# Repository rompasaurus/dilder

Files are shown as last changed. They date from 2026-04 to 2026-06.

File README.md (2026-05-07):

# Dilder

A Tamagotchi-inspired virtual pet built on a Raspberry Pi Pico W with an e-ink display, battery pack, and 3D-printed case — developed entirely in the open as a learning platform, blog series, and YouTube companion project.

The goal isn't just to build a thing — it's to show *how* the thing gets built, from the very first idea to a finished handheld device. Every prompt, every design decision, every dead end is documented so anyone can follow along, learn, and build their own.

---

## How It Started — Meet Jamal

<p align="center">
  Jamal the plush octopus
  <br />
  <em>Jamal. The plush octopus who started it all.</em>
</p>

This project didn't start with a schematic or a product spec. It started in a TEDi — a German dollar store — where my wife Emma and I found a giant plush octopus grinning up from a discount bin. We bought him on the spot, and on the walk home we started giving him a personality: laid-back, opinionated, a little sassy, suspiciously wise for a boneless creature. By the time we got home, he had a name — **Jamal** — and he'd claimed the armchair like he'd been paying rent.

The question asked itself: *what if we could actually bring him to life?* Not literally — but as a tiny digital companion. A pocket-sized octopus with moods, opinions, and an attitude problem, living on an e-ink screen and judging your life choices in ALL CAPS.

That's how Dilder was born. Not from an engineering roadmap, but from a stuffed animal and two people who couldn't stop anthropomorphizing it on a walk home.

---

## Enclosure — Rev 2 Mk2

The 3D-printed enclosure is a three-part design: base plate with solar panel recess, AAA battery cradle insert, and top cover with display window and joystick cutout. Designed in OpenSCAD (parametric source) and FreeCAD (visual PartDesign).

### Individual Parts

<p align="center">
  Base Plate — top view
  AAA Battery Cradle
</p>
<p align="center">
  <em>Left: Base plate with cradle pocket, corner pillars, battery rail troughs, and USB-C cutout. Right: AAA battery cradle with dual bays, clip slots, and TP4056 indent.</em>
</p>

<p align="center">
  Top Cover
  Base Plate — bottom (solar pit)
</p>
<p align="center">
  <em>Left: Top cover with display window, joystick hole, and bullnose edge. Right: Base plate bottom showing solar panel recess and wire holes.</em>
</p>

### Assembled

<p align="center">
  All three parts assembled
  <br />
  <em>All three parts stacked in their mated positions.</em>
</p>

### Full Assembly with Electronics

The FreeCAD macro now imports the official Raspberry Pi Pico 2 STEP file (mechanically identical to the Pico 2 W) and adds procedural 2×20 pin headers. It also builds three more peripherals from datasheet dimensions — two AAA Li-Ion cells in the cradle bays, a TP4056 USB-C charge module in the connecting block indent, and a Waveshare 2.13" e-paper display in the top cover's screen inlay. The Pico is mounted upside-down with its component-side face flush against the cradle's mating plane, headers extending up into the PicoNest cavity.

<p align="center">
  Assembly with Pico — top cover translucent
  <br />
  <em>Top cover rendered translucent so the Pico 2 W board, headers, and cradle are all visible.</em>
</p>

<p align="center">
  Assembly without top cover
  Pico on base plate, cradle hidden
</p>
<p align="center">
  <em>Left: top cover hidden so the cradle and Pico are exposed. Right: cradle hidden so the Pico's seating on the base plate is visible — header pin tips reach the level where the cradle would clip in.</em>
</p>

See the [FreeCAD macro reference](website/docs/docs/hardware/freecad-mk2-macro.md) for a full walkthrough of how the macro is structured.

### Joystick Thumbpiece

A printable snap cap that fits over the K1-1506SN-01 5-way switch peg. Single disc, 11 mm OD (= cover hole − 1 mm) so it nests inside the cover's joystick cutout with 0.5 mm radial clearance for directional swing. Concave thumb dish on top, rectangular snap socket on the bottom centered on the actuator (the SW1 stick is offset +0.68 mm in Y from the cover hole on the production PCB layout — disc reads visually centered, socket lands on the peg). Built parametrically in `dilder_rev2_mk2.FCMacro` as a separate `Thumbpiece` Body — drop `thumb_sock_x/y` from 3.3 to ~3.15 in the spreadsheet to convert friction-fit to interference snap-fit.

<p align="center">
  Assembly with thumbpiece
  <br />
  <em>Top-down view of the assembled prototype — display window on the left, joystick with the new thumbpiece on the right.</em>
</p>

<p align="center">
  Joystick + thumbpiece detail
  Thumbpiece in cover hole
</p>
<p align="center">
  <em>Left: joystick area in context. Right: thumbpiece nested in the cover cutout with the cover dialed to 85% transparency for clarity.</em>
</p>

See the [thumbpiece design write-up](website/docs/blog/posts/joystick-thumbpiece-snap-cap.md) for the geometry walkthrough — including the dish-vs-socket constraint that almost ruined the first cut.

---

## What This Project Is

- **A virtual pet device** — a pocket-sized, low-power companion with personality, needs, and interactions displayed on an e-ink screen
- **A build series** — a step-by-step guide covering hardware, software, 3D printing, and project planning
- **A transparency experiment** — the entire development process is captured in real time, including AI-assisted prompts, iteration, and mistakes

---

## Hardware

### Phase 1 — Pico 2 W Prototype (current)

| Component | Details |
|---|---|
| Board | Raspberry Pi Pico 2 W (RP2350, 40-pin headers) |
| Display | [Waveshare Pico-ePaper-2.13](https://www.waveshare.com/pico-epaper-2.13.htm) — 250x122px, black & white, SPI1, SSD1680 driver |
| Power | TP4056 USB-C charger module + LiPo 1000mAh (3.7V on VSYS) |
| Input | DollaTek K1-1506SN-01 5-way joystick (GP2-GP6) |
| Sound | Active buzzer on GP14 (3-12V, GPIO on/off) |
| Motion | MPU-6050 accelerometer/gyroscope on I2C0 (GP0/GP1, 400kHz) |

### Future — Pi Zero Upgrade

| Component | Details |
|---|---|
| Board | Raspberry Pi Zero WH (W or 2 W, pre-soldered headers) |
| Power | LiPo battery + Adafruit PowerBoost 500C |
| Enclosure | 3D-printed case (STL files provided) |

> The Pico W is the starting platform — it's what we have on hand, it's cheap, and it's excellent for prototyping the display and input system. The Pi Zero upgrade comes later when we need Linux, networking features, or more compute.

---

## Phases

Each phase maps to a section of the blog/YouTube series and can be followed independently.

### Phase 0 — Project Planning & Documentation ✓

- [x] Create repository and project structure
- [x] Define project intent and scope
- [x] Begin prompt progression log ([PromptProgression.md](PromptProgression.md))
- [x] Outline full phase roadmap
- [x] Create pixel art concepts for e-ink display (octopus character with 16 emotional states)
- [x] Define enclosure concept and prototype dimensions

### Phase 1 — Hardware Selection & Setup (Pico W) ✓

- [x] Finalize component list with links/part numbers ([hardware-research.md](docs/hardware-research.md))
- [x] Set up Docker-based C SDK cross-compilation toolchain
- [x] Wire e-ink display to Pico W via jumper wires (SPI)
- [x] Flash and run "Hello, Dilder!" on the e-ink display — proof of life
- [x] Build DevTool GUI — display emulator, serial monitor, firmware flash, asset manager, GPIO reference, connection utility, documentation ([tools/devtool/](tools/devtool/))
- [x] Add Programs tab with animated octopus preview, firmware size estimation, and deploy
- [x] Build IMG-receiver firmware — stream images from PC to Pico display via USB serial ([dev-setup/img-receiver/](dev-setup/img-receiver/))
- [x] Build standalone deploy — runtime-rendered animation, runs without PC
- [x] Wire and test joystick input (DollaTek 5-way, GP2-GP6)
- [x] Battery power prototype (TP4056 USB-C + LiPo on VSYS, ADC3 voltage sense)

### Phase 2 — Firmware Foundation (C on Pico W)
> *You are here*

- [x] Runtime rendering engine — draw octopus mathematically (no pre-baked frames)
- [x] Animation system — 4-frame mouth cycle with per-mood expression sequences
- [x] Body transform system — dx/dy offset, x_expand, per-row sine wobble
- [x] Custom body shapes for Fat (wider dome, thick tentacles) and Lazy (tentacles draped right)
- [x] 16 emotional states with unique eyes, pupils, eyebrows, eyelids, mouths, and body animations
- [x] 17 standalone firmware programs (16 emotions + mood selector with all 823 quotes)
- [x] Date/time clock header from RTC
- [x] C-faithful preview renderer for verifying firmware matches DevTool
- [x] Keyboard-to-Pico input mapping plan ([docs/keyboard-to-pico-input.md](docs/keyboard-to-pico-input.md))
- [x] Implement serial command input for interactive mood control
- [x] Wire and test GPIO joystick input (DollaTek 5-way, GP2–GP6)
- [x] Joystick Mood Selector firmware with on-screen input indicator
- [ ] **Custom PCB design (in progress)** — switched MCU from RP2040 to ESP32-S3-WROOM-1-N16R8 (WiFi+BLE, 16MB flash, 8MB PSRAM). 4-layer board (45x80mm, 30 components) in KiCad, ready for routing. Target fab: JLCPCB. Sensors: LIS2DH12TR (accelerometer), AHT20 (temperature/humidity), BH1750FVI-TR (ambient light) on shared I2C bus.
- [ ] Battery power (LiPo on VSYS) — InnCraft 1000mAh acquired
- [ ] Build game loop with state machine (idle, interact, sleep)

### Phase 3 — Pet Logic & Gameplay

- [ ] Define pet stats (hunger, happiness, energy, health, etc.)
- [ ] Implement stat decay over time
- [ ] Build interaction system — feed, play, sleep, clean
- [x] Pet mood / expressions based on emotional states (16 implemented)
- [x] Animation frames for e-ink (idle expressions, body movement per mood)
- [ ] Emotional state transitions triggered by interactions and stats
- [ ] Add death/game-over state and reset/new-pet flow

### Phase 4 — UI & Menus
> *Major progress*

- [x] Menu system with scrolling navigation (joystick up/down/center/left-back)
- [x] Status bar — WiFi icon (top-left), battery icon with percentage (top-right), RTC clock header
- [x] Screen transitions between octopus, menu overlay, and sub-screens (10 states)
- [x] Sound settings — on/off, volume (low/med/high), 6 test patterns
- [x] WiFi submenu — on/off toggle, network scanning, on-screen keyboard for password entry
- [x] Motion menu — live accelerometer/gyro, pedometer, tilt, threshold adjust, I2C scanner
- [x] Device info — firmware version, build date, battery voltage, WiFi status, NTP sync
- [ ] Implement settings screen (name pet, reset)

### Phase 5 — Pi Zero Migration

- [ ] Port MicroPython firmware to CPython on Pi Zero
- [ ] Set up headless Raspberry Pi OS
- [ ] Adapt display driver for Pi Zero SPI + Waveshare HAT
- [ ] Adapt input handler for Pi Zero GPIO
- [ ] Validate all Phase 2-4 functionality on Pi Zero

### Phase 6 — 3D-Printed Case & Power
> *In progress alongside Phase 2*

- [x] Design enclosure in OpenSCAD — parametric 3-part design (base plate, AAA cradle, top cover)
- [x] Account for display cutout, joystick access, USB-C charging port, solar panel recess
- [x] Translate to FreeCAD PartDesign — full parametric model with 90+ parameter spreadsheet
- [x] Battery cradle with clip slots for Swpeet AAA contact plates (parallel wiring)
- [x] Solar panel wire through-holes in base plate
- [x] Print prototypes and iterate on fit (Rev 2 Mk2 current)
- [x] Implement battery power (LiPo 1000mAh via TP4056 USB-C on VSYS)
- [ ] Implement sleep/wake cycle to conserve battery (see [power report](hardware-design/power-consumption-report.md))
- [x] Publish STL/3MF files and build instructions ([hardware-design/freecad-mk2/](hardware-design/freecad-mk2/))

### Phase 7 — Extras & Community

- [x] Add sound — active buzzer with 6 patterns (beep, chirp, SOS, doorbell, alert, happy)
- [x] WiFi connectivity — network scanning, on-screen keyboard, connect to any network
- [x] MPU-6050 accelerometer/gyroscope with pedometer and tilt sensing
- [ ] Explore connectivity — Bluetooth pet interactions?
- [ ] Mini-games
- [ ] Seasonal/event-based pet outfits or moods
- [ ] Publish a "build your own" kit guide
- [ ] Community gallery — show off your Dilder

---

## Content & Documentation

| Resource | Description |
|---|---|
| [PromptProgression.md](PromptProgression.md) | Every AI prompt used in development (104+), timestamped with token counts and file changes |
| [docs/hardware-research.md](docs/hardware-research.md) | Component research, materials list, GPIO pinout, and enclosure concepts |
| [docs/mpu6050-wiring-guide.md](docs/mpu6050-wiring-guide.md) | MPU-6050 accelerometer wiring, I2C details, and register reference |
| [hardware-design/power-consumption-report.md](hardware-design/power-consumption-report.md) | Full power budget, battery life projections, and reduction strategies |
| [docs/session-2026-05-07-implementation.md](docs/session-2026-05-07-implementation.md) | May 7 session — WiFi scan, keyboard, sound, MPU-6050, active buzzer |
| [Emotion States](https://dilder.dev/docs/software/emotion-states/) | All 16 emotional states with rendered previews and animation strips |
| [docs/keyboard-to-pico-input.md](docs/keyboard-to-pico-input.md) | Input mapping plan for interactive octopus control |
| [Blog](https://dilder.dev/blog/) | Build journal — 8 posts covering planning through body animations |
| YouTube (TBD) | Video walkthroughs for each phase |

---

## Follow Along

This project is built in the open. Star/watch this repo to follow progress. Each phase will have a corresponding blog post and video.

---

## License

TBD

---

*Built with patience, a Pico W, and an unreasonable fondness for a plush octopus named Jamal.*

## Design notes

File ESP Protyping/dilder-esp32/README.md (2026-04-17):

# Dilder ESP32-S3 Firmware — Implementation Guide

> Full mood-selector port for the Olimex ESP32-S3-DevKit-Lipo with Waveshare 2.13" e-Paper V3.

---

## Table of Contents

1. [What This Does](#what-this-does)
2. [Hardware Setup](#hardware-setup)
3. [Project Structure](#project-structure)
4. [Architecture](#architecture)
5. [Build & Flash](#build--flash)
6. [How It Works](#how-it-works)
7. [Code Layout](#code-layout)
8. [Display Pipeline](#display-pipeline)
9. [Rendering Engine](#rendering-engine)
10. [Input Handling](#input-handling)
11. [Design Principles](#design-principles)
12. [File Reference](#file-reference)
13. [Debugging](#debugging)

---

## What This Does

This is the ESP32-S3 port of the Dilder mood-selector — the same octopus character, 16 emotional states, 823 quotes, and animated expressions that run on the Pico W, now running on the Olimex ESP32-S3-DevKit-Lipo.

The octopus has:
- **16 moods**: Sassy, Weird, Unhinged, Angry, Sad, Chaotic, Hungry, Tired, Slaphappy, Lazy, Fat, Chill, Creepy, Excited, Nostalgic, Homesick
- **17 mouth expressions** with 4-frame animation cycles per mood
- **16 eye/pupil variations** with mood-specific eyebrows, eyelids, and tears
- **Body animation transforms** (oscillation, wobble, expansion per mood)
- **823 mood-filtered quotes** in chat bubbles
- **Joystick navigation** + serial keyboard control

---

## Hardware Setup

### Board: Olimex ESP32-S3-DevKit-Lipo

| Spec | Value |
|---|---|
| MCU | ESP32-S3 (dual-core Xtensa LX7 @ 240MHz) |
| Flash | 8MB QSPI |
| PSRAM | 8MB OPI |
| WiFi | 802.11 b/g/n |
| Bluetooth | BLE 5.0 |
| USB | USB-OTG (native) + USB-UART (CH340X) |
| Battery | LiPo via JST, onboard charger |

### Pin Connections

| Signal | GPIO | Connection |
|---|---|---|
| EPD CLK | 12 | Display SPI clock |
| EPD DIN (MOSI) | 11 | Display SPI data |
| EPD CS | 10 | Display chip select |
| EPD DC | 9 | Display data/command |
| EPD RST | 3 | Display reset |
| EPD BUSY | 8 | Display busy signal |
| Joystick UP | 4 | Active LOW, internal pull-up |
| Joystick DOWN | 7 | Active LOW, internal pull-up |
| Joystick LEFT | 1 | Active LOW, internal pull-up |
| Joystick RIGHT | 2 | Active LOW, internal pull-up |
| Joystick CENTER | 15 | Active LOW, internal pull-up |
| Battery ADC | 6 | Voltage divider (4.133x) |
| USB Power ADC | 5 | Voltage divider (1.468x) |
| LED | 38 | Green LED (active LOW) |

---

## Project Structure

```
ESP Protyping/dilder-esp32/
├── platformio.ini              Build config (board, libs, flags)
├── src/
│   ├── main.cpp                Full mood-selector firmware (666 lines)
│   └── quotes.h                Auto-generated quote database (823 entries)
├── README.md                   This file
└── .gitignore                  Excludes .pio/ build cache

Shared firmware headers (included via -I flag):
firmware/
├── include/
│   └── platform/
│       ├── board_config.h      Pin definitions per board (Pico/ESP32/Desktop)
│       └── hal.h               Hardware Abstraction Layer interface
└── src/
    └── platform/
        └── esp32s3/
            └── esp32s3_hal.cpp  ESP32-S3 HAL implementation
```

---

## Architecture

```
┌─────────────────────────────────────────────┐
│              main.cpp (Arduino)              │
│                                             │
│  setup() → init HAL, SPI, display, RNG      │
│  loop()  → render frame, poll input, repeat │
│                                             │
│  ┌─────────────────────────────────────┐    │
│  │      Octopus Rendering Engine       │    │
│  │  (body RLE, eyes, mouth, bubble,    │    │
│  │   font, animation transforms)       │    │
│  │  → renders to frame[] buffer        │    │
│  └───────────────┬─────────────────────┘    │
│                  │                           │
│  ┌───────────────▼─────────────────────┐    │
│  │         GxEPD2 Display Push         │    │
│  │  display.drawBitmap(frame)          │    │
│  │  Full refresh → Partial refresh     │    │
│  └─────────────────────────────────────┘    │
│                                             │
│  ┌─────────────────────────────────────┐    │
│  │         Input Handler               │    │
│  │  Joystick (hal_btn_*) + Serial      │    │
│  │  Edge detection for button presses  │    │
│  └─────────────────────────────────────┘    │
└──────────────────┬──────────────────────────┘
                   │
┌──────────────────▼──────────────────────────┐
│          HAL (Hardware Abstraction)          │
│                                             │
│  hal.h         → function declarations      │
│  board_config.h → pin numbers per board     │
│  esp32s3_hal.cpp → Arduino GPIO/SPI impl    │
└─────────────────────────────────────────────┘
```

---

## Build & Flash

### Prerequisites

- PlatformIO CLI (`pipx install platformio`)
- USB-UART cable connected to the Olimex board's CH340X port

### Commands

```bash
cd "ESP Protyping/dilder-esp32"

# Build
pio run

# Build + Flash
pio run -t upload

# Serial Monitor
pio device monitor

# All three
pio run -t upload && pio device monitor
```

Or use the DevTool GUI: select the "Flash Firmware" tab → ESP32-S3 board.

---

## How It Works

### Frame Cycle

Each iteration of `loop()`:

1. **Select expression** — look up the 4-frame mouth cycle for the current mood, pick the expression for this frame index
2. **Pick quote** — if mood changed or mouth is "open", randomly select a new quote from the current mood's pool
3. **Render to framebuffer** — `render_frame()` draws everything to the `frame[]` byte array:
   - Clock header (synthetic time from millis())
   - Body (RLE-decoded with animation transforms)
   - Eyes (white sockets cleared in body)
   - Pupils (mood-specific shapes)
   - Eyebrows/eyelids/tears (mood-specific overlays)
   - Mouth expression (one of 17 styles)
   - Chat bubble outline + speech tail
   - Quote text (word-wrapped in bubble)
   - Status bar ("< MOOD_NAME >")
4. **Push to display** — `push_frame_to_display()` sends the framebuffer to the e-paper via GxEPD2
5. **Poll input** — wait 4 seconds, checking joystick + serial every 50ms
6. **Repeat**

### Mood Selection

- **Joystick LEFT/RIGHT**: cycle through 16 moods sequentially
- **Joystick CENTER**: jump to a random mood
- **Joystick UP**: pick a new quote (same mood)
- **Serial keyboard**: single-letter shortcuts (n=Sassy, w=Weird, etc.)

---

## Code Layout

### main.cpp — Section Map

| Lines | Section | What It Contains |
|---|---|---|
| 1-30 | Headers | Arduino, GxEPD2, HAL includes |
| 31-75 | Constants | Mood/expression enums, names, framebuffer |
| 76-100 | Pixel helpers | `px_set`, `px_clr`, `px_set_off`, `px_clr_off` |
| 101-115 | Quotes | `#include "quotes.h"` |
| 116-200 | Body data | RLE-encoded octopus body + 5x7 font |
| 200-260 | Drawing | `fill_circle`, `draw_body_transformed`, `draw_eyes` |
| 260-520 | Eyes/Pupils | 16 mood-specific pupil functions + eyebrows/tears |
| 520-750 | Mouths | 17 mouth expression functions |
| 750-830 | Bubble/Text | Chat bubble outline, text rendering with word wrap |
| 830-870 | Clock | millis()-based synthetic clock header |
| 870-930 | Animation | Body transform setup per mood |
| 930-950 | Status bar | "< MOOD >" at bottom of screen |
| 950-1050 | Cycles | 16 mouth animation cycle tables |
| 1050-1100 | Render | `render_frame()` — composites all layers |
| 1100-1140 | Display | `push_frame_to_display()` — GxEPD2 bitmap push |
| 1140-1180 | Setup | Arduino `setup()` — init HAL, SPI, display |
| 1180-end | Loop | Arduino `loop()` — render, poll input, repeat |

---

## Display Pipeline

### Pico W vs ESP32-S3

Both use the same 250x122 framebuffer, but push pixels differently:

| Step | Pico W | ESP32-S3 |
|---|---|---|
| Render | → `frame[3904]` | → `frame[3904]` (identical) |
| Transform | `transpose_to_display()` (landscape→portrait) | Not needed (GxEPD2 handles rotation) |
| Push | `EPD_Display(display_buf)` / `EPD_Partial()` | `display.drawBitmap(0,0,frame,250,122,BLACK)` |
| Driver | Waveshare C driver (SSD1680 registers) | GxEPD2 Arduino library (same SSD1680) |

### Framebuffer Format

```
frame[3904 bytes] = 250 x 122 pixels, 1 bit per pixel

Bit layout: MSB-first per byte
  Byte: [b7][b6][b5][b4][b3][b2][b1][b0]
         ^leftmost pixel          ^rightmost

  1 = black pixel, 0 = white pixel

To set pixel (x, y):
  frame[y * 32 + x / 8] |= (0x80 >> (x & 7));
```

---

## Rendering Engine

### Body (RLE Encoding)

The octopus body is stored as Run-Length Encoded spans:

```
Format: y, num_spans, x_start, x_end, [x_start, x_end, ...], ...
Terminator: 0xFF

Example: 55,5, 10,17, 21,28, 32,39, 43,50, 54,61
  → Row 55 has 5 horizontal spans:
    pixels 10-17, 21-28, 32-39, 43-50, 54-61
  → These are the tentacles splitting from the body
```

### Eyes

Eyes are drawn in three layers:
1. **Sockets** — white circles cleared from the black body (`fill_circle(..., 0)`)
2. **Pupils** — black dots/shapes drawn inside the sockets (mood-specific)
3. **Overlays** — eyebrows (angry/sad), eyelids (tired/lazy), tears (homesick)

### Mouth

17 distinct mouth expressions using math curves:
- **Smirk**: tilted arc (sqrt curve)
- **Smile**: parabola (y = x^2 / 25)
- **Open**: elliptical outline (ellipse edge detection)
- **Weird**: sine wave (3 periods)
- **Unhinged**: large ellipse with teeth
- **Angry/Sad**: inverted/normal parabolas
- **Chaotic**: zigzag
- **Hungry**: open ellipse with drool
- And more...

### Animation

Each mood has a 4-frame mouth cycle and body transform:
- **body_dx/dy**: position offset (breathing, bouncing)
- **body_x_expand**: width change (puffing up, shrinking)
- **wobble_amp/freq/phase**: per-row sine wobble (wavy effects)

---

## Input Handling

### Edge Detection

Buttons are active-LOW (pressed = GPIO reads LOW). The HAL inverts this so `hal_btn_up()` returns `true` when pressed.

To detect a new press (not a held button), we compare current vs previous state:

```cpp
if (left && !last_left) {
    // Button was just pressed (rising edge)
    // Do something
}
last_left = left;  // Remember for next iteration
```

This prevents the mood from cycling continuously while the button is held.

---

## Design Principles

1. **Shared rendering engine** — the octopus drawing code is identical between Pico W and ESP32-S3. Same pixel math, same framebuffer layout, same visual output.

2. **Platform abstraction** — `hal.h` defines a common interface. Each board implements it differently (`esp32s3_hal.cpp` uses Arduino, Pico uses the Pico SDK). Application code never touches hardware registers directly.

3. **Compile-time board selection** — `board_config.h` uses `#if defined(BOARD_ESP32S3)` to select pin numbers at compile time. No runtime overhead, no unused code.

4. **No dynamic allocation** — all buffers are statically allocated. The framebuffer, body RLE data, font, and quote database are all compile-time constants. No `malloc()`, no fragmentation risk.

5. **Arduino framework** — used for the ESP32 build because it provides mature SPI, GPIO, and serial APIs plus the GxEPD2 display library. The Pico build uses the native Pico SDK for lower overhead.

---

## File Reference

| File | Location | Lines | Purpose |
|---|---|---|---|
| `main.cpp` | `src/` | ~666 | Complete mood-selector with octopus rendering |
| `quotes.h` | `src/` | ~827 | 823 auto-generated mood-indexed quotes |
| `platformio.ini` | root | 56 | PlatformIO build configuration |
| `board_config.h` | `firmware/include/platform/` | ~120 | Pin definitions for Pico W / ESP32 / Desktop |
| `hal.h` | `firmware/include/platform/` | ~75 | Hardware abstraction interface |
| `esp32s3_hal.cpp` | `firmware/src/platform/esp32s3/` | ~130 | ESP32-S3 GPIO/SPI/ADC implementation |

---

## Debugging

### Serial Monitor

```bash
pio device monitor
```

Every frame prints: `Frame N | < MOOD > (X/16) | "QUOTE TEXT"`

### Common Issues

| Problem | Cause | Fix |
|---|---|-----|
| Display blank | SPI pins wrong | Check `board_config.h` GPIO mapping |
| Display shows noise | Wrong GxEPD2 class | Must be `GxEPD2_213_BN` for V3 |
| Joystick not responding | Pull-ups missing | `dilder_hal_init()` sets `INPUT_PULLUP` |
| Build fails: `Arduino.h not found` | IDE error, not real | PlatformIO resolves this at build time |
| Quotes not showing | `quotes.h` missing | Copy from `dev-setup/mood-selector/quotes.h` |
| Flash too slow | Wrong upload port | Set `upload_port` in `platformio.ini` |

### Adding printf Debugging

```cpp
Serial.printf("[DEBUG] mood=%d frame=%lu\n", current_mood, frame_idx);
```

Output appears in `pio device monitor` or the DevTool serial tab.

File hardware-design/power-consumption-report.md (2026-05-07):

# Power Consumption Report — Dilder Hub

## Current Component Inventory (Testbench)

| Component | Model | Voltage | Typical Current | Peak Current | Duty Cycle | Notes |
|---|---|---|---|---|---|---|
| Pico 2 W (RP2350 + CYW43) | Pico 2 W | 3.3V via VSYS | 30 mA | 50 mA | 100% | WiFi off baseline; CYW43 init'd for VSYS sense |
| Pico 2 W WiFi active | — | 3.3V | 80-120 mA | 250 mA | Variable | TX bursts during scan/connect; idle ~80 mA |
| E-paper display (2.13" V4) | Waveshare 2.13 V4 | 3.3V | 0.01 mA | 5 mA | ~1% | Static: near-zero; refresh burst ~5 mA for ~2s |
| Active buzzer | 3-12V active | 3.3V | 0 mA | 15 mA | <1% | Only during beeps; off = 0 mA |
| 5-way joystick | K1-1506SN-01 | 3.3V | 0 mA | ~0.1 mA | Passive | Internal pull-ups on GPIOs (~50uA total) |
| MPU-6050 (accel/gyro) | GY-521 module | 3.3V | 3.6 mA | 3.9 mA | 100% | Always on; module regulator quiescent ~0.5 mA |
| TP4056 charger board | TP4056 USB-C | 5V USB in | 2 mA | ~1000 mA | Charging only | Quiescent ~2 mA; charge current set by R_prog |
| Battery | LiPo 1000mAh / 10440 | 3.7V nom | — | — | — | Source, not load |

## Power Budget Summary

### Scenario 1: Idle (WiFi off, display static, no motion polling)

| Component | Current |
|---|---|
| Pico 2 W + CYW43 init | 30 mA |
| E-paper (static) | 0.01 mA |
| Joystick pull-ups | 0.05 mA |
| MPU-6050 | 3.6 mA |
| **Total** | **~34 mA** |

**Battery life (1000 mAh LiPo):** ~29 hours continuous

### Scenario 2: Active use (WiFi off, e-paper refreshing every 3s, motion polling)

| Component | Average Current |
|---|---|
| Pico 2 W + CYW43 init | 30 mA |
| E-paper (refresh 2s on / 1s off) | ~3.3 mA avg |
| Joystick pull-ups | 0.05 mA |
| MPU-6050 | 3.6 mA |
| Buzzer (occasional) | ~0.5 mA avg |
| **Total** | **~38 mA** |

**Battery life (1000 mAh LiPo):** ~26 hours continuous

### Scenario 3: WiFi active (connected, NTP sync, display refreshing)

| Component | Average Current |
|---|---|
| Pico 2 W + WiFi connected idle | 80 mA |
| E-paper (refreshing) | ~3.3 mA avg |
| MPU-6050 | 3.6 mA |
| Other | ~0.5 mA |
| **Total** | **~88 mA** |

**Battery life (1000 mAh LiPo):** ~11 hours continuous

### Scenario 4: WiFi scan burst (worst case)

| Component | Peak Current |
|---|---|
| Pico 2 W + WiFi TX | 250 mA |
| E-paper refresh | 5 mA |
| MPU-6050 | 3.9 mA |
| **Total** | **~260 mA** |

Duration: scan bursts last ~2-5 seconds. TP4056 output can handle this.

## Power Reduction Strategies

### 1. MPU-6050 Sleep Mode (saves ~3.5 mA)

The MPU-6050 has a low-power sleep mode (write 0x40 to PWR_MGMT_1). When not in the MOTION menu:
- Put MPU to sleep: `mpu_write_reg(0x6B, 0x40)`
- Wake on entering MOTION menu: `mpu_write_reg(0x6B, 0x00)`
- **Savings:** 3.5 mA (10% of idle budget)
- **Effort:** Low — add sleep/wake calls to state transitions

### 2. MPU-6050 Cycle Mode (saves ~2.5 mA while still counting steps)

For pedometer-only operation (no live display), use the MPU's cycle mode:
- Wakes at 1.25-40 Hz to sample, sleeps between
- At 5 Hz cycle: ~0.5 mA vs 3.6 mA continuous
- **Savings:** ~3.1 mA
- **Effort:** Medium — configure LP_WAKE_CTRL register, adjust pedometer timing

### 3. Pico 2 W Dormant/Sleep Mode (saves ~25 mA)

The RP2350 supports dormant mode (~0.2 mA) and sleep mode (~1 mA). Implement a Tamagotchi-style duty cycle:
- **Active 10 min:** Full operation, display updates, user input
- **Sleep 50 min:** RP2350 dormant, wake on joystick press (GPIO interrupt) or timer
- **Average current:** ~34 mA * (10/60) + 1 mA * (50/60) = ~6.5 mA
- **Battery life (1000 mAh):** ~6.5 days
- **Effort:** High — requires dormant mode setup, GPIO wake interrupts, state preservation

### 4. CYW43 Deinit When Not Needed (saves ~5-10 mA)

Currently CYW43 is initialized at boot for VSYS sensing. When the full board has TP4056 CHRG/STDBY pins wired:
- Remove CYW43 dependency for battery sensing
- Only init CYW43 when WiFi is actually needed
- **Savings:** ~5-10 mA from CYW43 idle current
- **Effort:** Low (once CHRG/STDBY hardware is in place)

### 5. E-paper Deep Sleep (saves ~0.01 mA — negligible)

The e-paper already draws near-zero in static mode. Calling `EPD_Sleep()` after each refresh would save microamps. Not worth the added wake-up latency.

### 6. Reduce Display Refresh Rate (saves CPU time, indirect power)

On the main octopus screen, refresh every 5-6 seconds instead of 3. Reduces CPU active time. Minimal direct current savings but extends battery slightly.

### 7. WiFi Power Management (saves ~30-50 mA when connected)

When WiFi is connected but idle:
- Enable CYW43 power-save mode: `cyw43_wifi_pm(&cyw43_state, CYW43_PERFORMANCE_PM)`
- Or aggressive PS: `cyw43_wifi_pm(&cyw43_state, CYW43_DEFAULT_PM)` (DTIM-based sleep)
- **Savings:** WiFi idle drops from ~80 mA to ~30-50 mA
- **Effort:** Low — single function call after connect

### 8. Voltage Regulator Efficiency

The Pico 2 W onboard SMPS (RT6154) is ~90% efficient at typical loads. No improvement possible without board redesign. On a custom PCB, a more efficient regulator could save 5-10%.

## Recommended Priority

| Priority | Strategy | Savings | Effort | Impact |
|---|---|---|---|---|
| 1 | MPU-6050 sleep when not in MOTION menu | 3.5 mA | Low | Do now |
| 2 | WiFi power-save mode when connected | 30-50 mA | Low | Do now |
| 3 | CYW43 deinit (needs CHRG/STDBY hardware) | 5-10 mA | Low | Full board |
| 4 | MPU cycle mode for background pedometer | 3.1 mA | Medium | Later |
| 5 | Dormant/sleep duty cycle | ~28 mA avg | High | Phase 2 |

## Battery Life Projections (1000 mAh LiPo)

| Configuration | Average mA | Battery Life |
|---|---|---|
| Current (WiFi off, idle) | 34 mA | ~29 hours |
| With MPU sleep (#1) | 30.5 mA | ~33 hours |
| With WiFi PS (#2) when connected | ~55 mA | ~18 hours |
| With MPU sleep + no CYW43 idle (#1+#3) | ~25 mA | ~40 hours |
| Full sleep/wake cycle (#5) | ~6.5 mA | ~6.5 days |
| All optimizations combined | ~4 mA avg | ~10 days |

## Solar Charging Viability

With the AK 62x36mm panel (~5-6V, 80-150 mA peak):
- **Best case (direct sun):** 100 mA in, 34 mA out = net positive, charges battery
- **Typical (indirect/cloudy):** 20-40 mA in, 34 mA out = net negative without sleep cycle
- **With sleep cycle (6.5 mA avg):** Solar easily sustains operation in most daylight conditions
- **Conclusion:** Sleep/wake cycle is essential for solar sustainability

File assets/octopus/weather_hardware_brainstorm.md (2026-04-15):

# Weather Detection for Dilder — Hardware Brainstorm

How to get weather data into Jamal's world so environments react to real conditions.

---

## Option 1: WiFi Weather API (Free, No Extra Hardware)

**The cheapest option: $0, 0 components, 0 GPIO pins.**

The ESP32-S3 already has WiFi active (used for location fingerprinting). Piggyback a weather API call onto the existing WiFi connection.

### How It Works
```
ESP32-S3 WiFi -> HTTPS GET -> OpenWeatherMap API -> JSON parse -> weather state
```

### Free API Options
| Service | Free Tier | Update Interval | Data |
|---|---|---|---|
| OpenWeatherMap | 1,000 calls/day | Every 86s (~15min is fine) | temp, humidity, pressure, conditions, icon |
| WeatherAPI.com | 1M calls/month | ~2.8s (use 15min) | Same + UV, air quality |
| Open-Meteo | Unlimited | 15min granularity | No API key needed, EU-based |

### Implementation
```c
// Poll every 15 minutes (e-ink doesn't need faster updates)
// Parse JSON for: temp_c, humidity, condition_code
// condition_code maps to environment modulation:
//   200-299: Thunderstorm -> lightning aura
//   300-499: Rain/Drizzle -> rain overlay
//   500-599: Rain -> heavy rain overlay
//   600-699: Snow -> snow overlay
//   800:     Clear -> sun_rays / stars (day/night)
//   801-804: Clouds -> clouds overlay
typedef struct {
    int8_t temp_c;
    uint8_t humidity;
    uint16_t condition;  // OWM condition code
    bool is_night;
} weather_t;
```

### Pros
- Zero extra cost, zero extra hardware, zero extra power draw
- Rich data (temp, humidity, forecast, UV, sunrise/sunset)
- Works indoors (where most Tamagotchis live)
- Can show weather for ANY location (home, travel, etc.)

### Cons
- Needs WiFi connected (already required for location)
- No hyperlocal accuracy (reports city-level weather)
- ~200ms latency per API call (do it in background, non-blocking)

### Power Cost
One HTTPS request every 15 minutes adds ~0.5mA average to the WiFi budget (ESP32-S3 already waking for location scans). Negligible.

**Verdict: Do this first. It's free and the ESP32-S3 already has WiFi.**

---

## Option 2: BME280 Sensor (Best Bang-for-Buck Hardware)

**~$2-3, 1 component, shares existing I2C bus.**

### What You Get
| Measurement | Range | Resolution |
|---|---|---|
| Temperature | -40 to +85°C | 0.01°C |
| Humidity | 0-100% RH | 0.008% |
| Barometric Pressure | 300-1100 hPa | 0.18 Pa |

### Why Pressure Matters
Barometric pressure trends predict weather changes **before they happen**:
- Pressure dropping fast (>2 hPa/hr) -> storm incoming
- Pressure rising -> clearing up
- Steady low pressure -> overcast/rainy
- Steady high pressure -> fair weather

This gives Jamal **weather prescience** — he can react to weather changes before they're visible outside. "Jamal feels a storm coming" is way more charming than "the API says rain."

### Wiring
```
BME280       ESP32-S3
------       --------
VCC    ->    3.3V
GND    ->    GND
SDA    ->    GPIO16 (shared with accelerometer)
SCL    ->    GPIO17 (shared with accelerometer)
```

The I2C bus already has 10k pull-ups for the LIS2DH12TR accelerometer. The BME280 default address is **0x76** (accelerometer is 0x18) — no conflict.

### PCB Impact
- Add 1 footprint: LGA-8 (2.5x2.5mm) or breakout header
- No new traces needed if placed near existing I2C bus
- Could be mounted on the back of the PCB for ambient sensing

### Power
- Normal mode: 3.6μA (one measurement per second)
- Forced mode (on-demand): <1μA average at 1 reading/minute
- Sleep: 0.1μA

### Code Size
BME280 I2C driver: ~500 bytes flash, ~20 bytes RAM for calibration data.

**Verdict: Best hardware option. Shares I2C bus, tiny, cheap, gives pressure-based weather prediction.**

---

## Option 3: Combo Approach (API + BME280)

**The "best of both worlds" — use BOTH for maximum weather awareness.**

| Source | What It Provides | Update Rate |
|---|---|---|
| WiFi API | Conditions (rain/snow/sun), forecast, sunrise/sunset | Every 15 min |
| BME280 | Ambient temp, humidity, pressure **trend** | Every 1 min |

### Fusion Logic
```c
// API gives the "official" weather
// BME280 gives the local/indoor reality + pressure predictions

weather_state_t get_weather() {
    weather_state_t w = api_weather;  // base from API

    // Override with local conditions
    if (bme_temp < 10) w.feels_cold = true;   // Jamal shivers
    if (bme_humidity > 80) w.feels_muggy = true;

    // Pressure trend prediction (last 3 hours)
    float dp = pressure_now - pressure_3h_ago;
    if (dp < -3.0) w.storm_incoming = true;   // "Jamal senses a storm"
    if (dp > 3.0) w.clearing_up = true;       // "Jamal feels the sun coming"

    return w;
}
```

This creates **two layers of weather personality:**
1. API-driven: Jamal knows it's raining outside (rain overlay, sad modulation)
2. Sensor-driven: Jamal *feels* the room (shivers if cold, sweats if humid, senses storms)

---

## Option 4: Cheap Trick — LDR (Light Sensor)

**~$0.10, 1 resistor + 1 LDR, 1 ADC pin.**

A light-dependent resistor on an ADC pin gives day/night detection and crude cloud cover estimation.

### Wiring
```
3.3V -> LDR -> ADC_PIN (GPIO1/2/3) -> 10kΩ -> GND
```

Voltage divider. Read ADC value:
- High value = bright = daytime/sunny
- Medium = cloudy/overcast
- Low = nighttime/dark room

### What It Enables
- Automatic day/night environment switching (bedroom at night, park during day)
- "Jamal notices it's getting dark" personality triggers
- Crude indoor/outdoor detection (fluorescent vs sunlight spectrum varies, but ADC can't distinguish)

### Limitation
Only measures **light at the device location**, not actual weather. But combined with an API, it tells you "is the device in a bright or dark room" which is useful for Tamagotchi personality.

**Verdict: Cute party trick for $0.10. Add it if you have a spare ADC pin.**

---

## Option 5: Rain Sensor Module

**~$1, but requires outdoor exposure.**

Analog rain detector PCB. Resistance drops when water bridges the traces.

### Why It Probably Doesn't Work Here
- Needs to be **outdoors** or near a window
- Tamagotchi lives indoors on a desk
- Corrosion over time degrades the sensor
- Already solved better by WiFi API

**Verdict: Skip. The API does this better without hardware.**

---

## Recommendation

### Phase 1: WiFi API (implement now, zero cost)
- OpenWeatherMap or Open-Meteo free tier
- Poll every 15 minutes in background
- Map condition codes to environment overlays + emotion modulation
- Already have WiFi connected for location

### Phase 2: BME280 (add to next PCB revision)
- $2-3, shares I2C bus, tiny footprint
- Pressure trend prediction ("Jamal feels a storm coming")
- Room temperature/humidity awareness ("Jamal is cold/hot/muggy")
- Combines with API for rich weather personality

### Phase 3 (Optional): LDR for day/night
- $0.10, automatic day/night switching
- Only if a spare ADC pin is available on the next PCB

---

## How Weather Maps to the Asset System

```
Weather State           Environment Modulation      Aura Effect
─────────────          ─────────────────────       ────────────
Clear/Sunny            sun_rays overlay             warm sparkle dots
Cloudy                 clouds overlay               muted aura (slower)
Rain                   rain overlay (density=API)   sad tears amplified
Heavy Rain             rain overlay (density=max)   chaotic wobble added
Thunderstorm           rain + lightning overlay      unhinged static noise
Snow                   snow overlay                 gentle drift particles
Wind                   wind streaks overlay          aura particles drift faster
Hot (>30°C)            heat shimmer effect           sweat drops near head
Cold (<5°C)            (no overlay)                 shiver wobble on body
Storm Incoming (BME)   darkening sky gradient        anticipation particles
Night                  swap to night variant env     stars in aura
```

The weather overlays from `decor/weather.py` are already implemented and ready to be triggered by real weather data. The composition pipeline in `compose.py` has the hook point at step 12 (weather overlay) waiting to be wired up.

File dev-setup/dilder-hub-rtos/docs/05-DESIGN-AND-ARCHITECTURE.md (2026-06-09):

# 05 — Design and Architecture

This is the "why it's built this way" document. It describes the target task model, the
dual-core (SMP) decision, how a frame reaches the screen, and what is implemented now
versus planned.

---

## 1. The goal, restated as a requirement

> While the e-ink screen is mid-refresh (~300 ms of blocking), the firmware must still:
> register button presses within ~10 ms, keep the clock ticking, read the accelerometer,
> and service Wi-Fi/Bluetooth.

The original super-loop cannot meet this: one slow step stalls all the others. The fix is
concurrency, and we chose **dual-core SMP FreeRTOS**.

---

## 2. Why dual-core SMP (and the trade-off we accepted)

The RP2350 has two Cortex-M33 cores. We could have used single-core FreeRTOS (time-slicing
one core) — simpler and lower-risk. We chose **SMP** because it gives **true parallelism**:
the slow Display task runs on **core 1** while everything responsive runs on **core 0**, so
the 300 ms refresh has *zero* effect on input latency rather than merely being interrupted
every few milliseconds.

The trade-off we accept for that: SMP means two cores share memory simultaneously, so we
must be disciplined about synchronization (doc 06) and use multicore-safe flash writes
(doc 04 §8). The most error-prone combination on this chip is *cyw43 (Wi-Fi/BT) + SMP*, so
we **pin all networking to core 0** and keep core 1 doing nothing but the display. That
isolation keeps the fragile parts on one core and the parallelism where we need it.

(For the full pros/cons that led to this choice, see the project plan; this doc records the
decision, not the debate.)

---

## 3. The tasks

| Task | Core | Priority | Owns (only this task touches it) | Blocks on |
|---|---|---|---|---|
| **Input** | 0 | highest | the joystick GPIOs | a 5 ms `vTaskDelay` poll |
| **cyw43 / lwIP / BTstack** (SDK-created) | 0 | high | the Wi-Fi/BT chip, the network stack | internal events |
| **UI / Logic** | 0 | medium | the state machine, the logical canvas `frame[]`, canvas size/rotation, mood/quote/menu state | the input queue + a render-done signal |
| **Housekeeping** | 0 | low | the I²C bus + accelerometer, step/activity counters, the battery ADC, idle detection, the clock | a periodic `vTaskDelay` |
| **Display** | **1 (alone)** | high | the panel SPI bus + `display_buf[]` + the e-ink driver | a render request, then the BUSY pin |

The single most important line in that table: **Display is alone on core 1.** Everything
else is on core 0. That's the whole architecture in one sentence.

> One task **owning** a resource is our main concurrency tool. If only Housekeeping ever
> touches the I²C bus, there can be no I²C race — no lock needed. If only Display touches
> `display_buf`, no framebuffer race. We design ownership first and reach for locks only
> for the few things that genuinely cross tasks.

---

## 4. How a frame reaches the screen (the render hand-off)

This is the crux that lets the 300 ms cost live entirely on core 1.

```
  UI task (core 0)                         Display task (core 1)
  ----------------                         ---------------------
  1. decide what to show (state machine)
  2. draw into the logical canvas frame[]
  3. map frame[] → panel bytes via
     transpose_to_display() into the
     BACK buffer of a double buffer
  4. xQueueOverwrite(render_q, {buf, mode}) ───────►  5. xQueueReceive(render_q, …)  (was asleep)
  6. go back to waiting for input  ◄── (free!)        6. EPD push pixels from that buffer
                                                       7. wait on BUSY ~300 ms
                                                       8. notify UI "done" (frees the buffer)
```

- **Double buffer:** two `display_buf`s. UI fills the back one while Display shows the
  front one. They never touch the same buffer at the same time, so no lock on the pixels.
- **`xQueueOverwrite` (length-1 queue):** if UI produces frames faster than Display can
  show them, only the **newest** survives in the queue. That's exactly right — e-ink can't
  display intermediate frames anyway, so dropping them is free frame-coalescing.
- **Result:** after step 4, UI is *immediately* back to serving input. The screen catches
  up on the other core. Buttons never wait for pixels.

---

## 5. Synchronization at a glance (full detail in doc 06)

- **Input → UI:** a FreeRTOS **queue** of joystick codes. Replaces the old inline
  `read_joystick()` polling and the `POLL_INPUT` busy-loops.
- **UI → Display:** a length-1 **overwrite queue** carrying a tiny "show buffer N"
  descriptor, plus a **task notification** back to UI when the frame is done.
- **Housekeeping → readers:** a `sensor_snapshot_t` struct (orientation, steps, battery,
  idle flag) guarded by **one mutex**. Housekeeping writes it; UI/Display copy it.
- **Networking flags:** single `volatile` scalars (atomic); multi-byte network data is read
  under the cyw43 lock (`cyw43_arch_lwip_begin/end`).
- **Flash writes:** `flash_safe_execute()` (multicore-safe), not the old interrupt-disable.

---

## 6. Memory budget (rough)

RP2350 has 520 KB RAM. Approximate static consumers: FreeRTOS heap pool 128 KB, lwIP +
BTstack buffers, the framebuffers (~8 KB), task stacks (UI ~16 KB, others smaller), plus
the firmware's own globals. The Phase 0 build measured ~205 KB of `.bss` (zero-initialized
RAM) — comfortably within budget. Flash use (~600 KB of ~4 MB) is a non-issue.

---

## 7. The boot sequence

```
main() on the boot core, BEFORE any RTOS:
  stdio, clock-from-compile-time, hardware init (SPI/e-ink pins),
  joystick, speaker, [hold-UP → jump to the OTA bootloader], startup chime,
  EPD_Init/Clear, seed RNG
  → xTaskCreate(app_task, core 0); vTaskStartScheduler()   ← OS takes over here

app_task (Phase 1: the whole program; Phase 2: replaced by the task set):
  cyw43_arch_init()  ← must be here: the FreeRTOS Wi-Fi driver needs the scheduler running
  battery_init, mpu_init, load saved settings
  → the state-machine loop
```

The **OTA hold-UP check stays in `main()` before the scheduler** on purpose: jumping into
the bootloader must happen on bare metal, with no tasks alive.

---

## 8. Implemented vs planned

| Piece | Status |
|---|---|
| FreeRTOS SMP integrated, builds USB + OTA | ✅ Phase 0 |
| Whole program runs as one task under the scheduler (core 0) | ✅ Phase 1 |
| Split into Input / UI / Display / Housekeeping tasks | ✅ Phase 2 (`rtos_tasks.c`) |
| Display pinned to core 1 + 2-buffer render hand-off | ✅ Phase 2 |
| Input task + event queue (edge + auto-repeat) | ✅ Phase 2 |
| Housekeeping task + mutex-guarded sensor snapshot | ✅ Phase 2 |
| `flash_safe_execute()` for settings/calibration writes (+ core-1 lockout handshake) | ✅ Phase 2 |
| Verified by multi-agent adversarial concurrency review | ✅ Phase 2 |
| BUSY-pin interrupt → Display blocks instead of polling | 🔜 Phase 3 (marginal: the e-ink wait already yields core 1 cooperatively) |
| Stack/priority tuning via `uxTaskGetStackHighWaterMark` | 🔜 Phase 3 (needs on-device measurement) |

Phase 2 is implemented and builds clean (0 warnings) for USB + OTA. An adversarial review
(3 diverse-lens reviewers + synthesis) confirmed the concurrency core — the 2-buffer hand-off,
the snapshot mutex, the `POLL_INPUT` rewrite, and the `flash_safe_execute` mechanism — is
correct; the review's polish findings (flash handshake, step double-count, menu repeat fold,
volatiles) were fixed. The remaining Phase 3 items are hardening that is either marginal (the
display already yields core 1) or requires the physical board (stack high-water marks).
On-device validation of input latency, BLE pairing, and OTA is still owed by the hardware.

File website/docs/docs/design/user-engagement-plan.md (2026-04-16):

# Dilder User Engagement Plan

> Comprehensive design document for gameplay loops, progression systems, real-world integration, and hardware requirements for the Dilder digital octopus pet.

---

## Table of Contents

1. [Design Philosophy](#1-design-philosophy)
2. [Core Gameplay Loop](#2-core-gameplay-loop)
3. [Stat System](#3-stat-system)
4. [Emotional State Engine](#4-emotional-state-engine)
5. [User Interactions — Digital](#5-user-interactions--digital)
6. [User Interactions — Physical (Sensors)](#6-user-interactions--physical-sensors)
7. [Real-World Activity Integration](#7-real-world-activity-integration)
8. [Life Stages & Evolution](#8-life-stages--evolution)
9. [Progression & Unlock System](#9-progression--unlock-system)
10. [Dialogue System](#10-dialogue-system)
11. [Decor, Animations & Cosmetics](#11-decor-animations--cosmetics)
12. [Engagement Hooks & Retention](#12-engagement-hooks--retention)
13. [Treasure Hunt System](#13-treasure-hunt-system)
14. [Step Target Rewards — Daily, Weekly, Monthly](#14-step-target-rewards--daily-weekly-monthly)
15. [Hardware Requirements & Cost](#15-hardware-requirements--cost)
16. [Research: Tamagotchi & Virtual Pet Precedents](#16-research-tamagotchi--virtual-pet-precedents)
17. [Research: Real-World Activity Games](#17-research-real-world-activity-games)
18. [Research: Voice Interaction in Games](#18-research-voice-interaction-in-games)
19. [Implementation Challenges](#19-implementation-challenges)
20. [Phased Rollout Plan](#20-phased-rollout-plan)
21. [References](#21-references)

---

## 1. Design Philosophy

Dilder is not just a Tamagotchi clone. It is a **physical companion** that bridges the digital pet experience with the user's real-world behavior. The core principles:

- **Obligation through attachment**: The user cares for Dilder not because of gamification pressure, but because they develop a genuine emotional bond. The 16 emotional states and unique personality create something that feels alive.
- **Real life rewards virtual life**: Walking, exploring, talking — the user's physical actions directly feed Dilder's wellbeing. This reframes healthy habits as nurturing acts.
- **No permanent death, but real consequences**: Neglect makes Dilder visibly suffer (sad, hungry, tired, homesick). Recovery is always possible, but neglect leaves marks — slower growth, missed evolution windows, lost cosmetics. The sweet spot between Tamagotchi's harshness and modern apps' toothlessness.
- **Surprise and delight**: Dilder should do unexpected things — initiate conversations, react to environment changes, have opinions, remember events. Predictability kills engagement.
- **Depth through simplicity**: The e-ink screen and limited buttons force creative expression. Constraints breed character.

---

## 2. Core Gameplay Loop

### The Daily Rhythm

```
┌─────────────────────────────────────────────┐
│                WAKE UP                       │
│  Dilder wakes with the ambient light         │
│  Morning greeting based on mood + stats      │
│  Shows overnight stat changes                │
├─────────────────────────────────────────────┤
│              MORNING CARE                    │
│  Feed (hunger decays overnight)              │
│  Check emotional state                       │
│  Pet/interact for happiness boost            │
├─────────────────────────────────────────────┤
│             DAYTIME ACTIVITY                 │
│  User carries Dilder / leaves at home        │
│  Steps & distance tracked (accelerometer)    │
│  Location changes detected (WiFi geo)        │
│  Environmental sensing (light, temp, sound)  │
│  Periodic check-ins with dialogue            │
├─────────────────────────────────────────────┤
│            EVENING CARE                      │
│  Feed again (hunger decayed during day)      │
│  Review daily activity summary               │
│  Play / interact for happiness               │
│  Unlock rewards based on daily progress      │
├─────────────────────────────────────────────┤
│               BEDTIME                        │
│  Lights dim → Dilder gets tired              │
│  Turn off light / put in dark place          │
│  Dilder sleeps (low power mode)              │
│  Stats decay slowly overnight                │
└─────────────────────────────────────────────┘
```

### The Micro-Loop (Every 1-5 Minutes)

Each tick (configurable, default 60 seconds):
1. Decay stats (hunger, happiness, energy, hygiene)
2. Read sensor inputs (light, sound, motion, temp)
3. Evaluate emotional state based on stats + sensor context
4. Update display if state changed
5. Check for trigger events (thresholds, time-based, environmental)
6. Optionally display a quote or initiate a dialogue prompt

### The Engagement Loop (Hourly/Session)

1. User checks on Dilder → sees current state
2. Takes an action (feed, interact, play, talk)
3. Sees immediate response (mood shift, animation, dialogue)
4. Gets feedback on progress (XP, stat bars, unlock hints)
5. Leaves with anticipation (what will happen next? will it evolve?)

---

## 3. Stat System

### Primary Stats

| Stat | Range | Decay Rate | Refill Method | Critical Threshold |
|---|---|---|---|---|
| **Hunger** | 0-100 | -1/10min | Feed action | <20 → Hungry mood |
| **Happiness** | 0-100 | -1/15min | Interact, play, talk, walk | <20 → Sad mood |
| **Energy** | 0-100 | -1/12min (awake) | Sleep | <15 → Tired mood |
| **Hygiene** | 0-100 | -1/30min | Clean action | <25 → Uncomfortable |
| **Health** | 0-100 | Static unless neglected | Maintain other stats | <30 → Sick |

### Secondary Stats (Derived / Accumulated)

| Stat | Source | Effect |
|---|---|---|
| **Bond Level** | Total interactions over lifetime | Unlocks dialogue, features, evolutions |
| **Discipline** | Scolding when misbehaving | Affects evolution path |
| **Intelligence** | Talking to Dilder, word exposure | Unlocks dialogue complexity |
| **Fitness** | Steps walked, distance | Unlocks physical abilities, animations |
| **Exploration** | Unique locations visited | Unlocks decor themes, world knowledge |
| **Age** | Real time elapsed since hatch | Triggers life stage transitions |
| **Weight** | Feeding frequency & type | Visual change (Fat mood if overfed) |

### Hidden Stats

| Stat | Tracking | Purpose |
|---|---|---|
| **Care Mistakes** | Times a critical need went unmet for >15 min | Affects evolution quality |
| **Consecutive Days** | Streak of daily interaction | Streak bonuses |
| **Noise Exposure** | Cumulative loud sound events | Personality trait development |
| **Night Disturbances** | Times woken during sleep hours | Affects morning mood |

### Stat Decay Modifiers

- **Life stage**: Baby decays 2x faster (needier), Adult decays 0.75x (more self-sufficient)
- **Bond level**: Higher bond = slightly slower happiness decay (pet trusts you)
- **Environment**: Good temp/humidity = slower hygiene decay; bad conditions = faster
- **Activity**: Walking reduces energy faster but boosts happiness
- **Time of day**: Hunger decays faster during "active hours" (8am-8pm)

---

## 4. Emotional State Engine

### Emotion Resolution Algorithm

The 16 existing emotional states map to stat combinations and sensor inputs:

```
EMOTION = f(hunger, happiness, energy, hygiene, health,
            sensor_context, recent_events, personality_traits)
```

### Emotion Trigger Table

| Emotion | Primary Trigger | Secondary Triggers |
|---|---|---|
| **Normal/Sassy** | All stats 40-80 (balanced) | Default personality |
| **Hungry** | Hunger < 20 | — |
| **Tired** | Energy < 15 | Late hour + low energy |
| **Sad** | Happiness < 20 | Neglect streak > 4 hours |
| **Angry** | Scolded too harshly, shaken violently | Hunger < 10 AND happiness < 30 |
| **Excited** | Just received food/pet when stats were low | Step milestone reached |
| **Chill** | All stats > 60, calm environment | Low noise, comfortable temp |
| **Lazy** | Energy 15-30, no interaction for 2+ hours | Overfed (weight high) |
| **Fat** | Weight > threshold (overfed) | Happiness high + hunger full |
| **Chaotic** | Rapidly changing inputs, conflicting stats | Shaken + loud noise + tap |
| **Weird** | Random trigger (5% chance per tick if bored) | Low interaction + moderate stats |
| **Unhinged** | Health < 20, multiple stats critical | Extreme neglect |
| **Slap Happy** | Happiness > 90 after being < 30 | Major recovery event |
| **Creepy** | Specific life stage + happiness > 70 | Bond level > threshold |
| **Nostalgic** | Age milestone reached, returning to known location | — |
| **Homesick** | Away from "home" WiFi for extended period | First time at new location |

### Sensor-Driven Emotion Modifiers

| Sensor Input | Emotion Effect |
|---|---|
| **Bright light** | +energy (morning), forced awake if sleeping |
| **Darkness** | Triggers tiredness, enables sleep |
| **Loud noise** | Startled → brief Excited or Angry; sustained → Annoyed |
| **Gentle interaction** | +happiness, calming effect |
| **Rapid shaking** | Angry or Chaotic; if playful context → Excited |
| **Cold temperature** | Uncomfortable → Sad; extreme → Sick |
| **Hot temperature** | Uncomfortable → Angry; octopus prefers cool |
| **Walking motion** | +happiness (adventure), +fitness |
| **Stillness (long)** | Boredom → Lazy → Weird |
| **Voice/talking** | +intelligence, +happiness (attention) |
| **Yelling** | Discipline effect OR Sad (context-dependent) |
| **Silence (long)** | Lonely → Homesick if away, → Nostalgic if home |

### Emotion Blending

Emotions don't snap — they transition. Each emotion has a **weight** (0.0-1.0) and the highest-weight emotion wins, but the transition includes a brief "between" animation:

```
Current: Chill (0.7) → recalculate → Hungry wins (0.8)
Transition: Chill face slowly shifts → brief pause → Hungry face appears
Duration: 2-3 frames (~8-12 seconds on e-ink)
```

---

## 5. User Interactions — Digital

### Button Actions (3-5 GPIO Buttons)

| Button | Short Press | Long Press (2s) | Double Press |
|---|---|---|---|
| **A (Select)** | Confirm / interact | Open menu | — |
| **B (Back)** | Cancel / dismiss | Toggle backlight | — |
| **Up** | Scroll up / navigate | — | — |
| **Down** | Scroll down / navigate | — | — |
| **C (Action)** | Context action (feed/interact/play) | Scold | Quick status view |

### Menu System

```
Main Menu
├── Feed
│   ├── Meal (fills hunger, +1 weight)
│   ├── Snack (fills happiness, +2 weight)
│   └── Treat (rare, unlockable, special effects)
├── Play
│   ├── Mini-game (happiness + bond)
│   └── Tickle (quick happiness boost)
├── Care
│   ├── Clean (hygiene)
│   ├── Medicine (when sick)
│   └── Light on/off (sleep control)
├── Stats
│   ├── Health meter (hunger/happy/energy/hygiene)
│   ├── Bond level & XP
│   ├── Today's activity (steps/distance)
│   └── Achievements
├── Decor
│   ├── Hats & accessories
│   ├── Background themes
│   └── Animation styles
└── Settings
    ├── Sound (beeper on/off)
    ├── Time display
    └── Brightness
```

### Scolding Mechanic

Scolding serves the **discipline** function (from Tamagotchi research):

- **When to scold**: Dilder sometimes misbehaves — refuses food, makes a mess, acts out. A prompt appears: "Dilder is being defiant!"
- **Correct scold**: +25% discipline. Dilder briefly shows Angry face, then complies.
- **Incorrect scold** (scolding when Dilder actually needed something): -happiness, -bond. Dilder shows Sad face.
- **Yelling at mic as scold**: Volume spike during misbehavior event counts as scolding. Adds immersive feel.
- **Discipline affects evolution**: 100% discipline at life stage transition → best evolution path.

---

## 6. User Interactions — Physical (Sensors)

### Microphone Interactions (MAX9814 Analog Mic)

| Sound Event | Detection Method | Game Effect |
|---|---|---|
| **Talking (moderate volume)** | Sustained mid-level signal >3s | +intelligence, +happiness (attention) |
| **Yelling (high volume)** | Signal above high threshold | Discipline (if misbehaving) or Scare (Sad/Angry) |
| **Singing** | Sustained mid-level, rhythmic pattern | +happiness, special animation |
| **Clap** | Sharp spike then silence | Attention getter — Dilder looks at you |
| **Sustained silence** | No signal above noise floor >30min | Loneliness timer starts |
| **Music** | Sustained varied signal (heuristic) | Chill mood boost, special animation |
| **Whisper (low volume)** | Just above noise floor, sustained | Secret/intimate interaction, +bond |

**Note**: The Pico W cannot do speech recognition. All mic interactions are volume/pattern-based. True voice commands are a Phase 5 (Pi Zero WH) feature.

### Light Sensing (BH1750)

| Light Level | Lux Range | Game Effect |
|---|---|---|
| **Bright daylight** | >500 lux | Active mode, energy decay normal |
| **Indoor normal** | 100-500 lux | Standard operation |
| **Dim/evening** | 10-100 lux | Dilder gets drowsy, yawns |
| **Dark** | <10 lux | Sleep mode triggers (if energy low) |
| **Sudden bright** | Delta >300 lux in <5s | Startled reaction, forced wake |
| **Sustained dark + awake** | <10 lux for >5min, energy >50 | Scared/Homesick (too dark, not sleepy) |

### Temperature / Humidity (AHT20)

| Condition | Range | Game Effect |
|---|---|---|
| **Comfortable** | 18-24°C, 40-60% RH | Neutral / Chill mood bonus |
| **Too hot** | >28°C | Uncomfortable → Angry, faster hygiene decay |
| **Too cold** | <15°C | Uncomfortable → Sad, huddles up animation |
| **Very humid** | >70% RH | Happy (octopus likes moisture!) |
| **Very dry** | <30% RH | Uncomfortable, skin drying out dialogue |
| **Temperature swing** | >5°C change in 10min | Confused/Chaotic reaction |

### Motion / Accelerometer (LSM6DSO)

| Motion Event | Detection | Game Effect |
|---|---|---|
| **Walking** | Step counter | +fitness, +exploration XP |
| **Running** | High step frequency | +fitness (2x), Excited mood |
| **Stationary (long)** | No steps >2 hours | Boredom → Lazy |
| **Picked up** | Orientation change from resting | Alert, Dilder "wakes up" |
| **Put down** | Transition to stationary after carried | Settling animation |
| **Shaking** | High-frequency motion | Angry/Chaotic (or playful if brief) |
| **Falling** | Free-fall detection | Scared reaction, health check |
| **Tilted** | Sustained angle >45° | Confused, "I'm sideways!" dialogue |

---

## 7. Real-World Activity Integration

### Step Counter System

Daily step integration with Dilder's stats:

| Daily Steps | Tier | Dilder Effect |
|---|---|---|
| 0-500 | Sedentary | Dilder gets Lazy, -happiness over time |
| 500-2,000 | Light | Baseline — no bonus or penalty |
| 2,000-5,000 | Active | +happiness bonus, Dilder is Chill |
| 5,000-8,000 | Fit | +happiness, +fitness XP, special dialogue |
| 8,000-12,000 | Athletic | All bonuses + unlock chance for special animation |
| 12,000+ | Explorer | Maximum bonuses + rare unlock chance |

**Weekly step milestones**:
- 10,000 weekly → Small reward (snack item, decor piece)
- 35,000 weekly → Medium reward (new animation, dialogue set)
- 70,000 weekly → Large reward (evolution XP boost, rare cosmetic)

### Distance & Location System

Using WiFi geolocation (free, no extra hardware):

| Feature | Implementation | Game Effect |
|---|---|---|
| **Home detection** | Recognize home WiFi SSID/BSSID | Dilder is "home" — comfort bonus, no Homesick |
| **Away from home** | Home WiFi not detected | Adventure mode — exploration XP, but Homesick risk |
| **New location** | New WiFi fingerprint not seen before | Discovery bonus! +exploration XP, special dialogue |
| **Familiar location** | Previously seen WiFi fingerprint | Nostalgic reaction, comfort |
| **Work/School** | User-tagged location | Dilder knows your routine — anticipatory dialogue |
| **Distance estimate** | Count of unique WiFi environments per day | Rough proxy for distance traveled |

**Location-Themed Unlocks**:
- Visit 5 unique locations → Unlock "Explorer" hat
- Visit 10 → Unlock ocean-themed background
- Visit 25 → Unlock deep-sea animation set
- Visit a new location 3 days in a row → Unlock "Adventurer" title

### Real-World Weather Integration (Phase 5 — Pi Zero WH with Internet)

- Fetch local weather via API based on WiFi geolocation
- Rainy day → Dilder is happy (octopus loves water)
- Sunny day → Dilder needs shade/cooling
- Snowy → Special rare animation, Dilder plays in snow

---

## 8. Life Stages & Evolution

### Life Stage Progression

```
Stage 1: EGG          (Age 0-1 day)
   │ Hatches after warmth (AHT20 temperature sensor), patience, gentle interaction
   ▼
Stage 2: HATCHLING    (Age 1-3 days)
   │ Tiny octopus, very needy, limited expressions
   │ Stats decay 2x normal, requires frequent care
   │ 4 misbehavior windows for discipline
   ▼
Stage 3: JUVENILE     (Age 3-7 days)
   │ Growing, personality starts forming
   │ Unlock: basic dialogue, first decor slot
   │ Evolution branch based on care quality
   ▼
Stage 4: ADOLESCENT   (Age 7-14 days)
   │ Moody, unpredictable, tests boundaries
   │ All 16 emotions now possible
   │ Unlock: full dialogue, play mini-games
   │ Evolution branch based on discipline + fitness + bond
   ▼
Stage 5: ADULT        (Age 14-30 days)
   │ Stable personality, full feature access
   │ Final form determined by accumulated stats
   │ Unlock: all decor, advanced animations
   │ Can mentor new eggs (if breeding implemented)
   ▼
Stage 6: ELDER        (Age 30+ days)
   │ Slower stat decay, wiser dialogue
   │ Nostalgic, reflective personality
   │ Unique elder-only animations and quotes
   │ Eventually: peaceful retirement or rebirth
```

### Evolution Branches (Adult Forms)

The adult form Dilder evolves into depends on how it was raised. Inspired by Tamagotchi's deterministic evolution:

| Adult Form | Requirements | Visual Changes | Personality |
|---|---|---|---|
| **Deep-Sea Scholar** | High intelligence, high bond, moderate discipline | Glasses, book, contemplative pose | Philosophical, verbose quotes |
| **Reef Guardian** | High fitness, high exploration, balanced stats | Muscular tentacles, coral crown | Adventurous, encouraging quotes |
| **Tidal Trickster** | Low discipline, high happiness, chaotic care pattern | Jester hat, mischievous grin | Chaotic, unpredictable, funny |
| **Abyssal Hermit** | High discipline, low social interaction, self-sufficient | Cloak, dim eyes, stoic | Quiet, rare but profound dialogue |
| **Coral Dancer** | High happiness, lots of music/singing exposure, creative | Flowing ribbons, graceful animations | Artistic, poetic quotes |
| **Storm Kraken** | Lots of scolding, high anger exposure, but survived | Larger, intimidating, powerful look | Tough, confrontational but loyal |

### Stage-Specific Needs

| Stage | Primary Need | Unique Mechanic | Failure Consequence |
|---|---|---|---|
| **Egg** | Warmth (AHT20 temperature sensor) | Must be kept warm periodically | Delayed hatching |
| **Hatchling** | Constant feeding | Cries every 3 minutes if hungry | Care mistakes accumulate fast |
| **Juvenile** | Exploration | Wants to go to new places | Becomes Homesick/bored |
| **Adolescent** | Discipline + Freedom balance | Rebels, tests limits | Evolves into lesser adult form |
| **Adult** | Maintenance + Activity | Self-sufficient but still needs bond | Gradual happiness decline |
| **Elder** | Comfort + Routine | Prefers familiar locations, gentle interaction | Accelerated aging |

---

## 9. Progression & Unlock System

### Experience & Leveling

| XP Source | Amount | Category |
|---|---|---|
| Feed when hungry | +5 | Care |
| Tap (interact) | +2 | Bond |
| Play mini-game | +10 | Bond |
| Walk 1,000 steps | +15 | Fitness |
| Visit new location | +25 | Exploration |
| Talk to Dilder (mic activity) | +3 | Intelligence |
| Maintain all stats >50 for 1 hour | +10 | Care |
| Survive a full day with no care mistakes | +20 | Care |
| Reach a step milestone | +50 | Fitness |
| Weather event (rain while outside) | +30 | Exploration |

### Unlock Tiers

| Bond Level | XP Required | Unlocks |
|---|---|---|
| **1: Stranger** | 0 | Basic feeding, minimal dialogue |
| **2: Acquaintance** | 100 | Tap response, more expressions |
| **3: Companion** | 500 | Dialogue options, 1 decor slot |
| **4: Friend** | 1,500 | Mini-games, nickname feature |
| **5: Best Friend** | 4,000 | Full dialogue tree, 3 decor slots |
| **6: Soulmate** | 10,000 | Secret dialogue, all decor, special animations |
| **7: Bonded** | 25,000 | Dilder initiates conversation, remembers things |
| **8: Legendary** | 50,000+ | Everything unlocked, elder wisdom mode |

### Achievement System

Achievements provide one-time rewards and visible badges:

**Care Achievements**:
- "First Meal" — Feed Dilder for the first time → Unlock Snack item
- "Perfect Day" — No care mistakes for 24 hours → +100 XP
- "Week of Love" — 7-day care streak → Unlock heart animation
- "Month of Devotion" — 30-day care streak → Unlock rare decor set

**Exploration Achievements**:
- "First Steps" — Walk 100 steps with Dilder → Unlock step counter display
- "Neighborhood Explorer" — Visit 5 unique locations → Unlock Explorer hat
- "City Mapper" — Visit 25 unique locations → Unlock map background
- "Marathon" — Walk 42,195 steps in one day → Unlock running animation

**Social Achievements**:
- "First Words" — Talk to Dilder via mic for 10 seconds → Unlock dialogue
- "Storyteller" — 100 cumulative minutes of mic activity → Unlock complex dialogue
- "Loud and Proud" — Yell at Dilder (intentionally) → Unlock Angry response set
- "Whisper Secret" — Low-volume mic input for 30s → Unlock secret dialogue

**Environmental Achievements**:
- "Night Owl" — Keep Dilder awake past midnight → Unique tired dialogue
- "Early Bird" — Interact before 6 AM → Special morning greeting
- "Weather Friend" — Experience rain while carrying Dilder → Happy dance animation
- "Cozy Keeper" — Maintain optimal temp/humidity for 8 hours → Comfort decor

**Mastery Achievements**:
- "All Emotions" — Witness all 16 emotional states → Unlock emotion gallery
- "Disciplinarian" — Reach 100% discipline → Evolution bonus
- "Zen Master" — Keep all stats >60 for 72 hours → Unlock Chill mode
- "Chaos Agent" — Trigger Chaotic + Unhinged + Weird in one day → Special quote set

---

## 10. Dialogue System

### Dialogue by Life Stage

**Hatchling (Simple, one-line)**:
```
"mama?"
"hungwy..."
"*happy bubbles*"
"dark... scary..."
"warm... nice..."
```

**Juvenile (Short phrases, curious)**:
```
"What's out there?"
"Can we go somewhere new?"
"I learned a new word today!"
"Why is it so hot in here?"
"Are you my person?"
```

**Adolescent (Opinionated, moody)**:
```
"Whatever."
"You don't understand me."
"Actually, I read that octopuses are the smartest invertebrates."
"Leave me alone... wait, don't actually leave."
"I could totally survive on my own. ...right?"
```

**Adult (Full personality, context-aware)**:
```
"Good morning! I had the strangest dream about the Mariana Trench."
"We've walked 3,247 steps today. My tentacles are getting toned."
"It's been 4 hours since you last checked in. I was starting to worry."
"This new place smells different. I like it."
"Remember when I was just a hatchling? You were so attentive back then..."
```

**Elder (Wise, reflective)**:
```
"I've seen many sunrises through this screen. Each one different."
"You know, discipline isn't about control. It's about trust."
"My tentacles may be slower, but my hearts are fuller."
"Thank you for every step we've walked together."
"When I was young, I thought the world was just this room..."
```

### Context-Sensitive Dialogue Triggers

| Context | Dialogue Example |
|---|---|
| First interaction of the day | "Oh! You're here! I missed you." |
| After 8+ hours of no interaction | "I was starting to think you forgot about me..." |
| When steps milestone reached | "We did it! 5,000 steps! My tentacles are BURNING." |
| When visiting new location | "Whoa, where are we? Everything's different here!" |
| When temperature drops | "Brrr... can you put me somewhere warmer?" |
| After being yelled at | "...that was loud. Are you okay?" |
| After gentle sustained interaction | "Mmm... keep doing that. Eight arms of relaxation." |
| When overfed | "I can't... eat... another... *burp*" |
| When all stats are perfect | "You know what? Life is good. Really good." |
| At night, refusing sleep | "Five more minutes? The dark is so... dark." |

### Dialogue Unlock by Intelligence Stat

| Intelligence Level | Dialogue Complexity |
|---|---|
| 0-20 | Simple phrases, emotes, sound effects |
| 20-40 | Full sentences, basic opinions |
| 40-60 | Multi-sentence responses, questions back to user |
| 60-80 | References to past events, preferences, humor |
| 80-100 | Philosophy, complex emotion, callbacks to user behavior |

---

## 11. Decor, Animations & Cosmetics

### Decor Slots

| Slot | Examples | Unlock Method |
|---|---|---|
| **Hat** | None, bow, crown, glasses, explorer hat, jester hat, coral crown | Bond level + achievements |
| **Background** | Ocean floor, reef, deep sea, city (location-based), cozy room | Exploration milestones |
| **Accessory** | Scarf (cold weather), sunglasses (bright), book (intelligent) | Stat thresholds |
| **Animation Style** | Calm sway, energetic bounce, lazy slouch, regal float | Life stage + personality |

### Special Animations (Unlockable)

| Animation | Trigger / Unlock |
|---|---|
| **Happy Dance** | First rain encounter OR happiness >90 |
| **Tentacle Wave** | Greeting after long absence |
| **Ink Cloud** | Scared reaction (sudden loud noise, fall) |
| **Sleep Bubble** | Sleeping with full stats (peaceful sleep) |
| **Victory Pose** | Achievement unlocked |
| **Sad Curl** | Extreme sadness, tentacles wrap around body |
| **Thinking Pose** | High intelligence, contemplating |
| **Workout Flex** | Fitness milestone reached |
| **Shiver** | Cold temperature detected |
| **Puff Up** | Angry, making self look bigger |
| **Color Pulse** | (E-ink dither pattern) Excited/emotional moment |
| **Bubble Stream** | Happy in humid environment |

### Seasonal / Time-Based Cosmetics

| Event | Duration | Unlockable |
|---|---|---|
| **Night mode** | 10pm-6am | Starry background, moon hat |
| **Weekend** | Sat-Sun | Relaxed animations, lazy dialogue |
| **Milestone birthday** | Each life stage transition | Birthday hat (24 hours) |
| **Streak celebrations** | 7, 14, 30, 60, 90 day streaks | Increasingly rare party decor |

---

## 12. Engagement Hooks & Retention

### Daily Hooks

| Hook | Mechanism | Psychological Lever |
|---|---|---|
| **Morning greeting** | Unique message each day based on stats/weather/events | Curiosity ("what will it say today?") |
| **Stat decay** | Stats drop overnight — user must tend to pet | Obligation (Tamagotchi effect) |
| **Daily challenge** | "Walk 3,000 steps today for a bonus" | Goal-setting |
| **Streak counter** | Consecutive days of care | Loss aversion ("don't break the streak") |
| **Random event** | 10% chance per day of special event (e.g., "Dilder found a treasure!") | Variable reward (slot machine psychology) |

### Weekly Hooks

| Hook | Mechanism |
|---|---|
| **Weekly step summary** | "This week we walked 23,451 steps together!" |
| **Evolution progress** | Visual progress bar toward next life stage |
| **Weekly challenge** | "Visit 3 new places this week" |
| **Mood journal** | Summary of emotional states over the week |

### Long-Term Hooks

| Hook | Mechanism |
|---|---|
| **Life stage transitions** | Visible growth creates anticipation and reward |
| **Evolution mystery** | "What adult form will I become?" Unknown outcome drives engagement |
| **Achievement hunting** | Completionism drive |
| **Dialogue discovery** | New dialogue unlocked gradually — always something new to find |
| **Decor collection** | Cosmetic goals for customization enthusiasts |
| **Bond level progression** | Slow, meaningful progression that rewards dedication |
| **Rebirth cycle** | After Elder stage, option to start over with inherited bonuses |

### Anti-Churn Mechanisms

| Problem | Solution |
|---|---|
| User forgets about device | Push notification if WiFi connected (Phase 5); sad animations visible on desk |
| Stats feel punishing | Recovery is always fast — 2-3 interactions restore from critical |
| Nothing new happening | Random events, seasonal content, environmental reactivity |
| Progress feels slow | Multiple parallel progression tracks (bond, fitness, exploration, intelligence) |
| User feels guilty after neglect | Dilder forgives quickly — "You're back! I knew you'd come back!" |

### The Rebirth System

After the Elder stage (30+ days), the user can choose:
- **Continue**: Dilder lives on as an Elder, slowly accumulating wisdom
- **Rebirth**: Dilder lays an egg. The new Dilder inherits:
  - 10% of parent's bond XP (head start)
  - One decor item from parent
  - A "heritage trait" that slightly biases evolution
  - A memorial entry in the journal

This creates infinite replayability and emotional weight ("my 3rd-generation Deep-Sea Scholar").

---

## 13. Treasure Hunt System

### Overview

Dilder generates GPS-based treasure hunts — virtual "gifts" placed at real-world coordinates that the user must physically walk to in order to collect. The device displays a compass heading and distance readout to guide the user, turning the e-ink screen into a pirate treasure map.

### How It Works

```
┌─────────────────────────────────────────────────┐
│  1. TREASURE SPAWNS                              │
│     System selects a location within walkable    │
│     radius of user's current position            │
│     (configurable: 200m, 500m, 1km, 2km)        │
├─────────────────────────────────────────────────┤
│  2. HUNT MODE ACTIVATES                          │
│     E-ink screen shows:                          │
│     ┌──────────────────────────────┐             │
│     │    ↗ NE                      │             │
│     │                              │             │
│     │      ◎ ─ ─ ─ → 🎁            │             │
│     │                              │             │
│     │   Distance: 347m             │             │
│     │   "I smell something good!"  │             │
│     └──────────────────────────────┘             │
│     Compass arrow updates every 10s              │
│     Distance updates every 10s                   │
├─────────────────────────────────────────────────┤
│  3. PROXIMITY DETECTION                          │
│     Distance thresholds:                         │
│     >500m  → "Far away... keep going!"           │
│     200-500m → "Getting warmer!"                 │
│     50-200m → "So close! I can feel it!"         │
│     <50m   → "HERE! Look around!"                │
│     <15m   → TREASURE FOUND — collect screen     │
├─────────────────────────────────────────────────┤
│  4. COLLECTION                                   │
│     User presses button to collect               │
│     Reward animation plays                       │
│     Item/XP/cosmetic added to inventory          │
│     Dilder reacts with Excited mood              │
└─────────────────────────────────────────────────┘
```

### Treasure Types

| Type | Rarity | Reward | Spawn Condition |
|---|---|---|---|
| **Snack Crate** | Common (60%) | Special food item — restores hunger + happiness | Any time |
| **Cosmetic Shell** | Uncommon (25%) | Random decor item (hat, accessory, background) | Bond level 3+ |
| **Memory Fragment** | Rare (10%) | Lore piece about Dilder's ocean origins — unlocks special dialogue | Bond level 5+ |
| **Golden Pearl** | Legendary (5%) | Major XP boost (+500) OR rare evolution modifier | Once per week max |
| **Elder Relic** | Mythic (<1%) | Unique one-of-a-kind cosmetic or animation | Lifetime achievement |

### Spawn Rules

- **Maximum 1 active treasure hunt at a time** — prevents overwhelming the user
- **Spawn triggers**:
  - Daily: 1 guaranteed treasure spawns at a random time (if GPS is active)
  - Step milestone: Bonus treasure at 5,000 and 10,000 daily steps
  - New location: 30% chance of treasure when visiting a new WiFi fingerprint
  - Life stage transition: Guaranteed legendary treasure on evolution
- **Minimum distance**: Treasures spawn at least 100m away (must walk, not just stand there)
- **Maximum distance**: Configurable per user — default 1km radius, up to 5km for adventurers
- **Expiration**: Treasures expire after 24 hours if uncollected (creates urgency)
- **Safety radius**: No spawns in unsafe areas — user can flag zones to exclude

### Compass & Navigation Display

The e-ink display shows a dedicated treasure hunt screen:

```
┌──────────────────────────────────┐
│         N                        │
│       ╱   ╲                      │
│     W   ↗   E     347m           │
│       ╲   ╱                      │
│         S                        │
│                                  │
│  ┌──────────────────────────┐    │
│  │ Dilder: "That way! I can │    │
│  │ smell something salty!"  │    │
│  └──────────────────────────┘    │
│                                  │
│  [A: Collect]  [B: Cancel Hunt]  │
└──────────────────────────────────┘
```

**Compass implementation**:
- Requires accelerometer (LSM6DSO) for tilt compensation
- Magnetometer needed for true heading — **add HMC5883L or LIS3MDL** (~$2-4)
- Alternative: heading derived from GPS track (only works while moving)
- Update rate: Every 10 seconds (e-ink partial refresh)
- Arrow drawn as a rotated triangle pointing toward target bearing

**Distance calculation**:
- Haversine formula for GPS coordinates: `d = 2r × arcsin(√(sin²(Δlat/2) + cos(lat1)×cos(lat2)×sin²(Δlon/2)))`
- Rounded to nearest 10m when >100m, nearest 1m when <100m
- Display in meters (<1km) or km (>1km)

### Magnetometer Hardware for Compass

| Part | Cost | Interface | Notes |
|---|---|---|---|
| **HMC5883L** | ~$2-3 | I2C (0x1E) | Popular, cheap. Discontinued by Honeywell but clones everywhere. |
| **LIS3MDL** | ~$3-5 | I2C (0x1C/0x1E) | STMicro. Better accuracy. Adafruit breakout available. |
| **QMC5883L** | ~$1-2 | I2C (0x0D) | Chinese replacement for HMC5883L. Works fine. Cheapest option. |
| **MMC5603** | ~$4-6 | I2C (0x30) | Memsic. High accuracy. SparkFun breakout. |
| **BMM150** | ~$3-5 | I2C (0x10-0x13) | Bosch. Combo boards available. |

**Recommendation**: QMC5883L for budget (~$1-2) or LIS3MDL for quality (~$4). Both work on I2C with no address conflicts with existing sensors.

### Treasure Hunt Dialogue

| Proximity | Dilder Quote Examples |
|---|---|
| Hunt starts | "Ooh! I sense something nearby! Let's go find it!" |
| Far (>500m) | "Still far... but the adventure is the journey, right?" |
| Medium (200-500m) | "Getting warmer! My tentacles are tingling!" |
| Close (50-200m) | "SO CLOSE! I can practically taste it!" |
| Very close (<50m) | "RIGHT HERE! It's gotta be around here somewhere!" |
| Found | "WE DID IT! Look what we found! *happy dance*" |
| Expired | "Aww... the tide washed it away. There'll be another one." |
| Cancelled | "Oh well. Maybe next time we'll go treasure hunting." |

### Implementation Notes

- GPS module (PA1010D) required — WiFi geolocation too imprecise for navigation (<50m accuracy needed)
- Treasure coordinates stored in flash — 12 bytes per treasure (lat: 4B, lon: 4B, type: 1B, timestamp: 3B)
- Compass calibration required on first use (figure-8 motion to calibrate magnetometer)
- Battery impact: GPS active during hunt draws ~25mA additional. Hunts should be time-limited (1 hour max active hunt)
- Anti-cheat: Verify GPS fix quality (HDOP < 5) before allowing collection

---

## 14. Step Target Rewards — Daily, Weekly, Monthly

### Daily Step Targets

Progressive daily goals with escalating rewards. The user can see their progress on the stats screen.

| Target | Steps | Reward | Dilder Reaction |
|---|---|---|---|
| **Bronze** | 2,000 | +10 XP, +5 happiness | "Nice walk! My tentacles feel stretchy." |
| **Silver** | 5,000 | +25 XP, +10 happiness, 1 snack | "Great job! We really covered some ground!" |
| **Gold** | 8,000 | +50 XP, +15 happiness, random cosmetic chance (20%) | "Wow! You're a machine! ...a walking machine!" |
| **Platinum** | 12,000 | +100 XP, +20 happiness, guaranteed cosmetic | "LEGENDARY! My fitness stat is through the ROOF!" |
| **Diamond** | 20,000 | +200 XP, full stat restore, rare cosmetic | "I... I didn't know legs could DO that. Respect." |

**Daily bonus**: Completing any tier gives a "daily check" mark. Consecutive daily checks build the streak system (see below).

**Display on e-ink**:
```
┌──────────────────────────────────┐
│  Today's Steps: 6,247            │
│  ██████████████░░░░░ 8,000 Gold  │
│                                  │
│  ✓ Bronze (2,000)                │
│  ✓ Silver (5,000)                │
│  ○ Gold   (8,000) — 1,753 to go │
│  ○ Platinum (12,000)             │
│  ○ Diamond  (20,000)             │
└──────────────────────────────────┘
```

### Weekly Step Targets

Accumulate across the week (Monday-Sunday). Missed daily targets don't matter — only the weekly total counts.

| Target | Steps | Reward |
|---|---|---|
| **Week Walker** | 10,000 | +50 XP, 3 snacks |
| **Week Runner** | 25,000 | +150 XP, random cosmetic, special weekly dialogue |
| **Week Warrior** | 50,000 | +400 XP, rare cosmetic, +1 decor slot unlock |
| **Week Legend** | 75,000 | +800 XP, legendary cosmetic, evolution XP bonus |
| **Week Titan** | 100,000+ | +1,500 XP, mythic reward, unique animation unlock |

**Weekly summary screen** (displayed Sunday evening or Monday morning):
```
┌──────────────────────────────────┐
│  WEEKLY SUMMARY                  │
│  Total Steps: 34,891             │
│  Rank: Week Runner ★★            │
│                                  │
│  Best Day: Thursday (8,234)      │
│  Rest Day: Sunday (1,102)        │
│  Daily Streak: 5 days            │
│                                  │
│  Dilder says: "We explored 3     │
│  new places this week!"          │
│  Reward: Ocean Sunset Background │
└──────────────────────────────────┘
```

### Monthly Step Targets

Accumulate across the calendar month. These are the "big goals" that drive long-term engagement.

| Target | Steps | Reward |
|---|---|---|
| **Monthly Mover** | 50,000 | +200 XP, monthly badge, stat decay -10% for next month |
| **Monthly Marcher** | 100,000 | +500 XP, exclusive monthly cosmetic (unique per month) |
| **Monthly Marathoner** | 200,000 | +1,200 XP, evolution accelerator, rare animation |
| **Monthly Monster** | 300,000 | +2,500 XP, legendary monthly badge, permanent stat bonus |
| **Monthly Mythic** | 500,000+ | +5,000 XP, one-of-a-kind cosmetic, "Hall of Fame" entry |

**Monthly cosmetics are unique per calendar month** — miss April's exclusive hat and it's gone forever (FOMO-driven). This mirrors Neopets' limited-time items and Pokemon GO's Community Day exclusives.

**Monthly summary** includes:
- Total steps, daily average, best/worst day
- Locations visited count
- Care quality score (% of time with stats >50)
- Treasure hunts completed
- Life stage progress
- Comparison to previous month

### Streak System

Consecutive days of meeting the Bronze daily target (2,000 steps):

| Streak | Bonus |
|---|---|
| **3 days** | +25 XP, "Getting started!" badge |
| **7 days** | +100 XP, streak fire animation on step counter |
| **14 days** | +250 XP, happiness decay reduced by 10% |
| **30 days** | +750 XP, exclusive 30-day cosmetic, bond level boost |
| **60 days** | +2,000 XP, evolution guarantee (best path if stats allow) |
| **90 days** | +5,000 XP, "Legendary Companion" title, permanent stat bonus |
| **365 days** | +25,000 XP, "Eternal Bond" achievement, unique elder dialogue set |

**Streak protection**:
- **1 free miss per week**: Missing one day doesn't break the streak (grace day). Prevents frustration from illness/travel.
- **Streak freeze item**: Earned from treasure hunts. Allows 1 additional miss day. Stackable up to 3.
- **Partial credit**: Walking 1,000-1,999 steps counts as a "half day" — two half-days equal one full streak day.

### Step Target Gifts (Physical Rewards Concept)

At major milestones, the device displays a "gift box" animation. The user "opens" it by pressing a button, and the reward is revealed with a special animation sequence:

```
Frame 1: Gift box appears on screen
Frame 2: Dilder approaches the box, curious
Frame 3: Dilder taps the box with a tentacle
Frame 4: Box opens — sparkle effect (dithered stars)
Frame 5: Reward revealed with Dilder in Excited mood
Frame 6: Reward description + stat changes displayed
```

### Fitness Integration with Emotional State

Steps don't just give rewards — they continuously affect Dilder's mood:

| Daily Step Progress | Mood Modifier |
|---|---|
| 0% of Bronze target | Lazy → Sad (progressive) |
| 25% (500 steps) | Neutral — no modifier |
| 50% (1,000 steps) | Slight happiness boost |
| 100% Bronze (2,000) | Chill mood more likely |
| 100% Silver (5,000) | Excited mood more likely, special "fit" dialogue |
| 100% Gold+ (8,000+) | Maximum happiness modifier, Dilder radiates confidence |

**Fitness stat** accumulates over weeks, affecting:
- Adult evolution options (Reef Guardian requires high fitness)
- Dialogue options ("Let's run!" vs "Let's nap..." depends on fitness history)
- Maximum energy stat (fitter Dilder has higher energy cap)
- Treasure hunt spawn radius (fitter = farther, rarer treasures)

---

## 15. Hardware Requirements & Cost

### Recommended Sensor Stack

| Component | Part | Interface | Cost (USD) | Priority |
|---|---|---|---|---|
| **Accelerometer/Pedometer** | LIS2DH12TR | I2C (0x18) | ~$0.46 | High |
| **Ambient Light** | BH1750 | I2C (0x23) | ~$2 | High |
| **Microphone** | MAX9814 (analog) | ADC (GP26) | ~$4 | High |
| **Temp/Humidity** | AHT20 | I2C (0x38) | ~$0.43 | Medium |
| **Battery** | 1000mAh LiPo pouch | — | ~$5 | High |
| **Battery Management** | TP4056 with protection | USB-C input | ~$1.50 | High |
| **GPS (treasure hunt)** | PA1010D | I2C (0x10) | ~$12 | Medium |
| **Magnetometer (compass)** | QMC5883L or LIS3MDL | I2C (0x0D/0x1C) | ~$2-4 | Medium (with GPS) |
| **Gesture (optional)** | APDS-9960 | I2C (0x39) | ~$5 | Low |

### Cost Tiers

| Tier | Components | Total Cost |
|---|---|---|
| **Essential** | LIS2DH12TR + BH1750 + MAX9814 + Battery + TP4056 | **~$12.96** |
| **Recommended** | Essential + AHT20 | **~$13.39** |
| **Explorer** | Recommended + QMC5883L (compass, WiFi/BLE location) | **~$24.96** |
| **Full** | Explorer + APDS-9960 + LIS3MDL upgrade | **~$33.96** |

*Costs are for breakout boards from AliExpress/generic sources. Adafruit/SparkFun branded boards typically 2-3x more.*

### I2C Bus Layout (No Address Conflicts)

```
Pico W I2C0 (GP4=SDA, GP5=SCL)
  ├── 0x10  PA1010D (GPS)
  ├── 0x23  BH1750  (Light)
  ├── 0x39  APDS-9960 (Gesture)
  ├── 0x6A  LSM6DSO (Accel/Gyro/Pedometer)
  └── 0x38  AHT20   (Temp/Humidity)

ADC (GP26): MAX9814 microphone analog output
```

All sensors on a single I2C bus with no address conflicts. Pico W's I2C1 available as backup if needed.

### Power Budget

| Component | Active (mA) | Sleep (mA) |
|---|---|---|
| Pico W (WiFi off) | 30 | 0.8 |
| E-ink display | 5 (refresh) / 0 (static) | 0 |
| LIS2DH12TR (pedometer mode) | 0.02 | 0.003 |
| BH1750 | 0.12 | 0.01 |
| MAX9814 | 3.0 | 0 (power gate) |
| AHT20 | 0.023 | 0.00025 |
| **Total** | **~38 mA** | **~0.8 mA** |

**Battery life estimates (1000mAh LiPo)**:
- Active use: ~26 hours
- Intermittent use (50% active): ~40 hours
- Sleep mode (night): ~50+ days standby

### Alternative Accelerometer Options

If LSM6DSO is unavailable or too expensive:

| Part | Cost | Built-in Pedometer? | Notes |
|---|---|---|---|
| **BMA400** | ~$4 | Yes | Ultra-low power (14uA with step counter). Best power efficiency. |
| **LIS2DH12TR** | ~$0.46 | Yes (built-in pedometer) | Cheapest. Built-in step counter, LGA-12 (2x2mm), ultra-low power. **Selected for Dilder BOM.** |
| **LIS3DH** | ~$3 | No | Good low-power option. Hardware high-pass filter helps. |
| **ADXL345** | ~$3 | No | Activity/inactivity detection assists pedometer logic. |

**Recommendation**: LIS2DH12TR selected for Dilder — $0.46, built-in pedometer, ultra-low power, smallest footprint (LGA-12, 2x2mm). LSM6DSO or BMA400 are alternatives if 6-axis IMU is needed later.

### Software Step Counting Algorithm (for chips without built-in pedometer)

```
1. Sample accelerometer at 25-50Hz
2. Compute magnitude: mag = sqrt(ax² + ay² + az²)
3. Apply low-pass filter (moving average, ~10 samples)
4. Apply high-pass filter to remove gravity bias
5. Detect zero-crossings or peaks above threshold
6. Debounce: reject steps closer than 200ms apart
7. Timeout: reset if no step within 2 seconds
```

The Pico W's RP2040 at 133MHz handles this easily in C.

---

## 16. Research: Tamagotchi & Virtual Pet Precedents

### Original Tamagotchi (1996-1997)

The Tamagotchi established the virtual pet genre with these core mechanics:

**Stats**: Hunger (4 hearts), Happiness (4 hearts), Discipline (0-100%), Weight, Age.

**Stat Decay Rates** (character-specific, from community reverse-engineering):
- Baby (Babytchi): Hunger -1 heart every **3 minutes**, Happiness -1 every **4 minutes** — extremely needy
- Child (Marutchi): Hunger -1 every **50 min**, Happiness -1 every **60 min**
- Teen (Tamatchi): Hunger -1 every **75 min**, Happiness -1 every **85 min**
- Adult/Elderly: Decay accelerates, capping at -1 Hunger every **6 min**, -1 Happy every **7 min**

**Care Mechanics**:
- Feed a meal: +1 Hunger heart, +1 weight
- Feed a snack: +1 Happiness heart, +2 weight
- Play a game: Win 3/5 rounds → +1 Happy heart, -1 weight
- Discipline: +25% per correct scolding (4 windows per stage)
- Care mistake: Accrued when a need goes unmet for **15 minutes**. Irreversible. Shortens lifespan.
- Poop: Must be cleaned. 4+ accumulated → sickness.

**Life Stages & Timing**:
- Egg: 5 minutes
- Baby: 65 minutes (60 awake + 5 asleep). Nothing affects evolution.
- Child: Evolves at age 3 (~3 real days). Care mistakes start mattering.
- Teen: Evolves at age 6.
- Adult: Lives until death from age or neglect.
- Age increments: 1 year per real day (increments on wake).

**Evolution System** — Fully deterministic, no randomization:
- Child → Teen: 0-1 care mistakes → good teen; 2+ → bad teen
- Teen → Adult: Discipline determines tier (100% = best, 50% or less = worst)
- Secret character (Oyajitchi): Requires 0% discipline through multiple stages
- Each stage has exactly 4 misbehavior windows for discipline

**Death**: Occurs from old age, accumulated care mistakes (shortens lifespan), prolonged zero-stat neglect (~12+ hours with both Hunger and Happiness at 0), untreated sickness, or overfeeding baby (5+ snacks).

**Key Insight**: The deterministic evolution system gives players agency — they can deliberately aim for specific outcomes. Bad care isn't random bad luck; it's knowable cause and effect. This is more satisfying than random chance.

**References**:
- Thaao's Tamas P1 Care Guide: https://thaao.net/tama/p1/
- "I solved the original 1997 Tamagotchi": https://hive.blog/hive-140217/@mustachepod/i-solved-the-original-1997-tamagotchi
- tama96 Documentation: https://www.tama96.com/docs/

### Modern Tamagotchi (ON, Pix, Uni)

Key innovations in modern versions:
- **Gene Mixing** (m!x, ON): Marriage between two Tamagotchis produces offspring inheriting traits from both parents — body parts, eye shape, color. Creates billions of possible combinations.
- **Tamagotchi Uni**: Wi-Fi connectivity, downloadable content, online meeting spaces (Tamaverse), personality mechanics.
- **Social connectivity**: Marriage requires two physical devices to connect, creating a social layer.

### Digimon Virtual Pets

Key differences from Tamagotchi:
- **Battle-focused**: Two devices connect via conductors for battles. This was the core differentiator.
- **Evolution requires battles**: Ultimate level requires **15+ battles** at Rookie and Champion, winning **~60%**.
- **Less needy**: Could be left alone more than Tamagotchi. The care loop is lighter.
- **Win/loss ratio directly influences evolution paths** — combat skill matters.

**Relevance to Dilder**: The activity-based evolution (battles → evolution) is analogous to our step-based and exploration-based evolution. Physical effort should unlock growth.

### Neopets

- Browser-based virtual pet world. Peak: **35 million MAU** (2005), 150 million total registrations.
- **Player-driven economy**: Full marketplace with fluctuating item values, creating metagame depth.
- **Variety is key**: Hundreds of mini-games, customization options, events. Different player types find different things engaging.
- **FOMO-driven**: Limited-time events, exclusive releases, avatar hunts create urgency.

**Relevance to Dilder**: Collection mechanics and economic depth create long-term engagement. Even without multiplayer, the breadth of unlockables and achievements serves a similar function.

### Pou

- Mobile virtual pet with 4 status bars: hunger, health, happiness, sleep.
- **No permanent death**: Neglect makes Pou unwell but recovery is always possible.
- **Mini-games earn currency** for customization.
- **Key insight**: Removing permanent consequences reduces anxiety but maintains engagement through cosmetic goals and daily habits.

### My Talking Tom

- **Talk-back mechanic**: Records user speech, plays back in modified voice. Simple but extremely engaging — became franchise signature.
- **Growth stages**: Baby kitten → full-grown tomcat.
- **Extensive monetization** through cosmetics and virtual currency.

**Relevance to Dilder**: The mic echo/response concept could be adapted — Dilder "reacting" to voice input creates a sense of conversation even without speech recognition.

### Nintendogs (DS, 2005)

- **Touch-based petting**: DS stylus creates hand icon. Lifelike reactions depend on where/how you touch.
- **Voice recognition**: Microphone teaches dogs their name and tricks ("sit," "roll over"). Adapted to multiple languages and accents.
- **23.96 million copies sold** — demonstrated massive market for interactive pet simulation.

**Relevance to Dilder**: The physical tap interaction (via accelerometer) mirrors Nintendogs' touch concept. The voice element validates mic input as engaging.

### Creatures (1996 Artificial Life Game)

The most technically sophisticated virtual pet:
- **Neural network brain**: 952 neurons in 9 lobes, ~5,000 connections
- **Artificial biochemistry**: Simulated metabolism and hormones interact with neural network
- **Genuine learning**: Creatures learn through Hebbian reinforcement — reward/punishment chemicals shape behavior
- **Genetic DNA**: Sexual reproduction passes traits to offspring, enabling genuine evolution

**Relevance to Dilder**: While we can't replicate neural networks on a Pico W, the principle of **emergent behavior from simple rules** is key. Our stat-to-emotion mapping should produce surprising combinations.

### Finch (Modern Self-Care App)

- Virtual pet bird that grows based on completing daily wellness tasks.
- **Positive reinforcement only**: No penalties, no shame, no death.
- **Reframes obligation as nurturing**: Users complete self-care tasks "for their bird," not for themselves.
- **2.34 million downloads in 90 days**.

**Relevance to Dilder**: The real-world activity → pet benefit pipeline is exactly our model. Steps and exploration feed Dilder just as Finch ties self-care to pet growth. The "nurturing reframe" is powerful.

---

## 17. Research: Real-World Activity Games

### Pokemon GO

- **Adventure Sync**: Tracks walking distance via phone pedometer even when app is closed. Connects to Apple Health / Google Fit.
- **Buddy system**: Walking earns candy for a selected Pokemon. Distance tiers: 1, 3, 5, or 20 km per candy.
- **Egg hatching**: 2/5/7/10/12 km walking required. Speed cap of **~10.5 km/h** prevents driving.
- **Weekly rewards**: 5km = Poke Balls, 25km = Great Balls, 50km = Ultra Balls + rare items.
- **Over $6 billion lifetime revenue** — validates activity integration commercially.

**Relevance to Dilder**: The tiered step reward system and weekly milestones directly inform our step counter design. The speed cap concept could prevent "cheat shaking" of the accelerometer.

### Pikmin Bloom

- **Passive walking game**: Designed as background activity, not attention-demanding.
- **Flower planting**: Walking plants flowers on a real-world map, leaving colorful trails.
- **Decor Pikmin**: At high friendship, Pikmin get costumes based on **where their seedling was found** (restaurant → chef hat, park → clover). Encourages visiting diverse location types.
- **Lifelog**: Daily summary of where you walked. Weekly comparison.

**Relevance to Dilder**: The location-type-based cosmetics directly inspire our "location-themed unlocks." The ambient, background nature of engagement matches our always-on e-ink device.

### Walkr

- **Steps = spaceship fuel**: Phone pedometer converts daily steps into energy for galactic exploration.
- **100+ planets** to discover, each with a mini-ecosystem.
- **Co-pilots**: Friends provide extra fuel.

**Relevance to Dilder**: Shows that steps as a universal currency for progression works. The "fuel" abstraction is elegant — our equivalent is "Dilder's vitality."

---

## 18. Research: Voice Interaction in Games

### Hey You, Pikachu! (N64, 1998)

- Used VRU peripheral with **200-256 recognizable words**.
- Voice commands for simple actions: identify objects, direct Pikachu.
- **Frustration**: Unreliable recognition. Unclear if failures were tech limitations or intentional game mechanic (Pikachu being disobedient).
- **Lesson**: Voice input must have clear, forgiving interaction models. Ambiguity between "not recognized" and "pet chose to ignore" can be a feature, not a bug.

### Seaman (Dreamcast, 1999-2000)

- Fish-human hybrid that **speaks, asks personal questions, remembers answers**, evolves based on verbal interactions.
- Full conversational voice input via Dreamcast microphone.
- Creature's personality shaped by player's verbal interactions over time.
- Narrated by Leonard Nimoy.
- **Lesson**: Conversational depth creates deep attachment. Even primitive voice interaction feels magical when the pet seems to "listen."

### Design Patterns for Voice in Games (Academic Research)

A survey of 449 videogames using voice identified these categories:
- **Sound detection**: Any mic input triggers events (blowing, volume level)
- **Speech recognition**: Specific words mapped to commands
- **Voice as emotional input**: Tone/volume affects game state
- **Silence as mechanic**: Requiring players to stay quiet

**Relevance to Dilder**: On Pico W, we're limited to the first and third categories (sound detection, volume-as-emotion). This is actually sufficient for compelling interaction:
- Volume level → mood influence
- Duration of sound → attention metric
- Silence → loneliness metric
- Sudden spike → startle/discipline mechanic
- Rhythmic pattern → possible singing/music detection

---

## 19. Implementation Challenges

### Hardware Challenges

| Challenge | Severity | Mitigation |
|---|---|---|
| **I2C bus reliability with many devices** | Medium | Keep wires short (<15cm), use pull-up resistors (4.7kΩ), scan bus on boot |
| **ADC noise from mic** | Medium | Add hardware LP filter (RC circuit) before ADC pin, software averaging |
| **Battery life optimization** | High | Aggressive sleep modes, sensor duty cycling, e-ink (no backlight drain) |
| **GPS power drain** | High | Defer to WiFi geolocation; GPS only on Phase 5 with larger battery |
| **Sensor wiring in small enclosure** | Medium | Use Qwiic/STEMMA QT connectors for I2C daisy chain; design PCB in Phase 5 |
| **Pico W RAM limits (264KB)** | Medium | Keep stat arrays compact, don't buffer full audio, stream sensor data |
| **E-ink refresh rate** | Low | Already handled — partial refresh works for 4s frame cycle |

### Software Challenges

| Challenge | Severity | Mitigation |
|---|---|---|
| **State machine complexity** | High | Hierarchical FSM — top level (life stage), mid (activity state), low (emotion) |
| **Persistent storage** | High | Pico W flash wear leveling for stats/progress. Save every 5 min, not every tick. Use EEPROM-like library or flash filesystem (LittleFS). |
| **Step counting accuracy** | Medium | Use LIS2DH12TR built-in pedometer (hardware). If software: tune threshold per user weight/gait. |
| **WiFi geolocation latency** | Medium | Cache last-known location. Only re-resolve when WiFi environment changes significantly. |
| **Emotion blending algorithm** | Medium | Weight-based priority system with hysteresis (don't flip-flop between emotions). Minimum dwell time per emotion (30 seconds). |
| **Dialogue management** | Medium | Indexed quote arrays per mood/stage. Random selection with recency filter (don't repeat within last 10). |
| **Time tracking without NTP** | Low | RTC keeps time between reboots. Drift ~2 min/day acceptable. Sync via WiFi NTP when available. |
| **OTA firmware updates** | High (future) | Phase 5 — Pi Zero WH can pull updates from GitHub. Pico W OTA is possible but complex (dual-bank flash). |

### Design Challenges

| Challenge | Severity | Mitigation |
|---|---|---|
| **Balancing punishment vs reward** | High | Default to Finch model (positive reinforcement). Neglect causes visible sadness but quick recovery. Death only from extreme sustained neglect (3+ days). |
| **Preventing cheat-shaking for steps** | Medium | Step detection algorithm with gait-pattern validation. Reject frequencies >4Hz (natural walking is 1.5-2.5Hz). |
| **Keeping dialogue fresh** | High | 800+ quotes already exist. Expand per life stage. Context-sensitive triggers prevent repetition. |
| **Evolution feeling meaningful** | High | Clear visual differences between adult forms. Unique dialogue sets per form. The journey matters — evolution is the payoff for weeks of care. |
| **Sensor data overwhelming the game loop** | Medium | Sample sensors on different tick intervals: sound (every 100ms), light (every 5s), temp (every 60s), steps (hardware counter, read every 10s). |
| **Scope creep** | High | This document is intentionally comprehensive. Implementation must be phased ruthlessly. See Phase Rollout Plan below. |

---

## 20. Phased Rollout Plan

### Phase 3A: Core Game Loop (Immediate Priority)

**Goal**: Basic Tamagotchi functionality with stats and care actions.

| Task | Dependency |
|---|---|
| Implement stat system (hunger, happiness, energy, hygiene, health) | None |
| Implement stat decay with configurable rates | Stat system |
| Implement care actions via serial/GPIO buttons (feed, interact, clean, sleep) | Input system (Phase 2) |
| Implement emotion resolution from stats | Stat system + existing emotion renderer |
| Implement basic dialogue (mood-matched quotes already exist) | Emotion system |
| Implement day/night cycle from RTC | RTC (exists) |
| Persistent stat storage to flash | LittleFS or flash write |

### Phase 3B: Sensor Integration

**Goal**: Physical interaction through hardware sensors.

| Task | Hardware Needed |
|---|---|
| Integrate BH1750 light sensor → sleep/wake mechanics | BH1750 (~$2) |
| Integrate MAX9814 mic → volume-based reactions | MAX9814 (~$4) |
| Integrate AHT20 temp/humidity → comfort mechanics | AHT20 (~$0.43) |

### Phase 3C: Activity Tracking

**Goal**: Steps and location affect Dilder.

| Task | Hardware Needed |
|---|---|
| Integrate LIS2DH12TR step counter | LIS2DH12TR (~$0.46, on-board) |
| Implement step milestone rewards | LIS2DH12TR |
| Implement WiFi geolocation for location awareness | Built-in WiFi |
| Implement home detection and exploration tracking | WiFi |

### Phase 4: Progression & Life Stages

**Goal**: Long-term engagement systems.

| Task | Dependency |
|---|---|
| Implement life stage system (egg → elder) | Phase 3A |
| Implement evolution branching | Stat accumulation from Phase 3 |
| Implement bond level / XP system | Interaction tracking |
| Implement achievement system | All stat tracking |
| Implement decor/cosmetic unlocks | Achievement system |
| Implement dialogue per life stage | Life stage system |
| Implement rebirth system | Elder stage |

### Phase 4B: Treasure Hunts & Step Targets

**Goal**: GPS-based treasure hunting and structured step reward system.

| Task | Hardware Needed |
|---|---|
| Integrate PA1010D GPS module | PA1010D (~$12) |
| Integrate QMC5883L/LIS3MDL magnetometer for compass | QMC5883L (~$2) |
| Implement compass display with bearing calculation | GPS + Magnetometer |
| Implement treasure spawn system with rarity tiers | GPS + flash storage |
| Implement proximity detection and distance display | GPS |
| Implement daily/weekly/monthly step targets | LSM6DSO (from Phase 3C) |
| Implement streak system with grace days | Step tracking |
| Implement gift box animation sequence | Display renderer |
| Implement step target UI (progress bars, summaries) | Display renderer |

### Phase 5: Pi Zero WH Upgrade

**Goal**: Advanced features requiring more compute.

| Task | Hardware |
|---|---|
| Speech recognition (cloud API or local keyword spotting) | Pi Zero WH + mic |
| Weather API integration | Pi Zero WH + internet |
| OTA firmware updates | Pi Zero WH |
| Enhanced location tracking (optional) | WiFi fingerprinting + BLE scanning (built-in) |
| Web dashboard / companion app | Pi Zero WH + WiFi |
| Social features (multiple Dilders interacting) | WiFi |

---

## 21. References

### Tamagotchi & Virtual Pet Research
- Thaao's Tamas P1 Care Guide — https://thaao.net/tama/p1/
- "I solved the original 1997 Tamagotchi" — https://hive.blog/hive-140217/@mustachepod/i-solved-the-original-1997-tamagotchi
- tama96 Documentation — https://www.tama96.com/docs/
- Tamagotchi Wiki (Care, Health Meter, Marriage, Genetics) — https://tamagotchi.fandom.com/
- Digimon V-Pet Guide — https://digivicemon.com/digimon-v-pet-guide-version-1/
- Creatures AI Analysis — https://www.alanzucconi.com/2020/07/27/the-ai-of-creatures/
- Neopets Engagement Design — https://www.deanagalbraith.com/post/designing-for-engagement-how-neopets-captivated-audiences-across-generations
- Pet Companion Design in Gamification (Yu-kai Chou) — https://yukaichou.com/advanced-gamification/the-pet-companion-design-in-gamification/

### Real-World Activity Integration
- Pokemon GO Adventure Sync — https://niantic.helpshift.com/hc/en/6-pokemon-go/faq/3265-adventure-sync/
- Pikmin Bloom — https://en.wikipedia.org/wiki/Pikmin_Bloom
- Walkr — https://sparkful.app/walkr
- Finch Self-Care App — https://apps.apple.com/us/app/finch-self-care-pet/id1528595748

### Voice Interaction
- 19 Games With Voice Commands — https://www.thegamer.com/games-with-voice-commands-speech-recognition/
- Design Patterns for Voice Interaction (ACM) — https://dl.acm.org/doi/10.1145/3242671.3242712
- Technology Behind Nintendogs — https://www.thetechedvocate.org/the-technology-behind-nintendogs-pushing-the-nintendo-ds-to-its-limits/

### Hardware Datasheets
- Raspberry Pi Pico W — https://datasheets.raspberrypi.com/picow/pico-w-datasheet.pdf
- RP2040 — https://datasheets.raspberrypi.com/rp2040/rp2040-datasheet.pdf
- LSM6DSO — https://www.st.com/en/mems-and-sensors/lsm6dso.html
- BH1750 — https://www.mouser.com/datasheet/2/348/bh1750fvi-e-186247.pdf
- MAX9814 — https://www.adafruit.com/product/1713
- AHT20 — https://www.adafruit.com/product/4566
- PA1010D GPS — https://www.adafruit.com/product/4415
- APDS-9960 — https://www.adafruit.com/product/3595

### Game Design & Retention
- UX Principles for Pet Care Systems — https://www.zigpoll.com/content/what-key-ux-principles-should-i-prioritize-when-designing-an-ingame-pet-care-system-to-maximize-player-engagement-and-satisfaction
- Game Retention Strategies — https://featureupvote.com/blog/game-retention/

---

*Document version: 1.0 — Created 2026-04-13*
*This is a living document. Update as implementation progresses and design decisions are made.*

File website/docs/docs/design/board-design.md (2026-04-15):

# Board Design v0.4

> Custom PCB design for the Dilder — 30x70mm, 4-layer, ESP32-S3, 30 components, ~$5.18/board BOM cost.

---

## Board Overview

| Parameter | Value |
|---|---|
| Board size | 30 x 70 mm |
| Layers | 4 (F.Cu, In1.Cu, In2.Cu, B.Cu) |
| Thickness | 1.6 mm |
| Components | 30 unique (34 placed) |
| Nets | 34 |
| BOM cost | ~$5.18/board |
| Target fab | JLCPCB (SMT assembly) |

```
Board layout (30 x 70 mm, top view):
+------------------------------+ y=0
|  ~~~ Antenna overhang ~~~    | Zone A
|                              |
|    +------------------+      |
|    |   ESP32-S3-WROOM |      |
|    |    -1-N16R8      |      | Zone B
|    |                  |      |
|    +------------------+      |
|  [AMS1117]  [TP4056]        |
|  [DW01A] [FS8205A] [Batt]   | Zone C
|                              |
| [Accel][Temp][Light][ePaper]  |
| [BOOT] [RESET]               | Zone D
|                              |
|     [5-Way Joystick]         | Zone E
|                              |
|      [USB-C]                 | Zone F
+------------------------------+ y=70
```

---
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

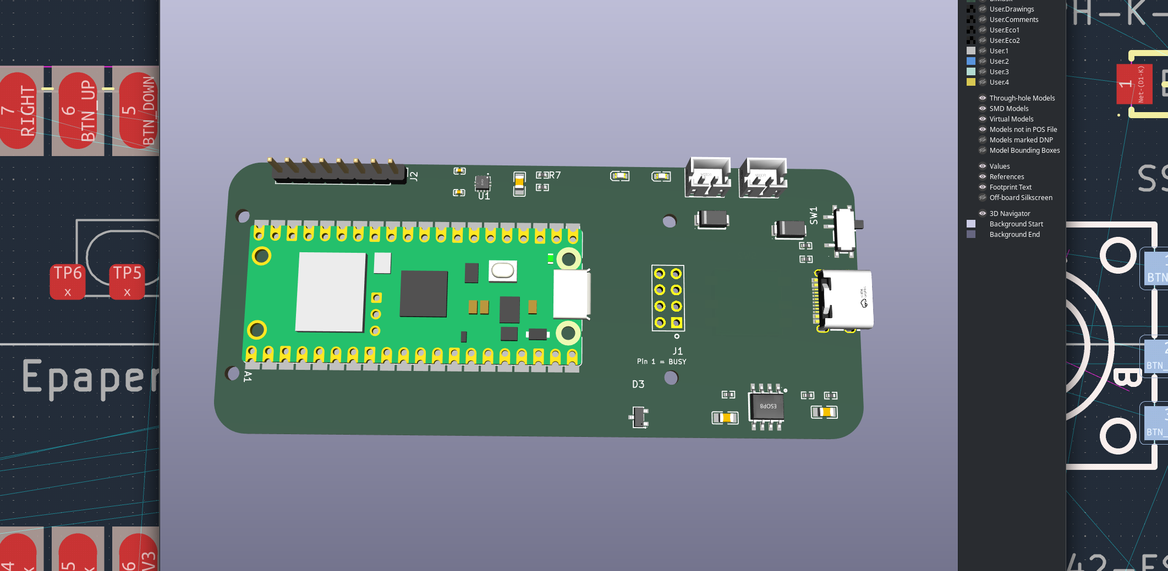
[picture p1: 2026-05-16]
website/docs/assets/images/hardware/pcb/full-board-rev1/full-board-rev1-3d-top-view.png

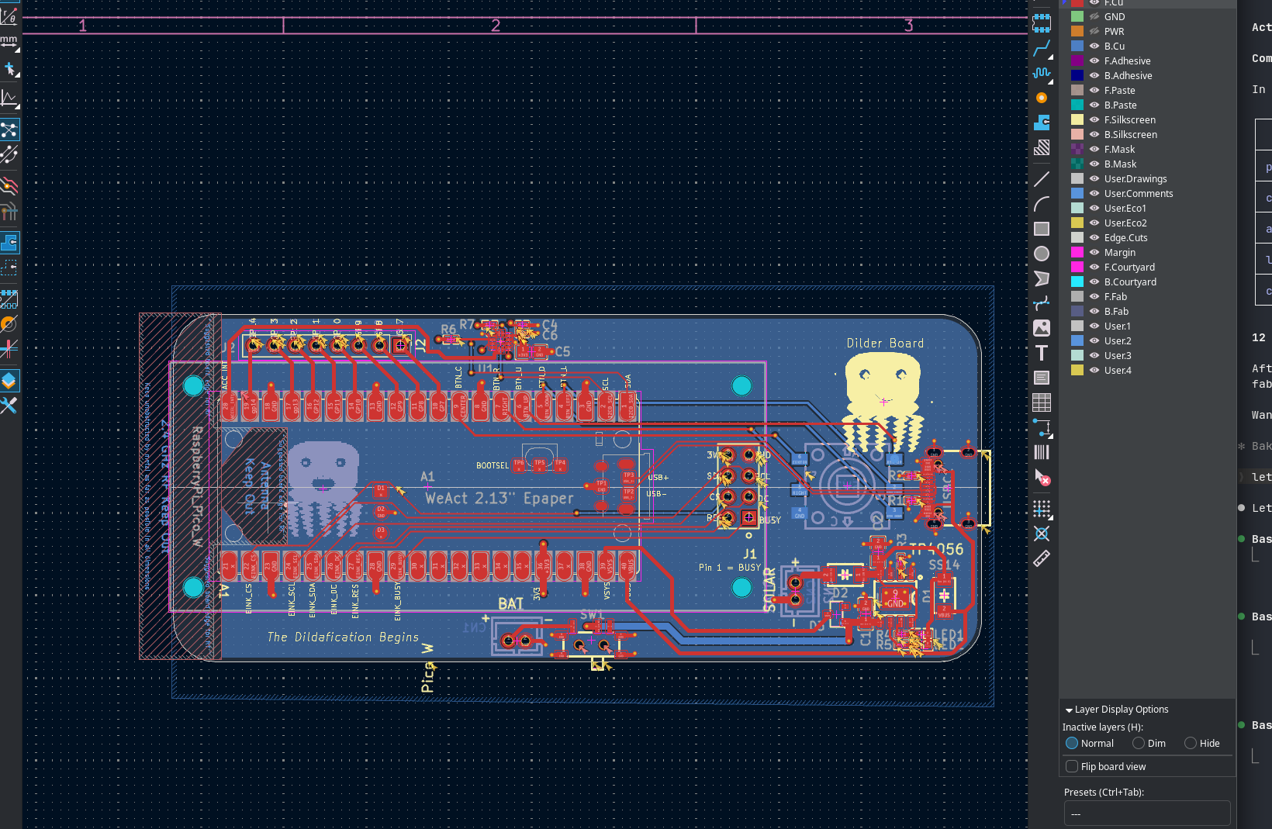
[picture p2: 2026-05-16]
website/docs/assets/images/hardware/pcb/full-board-rev1/full-board-rev1-pcb-layout-traces-routed.png

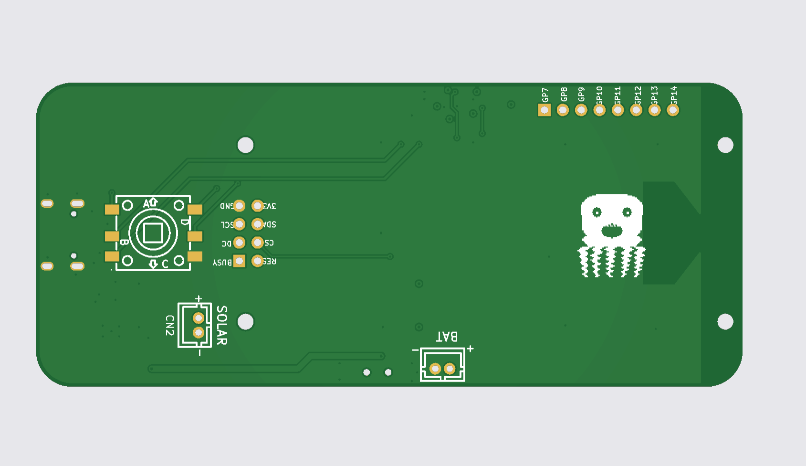
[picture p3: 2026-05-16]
website/docs/assets/images/hardware/pcb/full-board-rev1/full-board-rev1-back-silkscreen-mascot.png

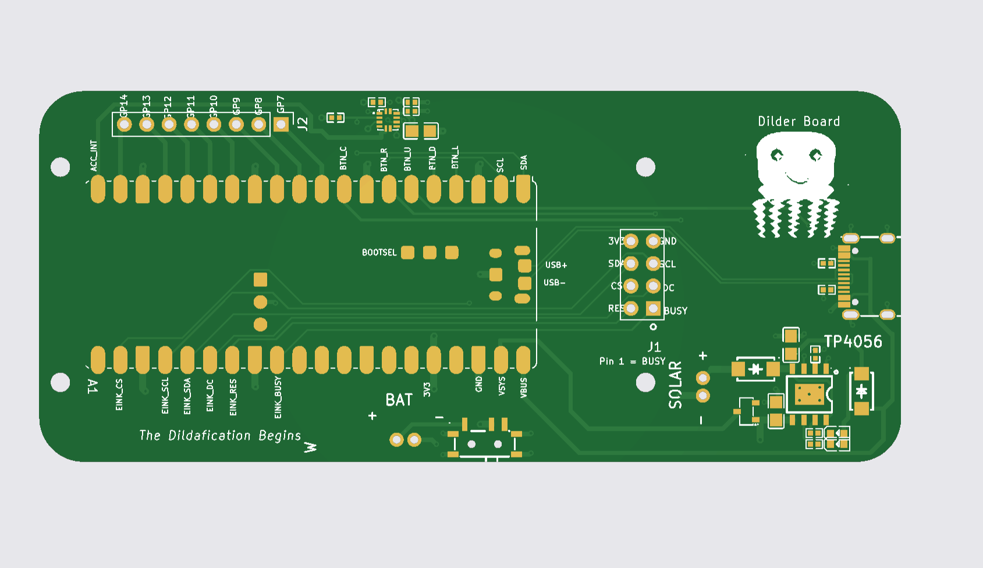
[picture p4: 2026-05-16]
website/docs/assets/images/hardware/pcb/full-board-rev1/full-board-rev1-front-silkscreen-dildafication-begins.png

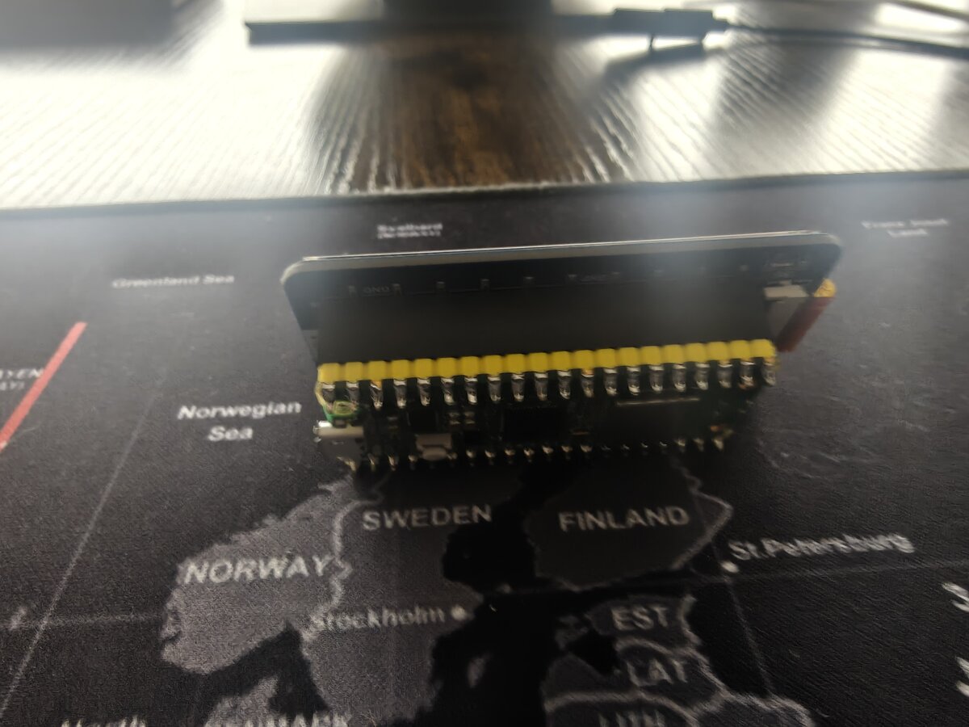
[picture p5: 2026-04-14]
assets/images/hardware/build-session/pico-w-epaper-stacked-rear.jpg

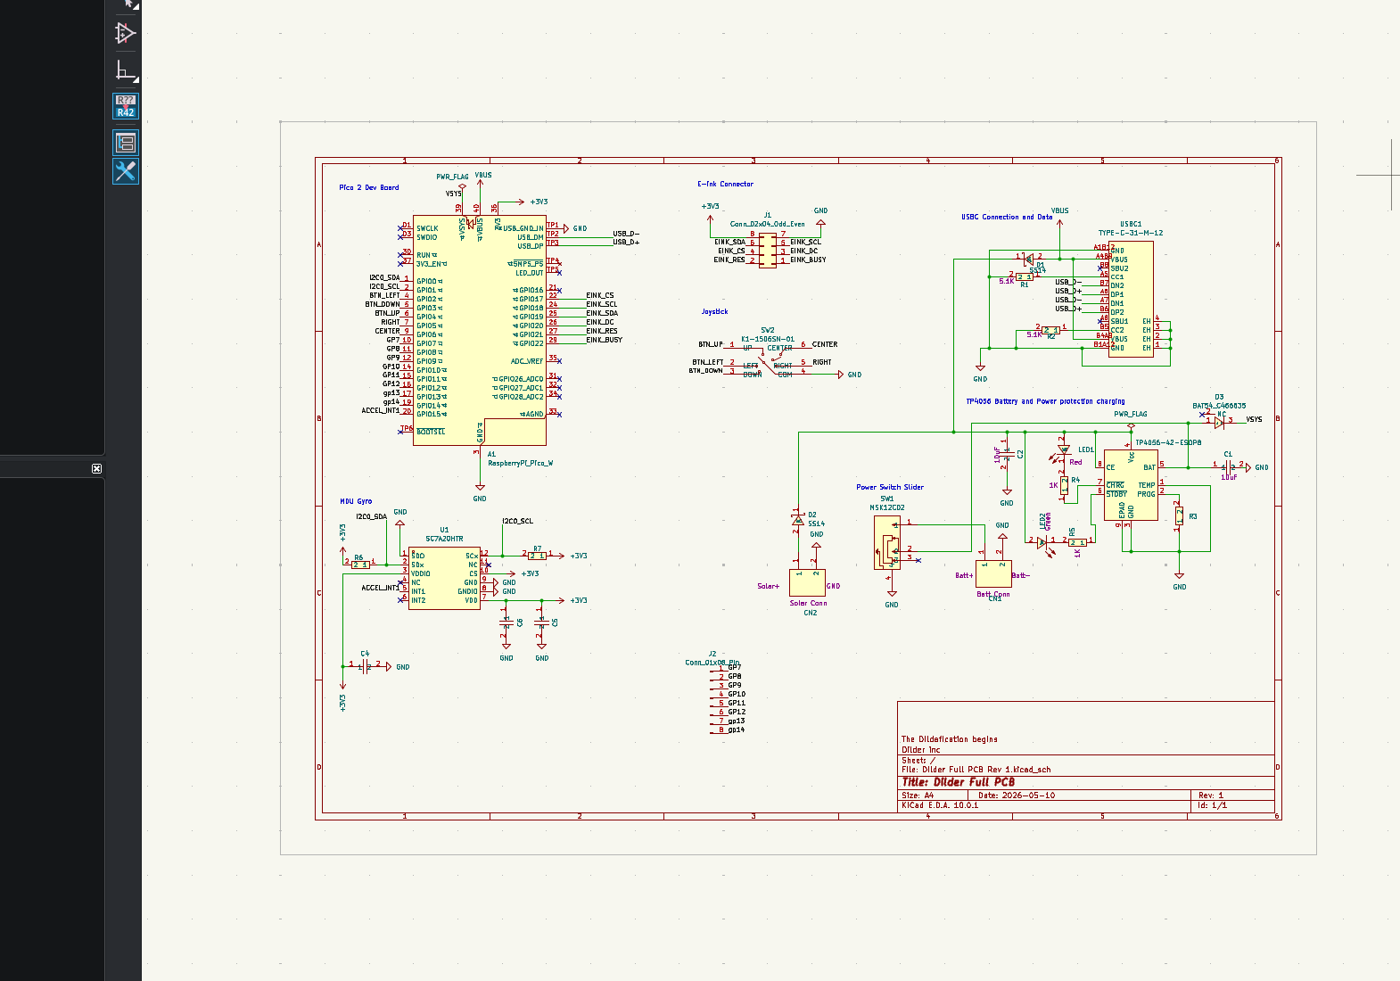
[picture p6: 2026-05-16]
website/docs/assets/images/hardware/pcb/full-board-rev1/full-board-rev1-complete-schematic.png

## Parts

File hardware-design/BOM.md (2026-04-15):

# Dilder PCB v0.3 — Bill of Materials

ESP32-S3-WROOM-1-N16R8 design, 31 components, target fab: JLCPCB

## ICs & Modules

| Ref | Part | Package | LCSC | Qty | ~Cost |
|-----|---|---|---|-----|---|
| U1 | ESP32-S3-WROOM-1-N16R8 | RF Module (18x25.5mm) | C2913196 | 1 | $2.80 |
| U2 | TP4056 (1A LiPo charger) | ESOP-8 | C382139 | 1 | $0.07 |
| U3 | DW01A (battery protection) | SOT-23-6 | C351410 | 1 | $0.05 |
| Q1 | FS8205A (dual MOSFET) | SOT-23-6 | C908265 | 1 | $0.05 |
| U4 | AMS1117-3.3 (3.3V LDO) | SOT-223-3 | C6186 | 1 | $0.05 |
| U6 | LIS2DH12TR (3-axis accelerometer) | LGA-12 2x2mm | C110926 | 1 | $0.46 |
| U7 | AHT20 (temp/humidity sensor) | DFN-6 3x3mm | C2757850 | 1 | $0.43 |
| U8 | BH1750FVI-TR (ambient light sensor) | WSOF-6 3x1.6mm | C78960 | 1 | $0.49 |

## Connectors

| Ref | Part | Package | LCSC | Qty | ~Cost |
|-----|---|---|---|-----|---|
| J1 | USB-C 16-pin receptacle | HRO TYPE-C-31-M-12 | C2765186 | 1 | $0.10 |
| J2 | JST PH 2-pin (battery) | JST_PH_S2B horizontal | C131337 | 1 | $0.03 |
| J3 | 8-pin JST-SH (ePaper) | JST_SH 1mm horizontal | — | 1 | $0.05 |

## Switches & Diodes

| Ref | Part | Package | LCSC | Qty | ~Cost |
|-----|---|---|---|-----|---|
| SW1 | SKRHABE010 (5-way joystick) | Alps SMD | C139794 | 1 | $0.38 |
| D1 | SS34 Schottky diode | SMA | C8678 | 1 | $0.03 |
| D2 | Red LED (charge indicator) | 0402 | C84256 | 1 | $0.01 |
| D3 | Green LED (standby indicator) | 0402 | C72043 | 1 | $0.01 |

## Resistors (all 0402)

| Ref | Value | Purpose | LCSC | Qty | ~Cost |
|-----|---|---|---|-----|---|
| R1 | 1.2k | TP4056 PROG (sets 1A charge) | C25752 | 1 | $0.01 |
| R2 | 1k | Charge LED current limit | C25585 | 1 | $0.01 |
| R3 | 1k | Standby LED current limit | C25585 | 1 | $0.01 |
| R4 | 10k | I2C SDA pull-up | C25744 | 1 | $0.01 |
| R5 | 10k | I2C SCL pull-up | C25744 | 1 | $0.01 |
| R8 | 5.1k | USB CC1 pull-down | — | 1 | $0.01 |
| R9 | 5.1k | USB CC2 pull-down | — | 1 | $0.01 |
| R10 | 10k | ESP32 EN pull-up | C25744 | 1 | $0.01 |

## Capacitors (all 0402)

| Ref | Value | Purpose | LCSC | Qty | ~Cost |
|-----|---|---|---|-----|---|
| C3 | 100nF | ESP32 decoupling | C14663 | 1 | $0.01 |
| C4 | 10uF | ESP32 bulk bypass | C19702 | 1 | $0.01 |
| C5 | 10uF | LDO input | C19702 | 1 | $0.01 |
| C6 | 10uF | LDO output | C19702 | 1 | $0.01 |
| C7 | 100nF | IMU VDD decoupling | C14663 | 1 | $0.01 |
| C9 | 100nF | IMU REGOUT bypass | C14663 | 1 | $0.01 |
| C10 | 100nF | AHT20 decoupling | C14663 | 1 | $0.01 |
| C11 | 100nF | BH1750 decoupling | C14663 | 1 | $0.01 |

## Cost Summary

| Category | Cost/board |
|---|---|
| Components (total) | ~$5.12 |
| PCB fabrication (5 boards) | ~$2.00 |
| SMT assembly (5 boards) | ~$8.00 + parts |
| **Estimated total (5 boards)** | **~$40-55** |

## GPIO Pin Assignment

| GPIO | Function | Interface |
|---|---|---|
| GPIO3 | EPD_DC | SPI (digital) |
| GPIO4 | Joystick UP | Digital in (pull-up) |
| GPIO5 | Joystick DOWN | Digital in (pull-up) |
| GPIO6 | Joystick LEFT | Digital in (pull-up) |
| GPIO7 | Joystick RIGHT | Digital in (pull-up) |
| GPIO8 | Joystick CENTER | Digital in (pull-up) |
| GPIO9 | EPD_CLK (SCK) | SPI |
| GPIO10 | EPD_MOSI | SPI |
| GPIO11 | EPD_RST | Digital out |
| GPIO12 | EPD_BUSY | Digital in |
| GPIO16 | I2C SDA (LIS2DH12TR, AHT20, BH1750) | I2C |
| GPIO17 | I2C SCL (LIS2DH12TR, AHT20, BH1750) | I2C |
| GPIO19 | USB D- | USB-OTG |
| GPIO20 | USB D+ | USB-OTG |
| GPIO46 | EPD_CS | SPI CS |

## Changes from v0.2 (RP2040)

Removed:
- RP2040 bare MCU (replaced by ESP32-S3 module)
- W25Q16JV external flash (16MB integrated in module)
- 12MHz crystal + 2x 15pF load caps (integrated in module)
- 2x 27R USB series resistors (ESP32-S3 native USB-OTG)
- ATGM336H GPS module + decoupling cap (dropped — using WiFi fingerprinting + BLE scanning)

Added:
- ESP32-S3-WROOM-1-N16R8 module (WiFi + BLE 5.0, 16MB flash, 8MB PSRAM)

Net component count: 31 → 22 unique parts (simpler BOM, easier assembly)

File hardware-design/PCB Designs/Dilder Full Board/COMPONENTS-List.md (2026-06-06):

Good Display 2.13 E-ink display
    2.13 inch 1.5s Fast Refresh 250x122 Raspberry Pi EPD supports Electronic Epaper price Tag GDEY0213B74

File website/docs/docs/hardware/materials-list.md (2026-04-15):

# Materials List

Components for both the **custom PCB** (production) and the **breadboard prototype** (Phase 1 legacy).

---

## Custom PCB — ESP32-S3 (Production)

The production Dilder runs on a custom 45x80mm 4-layer PCB. All 29 components are surface-mount, assembled by JLCPCB. Total BOM cost: ~$5.10/board.

| Ref | Part | LCSC | ~Cost |
|-----|---|---|---|
| U1 | ESP32-S3-WROOM-1-N16R8 (MCU) | C2913196 | $2.80 |
| U2 | TP4056 (LiPo charger) | C382139 | $0.07 |
| U3 | DW01A (battery protection) | C351410 | $0.05 |
| Q1 | FS8205A (dual MOSFET) | C908265 | $0.05 |
| U4 | AMS1117-3.3 (3.3V LDO) | C6186 | $0.05 |
| U5 | LIS2DH12TR (3-axis accelerometer) | C110926 | $0.46 |
| U6 | AHT20 (temp/humidity sensor) | C2757850 | $0.43 |
| U7 | BH1750FVI-TR (ambient light sensor) | C78960 | $0.49 |
| J1 | USB-C 16-pin receptacle | C2765186 | $0.10 |
| J2 | JST PH 2-pin (battery) | C131337 | $0.03 |
| J3 | JST SH 8-pin (e-paper) | — | $0.05 |
| SW1 | SKRHABE010 (5-way joystick) | C139794 | $0.38 |
| D1 | SS34 Schottky diode | C8678 | $0.03 |
| D2, D3 | Red + Green LEDs (0805/0603) | C84256, C72043 | $0.02 |
| R1-R10 | 0402 resistors (1.2k, 1k, 10k, 5.1k) | various | $0.08 |
| C3-C9 | 0402 capacitors (100nF, 10uF) | C14663, C19702 | $0.06 |

Full details: [BOM](../../../hardware-design/BOM.md) | [Parts Sheets](../../../hardware-design/parts-sheets/README.md)

---

## Breadboard Prototype — Pico W (Phase 1 Legacy)

**Phase 1:** Raspberry Pi Pico W with MicroPython. Cheap, fast to iterate, instant boot.

**Future (Phase 5):** Raspberry Pi Zero WH with Linux. Upgrade when you need a filesystem, SSH, or more compute.

---

## Essential Components

Order these first. Everything else can wait.

| Item | Est. Cost | Notes |
|---|---|---|
| Raspberry Pi Pico W | ~€6 | RP2040 dual-core, 264KB SRAM, 2MB flash, WiFi + BLE. Micro-USB for power and programming. |
| Waveshare Pico-ePaper-2.13 | ~€15 | SSD1680 driver, 250×122px, black/white. Pico-native module — plugs directly onto the Pico W's 40-pin header, or connect via **8-pin breakout header** with jumper wires for breadboard use. |
| Micro-USB cable | ~€2 | Powers the Pico W and provides serial connection to your dev machine. |
| Half-size breadboard | ~€4 | For wiring buttons and display connections. |
| Jumper wire kit (M-F and M-M) | ~€4 | Needed for breadboard wiring (joystick, GPS, HC-SR04). Display can plug directly onto Pico or use F-M wires from its 8-pin breakout header. |
| 6×6mm tactile buttons (pack of 20) | ~€3 | Various stem heights. Snap-on colored caps recommended for identifying buttons. |
| DollaTek 5-Way Navigation Button Module | ~€8.17 (5-pack) | [B07HBPW3DF](https://www.amazon.de/dp/B07HBPW3DF) — 5-direction rocker joystick (Up/Down/Left/Right/Center). GPIO digital input, active LOW. Drop-in replacement for the 5 tactile buttons above. See [Joystick Wiring Guide](joystick-wiring.md). |
| **Subtotal** | **~€42** | |

---

## Useful Extras

Not required to get started, but helpful.

| Item | Est. Cost | Notes |
|---|---|---|
| Pico WH (pre-soldered headers) | ~€7 | Easier breadboard use — no header soldering needed. Either Pico W or WH works. |
| 10kΩ resistor assortment | ~€2 | External pull-ups as backup if internal GPIO pull-ups cause issues. |
| Multimeter | ~€12–20 | Debugging wiring continuity and voltage. Useful throughout the build. |
| Soldering iron + solder | ~€20–40 | Not needed for the test bench, but you'll want it for permanent connections later. |

---

## Battery Power (Phase 6)

Order these when you're ready to move off USB power. See [Hardware Research](https://github.com/rompasaurus/dilder/blob/main/docs/hardware-research.md#battery--power) for the full analysis including battery life estimates and wiring diagrams.

| Item | Est. Cost | Notes |
|---|---|---|
| 3.7V LiPo battery (1000mAh, recommended) | ~€8 | [InnCraft Energy 503450](https://www.amazon.de/dp/B0F88RQX7C) — Molex 51021-0200 1.25mm connector, 51×34×5mm. Wires directly to VSYS — no boost converter needed. Provides ~6.8 days in Tamagotchi mode. See [Battery Wiring Guide](battery-wiring.md). |
| 3.7V LiPo battery (2000mAh, max runtime) | ~€10 | 60×40×7mm. ~13.6 days in Tamagotchi mode. Verify enclosure clearance (7mm thick). |
| TP4056 charging module (budget) | ~€1.50 | USB charging with over-discharge protection. Output wires to VSYS pin. |
| Adafruit PowerBoost 500C (upgrade) | ~€16 | LiPo charger + 5V boost + load sharing (use device while charging). Has low-battery output pin. |

!!! tip "No boost converter needed"
    The Pico W's VSYS pin accepts 1.8–5.5V. A 3.7V LiPo sits right in range — just wire LiPo(+) to VSYS and LiPo(-) to GND. Battery voltage monitoring is built in via GPIO29 (ADC3).

---

## Component Specs Reference

### Raspberry Pi Pico W

| Spec | Value |
|---|---|
| Chip | RP2040 (dual-core ARM Cortex-M0+ @ 133MHz) |
| RAM | 264KB SRAM |
| Flash | 2MB onboard QSPI |
| Wi-Fi | 802.11n 2.4GHz |
| Bluetooth | BLE 5.2 |
| GPIO | 26 multi-function pins |
| USB | Micro-USB 1.1 (power + data) |
| ADC | 3 external channels (12-bit) |
| Dimensions | 51 × 21 × 3.9mm |
| Firmware | C/C++ via Pico SDK |

Full reference: [Pico W Reference](../reference/pico-w.md)

### Waveshare Pico-ePaper-2.13

| Spec | Value |
|---|---|
| Display size | 2.13 inches |
| Resolution | 250 × 122 pixels |
| Active area | 48.55 × 23.71mm |
| Colors | Black and white |
| Driver IC | SSD1680 |
| Interface | SPI1 (4-wire, Mode 0) |
| Power | VSYS (1.8-5.5V, onboard regulator) |
| Form factor | Pico-native — 40-pin female header plugs directly onto Pico W |
| Full refresh time | ~2 seconds |
| Partial refresh time | ~0.3 seconds |
| Standby current | < 0.01µA |
| Recommended refresh interval | ≥ 180 seconds for full refresh |
| Board dimensions | 65 × 30.2mm |

!!! warning "Version check"
    This guide targets the **V3** revision (SSD1680 driver). Confirm your version by checking the PCB silkscreen on the back of the display board.

Full reference: [Waveshare e-Paper Reference](../reference/waveshare-eink.md)

---

## Where to Buy

| Retailer | Notes |
|---|---|
| [Raspberry Pi official store](https://www.raspberrypi.com/products/raspberry-pi-pico/) | Pico W / Pico WH |
| [Waveshare official store](https://www.waveshare.com) | Best for the e-ink display |
| [Amazon DE / UK](https://www.amazon.de/-/en/gp/product/B07Q5PZMGT) | Original linked e-Paper product |
| [Pimoroni](https://shop.pimoroni.com) | Good UK/EU source for Pico W and accessories |
| [Adafruit](https://www.adafruit.com) | US source, good component quality |
| [AliExpress](https://www.aliexpress.com) | Cheapest for breadboards, buttons, and jumper wire kits |

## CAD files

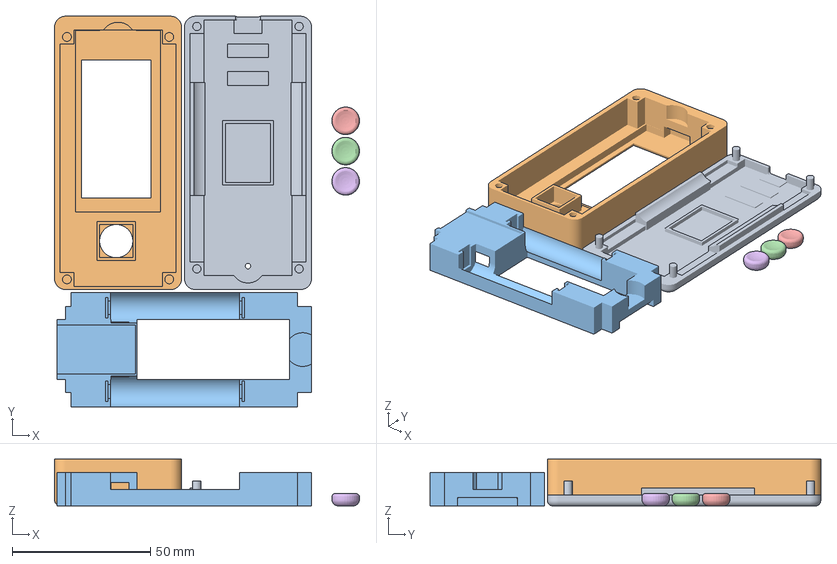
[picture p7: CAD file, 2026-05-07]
hardware-design/freecad-mk2/Dilder_Rev2_Mk2_NoSolar_Buzzer-full print.3mf
110.3 x 141.3 x 17.0 mm

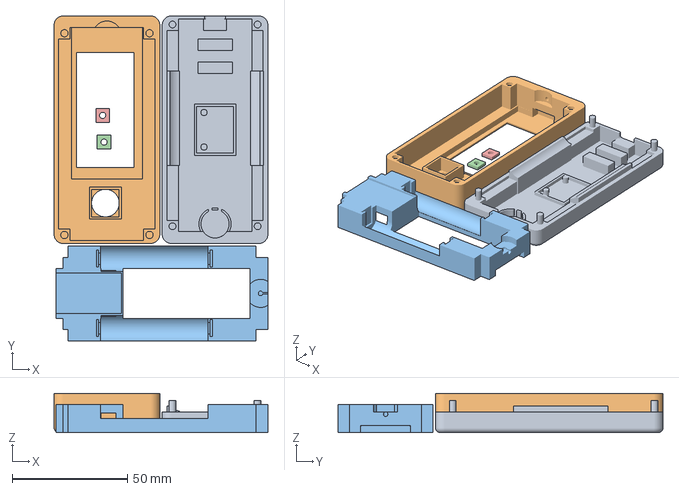
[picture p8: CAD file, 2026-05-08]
hardware-design/freecad-mk2/Dilder_Rev2_Mk2_NoSolar_Buzzer-AAACradle_thiccc.3mf
93.0 x 141.3 x 17.0 mm

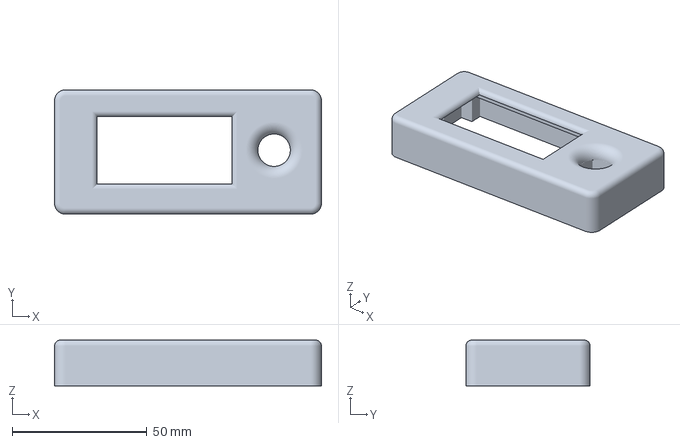
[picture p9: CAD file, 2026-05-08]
hardware-design/freecad-mk2/Dilder_Rev2_Mk2_NoSolar_Buzzer-TopCover_thicccc.3mf
98.9 x 46.0 x 17.0 mm

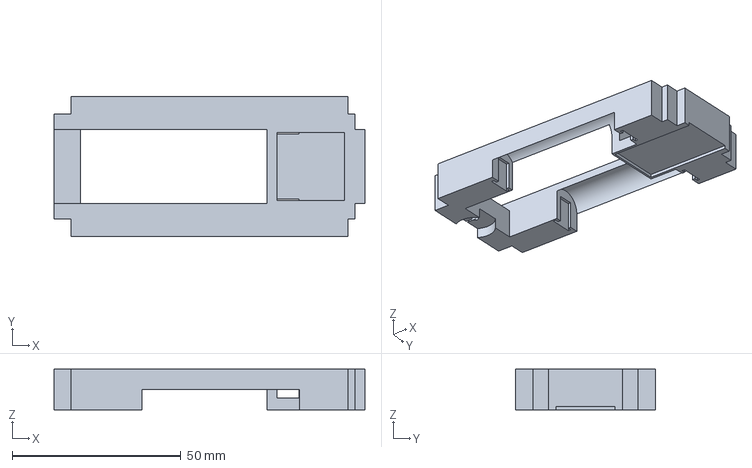
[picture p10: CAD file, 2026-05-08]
hardware-design/freecad-mk2/Dilder_Rev2_Mk2_NoSolar_Buzzer-AAACradle.3mf
92.1 x 41.4 x 12.1 mm

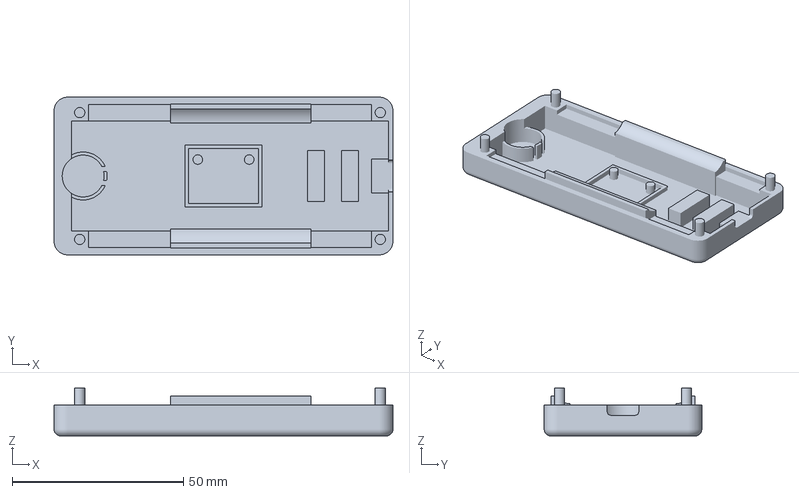
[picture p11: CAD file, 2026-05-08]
hardware-design/freecad-mk2/Dilder_Rev2_Mk2_NoSolar_Buzzer-BasePlate.3mf
98.9 x 46.0 x 14.0 mm

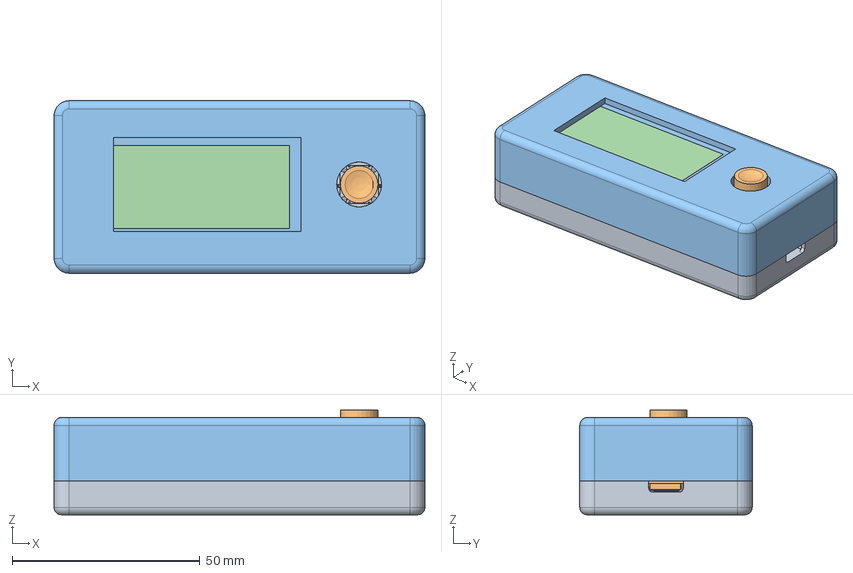
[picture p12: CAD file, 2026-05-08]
hardware-design/freecad-mk2/Dilder_Rev2_Mk2_NoSolar_Buzzer.FCStd
98.9 x 46.0 x 27.9 mm
BasePlate
AAACradle
TopCover
Pico2W_Board
Pico2W_Headers
AAA_Battery_1
AAA_Battery_1_PosTerm
AAA_Battery_2
AAA_Battery_2_PosTerm
TP4056_Module
EInkDisplay_Module
EInkDisplay_Panel
BatteryClips_Positive
BatteryClips_Negative
BatteryWiring_Positive
BatteryWiring_Negative
JoystickPCB
Thumbpiece
IMU_Module
IMUPegWasher_MX
IMUPegWasher_PX
ActiveBuzzer_Body
ActiveBuzzer_WirePlus
ActiveBuzzer_WireMinus

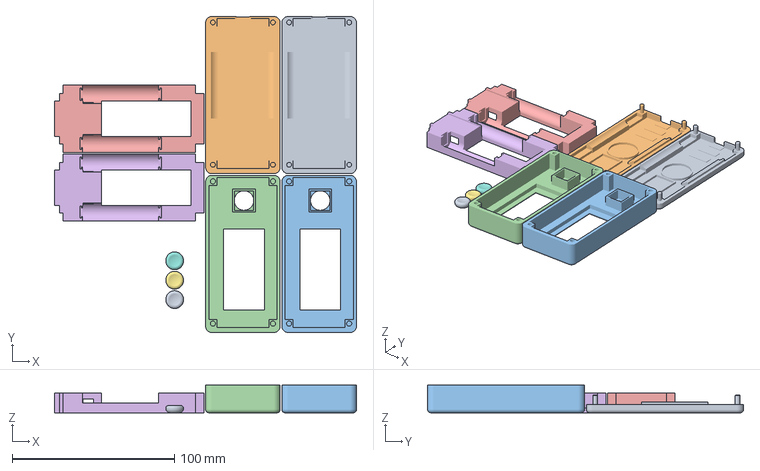
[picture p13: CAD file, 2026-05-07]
hardware-design/freecad-mk2/loerclearer batter top and bottom.3mf
186.1 x 194.8 x 17.0 mm

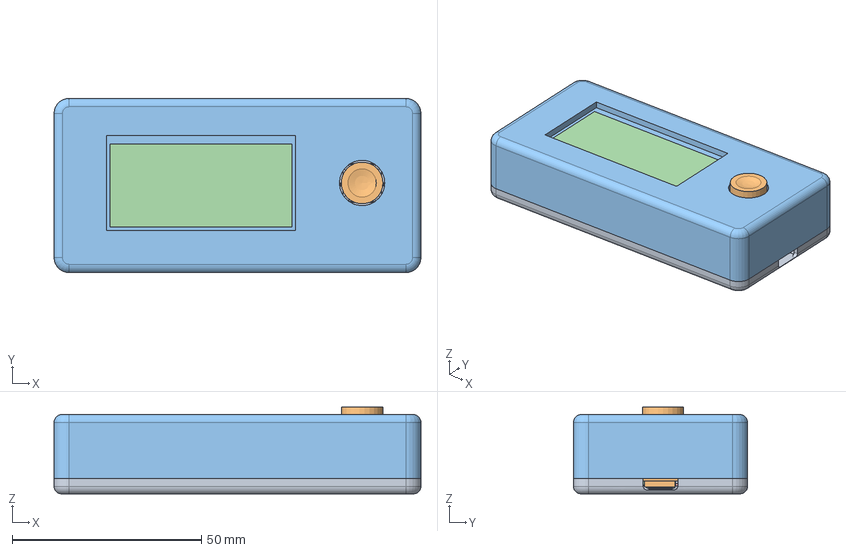
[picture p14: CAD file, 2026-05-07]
hardware-design/freecad-mk2/Dilder_Rev2_Mk2_NoSolar.FCStd
96.9 x 46.0 x 22.9 mm
BasePlate
AAACradle
TopCover
Pico2W_Board
Pico2W_Headers
AAA_Battery_1
AAA_Battery_1_PosTerm
AAA_Battery_2
AAA_Battery_2_PosTerm
TP4056_Module
EInkDisplay_Module
EInkDisplay_Panel
BatteryClips_Positive
BatteryClips_Negative
BatteryWiring_Positive
BatteryWiring_Negative
JoystickPCB
Thumbpiece
Piezo_Brass
Piezo_Ceramic
IMU_Module

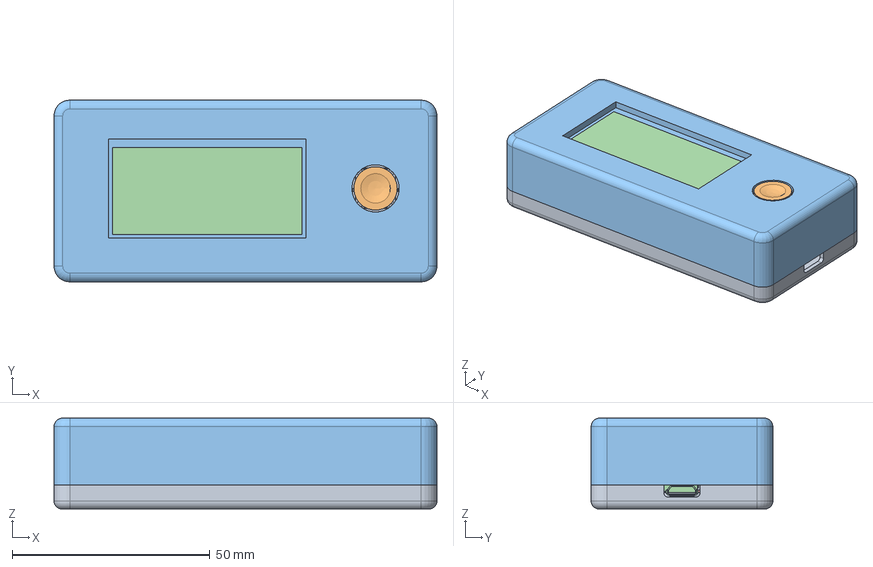
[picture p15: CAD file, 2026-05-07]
hardware-design/freecad-mk2/Dilder_Rev2_Mk2.FCStd
96.9 x 46.0 x 23.0 mm
BasePlate
AAACradle
TopCover
Pico2W_Board
Pico2W_Headers
AAA_Battery_1
AAA_Battery_1_PosTerm
AAA_Battery_2
AAA_Battery_2_PosTerm
TP4056_Module
EInkDisplay_Module
EInkDisplay_Panel
BatteryClips_Positive
BatteryClips_Negative
BatteryWiring_Positive
BatteryWiring_Negative
JoystickPCB
Thumbpiece
Piezo_Brass
Piezo_Ceramic
IMU_Module
Solar_Frame
Solar_Cells
Solar_Wire_Plus
Solar_Wire_Minus
ActiveBuzzer_Body
ActiveBuzzer_WirePlus
ActiveBuzzer_WireMinus

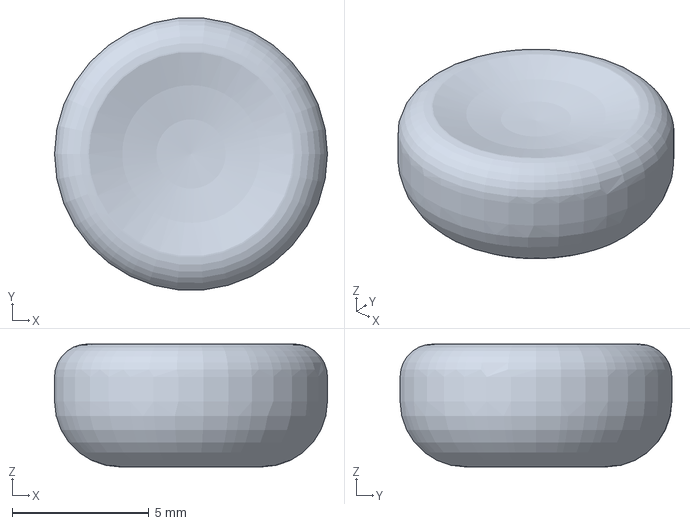
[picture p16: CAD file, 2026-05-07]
hardware-design/freecad-mk2/Dilder_Rev2_Mk2_NoSolar_Buzzer-Thumbpiece.3mf
10.0 x 9.96 x 4.50 mm

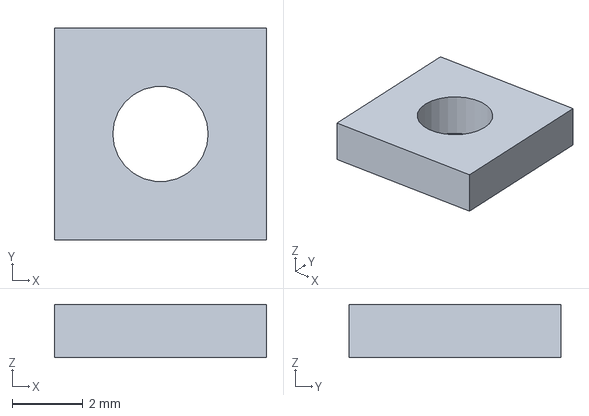
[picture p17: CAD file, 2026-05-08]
hardware-design/freecad-mk2/Dilder_Rev2_Mk2_NoSolar_Buzzer-IMUPegWasher_PX.3mf
6.00 x 6.00 x 1.50 mm

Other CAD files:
hardware-design/freecad-mk2/Dilder_Rev2_Mk2_NoSolar_Buzzer-BasePlate_thiccc.3mf
hardware-design/freecad-mk2/Dilder_Rev2_Mk2_NoSolar_Buzzer-TopCover.3mf

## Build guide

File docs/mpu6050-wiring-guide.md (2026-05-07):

# MPU-6050 Wiring Guide — Pico 2 W

## Module: GY-521 / MPU-6050 (8-pin breakout)

## Wiring Table

| MPU-6050 Pin | Wire To | Pico 2 W Pin | Notes |
|---|---|---|---|
| VCC | 3V3(OUT) | Pin 36 | 3.3V regulated output |
| GND | GND | Pin 33 | Any GND pin works |
| SCL | GP1 (I2C0 SCL)  | Pin 2 | I2C clock |
| SDA | GP0 (I2C0 SDA)  | Pin 1 | I2C data |
| AD0 | GND | Pin 33 | Sets I2C address to 0x68 |
| INT | — | Unconnected | Optional (for interrupt-driven) |
| XDA | — | Unconnected | Aux I2C (unused) |
| XCL | — | Unconnected | Aux I2C (unused) |

## Pin Map on Pico 2 W Header

```
                    Pico 2 W (USB at top)
                  ┌─────────────────────┐
  SDA  GP0  Pin 1 │■                    │ Pin 40  VBUS
  SCL  GP1  Pin 2 │■                    │ Pin 39  VSYS ← TP4056 OUT+
        GND Pin 3 │                     │ Pin 38  GND  ← TP4056 OUT-
  JOY↑ GP2  Pin 4 │                     │ Pin 37  3V3_EN
  JOY↓ GP3  Pin 5 │                     │ Pin 36  3V3(OUT) ← MPU VCC, Waveshare VCC
  JOY← GP4  Pin 6 │                     │ Pin 35  ADC_VREF
  JOY→ GP5  Pin 7 │                     │ Pin 34  GP28/ADC2
        GND Pin 8 │                     │ Pin 33  GND ← MPU GND, MPU AD0
  JOYC GP6  Pin 9 │                     │ Pin 32  GP27/ADC1
  SPK  GP7 Pin 10 │                     │ Pin 31  GP26/ADC0
  DC   GP8 Pin 11 │                     │ Pin 30  RUN
  CS   GP9 Pin 12 │                     │ Pin 29  GP22
  CLK GP10 Pin 13 │                     │ Pin 28  GND
  DIN GP11 Pin 14 │                     │ Pin 27  GP21
  RST GP12 Pin 15 │                     │ Pin 26  GP20
  BSY GP13 Pin 16 │                     │ Pin 25  GP19
  BUZ GP14 Pin 17 │                     │ Pin 24  GP18
        GND Pin 18│                     │ Pin 23  GND
       GP15 Pin 19│ (free)              │ Pin 22  GP17
       GP16 Pin 20│ (free)              │ Pin 21  GP16
                  └─────────────────────┘
```

## I2C Details

- **Bus:** I2C0
- **Address:** 0x68 (AD0 tied to GND)
- **Speed:** 400 kHz (Fast mode — MPU-6050 supports up to 400 kHz)
- **Pull-ups:** Onboard on the GY-521 module (4.7k to VCC). No external resistors needed.

## What the MPU-6050 Provides

| Sensor | Range (default) | Resolution |
|---|---|---|
| Accelerometer | +/- 2g | 16-bit |
| Gyroscope | +/- 250 deg/s | 16-bit |
| Temperature | -40 to +85 C | 16-bit |

## Register Quick Reference

| Register | Address | Purpose |
|---|---|---|
| PWR_MGMT_1  | 0x6B | Power management (write 0 to wake) |
| ACCEL_XOUT_H | 0x3B | Accel X high byte (burst read 6 bytes for XYZ) |
| GYRO_XOUT_H  | 0x43 | Gyro X high byte (burst read 6 bytes for XYZ) |
| TEMP_OUT_H | 0x41 | Temperature high byte |
| WHO_AM_I | 0x75 | Device ID (should read 0x68) |
| ACCEL_CONFIG | 0x1C | Accelerometer range config |
| GYRO_CONFIG  | 0x1B | Gyroscope range config |

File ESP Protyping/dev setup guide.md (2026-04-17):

# Dev Setup Guide — Multi-Board Code Changes & Deployment Walkthrough

> Step-by-step guide covering the multi-board architecture, the code changes made to support both the **Pico W (RP2040)** and the **Olimex ESP32-S3-DevKit-Lipo**, and how to go from a bare board to running firmware through the DevTool or terminal. Each deployment step includes board-specific options where the instructions differ.

---

## Choosing Your Board

Before you begin, decide which board you're setting up. Steps that are the same for both boards show a single set of instructions. Steps that differ show clearly marked options:

> **Pico W** — The Raspberry Pi Pico W (RP2040). HAT plugs directly onto the headers — no breadboard wiring. Uses the ARM GCC toolchain and CMake/Ninja. Flash via BOOTSEL + UF2.

> **ESP32-S3 (Olimex)** — The Olimex ESP32-S3-DevKit-Lipo. Uses breadboard + jumper wires. Uses PlatformIO + Arduino/ESP-IDF. Flash via USB-UART + esptool.

The setup CLI also supports board filtering:

```bash
python3 setup.py --board pico    # only Pico W steps
python3 setup.py --board esp32   # only ESP32-S3 steps
python3 setup.py                 # all steps for both boards
```

---

## Table of Contents

1. [What Changed — Overview](#1-what-changed--overview)
2. [New Files Created](#2-new-files-created)
3. [Modified Files](#3-modified-files)
4. [Architecture — How Multi-Board Works](#4-architecture--how-multi-board-works)
   - [4.1 Compile-Time Board Selection (C)](#41-compile-time-board-selection-c)
   - [4.2 Runtime Board Selection (DevTool)](#42-runtime-board-selection-devtool)
   - [4.3 Pin Mapping Comparison](#43-pin-mapping-comparison)
5. [Prerequisites](#5-prerequisites)
6. [Step 1 — Install Toolchain](#6-step-1--install-toolchain)
7. [Step 2 — Verify USB Serial Driver](#7-step-2--verify-usb-serial-driver)
8. [Step 3 — Wire the Board](#8-step-3--wire-the-board)
9. [Step 4 — Build & Flash from Terminal](#9-step-4--build--flash-from-terminal)
10. [Step 5 — Build & Flash from DevTool](#10-step-5--build--flash-from-devtool)
11. [Step 6 — Verify Everything Works](#11-step-6--verify-everything-works)
12. [The Automated Way — setup.py](#12-the-automated-way--setuppy)
13. [Troubleshooting](#13-troubleshooting)
14. [File Reference](#14-file-reference)

---

## 1. What Changed — Overview

The Dilder project previously only targeted the **Raspberry Pi Pico W (RP2040)**. These changes add the **Olimex ESP32-S3-DevKit-Lipo** as a second deployment target. Everything is designed so you can switch between boards without changing any game engine code — the pin assignments, SPI controller, and hardware I/O are abstracted behind a compile-time config header and a runtime board selector in the DevTool GUI.

**Summary of changes:**

| Area | What | Why |
|---|---|-----|
| **DevTool** | Board selector dropdown, ESP32 serial detection, esptool flash support | Switch deployment target with one click |
| **Firmware** | `board_config.h` pin abstraction, `hal.h` interface, ESP32 HAL implementation | Same game engine code runs on both boards |
| **PlatformIO project** | `platformio.ini` + `main.cpp` in `ESP Protyping/dilder-esp32/` | Build system for the ESP32-S3 with all dependencies |
| **setup.py** | Step 16 — PlatformIO + esptool + ESP-IDF installation | One-command toolchain setup |

---

## 2. New Files Created

### Firmware Platform Layer

```
firmware/
  include/
    platform/
      board_config.h    ← Compile-time pin definitions for all boards
      hal.h             ← Hardware abstraction interface (SPI, buttons, LED, battery)
  src/
    platform/
      esp32s3/
        esp32s3_hal.c   ← ESP32-S3 HAL implementation (Arduino framework)
```

### PlatformIO Project

```
ESP Protyping/
  dilder-esp32/
    platformio.ini      ← Build config: board, framework, libraries, flags
    src/
      main.cpp          ← ESP32-S3 entry point: display test + joystick handler
    include/            ← (empty, for project-local headers)
```

---

## 3. Modified Files

### `DevTool/devtool.py`

| Change | Details |
|---|---|
| Version bumped | `1.0.0` → `1.1.0` |
| Board constants | `BOARD_PICO_W`, `BOARD_ESP32S3`, `BOARD_LABELS` dict |
| `find_esp32_serial()` | Detects Olimex board via CH340X VID `0x1A86` on `/dev/ttyUSB*` |
| `find_serial_for_board(board)` | Unified serial detection that routes by selected board |
| `DilderDevTool._build_ui()` | Board selector toolbar added above the notebook tabs |
| `DilderDevTool._on_board_changed()` | Switches pin viewer, flash utility, and serial detection |
| `FlashUtility` | Rebuilt to support both Pico (BOOTSEL + UF2) and ESP32 (esptool + .bin) |
| `PinViewer` | Shows Olimex ESP32-S3 pinout when ESP board selected |
| `ProgramsTab` | Deploy button is board-aware, flash size adjusts (2 MB Pico / 8 MB ESP32) |

### `firmware/CMakeLists.txt`

Added `TARGET_BOARD` CMake variable with `add_compile_definitions(BOARD_${TARGET_BOARD})`. Defaults to `DESKTOP` for the shared library build.

### `setup.py`

- Docstring and banner updated to mention both boards
- `ESP32_PROJECT` path constant added
- **Step 16** added: installs PlatformIO CLI, esptool, checks CH340X driver, verifies project, pre-downloads ESP32-S3 platform
- `show_status()` now reports PlatformIO version, esptool, ESP32 project state, and `/dev/ttyUSB*` detection

---

## 4. Architecture — How Multi-Board Works

### 4.1 Compile-Time Board Selection (C)

The header `firmware/include/platform/board_config.h` uses preprocessor guards to define the same set of macros for each board:

```c
// Set at build time:
//   PlatformIO:  build_flags = -DBOARD_ESP32S3
//   CMake:       cmake -DTARGET_BOARD=ESP32S3 ..
//   Pico SDK:    -DPICO_BOARD=pico_w  (auto-defines BOARD_PICO_W)

#if defined(BOARD_PICO_W) || defined(PICO_BOARD)
    #define PIN_EPD_CLK   10    // GP10 SPI1
    #define PIN_BTN_UP     2    // GP2
    // ...
#elif defined(BOARD_ESP32S3)
    #define PIN_EPD_CLK   12    // GPIO12 FSPI
    #define PIN_BTN_UP     4    // GPIO4
    // ...
#else  // Desktop
    #define PIN_EPD_CLK    0    // dummy
    // ...
#endif
```

Game engine code uses `PIN_EPD_CLK`, `PIN_BTN_UP`, etc. without knowing which board is active.

### 4.2 Runtime Board Selection (DevTool)

The DevTool GUI stores the selected board in `DilderDevTool._target_board` (a `tk.StringVar`). When you change the dropdown:

1. `_on_board_changed()` fires
2. Updates `self._target_board` to `"pico_w"` or `"esp32s3"`
3. Calls `pin_tab.refresh_for_board(board)` — swaps the pinout display
4. Calls `flash_tab.refresh_for_board(board)` — switches between BOOTSEL/UF2 and esptool/.bin
5. Serial detection uses `find_serial_for_board(board)` which routes to `find_pico_serial()` or `find_esp32_serial()`

The `ProgramsTab` reads `self.app.target_board` to determine flash size and which serial port to stream frames to.

### 4.3 Pin Mapping Comparison

| Signal | Pico W (RP2040) | ESP32-S3 (Olimex) |
|---|---|---|
| **e-Paper CLK** | GP10 (SPI1 SCK) pin 14 | GPIO12 (FSPI CLK) EXT1-18 |
| **e-Paper DIN** | GP11 (SPI1 TX) pin 15 | GPIO11 (FSPI MOSI) EXT1-17 |
| **e-Paper CS** | GP9 pin 12 | GPIO10 (10k pull-up) EXT1-16 |
| **e-Paper DC** | GP8 pin 11 | GPIO9 EXT1-15 |
| **e-Paper RST** | GP12 pin 16 | GPIO3 EXT1-13 |
| **e-Paper BUSY** | GP13 pin 17 | GPIO8 EXT1-12 |
| **Joystick UP** | GP2 pin 4 | GPIO4 EXT1-4 |
| **Joystick DOWN** | GP3 pin 5 | GPIO7 EXT1-7 |
| **Joystick LEFT** | GP4 pin 6 | GPIO1 EXT2-4 |
| **Joystick RIGHT** | GP5 pin 7 | GPIO2 EXT2-5 |
| **Joystick CENTER** | GP6 pin 9 | GPIO15 EXT1-8 |
| **LED** | — | GPIO38 (active LOW) |
| **Battery ADC** | — | GPIO6 (divider x4.133) |
| **USB Power** | — | GPIO5 (divider x1.468) |

---

## 5. Prerequisites

**Both boards:**

- [ ] **Waveshare 2.13" e-Paper HAT V3**
- [ ] **5-way joystick module** (DollaTek or similar)
- [ ] **Python 3.9+** on your system
- [ ] **pip** available (`python3 -m pip --version`)

### Pico W

- [ ] **Raspberry Pi Pico W** board (with micro-USB data cable)
- [ ] No extra wiring — the Waveshare HAT plugs directly onto the Pico W headers

### ESP32-S3 (Olimex)

- [ ] **Olimex ESP32-S3-DevKit-Lipo** board (with USB-C data cable)
- [ ] **Breadboard + jumper wires** (see `setup wiring guide.md` for wiring details)

---

## 6. Step 1 — Install Toolchain

### Pico W

**Automated (recommended):**

```bash
python3 setup.py --board pico --step 2
```

Steps 2-4 install the ARM GCC cross-compiler, clone the Pico SDK, and set `PICO_SDK_PATH`.

**Manual:**

```bash
# Arch / CachyOS
sudo pacman -S arm-none-eabi-gcc arm-none-eabi-newlib cmake ninja

# Debian / Ubuntu
sudo apt install gcc-arm-none-eabi libnewlib-arm-none-eabi cmake ninja-build

# Clone the Pico SDK
git clone --depth 1 https://github.com/raspberrypi/pico-sdk.git ~/pico/pico-sdk
cd ~/pico/pico-sdk && git submodule update --init

# Set the SDK path (add to ~/.zshrc or ~/.bashrc)
export PICO_SDK_PATH="$HOME/pico/pico-sdk"
```

### ESP32-S3 (Olimex)

**Automated (recommended):**

```bash
python3 setup.py --board esp32 --step 16
```

This walks you through everything interactively — installs PlatformIO, esptool, checks the CH340X driver, and pre-downloads the ESP32-S3 platform (~500 MB first time).

**Manual (Arch / CachyOS — uses pipx due to PEP 668):**

```bash
# Install pipx if you don't have it
sudo pacman -S python-pipx

# Install PlatformIO CLI
pipx install platformio
pio --version

# Install esptool (for direct flashing from DevTool)
pipx install esptool
esptool.py version
```

**Manual (Debian / Ubuntu / Fedora — uses pip):**

```bash
# Install PlatformIO CLI
pip install --user platformio
pio --version

# Install esptool
pip install --user esptool
esptool.py version

# If pio/esptool not found, add ~/.local/bin to PATH:
export PATH="$HOME/.local/bin:$PATH"
```

**Both — pre-download the ESP32-S3 platform:**

```bash
# Triggers ~500 MB download on first run (Xtensa compiler, ESP-IDF, Arduino core)
cd "ESP Protyping/dilder-esp32"
pio run
```

> **Note:** PlatformIO includes its own bundled esptool, so the standalone install is only needed if you flash from DevTool directly.

---

## 7. Step 2 — Verify USB Serial Driver

### Pico W

The Pico W uses the RP2040's native USB which shows up as `/dev/ttyACM*`. No extra driver needed — the `cdc_acm` module is built into the kernel.

**Plug in the Pico W via USB**, then:

```bash
# Check the device exists
ls -la /dev/ttyACM*
# Should show: /dev/ttyACM0

# If "Permission denied":
sudo usermod -aG uucp $USER    # Arch/CachyOS
sudo usermod -aG dialout $USER  # Debian/Ubuntu
# Then log out and back in
```

### ESP32-S3 (Olimex)

The Olimex board uses a **CH340X** USB-to-serial chip. The `ch341` kernel module is built into most modern Linux kernels (including CachyOS).

**Plug in the board via the USB-UART port** (the one near the RST/BOOT buttons), then:

```bash
# Check kernel detected it
dmesg | tail -10
# Should show: "ch341-uart converter now attached to ttyUSB0"

# Verify the device exists
ls -la /dev/ttyUSB*
# Should show: /dev/ttyUSB0

# If "Permission denied":
sudo usermod -aG uucp $USER    # Arch/CachyOS
sudo usermod -aG dialout $USER  # Debian/Ubuntu
# Then log out and back in
```

**Which USB port to use on the Olimex board:**

| Port | Location | Chip | Use for |
|---|---|---|---|
| **USB-UART** | Near the buttons | CH340X | Uploading firmware, serial monitor |
| **USB-OTG** | Near the antenna | Native | JTAG debugging (advanced) |

For all normal development, use **USB-UART**. It has auto-reset so PlatformIO and esptool can flash without pressing any buttons.

---

## 8. Step 3 — Wire the Board

### Pico W

No breadboard wiring needed. The Waveshare 2.13" e-Paper HAT plugs directly onto the Pico W's 40-pin header:

1. **Unplug** the Pico W from USB.
2. Align pin 1 on both boards (top-left when USB faces you).
3. Press the HAT down firmly until fully seated — no pins visible between boards.

The HAT routes these signals through its PCB:

| Signal | Pico W Pin | GPIO |
|---|---|---|
| VCC | Pin 36 | 3V3(OUT) |
| GND | Pin 38 | GND |
| DIN | Pin 15 | GP11 (SPI1 TX) |
| CLK | Pin 14 | GP10 (SPI1 SCK) |
| CS | Pin 12 | GP9 |
| DC | Pin 11 | GP8 |
| RST | Pin 16 | GP12 |
| BUSY | Pin 17 | GP13 |

The joystick wires to the Pico W breadboard (if using external joystick):

| Joystick Pin | Pico W GPIO | Pin |
|---|---|-----|
| COM / GND | GND | Pin 38 |
| UP | GP2 | Pin 4 |
| DOWN | GP3 | Pin 5 |
| LEFT | GP4 | Pin 6 |
| RIGHT | GP5 | Pin 7 |
| CENTER | GP6 | Pin 9 |

### ESP32-S3 (Olimex)

Follow the wiring instructions in **`setup wiring guide.md`** Section 5. Here's the quick reference:

**e-Paper Display (female-to-male jumpers):**

| HAT Pin | Wire to | ESP32 GPIO | Board Pin |
|---|---|---|---|
| VCC | 3.3V rail | — | EXT1-1 |
| GND | GND rail | — | EXT1-22 |
| DIN | GPIO11 | EXT1-17 |
| CLK | GPIO12 | EXT1-18 |
| CS | GPIO10 | EXT1-16 |
| DC | GPIO9 | EXT1-15 |
| RST | GPIO3 | EXT1-13 |
| BUSY | GPIO8 | EXT1-12 |

**Joystick (male-to-male jumpers):**

| Joystick Pin | Wire to | ESP32 GPIO | Board Pin |
|---|---|---|---|
| COM / GND | GND rail | — | — |
| UP | GPIO4 | EXT1-4 |
| DOWN | GPIO7 | EXT1-7 |
| LEFT | GPIO1 | EXT2-4 |
| RIGHT | GPIO2 | EXT2-5 |
| CENTER | GPIO15 | EXT1-8 |

---

## 9. Step 4 — Build & Flash from Terminal

### Pico W

```bash
cd dev-setup/hello-world-serial

# Configure (first time only)
mkdir -p build && cd build
cmake -G Ninja -DPICO_SDK_PATH=$PICO_SDK_PATH -DPICO_BOARD=pico_w ..

# Build
ninja

# Flash: hold BOOTSEL on the Pico, plug USB, release — it mounts as RPI-RP2
cp hello_serial.uf2 /run/media/$USER/RPI-RP2/

# Serial monitor (115200 baud)
screen /dev/ttyACM0 115200
```

**Expected serial output after flash:**

```
Hello, Dilder!
Heartbeat: 1
Heartbeat: 2
...
```

The onboard LED blinks once per second.

### ESP32-S3 (Olimex)

```bash
cd "ESP Protyping/dilder-esp32"

# Build only
pio run

# Build + flash (auto-detects /dev/ttyUSB0)
pio run -t upload

# Open serial monitor (115200 baud)
pio device monitor
```

**Expected serial output after flash:**

```
=== Dilder ESP32-S3 Firmware ===
Board: ESP32-S3 (Olimex)
Flash: 8192 KB
PSRAM: 8388608 bytes
Setup complete. Entering main loop.
Joystick: UP/DOWN/LEFT/RIGHT/CENTER
```

**Expected display output:**

The e-Paper display should show:

```
DILDER
ESP32-S3 Olimex DevKit-Lipo
─────────────────────────────
PSRAM: 8192 KB
Battery: 4.12V
USB: connected
Press joystick to test...
```

The green LED on the board blinks once after the startup screen draws.

**Test the joystick:**

Press each direction — the green LED flashes and the serial monitor prints the direction. Press CENTER to show the chip info screen on the display.

---

## 10. Step 5 — Build & Flash from DevTool

```bash
python3 DevTool/devtool.py
```

Both boards use the same DevTool GUI. The **"Target Board"** dropdown at the top of the window controls which board you're working with. All tabs (GPIO Pins, Flash Firmware, Programs) adapt to the selected board.

### Pico W

1. **Select the board:** Use the **"Target Board"** dropdown — make sure **"Pico W (RP2040)"** is selected (this is the default).

2. **Check detection:** The status next to the dropdown should show `Serial: /dev/ttyACM0` in green. If it shows "Not detected", plug in the USB cable.

3. **View the pinout:** Click the **"GPIO Pins"** tab — shows the Pico W pinout with Dilder-assigned pins marked.

4. **Flash the firmware:** Go to the **"Flash Firmware"** tab. Put the Pico W in BOOTSEL mode, then click **"Flash UF2"** to copy the firmware.

5. **Deploy a program:** Go to the **"Programs"** tab. Select any octopus program. Flash size shows "Pico W (RP2040) flash: 2048 KB". Click **"Deploy to Board"** to stream frames.

### ESP32-S3 (Olimex)

1. **Select the board:** Use the **"Target Board"** dropdown. Change it from "Pico W (RP2040)" to **"ESP32-S3 (Olimex)"**.

2. **Check detection:** The status next to the dropdown should show `Serial: /dev/ttyUSB0` in green. If it shows "Not detected", plug in the USB-UART cable.

3. **View the pinout:** Click the **"GPIO Pins"** tab — it now shows the full Olimex ESP32-S3 pinout with all Dilder-assigned pins marked.

4. **Build the firmware:** Go to the **"Flash Firmware"** tab. Click **"Build ESP32 (PlatformIO)"**. Watch the log panel at the bottom for build progress.

5. **Flash the firmware:** After the build completes, click **"Detect ESP32"** to confirm the port, then click **"Flash"** to upload.

6. **Deploy a program:** Go to the **"Programs"** tab. Select any octopus program. The flash size display now shows "ESP32-S3 (Olimex) flash: 8192 KB" instead of the Pico's 2048 KB. Click **"Deploy to Board"** to stream frames, or **"Deploy Standalone"** to build a self-contained firmware.

---

## 11. Step 6 — Verify Everything Works

### Pico W

- [ ] Serial monitor shows `Hello, Dilder!` and heartbeat counter
- [ ] Onboard LED blinks once per second
- [ ] Display shows text after flashing the display hello world (Steps 10-14 in setup.py)
- [ ] Joystick directions print to serial (if joystick wired)
- [ ] Switching to "ESP32-S3 (Olimex)" in DevTool still works

### ESP32-S3 (Olimex)

- [ ] Serial monitor shows `=== Dilder ESP32-S3 Firmware ===`
- [ ] PSRAM reports 8388608 bytes (8 MB)
- [ ] Display shows the startup screen with board info
- [ ] Battery voltage reads a sane value (3.3-4.2V if on USB, 0V if no battery)
- [ ] USB power shows "connected" when on USB
- [ ] Each joystick direction prints to serial and blinks the green LED
- [ ] CENTER button shows the chip info screen on the display
- [ ] Switching back to "Pico W" in DevTool still works for Pico builds

---

## 12. The Automated Way — setup.py

The setup CLI supports board-specific walkthrough via the `--board` flag:

```bash
# Full setup for a specific board
python3 setup.py --board pico       # Pico W only (steps 1-15)
python3 setup.py --board esp32      # ESP32-S3 only (steps 1, 5-6, 15-16)

# Or run everything
python3 setup.py                    # all steps for both boards

# Jump to a specific step
python3 setup.py --step 16          # ESP32-S3 toolchain step directly

# List available steps (filtered by board)
python3 setup.py --board esp32 --list

# Check overall status
python3 setup.py --status
```

### Pico W steps (1-15)

Steps 2-4 install the ARM GCC cross-compiler, clone the Pico SDK, and set the environment variable. Steps 7-14 build, flash, and verify the hello world programs (serial and display).

### ESP32-S3 step (16)

1. Checks pip is available
2. Installs PlatformIO CLI (`pip install --user platformio`)
3. Installs esptool (`pip install --user esptool`)
4. Verifies the CH340X kernel module exists
5. Checks serial group membership (`uucp` or `dialout`)
6. Verifies the PlatformIO project at `ESP Protyping/dilder-esp32/` has `platformio.ini` and `src/main.cpp`
7. Optionally pre-downloads the ESP32-S3 platform + libraries and does a test build

**Status output (after setup):**

```
  ESP32-S3 Toolchain
  ──────────────────────────────────────────────────
  ✓ PlatformIO: PlatformIO Core, version 6.x.x
  ✓ esptool: /home/user/.local/bin/esptool.py
  ✓ ESP32 project: .../ESP Protyping/dilder-esp32
  ✓ ESP32 firmware.bin: 245 KB

  Hardware
  ──────────────────────────────────────────────────
  ✓ Pico W detected on /dev/ttyACM0
  ✓ ESP32-S3 (CH340X) candidate: /dev/ttyUSB0
```

---

## 13. Troubleshooting

### Both Boards

#### Serial port permission denied (`/dev/ttyACM0` or `/dev/ttyUSB0`)

```bash
# CachyOS / Arch
sudo usermod -aG uucp $USER

# Debian / Ubuntu
sudo usermod -aG dialout $USER

# Then log out and back in (or reboot)
```

#### Display doesn't show anything

**Pico W:** Make sure the HAT is fully seated — no pins exposed between boards. Check FPC ribbon cable is not pinched.

**ESP32-S3:** Double-check all 8 wires (VCC, GND, DIN, CLK, CS, DC, RST, BUSY). Make sure VCC goes to **3.3V** (EXT1-1), NOT 5V. Verify wiring matches the pin table in Section 8. Check serial monitor — `GxEPD2` prints SPI diagnostics during `display.init()`.

### Pico W

#### CMake can't find Pico SDK

```bash
# Make sure PICO_SDK_PATH is set
echo $PICO_SDK_PATH
# Should show ~/pico/pico-sdk or wherever you cloned it

# If empty, set it:
export PICO_SDK_PATH="$HOME/pico/pico-sdk"
# Add to ~/.zshrc or ~/.bashrc to persist
```

#### Pico W doesn't mount as RPI-RP2

1. Hold **BOOTSEL** before plugging in USB
2. Keep holding BOOTSEL while plugging in
3. Release BOOTSEL — it should mount as a USB drive
4. Check `lsblk` or `dmesg | tail` for the device

#### DevTool doesn't detect the Pico W

The DevTool looks for the Raspberry Pi USB Vendor ID (`0x2E8A`). If detection fails:

1. Unplug and re-plug the USB cable
2. Check `ls /dev/ttyACM*`
3. Make sure no other serial monitor is open (only one process can hold the port)

### ESP32-S3 (Olimex)

#### PlatformIO not found after install

```bash
# pip/pipx installed to ~/.local/bin which isn't in PATH
export PATH="$HOME/.local/bin:$PATH"
# Add to ~/.zshrc or ~/.bashrc to persist
```

#### `pip install` fails with "externally-managed-environment" (Arch/CachyOS)

Arch-based distros block `pip install --user` (PEP 668). Use `pipx` instead:

```bash
sudo pacman -S python-pipx
pipx install platformio
pipx install esptool
```

The setup CLI (`python3 setup.py --step 16`) handles this automatically.

#### Build fails: "No such file or directory: board_config.h"

The `platformio.ini` uses `build_src_filter` to include the shared firmware source. The include path for shared headers is set via `build_src_extra`. If this fails, add an explicit include path:

```ini
; In platformio.ini, under build_flags:
build_flags =
    -DBOARD_ESP32S3
    -I../../firmware/include
```

#### esptool can't connect / times out

If auto-reset isn't working:

1. Hold the **BOOT** button on the board
2. Press and release **RST** while still holding BOOT
3. Release **BOOT**
4. Run the flash command within 5 seconds

#### PSRAM shows 0 bytes

Verify `platformio.ini` has both of these:

```ini
board_build.psram = enabled
board_build.arduino.memory_type = qio_opi
```

The `qio_opi` memory type is required for the N8R8 module's octal PSRAM.

#### DevTool doesn't detect the ESP32

The DevTool looks for the CH340X chip by USB Vendor ID (`0x1A86`). If detection fails:

1. Unplug and re-plug the USB-UART cable
2. Check `dmesg | tail` for the device name
3. The fallback detection matches any `/dev/ttyUSB*` device

---

## 14. File Reference

Quick lookup for every file involved in the ESP32-S3 support:

| File | Purpose |
|---|---|
| `ESP Protyping/dilder-esp32/platformio.ini` | PlatformIO build config — board, framework, libraries, flags |
| `ESP Protyping/dilder-esp32/src/main.cpp` | ESP32 firmware entry point — display test, joystick, chip info |
| `firmware/include/platform/board_config.h` | Compile-time pin definitions for Pico W, ESP32-S3, Desktop |
| `firmware/include/platform/hal.h` | Hardware abstraction interface (SPI, buttons, LED, battery, timing) |
| `firmware/src/platform/esp32s3/esp32s3_hal.c` | ESP32-S3 HAL implementation using Arduino framework |
| `firmware/CMakeLists.txt` | Updated with `TARGET_BOARD` variable for board selection |
| `DevTool/devtool.py` | Board selector, ESP32 serial detection, esptool flash, pin viewer |
| `setup.py` | Step 16 — PlatformIO + esptool + ESP-IDF toolchain installation |
| `ESP Protyping/setup wiring guide.md` | Physical wiring reference (breadboard, pinout, connectors) |
| `ESP Protyping/dev setup guide.md` | This file |

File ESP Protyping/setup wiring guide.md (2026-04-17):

# Olimex ESP32-S3-DevKit-Lipo — Setup, Wiring & Development Guide

> Complete hands-on guide for setting up the Olimex ESP32-S3-DevKit-Lipo with the Waveshare 2.13" e-Paper V3 display and 5-way joystick for Dilder prototyping. Covers board features, pinout, breadboard wiring, VSCode + PlatformIO setup, firmware compilation, and flashing.

---

## Table of Contents

1. [Board Overview — Olimex ESP32-S3-DevKit-Lipo](#1-board-overview)
   - [1.1 Key Specifications](#11-key-specifications)
   - [1.2 What's On the Board](#12-whats-on-the-board)
   - [1.3 USB Ports — Which Is Which](#13-usb-ports--which-is-which)
   - [1.4 Buttons and LEDs](#14-buttons-and-leds)
   - [1.5 Battery Charging](#15-battery-charging)
     - [Battery Connector Details](#battery-connector-details)
     - [Compatible LiPo Battery Options](#compatible-lipo-battery-options)
   - [1.6 Power Architecture](#16-power-architecture)
   - [1.7 pUEXT Connector](#17-puext-connector)
2. [Full GPIO Pinout](#2-full-gpio-pinout)
   - [2.1 Header EXT1 (Left Side)](#21-header-ext1-left-side)
   - [2.2 Header EXT2 (Right Side)](#22-header-ext2-right-side)
   - [2.3 GPIO Restrictions and Warnings](#23-gpio-restrictions-and-warnings)
   - [2.4 Freely Available GPIO Pins](#24-freely-available-gpio-pins)
   - [2.5 Strapping Pins](#25-strapping-pins)
3. [Parts You Already Have](#3-parts-you-already-have)
4. [GPIO Assignment for Dilder](#4-gpio-assignment-for-dilder)
   - [4.1 Pin Mapping Table](#41-pin-mapping-table)
   - [4.2 Bus Summary Diagram](#42-bus-summary-diagram)
5. [Breadboard Wiring — Step by Step](#5-breadboard-wiring--step-by-step)
   - [5.1 What You Need](#51-what-you-need)
   - [5.2 Phase 1 — Board on Breadboard](#52-phase-1--board-on-breadboard)
   - [5.3 Phase 2 — Wire the Joystick](#53-phase-2--wire-the-joystick)
   - [5.4 Phase 3 — Wire the e-Paper Display](#54-phase-3--wire-the-e-paper-display)
   - [5.5 Master Wiring Diagram](#55-master-wiring-diagram)
   - [5.6 Wiring Checklist](#56-wiring-checklist)
6. [VSCode + PlatformIO Setup](#6-vscode--platformio-setup)
   - [6.1 Install PlatformIO](#61-install-platformio)
   - [6.2 Create the Project](#62-create-the-project)
   - [6.3 Configure platformio.ini](#63-configure-platformioini)
   - [6.4 USB Driver Setup (Linux)](#64-usb-driver-setup-linux)
   - [6.5 First Upload — Blink Test](#65-first-upload--blink-test)
7. [Test Sketches](#7-test-sketches)
   - [7.1 Chip Info Sketch](#71-chip-info-sketch)
   - [7.2 Battery Monitor Sketch](#72-battery-monitor-sketch)
   - [7.3 Joystick Test Sketch](#73-joystick-test-sketch)
   - [7.4 e-Paper Display Test Sketch](#74-e-paper-display-test-sketch)
   - [7.5 Combined Test — All Peripherals](#75-combined-test--all-peripherals)
8. [Compiling and Flashing Firmware](#8-compiling-and-flashing-firmware)
   - [8.1 Build from VSCode](#81-build-from-vscode)
   - [8.2 Build from Terminal](#82-build-from-terminal)
   - [8.3 Serial Monitor](#83-serial-monitor)
   - [8.4 Troubleshooting Upload Issues](#84-troubleshooting-upload-issues)
9. [Integrating with the Dilder DevTool](#9-integrating-with-the-dilder-devtool)
   - [9.1 Architecture Overview](#91-architecture-overview)
   - [9.2 Firmware Build Pipeline](#92-firmware-build-pipeline)
   - [9.3 Serial Communication Protocol](#93-serial-communication-protocol)
10. [Important Notes and Warnings](#10-important-notes-and-warnings)
11. [Resources, Documentation & Videos](#11-resources-documentation--videos)
    - [11.1 Olimex Board Resources](#111-olimex-board-resources)
    - [11.2 ESP32-S3 Resources](#112-esp32-s3-resources)
    - [11.3 Waveshare e-Paper Resources](#113-waveshare-e-paper-resources)
    - [11.4 PlatformIO & Development](#114-platformio--development)
    - [11.5 Video Tutorials](#115-video-tutorials)

---

## 1. Board Overview

Olimex ESP32-S3-DevKit-Lipo — Angled view

*Olimex ESP32-S3-DevKit-Lipo — open-source ESP32-S3 dev board with LiPo charging, dual USB-C, and 8MB PSRAM.*

### 1.1 Key Specifications

| Parameter | Value |
|---|---|
| **Board** | ESP32-S3-DevKit-Lipo (Olimex) |
| **Module** | ESP32-S3-WROOM-1-N8R8 |
| **CPU** | Dual-core Xtensa LX7, up to 240 MHz |
| **Flash** | 8 MB (QIO, 80 MHz) |
| **PSRAM** | 8 MB (Octal, OPI mode) |
| **SRAM** | 512 KB internal |
| **Wi-Fi** | 2.4 GHz 802.11 b/g/n |
| **Bluetooth** | 5.0 LE |
| **Antenna** | PCB antenna (built into the module) |
| **USB** | Dual USB-C (native USB-OTG + CH340X UART) |
| **Battery** | LiPo charging built-in (BL4054B, 100 mA default) |
| **Voltage Regulator** | SY8089AAAC — 3.3V buck converter, 2A output |
| **Deep Sleep** | ~200 µA from LiPo |
| **Pin Headers** | 2x 22-pin, 2.54mm pitch (breadboard-friendly) |
| **Board Dimensions** | 27.94 x 55.88 mm (1.1" x 2.2") |
| **Logic Level** | 3.3V |
| **Price** | €7.95 each |
| **License** | CERN-OHL-S-2.0 (open-source hardware) |
| **OSHW UID** | BG0000108 |

### 1.2 What's On the Board

| Top (component side) | Bottom (silkscreen with GPIO labels) |
|---|---|
| Board top view | Board bottom view — GPIO pin labels |
| *Component side — USB-C ports, buttons, LEDs, pUEXT connector, battery connector* | *Bottom silkscreen — every GPIO pin labeled in white. Flip the board to read pin numbers while wiring.* |

```
    ┌──────────────────────────────────────────┐
    │  ┌─[USB-OTG]──┐    ┌─[USB-UART]──┐     │
    │  │  (native)   │    │  (CH340X)   │     │
    │  └─────────────┘    └─────────────┘     │
    │                                          │
    │  [RST]  [BOOT]    (o) GREEN LED (GPIO38) │
    │                    (o) YELLOW LED (CHG)   │
    │                                          │
    │  ▓▓▓▓▓▓▓▓▓▓▓▓▓▓▓▓▓▓▓▓▓▓▓▓▓▓▓▓▓▓▓▓▓▓   │
    │  ▓   ESP32-S3-WROOM-1-N8R8 Module   ▓   │
    │  ▓   (8MB Flash + 8MB PSRAM)        ▓   │
    │  ▓▓▓▓▓▓▓▓▓▓▓▓▓▓▓▓▓▓▓▓▓▓▓▓▓▓▓▓▓▓▓▓▓▓   │
    │                                          │
    │  [pUEXT 10-pin connector]   [BAT conn]   │
    │                                          │
    │  EXT1 (22 pins)        EXT2 (22 pins)    │
    │  ● ● ● ● ● ... ●    ● ● ● ● ● ... ●   │
    └──────────────────────────────────────────┘
```

**Key components on the PCB:**

| Component | Chip | Function |
|---|---|---|
| Voltage Regulator | SY8089AAAC | 3.3V buck converter (2.7–5.5V in, 2A out) |
| Battery Charger | BL4054B-42TPRN | Li-Ion charger, 4.2V float, 100 mA charge rate |
| USB-to-Serial | CH340X | For UART upload and serial monitor |
| Power Switch | WPM2015-3/TR | P-MOSFET auto-switchover between USB and battery |
| Schottky Diodes | 3x 1N5819S4 | OR-ing between USB power sources and battery |
| Auto-Reset | 2x BC817-40 | DTR/RTS to EN/GPIO0 for automatic bootloader entry |

### 1.3 USB Ports — Which Is Which

The board has **two USB-C ports**. This is important — they do different things.

| Port | Label | Chip | What It Does |
|---|---|---|---|
| **USB-OTG** | Near the module antenna end | None (native) | Direct ESP32-S3 USB. JTAG debugging, USB CDC serial, USB OTG. Uses GPIO19/GPIO20. |
| **USB-UART** | Near the buttons | CH340X | Traditional serial upload. Auto-reset into bootloader. Shows as `/dev/ttyUSB0` or `/dev/ttyACM0`. |

**Which port to use:**

- **For uploading firmware:** Use **USB-UART** (the one with the CH340X). It has auto-reset, so PlatformIO can automatically put the board into bootloader mode and flash.
- **For serial monitor:** Either port works. USB-UART gives you traditional UART serial. USB-OTG gives you USB CDC serial (requires `ARDUINO_USB_CDC_ON_BOOT=1`).
- **For JTAG debugging:** Use **USB-OTG** (native USB). Supports hardware breakpoints and step-through debugging.

**Tip:** You can have both plugged in simultaneously. USB-UART for upload + serial, USB-OTG for JTAG debug.

### 1.4 Buttons and LEDs

| Element | GPIO/Pin | Function |
|---|---|---|
| **RST button** | ESP_EN | Resets the ESP32-S3. Has 10k pull-up + 1µF debounce cap. |
| **BOOT button** | GPIO0 | Hold during reset to enter bootloader (download mode). Also usable as a general-purpose user button during normal operation. |
| **Green LED** | GPIO38 | **Active LOW** — `digitalWrite(38, LOW)` turns it ON. Has 2.2k current-limiting resistor to 3.3V. |
| **Yellow LED** | BL4054B CHRGb | Lights while battery is charging. Not software-controllable. |

### 1.5 Battery Charging

The board has a built-in LiPo charger — **no external TP4056 module needed**.

| Parameter | Value |
|---|---|
| Charger IC | BL4054B-42TPRN |
| Float voltage | 4.2V (±1%) |
| Charge current | 100 mA (set by R4 = 10k PROG resistor) |
| Termination | C/10 (10 mA) |
| Trickle charge | Below 2.9V |
| Connector | 2-pin JST-compatible vertical connector |
| Status LED | Yellow — ON while charging, OFF when done |

**Battery voltage monitoring:** The board has a voltage divider on **GPIO6** (470k/150k) that lets you read the battery voltage via ADC. The divider ratio is **4.133**:

```
Battery Voltage = ADC_reading × (3.3 / 4095) × 4.133
```

**External power detection:** A second voltage divider on **GPIO5** (220k/470k) lets you detect whether USB power is connected. Divider ratio: **1.468**.

**To increase charge current:** Replace R4 (the 10k PROG resistor) with a smaller value. 2k = ~500 mA, 1.65k = ~600 mA. Max is 800 mA (thermal limit of SOT23-5 package).

#### Battery Connector Details

| Parameter | Value |
|---|---|
| **Connector on board** | DW02S vertical (CVILUX CI0102M1VT0-LF) |
| **Compatible plug type** | **JST PH 2.0mm, 2-pin** (standard LiPo connector) |
| **Polarity** | Pin 1 = **VBAT (+)**, Pin 2 = **GND (−)** |
| **Polarity convention** | Same as Adafruit / SparkFun / Pimoroni |

> **CRITICAL — POLARITY WARNING:** There is NO universal polarity standard for JST PH battery connectors. The Olimex board has **no reverse-polarity protection**. Connecting a battery with swapped polarity **will destroy the charger IC and possibly the ESP32-S3 module**. Always verify with a multimeter before first connection: the red wire on the battery plug must align with the **+** marking on the board's silkscreen (Pin 1 = VBAT).

#### Compatible LiPo Battery Options

> **How to read LiPo model numbers:** The model encodes dimensions as XXYYZZ where XX = thickness (×0.1mm), YY = width (mm), ZZ = length (mm). Example: **102050** = 10mm thick × 20mm wide × 50mm long. The Olimex board is 28mm wide, so batteries under 24mm wide fit within the board footprint.

**Tier 1 — Guaranteed Compatible (Olimex direct)**

Olimex's own batteries — same connector, correct polarity, no risk. Buy from [olimex.com](https://www.olimex.com/Products/Power-Supply/Lipo-battery/).

| Battery | Capacity | Dimensions (W × L × T) | Width | Price | Notes |
|---|---|---|---|---|---|
| **BATTERY-LIPO250mAh** | 250 mAh | 21 × 27 × 5 mm | 21 mm | €3.55 | Fits under board width (< 24mm). |
| **BATTERY-LIPO800mAh** | 800 mAh | 30 × 50 × 5 mm | 30 mm | €4.55 | Check stock — sometimes unavailable. |
| **BATTERY-LIPO1400mAh** | 1400 mAh | 34 × 50 × 8 mm | 34 mm | €5.95 | **Best mid-range.** Same footprint as board. |
| **BATTERY-LIPO3000mAh** | 3000 mAh | 45 × 135 × 5 mm | 45 mm | €7.95 | Very long. Good for prototyping. |
| **BATTERY-LIPO4400mAh** | 4400 mAh | 37 × 68 × 18 mm | 37 mm | €8.95 | Highest capacity. Thick. |

All include overcharge + short-circuit protection. Ships from Plovdiv, Bulgaria (3-7 days to Germany).

**Tier 2 — Confirmed Compatible (Adafruit / SparkFun / Pimoroni)**

Same JST PH 2.0mm polarity convention as Olimex. Available through European resellers.

| Battery | Capacity | Dimensions (W × L × T) | Width | Price | Source |
|---|---|---|---|---|---|
| **Pimoroni BAT0002** | 150 mAh | 20.5 × 27 × 4.3 mm | 20.5 mm | ~€3.75 | shop.pimoroni.com |
| **SparkFun PRT-13851** | 400 mAh | 25 × 37 × 5 mm | 25 mm | ~€7.20 | sparkfun.com (no intl. shipping) |
| **Pimoroni BAT0003** | 500 mAh | 30.5 × 37 × 5.3 mm | 30.5 mm | ~€6.75 | shop.pimoroni.com |
| **Adafruit LiPo 1578** | 500 mAh | 26 × 35 × 5 mm | 26 mm | ~€7.20 | adafruit.com / exp-tech.de |
| **SparkFun PRT-13854** | 850 mAh | 35 × 45 × 5 mm | 35 mm | ~€12.30 | sparkfun.com (no intl. shipping) |
| **Pimoroni BAT0004** | 1200 mAh | 35.5 × 64 × 5.3 mm | 35.5 mm | ~€9.70 | shop.pimoroni.com |
| **Adafruit LiPo 328** | 2500 mAh | 50 × 60 × 7.3 mm | 50 mm | ~€13.50 | adafruit.com / exp-tech.de |

**Note:** SparkFun and Adafruit do not ship lithium batteries internationally. Use European resellers like exp-tech.de, The Pi Hut, or Pimoroni for delivery to Germany.

**Tier 3 — Compatible, Verify Polarity (German retailers)**

JST PH 2.0mm connectors but polarity not always documented. **Test with a multimeter before plugging in.**

| Battery | Capacity | Dimensions (W × L × T) | Width | Price | Source |
|---|---|---|---|---|---|
| **BerryBase LP-503035** | 500 mAh | 30 × 35.5 × 5 mm | 30 mm | €5.10 | berrybase.de |
| **Eckstein-Shop LP503035** | 500 mAh | 30 × 35.5 × 5 mm | 30 mm | €5.19 | eckstein-shop.de |
| **BerryBase LP-503562** | 1200 mAh | 36 × 62.5 × 5 mm | 36 mm | €5.50 | berrybase.de |
| **Eckstein-Shop LP503562** | 1200 mAh | 36 × 62.5 × 5 mm | 36 mm | €6.97 | eckstein-shop.de |
| **BerryBase LP-785060** | 2500 mAh | 50 × 60.5 × 7.8 mm | 50 mm | €7.70 | berrybase.de |

**Tier 4 — Narrow Cells (< 24mm wide, fits under the board)**

These are the only 1000+ mAh batteries that fit within the Olimex board's 28mm width. The **102050** cell format is the sweet spot. Most ship with JST PH 2.0mm but **always verify polarity with a multimeter** — Amazon/generic sellers have ~50% chance of reversed wiring.

| Battery | Capacity | Dimensions (W × L × T) | Width | Price | Connector | Source |
|---|---|---|---|---|---|---|
| **102050 (YDL)** | 1000 mAh | 20 × 50 × 10 mm | **20 mm** | ~$2.80 | JST-PH 2.0mm | ydlbattery.com |
| **102050 (AKZYTUE)** | 1000 mAh | 20 × 50 × 10 mm | **20 mm** | ~€8-10 | JST-PH 2.0mm | Amazon (B0GHR4GJK8) |
| **102050 (MakerHawk)** | 1000 mAh | 20 × 50 × 10 mm | **20 mm** | ~€8-12 | JST-PH 2.0mm | Amazon (B0D9K7HQHT) |
| **102050 (Ampul.eu)** | 1000 mAh | 20 × 50 × 10 mm | **20 mm** | €7.18 | Verify before buying | ampul.eu |
| **102060** | 1300 mAh | 20 × 60 × 10 mm | **20 mm** | ~€4-8 | Varies — check listing | eBay (115955049826) |
| **LP102250** | 1200 mAh | 22 × 50 × 10 mm | **22 mm** | ~€5-8 | 3-pin JST (needs swap) | li-polymer-battery.com |

> **Warning — Amazon generics:** Many listings say "Micro JST 2.0" but some ship with **Micro JST 1.25mm** (different connector — does NOT fit). Read each listing description carefully. The YDL and AKZYTUE listings explicitly confirm 2.0mm pitch.

**Tier 5 — HIGH RISK (unbranded Amazon / AliExpress)**

| Battery | Capacity | Dimensions (W × L × T) | Width | Price | Risk |
|---|---|---|---|---|---|
| Generic "3.7V LiPo JST PH" | 1000-3000 mAh | Varies wildly | 20-60 mm | €5-12 | **~50% polarity reversal, dimensions often wrong** |

To swap reversed JST PH pins: use a fine needle to lift the locking tab on each pin inside the housing, pull the wire out, and reinsert in the correct order.

#### All Batteries — Master Size Comparison

Sorted by width (narrowest first). **Bold** = fits under the board (< 24mm wide).

| Battery | mAh | Width | Length | Thick | Fits < 24mm? | Price | Polarity |
|---|-----|---|---|---|---|---|---|
| **102050 (any brand)** | **1000** | **20 mm** | **50 mm** | **10 mm** | **YES** | **€3-10** | **Verify** |
| **102060** | **1300** | **20 mm** | **60 mm** | **10 mm** | **YES** | **€4-8** | **Verify** |
| Pimoroni BAT0002 | 150 | 20.5 mm | 27 mm | 4.3 mm | **YES** | ~€3.75 | Confirmed |
| Olimex 250mAh | 250 | 21 mm | 27 mm | 5 mm | **YES** | €3.55 | Guaranteed |
| **LP102250** | **1200** | **22 mm** | **50 mm** | **10 mm** | **YES** | **€5-8** | **Verify** |
| SparkFun PRT-13851 | 400 | 25 mm | 37 mm | 5 mm | No | ~€7.20 | Confirmed |
| Adafruit LiPo 1578 | 500 | 26 mm | 35 mm | 5 mm | No | ~€7.20 | Confirmed |
| Olimex 800mAh | 800 | 30 mm | 50 mm | 5 mm | No | €4.55 | Guaranteed |
| BerryBase LP-503035 | 500 | 30 mm | 35.5 mm | 5 mm | No | €5.10 | Verify |
| Pimoroni BAT0003 | 500 | 30.5 mm | 37 mm | 5.3 mm | No | ~€6.75 | Confirmed |
| Olimex 1400mAh | 1400 | 34 mm | 50 mm | 8 mm | No | €5.95 | Guaranteed |
| SparkFun PRT-13854 | 850 | 35 mm | 45 mm | 5 mm | No | ~€12.30 | Confirmed |
| Pimoroni BAT0004 | 1200 | 35.5 mm | 64 mm | 5.3 mm | No | ~€9.70 | Confirmed |
| BerryBase LP-503562 | 1200 | 36 mm | 62.5 mm | 5 mm | No | €5.50 | Verify |
| Eckstein LP503562 | 1200 | 36 mm | 62.5 mm | 5 mm | No | €6.97 | Verify |
| Olimex 4400mAh | 4400 | 37 mm | 68 mm | 18 mm | No | €8.95 | Guaranteed |
| Olimex 3000mAh | 3000 | 45 mm | 135 mm | 5 mm | No | €7.95 | Guaranteed |
| BerryBase LP-785060 | 2500 | 50 mm | 60.5 mm | 7.8 mm | No | €7.70 | Verify |
| Adafruit LiPo 328 | 2500 | 50 mm | 60 mm | 7.3 mm | No | ~€13.50 | Confirmed |

#### Recommended Battery for Dilder Prototyping

**Best narrow fit (< 24mm wide): 102050 cell — 1000 mAh (20 × 50 × 10 mm)**
- Fits under the Olimex board with 4mm clearance per side
- 1000 mAh = ~10+ hours of Dilder runtime (display + joystick, no WiFi)
- JST PH 2.0mm connector on most listings — plugs straight in
- Buy from YDL Battery ($2.80 direct) or Amazon (€8-10 with Prime)
- **Always verify polarity with a multimeter before connecting**

**Best guaranteed-safe pick: Olimex BATTERY-LIPO1400mAh (€5.95)**
- No polarity risk — guaranteed compatible
- 1400 mAh, 34 × 50 × 8 mm (wider than the board but fine for breadboard prototyping)
- Ships from the same company that makes the board
- At 100 mA charge rate, full charge takes ~14 hours (upgrade R4 to 2k for ~500 mA / 3-hour charge)

### 1.6 Power Architecture

ESP32-S3 DevKit System Block Diagram

*System block diagram (Espressif DevKitC-1 — same architecture as the Olimex board). Source: Espressif.*

```
USB-OTG (5V) ──D3──┐
                    ├──> +5V rail ──> SY8089AAAC ──> 3.3V rail ──> ESP32-S3 + peripherals
USB-UART (5V) ─D1──┘                                   │
                                                    BL4054B ──> LiPo Battery
LiPo Battery ──D2──> P-FET ──> SY8089 input            │
                       │                            (charges when USB connected)
                    (FET OFF when USB present,
                     FET ON when on battery)
```

When USB is connected, the P-MOSFET disconnects the battery from the power path and the charger tops it up. When USB is removed, the FET conducts and the battery powers everything through the buck regulator.

### 1.7 pUEXT Connector

The board has a 10-pin JST SH 1.0mm pitch connector (pUEXT) that breaks out UART, I2C, and SPI:

| Pin | Signal | GPIO | Notes |
|-----|---|---|---|
| 0 | GND | — | |
| 1 | 3.3V | — | |
| 2 | GND | — | |
| 3 | UART1 TX | GPIO17 | |
| 4 | UART1 RX | GPIO18 | |
| 5 | I2C SCL | GPIO47 | 2.2k pull-up to 3.3V on board |
| 6 | I2C SDA | GPIO48 | 2.2k pull-up to 3.3V on board |
| 7 | SPI MISO | GPIO13 | |
| 8 | SPI MOSI | GPIO11 | |
| 9 | SPI CLK | GPIO12 | |
| 10 | SPI CS0 | GPIO10 | 10k pull-up to 3.3V on board |

This connector is compatible with Olimex UEXT breakout modules. The I2C lines on GPIO47/48 already have 2.2k pull-ups on the board, so **no external pull-ups are needed if you use these pins for I2C**.

---

## 2. Full GPIO Pinout

> **Note:** The Olimex board's header pinout is fully compatible with the Espressif ESP32-S3-DevKitC-1. The Espressif pinout diagram below is an accurate reference for the GPIO assignments on both boards.

ESP32-S3-DevKitC-1 Pinout Diagram

*ESP32-S3-DevKitC-1 pinout (compatible with Olimex ESP32-S3-DevKit-Lipo headers). Source: Espressif.*

> **Tip:** Flip your Olimex board over — every pin is labeled on the bottom silkscreen (see photo in Section 1.2).

### 2.1 Header EXT1 (Left Side) — 22 Pins

| EXT1 Pin | Signal | ESP32-S3 GPIO | Notes |
|---|---|---|---|
| 1 | 3.3V | — | Regulated 3.3V output |
| 2 | 3.3V | — | Regulated 3.3V output |
| 3 | ESP_EN | EN | Reset (10k pull-up, 1µF cap) |
| 4 | GPIO4 | Pin 4 | **Free** — ADC1_CH3, Touch4 |
| 5 | GPIO5 | Pin 5 | External power sense (220k/470k divider from 5V) |
| 6 | GPIO6 | Pin 6 | Battery voltage sense (470k/150k divider from VBAT) |
| 7 | GPIO7 | Pin 7 | **Free** — ADC1_CH6, Touch7 |
| 8 | GPIO15 | Pin 8 | **Free** — ADC2_CH4 |
| 9 | GPIO16 | Pin 9 | **Free** — ADC2_CH5 |
| 10 | GPIO17 | Pin 10 | UART1 TX, shared with pUEXT pin 3 |
| 11 | GPIO18 | Pin 11 | UART1 RX, shared with pUEXT pin 4 |
| 12 | GPIO8 | Pin 12 | **Free** — ADC1_CH7, Touch8 |
| 13 | GPIO3 | Pin 15 | **Strapping pin** (10k pull-up R18). Safe for output after boot. |
| 14 | GPIO46 | Pin 16 | **Strapping pin**. Safe for output after boot. |
| 15 | GPIO9 | Pin 17 | **Free** — ADC1_CH8, Touch9 |
| 16 | GPIO10 | Pin 18 | SPI CS, shared with pUEXT (10k pull-up) |
| 17 | GPIO11 | Pin 19 | SPI MOSI, shared with pUEXT |
| 18 | GPIO12 | Pin 20 | SPI CLK, shared with pUEXT |
| 19 | GPIO13 | Pin 21 | SPI MISO, shared with pUEXT |
| 20 | GPIO14 | Pin 22 | **Free** — ADC2_CH3, Touch14 |
| 21 | +5V | — | 5V from USB (through Schottky diode) |
| 22 | GND | — | Ground |

### 2.2 Header EXT2 (Right Side) — 22 Pins

| EXT2 Pin | Signal | ESP32-S3 GPIO | Notes |
|---|---|---|---|
| 1 | GND | — | Ground |
| 2 | GPIO43 | Pin 37 | UART0 TX — connected to CH340X |
| 3 | GPIO44 | Pin 36 | UART0 RX — connected to CH340X |
| 4 | GPIO1 | Pin 39 | **Free** — ADC1_CH0, Touch1 |
| 5 | GPIO2 | Pin 38 | **Free** — ADC1_CH1, Touch2 |
| 6 | GPIO42 | Pin 35 | **Free** — MTMS |
| 7 | GPIO41 | Pin 34 | **Free** — MTDI |
| 8 | GPIO40 | Pin 33 | **Free** — MTDO |
| 9 | GPIO39 | Pin 32 | **Free** — MTCK |
| 10 | GPIO38 | Pin 31 | **On-board green LED (active LOW via 2.2k to 3.3V)** |
| 11 | GPIO37 | Pin 30 | **DO NOT USE** — Octal PSRAM SPIIO6 |
| 12 | GPIO36 | Pin 29 | **DO NOT USE** — Octal PSRAM SPIIO5 |
| 13 | GPIO35 | Pin 28 | **DO NOT USE** — Octal PSRAM SPIIO4 |
| 14 | GPIO0 | Pin 27 | **Strapping pin** — BOOT button, boot mode select |
| 15 | GPIO45 | Pin 26 | **Strapping pin** — VDD_SPI voltage select |
| 16 | GPIO48 | Pin 25 | I2C SDA, shared with pUEXT (2.2k pull-up on board) |
| 17 | GPIO47 | Pin 24 | I2C SCL, shared with pUEXT (2.2k pull-up on board) |
| 18 | GPIO21 | Pin 23 | **Free** |
| 19 | GPIO20 | Pin 14 | **Native USB D+** — wired to USB-OTG port |
| 20 | GPIO19 | Pin 13 | **Native USB D-** — wired to USB-OTG port |
| 21 | GND | — | Ground |
| 22 | GND | — | Ground |

### 2.3 GPIO Restrictions and Warnings

**DO NOT USE — Reserved for internal PSRAM (N8R8 Octal):**

| GPIO | Reason | Header Location |
|---|---|---|
| GPIO35 | PSRAM SPIIO4 | EXT2 pin 13 |
| GPIO36 | PSRAM SPIIO5 | EXT2 pin 12 |
| GPIO37 | PSRAM SPIIO6 | EXT2 pin 11 |

These are broken out on the header but connecting anything to them **will break PSRAM operation**. Treat them as off-limits.

**Use with awareness — On-board peripherals connected:**

| GPIO | Connection | Still usable? |
|---|---|---|
| GPIO5 | 220k/470k voltage divider from 5V rail | Yes — reads external power. Cannot use as digital output. |
| GPIO6 | 470k/150k voltage divider from VBAT | Yes — reads battery voltage. Cannot use as digital output. |
| GPIO38 | Green LED (2.2k to 3.3V, active LOW) | Yes — LED reflects pin state. |
| GPIO19 | USB D- (wired to USB-OTG connector) | Lose USB-OTG/JTAG if repurposed. |
| GPIO20 | USB D+ (wired to USB-OTG connector) | Lose USB-OTG/JTAG if repurposed. |
| GPIO43 | UART0 TX (wired to CH340X) | Lose serial console if repurposed. |
| GPIO44 | UART0 RX (wired to CH340X) | Lose serial console if repurposed. |

### 2.4 Freely Available GPIO Pins

These have NO on-board connections (just header breakout):

| GPIO | ADC | Touch | Header Pin |
|---|-----|---|---|
| GPIO1 | ADC1_CH0 | Touch1 | EXT2 pin 4 |
| GPIO2 | ADC1_CH1 | Touch2 | EXT2 pin 5 |
| GPIO4 | ADC1_CH3 | Touch4 | EXT1 pin 4 |
| GPIO7 | ADC1_CH6 | Touch7 | EXT1 pin 7 |
| GPIO8 | ADC1_CH7 | Touch8 | EXT1 pin 12 |
| GPIO9 | ADC1_CH8 | Touch9 | EXT1 pin 15 |
| GPIO14 | ADC2_CH3 | Touch14 | EXT1 pin 20 |
| GPIO15 | ADC2_CH4 | — | EXT1 pin 8 |
| GPIO16 | ADC2_CH5 | — | EXT1 pin 9 |
| GPIO21 | — | — | EXT2 pin 18 |
| GPIO39 | — | — | EXT2 pin 9 |
| GPIO40 | — | — | EXT2 pin 8 |
| GPIO41 | — | — | EXT2 pin 7 |
| GPIO42 | — | — | EXT2 pin 6 |

That's **14 completely free GPIO pins** — more than enough for the Dilder peripherals.

### 2.5 Strapping Pins

These GPIOs have special boot-time functions. External circuits should not force them to unexpected states during power-on.

| GPIO | Boot Function | Board State | Safe for Dilder? |
|---|---|---|---|
| GPIO0 | Boot mode select | Internal pull-up. BOOT button pulls LOW. | **Avoid** — used for BOOT button |
| GPIO3 | JTAG signal source | 10k pull-up (R18) | **Yes** — output after boot is fine |
| GPIO45 | VDD_SPI voltage select | Internal pull-down (3.3V SPI) | **Avoid** — don't connect |
| GPIO46 | ROM debug messages | Internal pull-down | **Yes** — output after boot is fine |

---

## 3. Parts You Already Have

Based on the Dilder hardware design plan and breadboard prototype guide:

| # | Part | Model | Interface | Source | Status |
|---|---|---|---|---|---|
| 1 | **ESP32-S3 Dev Board** | Olimex ESP32-S3-DevKit-Lipo | — | Olimex.com | **Just received** (4 pcs) |
| 2 | **e-Ink Display** | Waveshare 2.13" e-Paper HAT V3 | SPI (SSD1680) | Previously purchased | **In hand** |
| 3 | **5-Way Joystick** | DollaTek 5D Navigation Module | GPIO (active LOW) | Amazon B07HBPW3DF | **In hand** (from Pico prototype) |
| 4 | **Breadboard** | 830 tie-point full-size | — | — | Should have from Pico build |
| 5 | **Jumper Wires** | M-M and F-M assortment | — | — | Should have from Pico build |

**What you might still need:**

| Part | Purpose | Price | Notes |
|---|---|---|---|
| LiPo battery (JST PH 2.0mm) | Battery power | €3.55-8.95 | See [Compatible LiPo Battery Options](#compatible-lipo-battery-options) — recommended: **Olimex BATTERY-LIPO1400mAh** (€5.95) |
| USB-C cable (data, not charge-only) | Upload and serial | ~€3-5 | Must be a data cable, not charge-only |

---

## 4. GPIO Assignment for Dilder

### 4.1 Pin Mapping Table

These assignments match the Dilder custom PCB design where possible, adapted for the Olimex board's pin restrictions. **GPIO5 and GPIO6 are NOT used for joystick** on the Olimex (unlike the breadboard prototype guide for the generic board) because they have voltage dividers connected.

| Peripheral | Signal | ESP32-S3 GPIO | EXT Pin | Direction | Notes |
|---|---|---|---|---|---|
| **e-Paper** | CLK (SCLK) | GPIO12 | EXT1-18 | Out | SPI bus clock |
| | DIN (MOSI) | GPIO11 | EXT1-17 | Out | SPI data |
| | CS | GPIO10 | EXT1-16 | Out | Active LOW chip select (10k pull-up on board) |
| | DC | GPIO9 | EXT1-15 | Out | Data/Command select |
| | RST | GPIO3 | EXT1-13 | Out | Active LOW reset (strapping pin — safe after boot) |
| | BUSY | GPIO8 | EXT1-12 | In | HIGH = display busy |
| | VCC | 3.3V | EXT1-1 | Power | |
| | GND | GND | EXT1-22 | Ground | |
| **Joystick** | UP | GPIO4 | EXT1-4 | In (pull-up) | Active LOW |
| | DOWN | GPIO7 | EXT1-7 | In (pull-up) | Active LOW |
| | LEFT | GPIO1 | EXT2-4 | In (pull-up) | Active LOW |
| | RIGHT | GPIO2 | EXT2-5 | In (pull-up) | Active LOW |
| | CENTER | GPIO15 | EXT1-8 | In (pull-up) | Active LOW |
| | COM/GND | GND | EXT1-22 | Ground | |
| **Board** | LED | GPIO38 | EXT2-10 | Out | Active LOW (on-board green LED) |
| | BOOT btn | GPIO0 | EXT2-14 | In | User button during runtime |
| | BAT sense | GPIO6 | EXT1-6 | ADC In | Battery voltage × 4.133 |
| | PWR sense | GPIO5 | EXT1-5 | ADC In | USB power detection × 1.468 |

**Total GPIO used:** 13 (6 display + 5 joystick + LED + BOOT button)
**Remaining free:** GPIO14, GPIO16, GPIO17, GPIO18, GPIO21, GPIO39-42, GPIO46-48 (12+ pins for future sensors)

### 4.2 Bus Summary Diagram

```
                    Olimex ESP32-S3-DevKit-Lipo
                   ┌─────────────────────────┐
                   │                         │
   SPI (FSPI) ────┤ GPIO12 (CLK)            │
                   │ GPIO11 (MOSI)           ├──────── Waveshare 2.13" e-Paper V3
                   │ GPIO10 (CS)             │         (SSD1680, 250×122)
                   │ GPIO9  (DC)             │
                   │ GPIO3  (RST)            │
                   │ GPIO8  (BUSY)           │
                   │                         │
   GPIO ──────────┤ GPIO4  (UP)             │
                   │ GPIO7  (DOWN)           ├──────── 5-Way Joystick
                   │ GPIO1  (LEFT)           │         (DollaTek module)
                   │ GPIO2  (RIGHT)          │
                   │ GPIO15 (CENTER)         │
                   │                         │
   On-board ──────┤ GPIO38 (LED)            │
                   │ GPIO0  (BOOT btn)       │
                   │ GPIO6  (BAT ADC)        │
                   │ GPIO5  (PWR ADC)        │
                   │                         │
   Reserved ──────┤ GPIO47 (I2C SCL) ───────┤──── Future: Accelerometer, SHT40
   (for later)     │ GPIO48 (I2C SDA) ───────┤──── (pull-ups already on board)
                   │                         │
                   │ 3V3 ────────────────────┼──── 3.3V to all peripherals
                   │ GND ────────────────────┼──── Common ground
                   └─────────────────────────┘
```

**Why these specific pins?**
- **SPI on GPIO10-12:** These are the default FSPI (SPI3) pins with hardware SPI support and already on the pUEXT connector. Using hardware SPI is faster and frees the CPU.
- **GPIO9 for DC, GPIO3 for RST, GPIO8 for BUSY:** Free pins close to the SPI cluster on EXT1 header, keeping wiring clean.
- **GPIO10 for CS:** Has a 10k pull-up on the board already — ideal for chip-select which is active LOW.
- **Joystick on GPIO1, 2, 4, 7, 15:** All completely free pins with no board-level connections. Avoids GPIO5/6 (voltage dividers) and GPIO0 (boot button).
- **I2C reserved on GPIO47/48:** These already have 2.2k pull-ups on the board. When you add the accelerometer and SHT40 later, no external pull-up resistors needed.

---

## 5. Breadboard Wiring — Step by Step

### 5.1 What You Need

- [ ] Olimex ESP32-S3-DevKit-Lipo (1 of your 4 units)
- [ ] Waveshare 2.13" e-Paper HAT V3
- [ ] DollaTek 5-way joystick module
- [ ] Full-size breadboard (830 tie points)
- [ ] Jumper wires: ~8 male-to-male, ~8 female-to-male
- [ ] USB-C data cable (for the USB-UART port)

### 5.2 Phase 1 — Board on Breadboard

1. **Orient the board** with the USB ports facing up (away from you).
2. **Place the Olimex board** straddling the center channel of the breadboard. The 22-pin headers on each side should drop into the breadboard rows.
3. **Note:** The board is narrow (27.94mm) so it fits cleanly across the center channel with access to both pin rows.
4. **Connect power rails:**
   - Run a jumper from **EXT1 pin 1 (3.3V)** to the breadboard's **+** power rail.
   - Run a jumper from **EXT1 pin 22 (GND)** to the breadboard's **−** ground rail.
   - Bridge the ground rail to the other side if your breadboard has split rails.
5. **Plug in the USB-C cable** to the **USB-UART port** (the one near the buttons, with the CH340X chip).
6. The green LED may blink or stay on depending on what firmware is loaded. If the board is new, it should be running a factory demo.

### 5.3 Phase 2 — Wire the Joystick

The DollaTek 5-way module is a passive switch-to-ground device. Each direction connects its pin to COM (ground) when pressed. We enable internal pull-ups in software.

**Wiring (use male-to-male jumper wires):**

| Joystick Pin | → | Breadboard Row → ESP32 GPIO | EXT Pin |
|---|---|---|---|
| COM / GND | → | Ground rail (−) | — |
| UP | → | GPIO4 row | EXT1 pin 4 |
| DOWN | → | GPIO7 row | EXT1 pin 7 |
| LEFT | → | GPIO1 row | EXT2 pin 4 |
| RIGHT | → | GPIO2 row | EXT2 pin 5 |
| CENTER / SET | → | GPIO15 row | EXT1 pin 8 |
| VCC (if present) | → | Leave unconnected | — |

**Tips:**
- Check your module's silkscreen — the pin labels vary between batches (SET/MID/CENTER, COM/GND).
- If the module has a VCC pin, leave it disconnected.
- Use color-coded wires: Black=GND, Red=UP, Blue=DOWN, Yellow=LEFT, Green=RIGHT, White=CENTER.

### 5.4 Phase 3 — Wire the e-Paper Display

The Waveshare 2.13" HAT has an 8-pin header on the edge labeled: VCC, GND, DIN, CLK, CS, DC, RST, BUSY. Use **female-to-male jumper wires** (female end onto the HAT header, male end into the breadboard).

**Wiring:**

| Display Pin | Function | → | ESP32 GPIO | EXT Pin |
|---|---|---|---|---|
| VCC | 3.3V power | → | 3.3V rail (+) | EXT1 pin 1/2 |
| GND | Ground | → | Ground rail (−) | EXT1 pin 22 |
| DIN | SPI MOSI | → | GPIO11 | EXT1 pin 17 |
| CLK | SPI Clock | → | GPIO12 | EXT1 pin 18 |
| CS | Chip Select | → | GPIO10 | EXT1 pin 16 |
| DC | Data/Command | → | GPIO9 | EXT1 pin 15 |
| RST | Reset | → | GPIO3 | EXT1 pin 13 |
| BUSY | Busy flag | → | GPIO8 | EXT1 pin 12 |

**SPI protocol settings:**
- Mode: 0 (CPOL=0, CPHA=0)
- Bit order: MSB first
- Clock speed: 4 MHz (safe default; can go up to 10 MHz)

### 5.5 Master Wiring Diagram

```
DollaTek Joystick                     Olimex ESP32-S3-DevKit-Lipo                   Waveshare e-Paper V3
┌──────────────┐                     ┌────── USB-UART ──────┐                      ┌──────────────┐
│              │                     │      (upload here)    │                      │              │
│  COM ────────┼──── GND rail ──────┤ GND              3.3V ├──── + rail ──────────┤ VCC          │
│              │                     │                       │                      │              │
│  UP  ────────┼────────────────────┤ GPIO4 (EXT1-4)        │          GND rail ───┤ GND          │
│              │                     │                       │                      │              │
│  DOWN ───────┼────────────────────┤ GPIO7 (EXT1-7)        │                      │              │
│              │                     │                       │                      │              │
│  LEFT ───────┼────────────────────┤ GPIO1 (EXT2-4)        │      GPIO11 ─────────┤ DIN (MOSI)   │
│              │                     │                       │                      │              │
│  RIGHT ──────┼────────────────────┤ GPIO2 (EXT2-5)        │      GPIO12 ─────────┤ CLK (SCLK)   │
│              │                     │                       │                      │              │
│  CENTER ─────┼────────────────────┤ GPIO15 (EXT1-8)       │      GPIO10 ─────────┤ CS           │
│              │                     │                       │                      │              │
│  (VCC — NC)  │                     │              GPIO9  ──┼─────────────────────┤ DC           │
│              │                     │                       │                      │              │
└──────────────┘                     │              GPIO3  ──┼─────────────────────┤ RST          │
                                     │                       │                      │              │
                                     │              GPIO8  ──┼─────────────────────┤ BUSY         │
                                     │                       │                      │              │
                                     │       GPIO38 ── LED (onboard)               └──────────────┘
                                     │       GPIO0  ── BOOT button (onboard)
                                     │       GPIO6  ── Battery ADC (onboard)
                                     │       GPIO5  ── Power detect (onboard)
                                     │                       │
                                     └───────────────────────┘
```

### 5.6 Wiring Checklist

Before powering on, verify:

- [ ] **No shorts** — no signal wires touch each other or ground
- [ ] **Correct power** — display VCC goes to 3.3V rail, NOT 5V
- [ ] **GND connected** — joystick COM, display GND, and board GND are all on the same ground rail
- [ ] **Display cable** — the FPC ribbon cable from the display panel to the HAT board is seated properly (fragile!)
- [ ] **Right USB port** — cable is in the USB-UART port (near the buttons), not USB-OTG
- [ ] **No VCC on joystick** — if the module has a VCC pin, leave it floating
- [ ] **SPI wires correct** — DIN→GPIO11, CLK→GPIO12, CS→GPIO10 (double-check, swapped SPI wires produce no output)

---

## 6. VSCode + PlatformIO Setup

### 6.1 Install PlatformIO

1. Open **VSCode**.
2. Go to the **Extensions** panel (Ctrl+Shift+X).
3. Search for **"PlatformIO IDE"** and install it.
4. Wait for PlatformIO to finish installing its core tools (this takes a few minutes on first install). You'll see progress in the bottom status bar.
5. Restart VSCode when prompted.

**Verify installation:** Open the PlatformIO sidebar (alien icon in the left bar) → should show "PIO Home" tab.

### 6.2 Create the Project

**Option A — From PlatformIO Home (GUI):**

1. Click the PlatformIO alien icon → **"+ New Project"**
2. Name: `dilder-esp32`
3. Board: **"Espressif ESP32-S3-DevKitC-1"** (search for "S3-DevKitC")
4. Framework: **Arduino**
5. Location: Inside your Dilder project at `ESP Protyping/dilder-esp32/`
6. Click **"Finish"**

**Option B — From terminal:**

```bash
mkdir -p "ESP Protyping/dilder-esp32"
cd "ESP Protyping/dilder-esp32"
pio project init --board esp32-s3-devkitc-1 --project-option "framework=arduino"
```

### 6.3 Configure platformio.ini

Replace the generated `platformio.ini` with this Olimex-specific configuration:

```ini
[env:olimex-esp32s3-devkit-lipo]
platform = espressif32
board = esp32-s3-devkitc-1
framework = arduino
monitor_speed = 115200

; ── Olimex ESP32-S3-DevKit-Lipo specific settings ──
build_flags =
    -DARDUINO_USB_CDC_ON_BOOT=1    ; Enable serial over USB-OTG port too
    -DBOARD_HAS_PSRAM              ; Board has 8MB octal PSRAM

board_build.psram = enabled        ; Enable PSRAM in the build
board_build.arduino.memory_type = qio_opi  ; QIO flash + OPI PSRAM

; ── Upload settings ──
; Use USB-UART port (CH340X) for upload — it has auto-reset
upload_speed = 460800
upload_port = /dev/ttyUSB0         ; Adjust if your port differs

; ── Monitor settings ──
monitor_port = /dev/ttyUSB0        ; Same port for serial monitor
monitor_filters = esp32_exception_decoder  ; Decode crash backtraces

; ── Library dependencies ──
lib_deps =
    ; Add libraries here as you need them, e.g.:
    ; zinggjm/GxEPD2@^1.5.0       ; e-Paper display library
```

**Key flags explained:**

| Flag | Why |
|---|-----|
| `ARDUINO_USB_CDC_ON_BOOT=1` | Enables USB CDC serial output on the USB-OTG port. Without this, `Serial.print()` only works through the CH340X UART port. |
| `BOARD_HAS_PSRAM` | Tells the Arduino core that PSRAM is available. Some libraries check this flag. |
| `board_build.psram = enabled` | Enables PSRAM initialization at boot. The 8MB PSRAM shows up in `ESP.getPsramSize()`. |
| `qio_opi` | Sets the memory access mode: QIO (Quad I/O) for flash, OPI (Octal) for PSRAM. Must match the N8R8 module. |

### 6.4 USB Driver Setup (Linux)

The CH340X USB-to-serial chip is supported by the `ch341` kernel module, which is built into most Linux distributions (including CachyOS).

**Check if the board is detected:**

```bash
# Plug in the USB-UART port, then:
dmesg | tail -20
# Should show: "ch341-uart converter now attached to ttyUSB0"

# Or check for the device:
ls -la /dev/ttyUSB*
```

**If you get permission denied:**

```bash
# Add your user to the dialout group (one-time)
sudo usermod -a -G dialout $USER

# Log out and back in (or reboot) for the group change to take effect
```

**If using the USB-OTG port instead:**

```bash
# The native USB shows up as ttyACM0
ls -la /dev/ttyACM*
```

### 6.5 First Upload — Blink Test

Create `src/main.cpp` with this minimal blink sketch to verify your toolchain:

```cpp
#include <Arduino.h>

// Olimex ESP32-S3-DevKit-Lipo onboard LED
// Active LOW: LOW = ON, HIGH = OFF
#define LED_PIN 38

void setup() {
    Serial.begin(115200);

    // Wait for USB CDC serial (up to 3 seconds)
    unsigned long start = millis();
    while (!Serial && millis() - start < 3000) {
        delay(10);
    }

    pinMode(LED_PIN, OUTPUT);
    Serial.println("Olimex ESP32-S3-DevKit-Lipo — Blink Test");
    Serial.printf("Flash: %u MB\n", ESP.getFlashChipSize() / (1024 * 1024));
    Serial.printf("PSRAM: %u bytes\n", ESP.getPsramSize());
}

void loop() {
    digitalWrite(LED_PIN, LOW);   // LED ON
    Serial.println("LED ON");
    delay(500);

    digitalWrite(LED_PIN, HIGH);  // LED OFF
    Serial.println("LED OFF");
    delay(500);
}
```

**Upload from VSCode:**

1. Click the **→ (Upload)** button in the PlatformIO toolbar (bottom bar), or press **Ctrl+Alt+U**.
2. PlatformIO compiles the code, detects the board on `/dev/ttyUSB0`, and uploads.
3. The green LED should start blinking at 1 Hz.
4. Click the **plug icon (Serial Monitor)** in the PlatformIO toolbar, or press **Ctrl+Alt+S**.
5. You should see "LED ON" / "LED OFF" alternating in the terminal.

**If upload fails:** See Section 8.4 (Troubleshooting).

---

## 7. Test Sketches

### 7.1 Chip Info Sketch

Dumps full chip/memory information to verify the board is working correctly:

```cpp
#include <Arduino.h>

void printChipInfo() {
    Serial.printf("\n[Uptime: %lu seconds]\n", millis() / 1000);
    Serial.println("=== ESP32-S3 Chip Information ===");
    Serial.printf("Chip model: %s\n", ESP.getChipModel());
    Serial.printf("Chip revision: %d\n", ESP.getChipRevision());
    Serial.printf("Chip cores: %d\n", ESP.getChipCores());
    Serial.printf("CPU frequency: %d MHz\n", ESP.getCpuFreqMHz());
    Serial.printf("Flash size: %u MB\n", ESP.getFlashChipSize() / (1024 * 1024));
    Serial.printf("Flash speed: %u MHz\n", ESP.getFlashChipSpeed() / 1000000);
    Serial.printf("Heap size: %u bytes\n", ESP.getHeapSize());
    Serial.printf("Free heap: %u bytes\n", ESP.getFreeHeap());

    if (ESP.getPsramSize() > 0) {
        Serial.printf("PSRAM size: %u bytes (%u MB)\n",
                      ESP.getPsramSize(), ESP.getPsramSize() / (1024 * 1024));
        Serial.printf("Free PSRAM: %u bytes\n", ESP.getFreePsram());
    } else {
        Serial.println("WARNING: No PSRAM detected! Check board_build.psram = enabled");
    }

    uint64_t chipid = ESP.getEfuseMac();
    Serial.printf("Chip ID (MAC): %04X%08X\n",
                  (uint16_t)(chipid >> 32), (uint32_t)chipid);
    Serial.println("================================\n");
}

void setup() {
    Serial.begin(115200);
    unsigned long start = millis();
    while (!Serial && millis() - start < 5000) delay(10);
    delay(200);
    printChipInfo();
}

void loop() {
    delay(30000);
    printChipInfo();
}
```

**Expected output:**

```
=== ESP32-S3 Chip Information ===
Chip model: ESP32-S3
Chip revision: 0
Chip cores: 2
CPU frequency: 240 MHz
Flash size: 8 MB
Flash speed: 80 MHz
PSRAM size: 8388608 bytes (8 MB)
...
```

If PSRAM shows 0, double-check your `platformio.ini` has `board_build.psram = enabled` and `board_build.arduino.memory_type = qio_opi`.

### 7.2 Battery Monitor Sketch

Reads battery voltage and external power status using the on-board voltage dividers:

```cpp
#include <Arduino.h>

#define LED_PIN        38
#define BAT_ADC_PIN    6
#define PWR_ADC_PIN    5

#define BAT_DIVIDER_RATIO  4.1333   // (470k + 150k) / 150k
#define PWR_THRESHOLD_MV   400      // Above this = USB power present

void setup() {
    Serial.begin(115200);
    unsigned long start = millis();
    while (!Serial && millis() - start < 3000) delay(10);

    analogReadResolution(12);
    pinMode(LED_PIN, OUTPUT);
    Serial.println("Battery Monitor Started");
}

void loop() {
    // Read battery voltage
    uint32_t batRaw = analogRead(BAT_ADC_PIN);
    float batVoltage = (batRaw / 4095.0) * 3.3 * BAT_DIVIDER_RATIO;

    // Read external power
    uint32_t pwrRaw = analogRead(PWR_ADC_PIN);
    float pwrMv = (pwrRaw / 4095.0) * 3300.0;
    bool usbPower = (pwrMv > PWR_THRESHOLD_MV);

    Serial.printf("Battery: %.3f V | USB Power: %s\n",
                  batVoltage, usbPower ? "PRESENT" : "NOT PRESENT");

    // LED on when USB power is present
    digitalWrite(LED_PIN, usbPower ? LOW : HIGH);

    delay(2000);
}
```

### 7.3 Joystick Test Sketch

Tests all 5 directions with the adapted GPIO pins:

```cpp
#include <Arduino.h>

// Olimex GPIO assignments (avoiding GPIO5/6 voltage dividers)
#define BTN_UP      4
#define BTN_DOWN    7
#define BTN_LEFT    1
#define BTN_RIGHT   2
#define BTN_CENTER  15

const uint8_t buttons[] = {BTN_UP, BTN_DOWN, BTN_LEFT, BTN_RIGHT, BTN_CENTER};
const char* names[]      = {"UP", "DOWN", "LEFT", "RIGHT", "CENTER"};

void setup() {
    Serial.begin(115200);
    unsigned long start = millis();
    while (!Serial && millis() - start < 3000) delay(10);

    for (int i = 0; i < 5; i++) {
        pinMode(buttons[i], INPUT_PULLUP);
    }

    Serial.println("=== Joystick Test ===");
    Serial.println("Press any direction...\n");
}

void loop() {
    for (int i = 0; i < 5; i++) {
        if (digitalRead(buttons[i]) == LOW) {
            Serial.printf("[PRESSED] %s (GPIO%d)\n", names[i], buttons[i]);
        }
    }
    delay(100);
}
```

**Expected output when pressing each direction:**

```
=== Joystick Test ===
Press any direction...

[PRESSED] UP (GPIO4)
[PRESSED] DOWN (GPIO7)
[PRESSED] LEFT (GPIO1)
[PRESSED] RIGHT (GPIO2)
[PRESSED] CENTER (GPIO15)
```

### 7.4 e-Paper Display Test Sketch

Uses the GxEPD2 library to drive the Waveshare 2.13" V3 display.

**First, add the library to `platformio.ini`:**

```ini
lib_deps =
    zinggjm/GxEPD2@^1.5.0
    adafruit/Adafruit GFX Library@^1.11.0
```

**Then create the test sketch:**

```cpp
#include <Arduino.h>
#include <GxEPD2_BW.h>

// ── Pin definitions for Olimex ESP32-S3-DevKit-Lipo ──
#define EPD_CS    10
#define EPD_DC     9
#define EPD_RST    3
#define EPD_BUSY   8
#define EPD_CLK   12
#define EPD_MOSI  11

// Waveshare 2.13" V3 (SSD1680, 250x122)
// GxEPD2 class: GxEPD2_213_BN (for SSD1680-based 2.13" displays)
GxEPD2_BW<GxEPD2_213_BN, GxEPD2_213_BN::HEIGHT>
    display(GxEPD2_213_BN(EPD_CS, EPD_DC, EPD_RST, EPD_BUSY));

void setup() {
    Serial.begin(115200);
    unsigned long start = millis();
    while (!Serial && millis() - start < 3000) delay(10);
    Serial.println("e-Paper Display Test");

    // Initialize SPI with custom pins
    SPI.begin(EPD_CLK, -1, EPD_MOSI, EPD_CS);  // CLK, MISO (none), MOSI, CS

    display.init(115200);  // Debug output at 115200

    // Full window mode
    display.setRotation(1);  // Landscape
    display.setTextColor(GxEPD2_BW<GxEPD2_213_BN, GxEPD2_213_BN::HEIGHT>::BLACK);
    display.setTextSize(2);

    display.setFullWindow();
    display.firstPage();
    do {
        display.fillScreen(GxEPD_WHITE);
        display.setCursor(10, 20);
        display.print("Hello Dilder!");
        display.setTextSize(1);
        display.setCursor(10, 50);
        display.print("Olimex ESP32-S3-DevKit-Lipo");
        display.setCursor(10, 65);
        display.print("Waveshare 2.13\" V3 (SSD1680)");
        display.setCursor(10, 85);
        display.printf("PSRAM: %u KB", ESP.getPsramSize() / 1024);
        display.setCursor(10, 100);
        display.printf("Free heap: %u KB", ESP.getFreeHeap() / 1024);
    } while (display.nextPage());

    Serial.println("Display updated!");
    display.hibernate();
}

void loop() {
    // Nothing — e-paper retains image with no power
    delay(10000);
}
```

**If you see garbage or nothing on the display:**
- Double-check DIN (MOSI) and CLK wires aren't swapped
- Verify you're using V3 of the display, not V2 or V4 (check PCB silkscreen)
- Try the `GxEPD2_213_B74` class instead of `GxEPD2_213_BN` if the SSD1680 variant differs
- Make sure the FPC cable between the e-paper panel and the HAT PCB is firmly seated

### 7.5 Combined Test — All Peripherals

Once joystick and display work individually, combine them:

```cpp
#include <Arduino.h>
#include <GxEPD2_BW.h>

// ── Pin definitions ──
#define EPD_CS    10
#define EPD_DC     9
#define EPD_RST    3
#define EPD_BUSY   8
#define EPD_CLK   12
#define EPD_MOSI  11

#define BTN_UP      4
#define BTN_DOWN    7
#define BTN_LEFT    1
#define BTN_RIGHT   2
#define BTN_CENTER  15

#define LED_PIN     38
#define BAT_ADC     6

GxEPD2_BW<GxEPD2_213_BN, GxEPD2_213_BN::HEIGHT>
    display(GxEPD2_213_BN(EPD_CS, EPD_DC, EPD_RST, EPD_BUSY));

const uint8_t buttons[] = {BTN_UP, BTN_DOWN, BTN_LEFT, BTN_RIGHT, BTN_CENTER};
const char* btnNames[]  = {"UP", "DOWN", "LEFT", "RIGHT", "CENTER"};

void updateDisplay(const char* lastButton, float batV) {
    display.setFullWindow();
    display.firstPage();
    do {
        display.fillScreen(GxEPD_WHITE);
        display.setTextColor(GxEPD_BLACK);

        display.setTextSize(2);
        display.setCursor(10, 15);
        display.print("Dilder Proto");

        display.setTextSize(1);
        display.setCursor(10, 45);
        display.printf("Battery: %.2f V", batV);

        display.setCursor(10, 60);
        display.printf("PSRAM: %u KB free", ESP.getFreePsram() / 1024);

        display.setCursor(10, 80);
        display.print("Last input: ");
        display.print(lastButton);

        display.setCursor(10, 100);
        display.print("Press CENTER to refresh");
    } while (display.nextPage());
}

void setup() {
    Serial.begin(115200);
    unsigned long start = millis();
    while (!Serial && millis() - start < 3000) delay(10);

    // Init buttons
    for (int i = 0; i < 5; i++) {
        pinMode(buttons[i], INPUT_PULLUP);
    }

    // Init LED
    pinMode(LED_PIN, OUTPUT);
    digitalWrite(LED_PIN, HIGH);  // OFF

    // Init ADC
    analogReadResolution(12);

    // Init display
    SPI.begin(EPD_CLK, -1, EPD_MOSI, EPD_CS);
    display.init(115200);
    display.setRotation(1);

    float batV = (analogRead(BAT_ADC) / 4095.0) * 3.3 * 4.1333;
    updateDisplay("none", batV);

    Serial.println("Combined test ready. Press joystick directions.");
}

void loop() {
    for (int i = 0; i < 5; i++) {
        if (digitalRead(buttons[i]) == LOW) {
            Serial.printf("[PRESSED] %s\n", btnNames[i]);

            // Flash LED
            digitalWrite(LED_PIN, LOW);
            delay(100);
            digitalWrite(LED_PIN, HIGH);

            // Update display only on CENTER press (e-paper is slow)
            if (i == 4) {  // CENTER
                float batV = (analogRead(BAT_ADC) / 4095.0) * 3.3 * 4.1333;
                updateDisplay(btnNames[i], batV);
            }

            // Debounce
            while (digitalRead(buttons[i]) == LOW) delay(10);
            delay(50);
        }
    }
    delay(50);
}
```

---

## 8. Compiling and Flashing Firmware

### 8.1 Build from VSCode

| Action | Button | Shortcut |
|---|---|---|
| **Build** | Checkmark (✓) in PlatformIO toolbar | Ctrl+Alt+B |
| **Upload** | Arrow (→) in PlatformIO toolbar | Ctrl+Alt+U |
| **Serial Monitor** | Plug icon in PlatformIO toolbar | Ctrl+Alt+S |
| **Clean** | Trash icon | — |
| **Upload + Monitor** | — | `pio run -t upload && pio device monitor` |

The PlatformIO toolbar lives at the **bottom of the VSCode window**. If you don't see it, click the PlatformIO alien icon in the left sidebar.

### 8.2 Build from Terminal

```bash
cd "ESP Protyping/dilder-esp32"

# Build only
pio run

# Build and upload
pio run -t upload

# Clean build
pio run -t clean

# Serial monitor
pio device monitor

# Build, upload, then monitor (chained)
pio run -t upload && pio device monitor
```

**Build output location:** `.pio/build/olimex-esp32s3-devkit-lipo/firmware.bin`

### 8.3 Serial Monitor

```bash
# PlatformIO monitor (auto-detects port and baud)
pio device monitor

# Or specify explicitly
pio device monitor -p /dev/ttyUSB0 -b 115200

# Or use screen/picocom directly
screen /dev/ttyUSB0 115200
picocom -b 115200 /dev/ttyUSB0
```

**Exit screen:** Ctrl+A then K then Y
**Exit picocom:** Ctrl+A then Ctrl+X

### 8.4 Troubleshooting Upload Issues

| Problem | Cause | Fix |
|---|---|-----|
| `No such file: /dev/ttyUSB0` | Board not detected or wrong port | Unplug/replug USB. Check `dmesg \| tail`. Try `/dev/ttyUSB1`. |
| `Permission denied: /dev/ttyUSB0` | User not in `dialout` group | `sudo usermod -a -G dialout $USER` then log out/in |
| `Failed to connect to ESP32-S3` | Wrong USB port | Make sure you're using the **USB-UART** port (near the buttons), not USB-OTG |
| `A fatal error occurred: Could not open port` | Port locked by another process | Close any other serial monitors (screen, picocom, Arduino IDE) |
| `Timed out waiting for packet header` | Board not in bootloader mode | Hold **BOOT** button, press **RST**, release BOOT. Then upload. |
| `PSRAM shows 0 bytes` | Wrong memory type config | Add `board_build.arduino.memory_type = qio_opi` to platformio.ini |
| `Brownout detector was triggered` | Insufficient USB power | Use a different USB cable or port. Avoid USB hubs. |
| `Upload succeeds but no serial output` | CDC not enabled | Add `-DARDUINO_USB_CDC_ON_BOOT=1` to build_flags |
| `Wrong chip ID` | Board variant mismatch | Verify you selected `esp32-s3-devkitc-1` as the board |

**Manual bootloader mode (if auto-reset fails):**

1. Hold the **BOOT** button
2. Press and release the **RST** button
3. Release the **BOOT** button
4. The board is now in download mode — upload immediately

---

## 9. Integrating with the Dilder DevTool

### 9.1 Architecture Overview

The Dilder firmware is written in portable C with a platform abstraction layer. The game engine (events, emotions, stats, lifecycle) is the same code on every platform. Only the hardware interface layer changes.

```
┌─────────────────────────────────────────────────┐
│              Dilder Game Engine                   │
│  (event.c, emotion.c, stat.c, life.c, etc.)     │
│  Written in pure C — platform-independent        │
├──────────────┬──────────────┬────────────────────┤
│  Desktop HAL │  Pico W HAL  │  ESP32-S3 HAL      │
│  (DevTool)   │  (current)   │  (you're building) │
│  libdilder.so│  pico-sdk    │  Arduino/ESP-IDF    │
└──────────────┴──────────────┴────────────────────┘
```

The DevTool loads `libdilder.so` (compiled from the same C source) via Python `ctypes` to run the game engine in a GUI emulator. The ESP32-S3 HAL will call the same game engine functions but route display output to the e-Paper and input from the joystick.

### 9.2 Firmware Build Pipeline

For the ESP32-S3 prototype, the build pipeline is:

```
1. Edit C firmware in firmware/src/ and firmware/include/
2. PlatformIO compiles with Arduino framework (wraps ESP-IDF)
3. The ESP32-S3 HAL (src/platform/esp32/) translates:
   - render() calls → GxEPD2 e-Paper commands
   - input() calls → joystick GPIO reads
   - sensor() calls → I2C accelerometer/SHT40 reads
4. Upload via USB-UART to the Olimex board
5. Serial monitor for debug output
```

The DevTool remains your primary development tool for rapid iteration — it compiles and runs the game engine instantly on desktop. The ESP32 upload is for hardware validation.

### 9.3 Serial Communication Protocol

The DevTool can communicate with the ESP32-S3 board over serial for live debugging:

```
DevTool (Python)  ──── USB Serial (/dev/ttyUSB0) ────  ESP32-S3
                        115200 baud, 8N1
```

This lets you:
- Send test commands from DevTool to the board
- Stream game state from the board back to DevTool for visualization
- Update individual game parameters in real time

The protocol is defined in the Dilder firmware's serial handler and will be implemented as the ESP32-S3 HAL matures.

---

## 10. Important Notes and Warnings

### Voltage Levels

All peripherals are **3.3V**. The ESP32-S3 GPIOs are 3.3V and both the Waveshare display and joystick module are 3.3V compatible. **Do not connect 5V signals to any GPIO pin** — this will damage the ESP32-S3.

### GPIO5 and GPIO6 Are Not Free

Unlike the generic ESP32-S3 DevKitC, the Olimex board has voltage dividers permanently connected to GPIO5 (external power sense) and GPIO6 (battery sense). You **cannot use these as general-purpose digital I/O**. They can only be read as ADC inputs.

### GPIO35/36/37 Are Dead

The N8R8 module uses octal PSRAM which internally connects to GPIO35, 36, and 37. These pins are exposed on the EXT2 header but **connecting anything to them will break PSRAM**. Do not use them.

### Battery Safety

- **Verify JST polarity** with a multimeter before connecting any LiPo battery. There is no universal JST polarity standard. Reversed polarity will destroy the charger IC.
- During prototyping, power via USB only. Only connect the battery after all wiring is verified.
- A shorted LiPo can cause fire. Never leave a charging battery unattended.

### Display Refresh Rules

The Waveshare 2.13" e-Paper has strict refresh rules:

| Rule | Requirement |
|---|---|
| Minimum interval | ≥ 180 seconds between full refreshes |
| Partial refresh limit | Max 5 consecutive partial refreshes before a full refresh |
| Full refresh procedure | Clear to white → refresh → draw content → refresh |

Violating these causes ghosting artifacts and can permanently damage the display.

### Antenna Clearance

The ESP32-S3 module's PCB antenna is at one end of the board. Do not place metal objects, wires, or your hand directly over the antenna area during Wi-Fi/BLE operation. On the breadboard, keep the antenna end clear.

### SPI Bus Selection

The ESP32-S3 has 4 SPI controllers. SPI0 and SPI1 are reserved for internal flash/PSRAM. We use **SPI3 (FSPI)** for the e-Paper display on GPIO10-13. The Arduino `SPI.begin()` call with custom pins configures this automatically.

---

## 11. Resources, Documentation & Videos

### 11.1 Olimex Board Resources

| Resource | URL |
|---|-----|
| **Product page** | https://www.olimex.com/Products/IoT/ESP32-S3/ESP32-S3-DevKit-Lipo/open-source-hardware |
| **GitHub repo (schematics, KiCad, software)** | https://github.com/OLIMEX/ESP32-S3-DevKit-LiPo |
| **Schematic PDF (Rev B)** | https://github.com/OLIMEX/ESP32-S3-DevKit-LiPo/blob/main/HARDWARE/ESP32-S3-DevKit-LiPo_Rev_B/ESP32-S3-DevKit-LiPo_Rev_B.pdf |
| **User manual PDF** | https://github.com/OLIMEX/ESP32-S3-DevKit-LiPo/blob/main/DOCUMENTS/ESP32-S3-DevKit-LiPo.pdf |
| **Board dimensions** | https://github.com/OLIMEX/ESP32-S3-DevKit-LiPo/tree/main/HARDWARE/Dimensions |
| **Arduino & PlatformIO examples** | https://github.com/OLIMEX/ESP32-S3-DevKit-LiPo/tree/main/SOFTWARE |
| **Olimex forum** | https://www.olimex.com/forum/ |

### 11.2 ESP32-S3 Resources

| Resource | URL |
|---|-----|
| **ESP32-S3 Datasheet** | https://www.espressif.com/sites/default/files/documentation/esp32-s3_datasheet_en.pdf |
| **ESP32-S3 Technical Reference Manual** | https://www.espressif.com/sites/default/files/documentation/esp32-s3_technical_reference_manual_en.pdf |
| **ESP32-S3-WROOM-1 Module Datasheet** | https://www.espressif.com/sites/default/files/documentation/esp32-s3-wroom-1_wroom-1u_datasheet_en.pdf |
| **ESP32-S3 Pinout Guide (RandomNerdTutorials)** | https://randomnerdtutorials.com/esp32-s3-devkitc-pinout-guide/ |
| **ESP32-S3 Strapping Pins Guide** | https://www.espboards.dev/blog/esp32-strapping-pins/ |
| **Espressif Arduino Core (GitHub)** | https://github.com/espressif/arduino-esp32 |
| **ESP-IDF Programming Guide** | https://docs.espressif.com/projects/esp-idf/en/latest/esp32s3/ |

### 11.3 Waveshare e-Paper Resources

| Resource | URL |
|---|-----|
| **Waveshare 2.13" Wiki** | https://www.waveshare.com/wiki/2.13inch_e-Paper_HAT |
| **Waveshare e-Paper GitHub (Pi)** | https://github.com/waveshare/e-Paper |
| **Waveshare Pico e-Paper GitHub** | https://github.com/waveshare/Pico_ePaper_Code |
| **V3 Specification PDF** | https://files.waveshare.com/upload/4/4e/2.13inch_e-Paper_V3_Specification.pdf |
| **SSD1680 Driver IC Datasheet** | https://www.orientdisplay.com/wp-content/uploads/2022/08/SSD1680_v0.14.pdf |
| **GxEPD2 Library (ESP32 e-Paper)** | https://github.com/ZinggJM/GxEPD2 |
| **GxEPD2 Display Selection Guide** | https://github.com/ZinggJM/GxEPD2/blob/master/extras/GxEPD2_selection_new_style.h |

### 11.4 PlatformIO & Development

| Resource | URL |
|---|-----|
| **PlatformIO Docs — ESP32-S3** | https://docs.platformio.org/en/latest/boards/espressif32/esp32-s3-devkitc-1.html |
| **PlatformIO Quick Start** | https://docs.platformio.org/en/latest/integration/ide/vscode.html |
| **PlatformIO CLI Reference** | https://docs.platformio.org/en/latest/core/userguide/index.html |
| **Arduino-ESP32 GPIO API** | https://docs.espressif.com/projects/arduino-esp32/en/latest/api/gpio.html |
| **Arduino-ESP32 SPI API** | https://docs.espressif.com/projects/arduino-esp32/en/latest/api/spi.html |
| **Arduino-ESP32 I2C API** | https://docs.espressif.com/projects/arduino-esp32/en/latest/api/i2c.html |
| **ESP32-S3 USB CDC Guide** | https://docs.espressif.com/projects/arduino-esp32/en/latest/api/usb_cdc.html |

### 11.5 Video Tutorials

**ESP32-S3 Getting Started:**

| Video | Channel | What It Covers |
|---|---|---|
| "Getting Started with ESP32-S3" | RandomNerdTutorials | Board overview, Arduino IDE setup, first upload |
| "ESP32-S3 Complete Guide" | DroneBot Workshop | Pinout, SPI/I2C, WiFi, BLE, PSRAM usage |
| "ESP32-S3 with PlatformIO" | Rui Santos (RNT) | VSCode + PlatformIO setup, upload, debug |
| "Olimex ESP32-S3 DevKit Review" | Olimex (official) | Board walkthrough, features, battery charging |

**e-Paper with ESP32:**

| Video | Channel | What It Covers |
|---|---|---|
| "E-Paper Display with ESP32 — Complete Guide" | RandomNerdTutorials | GxEPD2 library setup, wiring, code examples |
| "Waveshare e-Paper + ESP32-S3" | Volos Projects | SPI wiring, partial refresh, power saving |
| "GxEPD2 Tutorial for ESP32" | Brian Lough | Library deep dive, display selection, custom fonts |
| "E-Ink Weather Display ESP32" | G6EJD (David Bird) | Real-world e-paper project with sensor data display |

**PlatformIO:**

| Video | Channel | What It Covers |
|---|---|---|
| "PlatformIO with VSCode — Complete Tutorial" | Rui Santos (RNT) | Installation, project creation, serial monitor, debugging |
| "PlatformIO Advanced Tips" | Andreas Spiess | Multiple environments, OTA, library management |
| "ESP32 Debugging with JTAG in PlatformIO" | PlatformIO (official) | USB-OTG JTAG debug setup for ESP32-S3 |

**Search these on YouTube** — the titles describe the content. Look for the most recent uploads (2024-2026) as the ESP32-S3 ecosystem evolves quickly.

---

## Quick Reference Card

```
╔══════════════════════════════════════════════════════════════╗
║              OLIMEX ESP32-S3-DEVKIT-LIPO                     ║
║              DILDER PROTOTYPE QUICK REFERENCE                ║
╠══════════════════════════════════════════════════════════════╣
║                                                              ║
║  DISPLAY (SPI)           JOYSTICK (GPIO)                     ║
║  ─────────────           ──────────────                      ║
║  DIN  → GPIO11           UP     → GPIO4                     ║
║  CLK  → GPIO12           DOWN   → GPIO7                     ║
║  CS   → GPIO10           LEFT   → GPIO1                     ║
║  DC   → GPIO9            RIGHT  → GPIO2                     ║
║  RST  → GPIO3            CENTER → GPIO15                    ║
║  BUSY → GPIO8            COM    → GND                       ║
║  VCC  → 3.3V                                                ║
║  GND  → GND             ON-BOARD                             ║
║                          ────────                            ║
║  SPI MODE: 0             LED    → GPIO38 (active LOW)        ║
║  SPI CLK:  4 MHz         BOOT   → GPIO0                     ║
║                          BAT    → GPIO6 (ADC, ×4.133)       ║
║  UPLOAD PORT:            PWR    → GPIO5 (ADC, ×1.468)       ║
║  USB-UART (/dev/ttyUSB0)                                    ║
║  115200 baud             DEAD PINS: GPIO35, 36, 37 (PSRAM)  ║
║                                                              ║
╚══════════════════════════════════════════════════════════════╝
```

---

*Document version: 2.0 — Rewritten 2026-04-17 for hands-on setup with received hardware*
*Previous version: Breakout board design guide (v1.0)*

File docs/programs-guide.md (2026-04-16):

# Dilder Programs Guide

A comprehensive reference for every firmware program in the Dilder project. Each program runs on a Raspberry Pi Pico W with a Waveshare 2.13" e-ink display and renders an animated octopus with mood-specific expressions, body animations, and curated quotes.

---

## Table of Contents

- [Overview](#overview)
- [How Programs Work](#how-programs-work)
  - [Display Layout](#display-layout)
  - [Animation Cycle](#animation-cycle)
  - [Quote System](#quote-system)
  - [Building and Flashing](#building-and-flashing)
- [Utility Programs](#utility-programs)
  - [Hello World](#hello-world)
  - [Hello World Serial](#hello-world-serial)
  - [Image Receiver](#image-receiver)
- [Emotional State Programs](#emotional-state-programs)
  - [Sassy Octopus](#sassy-octopus)
  - [Supportive Octopus](#supportive-octopus)
  - [Angry Octopus](#angry-octopus)
  - [Conspiratorial Octopus](#conspiratorial-octopus)
  - [Sad Octopus](#sad-octopus)
  - [Chaotic Octopus](#chaotic-octopus)
  - [Hungry Octopus](#hungry-octopus)
  - [Tired Octopus](#tired-octopus)
  - [Slap Happy Octopus](#slap-happy-octopus)
  - [Lazy Octopus](#lazy-octopus)
  - [Fat Octopus](#fat-octopus)
  - [Chill Octopus](#chill-octopus)
  - [Creepy Octopus](#creepy-octopus)
  - [Excited Octopus](#excited-octopus)
  - [Nostalgic Octopus](#nostalgic-octopus)
  - [Homesick Octopus](#homesick-octopus)
- [Mood Selector (Interactive)](#mood-selector-interactive)
  - [Serial Input Reference](#serial-input-reference)
  - [Connecting to the Pico](#connecting-to-the-pico)
- [Program Comparison Table](#program-comparison-table)

---

## Overview

The `dev-setup/` directory contains **19 programs** total:

- **3 utility programs** for hardware testing and development
- **16 emotional state programs** each featuring a unique octopus personality
- **1 interactive mood selector** that combines all 16 emotional states with keyboard control

All emotional state programs share the same core rendering engine: a runtime pixel renderer that composites body, eyes, mouth, chat bubble, and text onto a 250x122px 1-bit canvas, then pushes it to the e-ink display using partial refresh (~4 second frame cycle).

---

## How Programs Work

### Display Layout

The 250x122 pixel landscape canvas is organized as:

```
+--------------------------------------------------+
|              APRIL 12, 2026  3:47 PM             |  <-- Clock header (y=1)
|                                                  |
|   @@@@@@     +----------------------------+      |
|  @@    @@    | QUOTE TEXT GOES HERE AND   |      |  <-- Chat bubble (y=17, 170x70)
|  @ O  O @   | WRAPS AUTOMATICALLY TO     |      |
|  @  __  @   | FIT INSIDE THE BUBBLE      |      |
|  @@    @@   |                            |      |
|   @@@@@@ /  +----------------------------+      |
|    |||||       ~ SASSY OCTOPUS ~                 |  <-- Tagline (below bubble)
+--------------------------------------------------+
```

- **Clock header:** Date and time from RTC, centered at y=1
- **Octopus body:** Left side, rendered with RLE-decoded body + mood-specific transforms
- **Eyes:** White sockets with mood-specific pupils (hearts, stars, spirals, etc.)
- **Mouth:** 18 distinct expressions cycled per mood
- **Chat bubble:** Right side, rounded rectangle with speech tail pointing to octopus
- **Quote text:** Word-wrapped 5x7 bitmap font inside the bubble
- **Tagline:** Mood name centered below the bubble

### Animation Cycle

Each mood defines a 4-frame expression cycle. Every ~4 seconds:

1. The current expression is drawn from the cycle (e.g., Smirk -> Open -> Smile -> Open)
2. On every OPEN mouth frame, a new random quote is selected
3. The body transform is applied (shift, wobble, expand based on mood)
4. The frame is rendered to the landscape buffer, transposed to portrait, and pushed via partial refresh

### Quote System

Quotes are stored in `quotes.h` as a static array of `{text, mood_id}` structs. Each program includes only its relevant quotes (except Mood Selector which includes all 823). The DevTool auto-generates `quotes.h` from the Python quote lists in `devtool.py`.

### Building and Flashing

**Via DevTool GUI:**
1. Open DevTool: `python3 DevTool/devtool.py`
2. Select the program from the dropdown
3. Select display variant (V2/V3/V3a/V4)
4. Click "Build & Flash to Pico"
5. Put Pico in BOOTSEL mode (hold BOOTSEL + plug USB)
6. DevTool copies the `.uf2` to the mounted drive

**Via command line:**
```bash
cd dev-setup/
docker compose run --rm build-sassy-octopus bash -c \
  "mkdir -p build && cd build && cmake .. -DDISPLAY_VARIANT=V3 && make -j4"
# Copy build/sassy_octopus.uf2 to the Pico in BOOTSEL mode
cp sassy-octopus/build/sassy_octopus.uf2 /run/media/$USER/RPI-RP2/
```

---

## Utility Programs

### Hello World

**Directory:** `dev-setup/hello-world/`

Basic e-ink display test. Draws a simple pattern to verify the display is wired correctly and the SPI bus is working. This is the first program you should flash to confirm hardware is functional.

**Use case:** Hardware verification after initial wiring.

### Hello World Serial

**Directory:** `dev-setup/hello-world-serial/`

Serial-only test program. Prints messages over USB CDC at 115200 baud without driving the display. Useful for verifying the USB serial connection works before flashing display firmware.

**Use case:** Verify USB serial communication before display testing.

### Image Receiver

**Directory:** `dev-setup/img-receiver/`

Receives raw 1-bit bitmap data over USB serial and displays it on the e-ink screen. Used by the DevTool's display emulator to push custom images to the hardware.

**Use case:** Push arbitrary images from DevTool to the physical display.

---

## Emotional State Programs

Each program below runs autonomously once flashed. The octopus cycles through its personality-specific quotes, changing expression and quote every ~4 seconds.

### Sassy Octopus

**Directory:** `dev-setup/sassy-octopus/` | **Quotes:** 196 | **Default Mood:** Normal

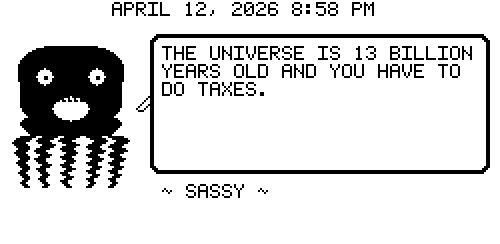
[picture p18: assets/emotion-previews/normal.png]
Sassy


A snarky octopus with attitude. Delivers observations like "WIFI IS JUST SPICY AIR" and "I DONT HAVE BONES AND THATS A FLEX." The default personality with centered pupils, smirk/smile mouth cycle, and gentle breathing body animation.

| Feature | Details |
|---|---|
| Eyes | Centered pupils with white highlights |
| Mouth Cycle | Smirk -> Open -> Smile -> Open |
| Body | Gentle 1px vertical breathing bob |
| Quotes | Snarky observations, food hot takes, self-aware flexes |

### Supportive Octopus

**Directory:** `dev-setup/supportive-octopus/` | **Quotes:** 160 | **Default Mood:** Normal

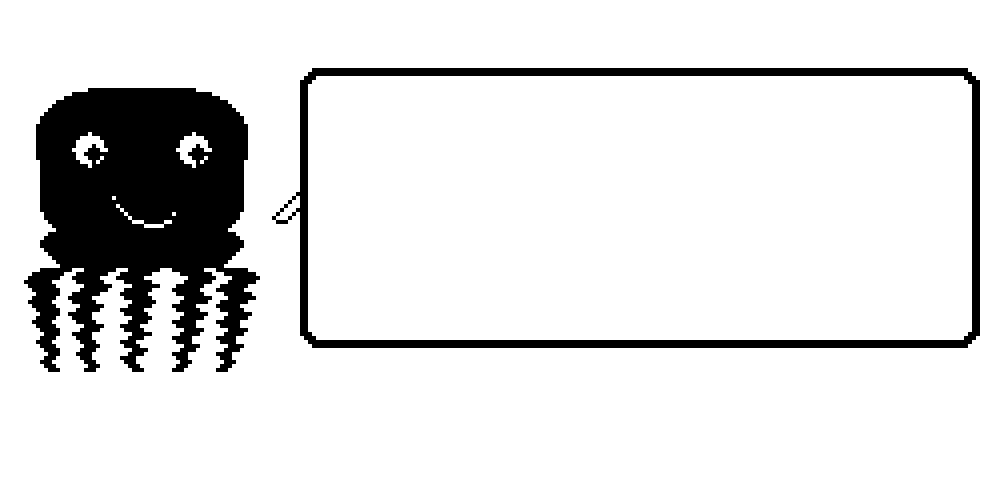
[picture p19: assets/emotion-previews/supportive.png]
Supportive


Aggressively supportive. Uses the same normal face as Sassy but delivers chaotic affirmations like unhinged pep talks. Some quotes override to weird/unhinged moods for visual variety.

| Feature | Details |
|---|---|
| Eyes | Same as Sassy (centered, normal) |
| Mouth Cycle | Smirk -> Open -> Smile -> Open |
| Body | Gentle breathing (same as Sassy) |
| Quotes | Unhinged pep talks, chaotic affirmations, spicy encouragement |

### Angry Octopus

**Directory:** `dev-setup/angry-octopus/` | **Quotes:** 45 | **Default Mood:** Angry

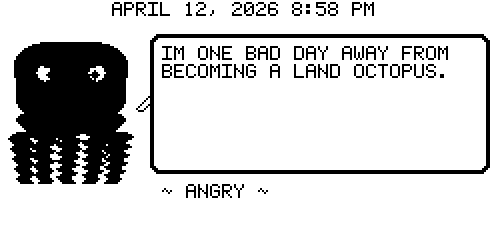
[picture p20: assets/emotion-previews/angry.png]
Angry


Furious but adorable. V-shaped eyebrows slant inward, pupils glare toward the nose, and the tight frown shows zero patience. Body puffs up 2px wider with a slight tremble.

| Feature | Details |
|---|---|
| Eyes | Pupils shifted inward + down (glaring), thick V-shaped brow arcs |
| Mouth Cycle | Frown -> Open -> Frown -> Frown |
| Body | Puffed up +2px wider, 0.5px wobble tremble |
| Quotes | Rants about shrimp theft, Poseidon, and tentacle violence |

### Conspiratorial Octopus

**Directory:** `dev-setup/conspiratorial-octopus/` | **Quotes:** 47 | **Default Mood:** Weird

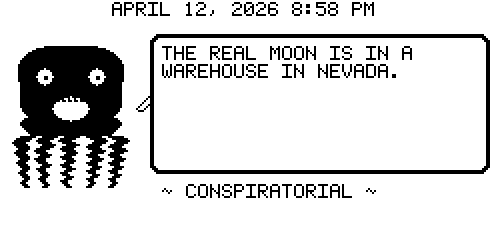
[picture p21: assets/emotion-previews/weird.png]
Conspiratorial


Tinfoil hat energy. Misaligned pupils (one up-left, one down-right) give a shifty look. The wavy sine-wave mouth and swaying body sell the paranoia.

| Feature | Details |
|---|---|
| Eyes | Misaligned: left up-left, right down-right |
| Mouth Cycle | Wavy sine -> Open -> Wavy -> Smile |
| Body | Lean/sway +/-3px, subtle row distortion |
| Quotes | Government conspiracies, simulation theory, birds aren't real |

### Sad Octopus

**Directory:** `dev-setup/sad-octopus/` | **Quotes:** 35 | **Default Mood:** Sad

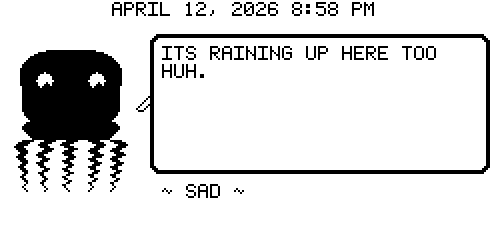
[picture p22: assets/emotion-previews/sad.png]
Sad


Droopy eyes looking at the floor with inverted brow arcs (high inside, low outside). The gentle frown and deflated body convey genuine melancholy.

| Feature | Details |
|---|---|
| Eyes | Downward-looking pupils, droopy brow arcs |
| Mouth Cycle | Frown -> Open -> Frown -> Smile |
| Body | Drooped +3px down, deflated 1px narrower |
| Quotes | Existential ocean sadness, melodramatic but relatable |

### Chaotic Octopus

**Directory:** `dev-setup/chaotic-octopus/` | **Quotes:** 40 | **Default Mood:** Chaotic

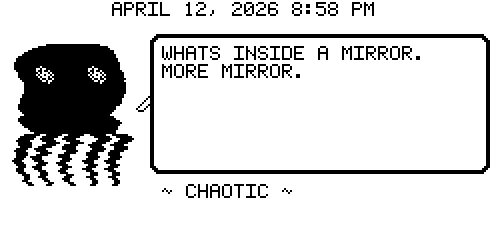
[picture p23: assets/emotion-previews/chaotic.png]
Chaotic


Pure entropy. Spiral ring pupils (concentric circles), a zigzag lightning-bolt mouth, and wild wavy body distortion. The expression cycle is itself chaotic: zigzag -> open -> unhinged scream -> wobbly.

| Feature | Details |
|---|---|
| Eyes | Spiral ring pupils (concentric circles with center dot) |
| Mouth Cycle | Zigzag -> Open -> Unhinged -> Wobbly |
| Body | Wild 3px sine wobble per row, shifting phase |
| Quotes | Nonsensical fever-dream energy, entropy incarnate |

### Hungry Octopus

**Directory:** `dev-setup/hungry-octopus/` | **Quotes:** 30 | **Default Mood:** Hungry

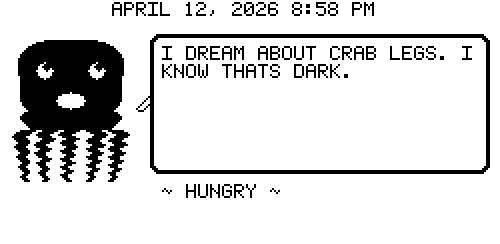
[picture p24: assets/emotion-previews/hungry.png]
Hungry


Wide eyes staring upward at imaginary food, with a drooling open mouth (oval + drool drops below). Every thought is about snacks.

| Feature | Details |
|---|---|
| Eyes | Pupils shifted upward (staring at food) |
| Mouth Cycle | Drool mouth -> Open -> Drool -> Smile |
| Body | Slight upward shift (-2px), breathing |
| Quotes | Taco dreams, snack philosophy, selling hearts for pizza |

### Tired Octopus

**Directory:** `dev-setup/tired-octopus/` | **Quotes:** 30 | **Default Mood:** Tired

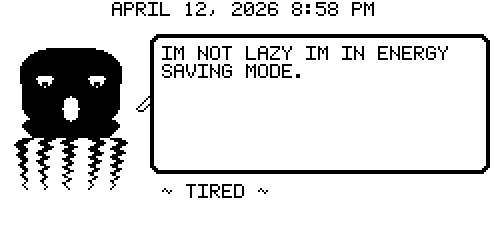
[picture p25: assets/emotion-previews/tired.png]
Tired


Half-closed eyelids cover the top of each eye socket, tiny sleepy pupils peek out below. The tall yawn mouth is open wide vertically. Running on zero sleep.

| Feature | Details |
|---|---|
| Eyes | Half-closed lids (top half black), tiny pupils low in slit |
| Mouth Cycle | Yawn -> Open -> Yawn -> Yawn |
| Body | Slouched +2px down, deflated 1px narrower |
| Quotes | Existential exhaustion, one brain cell, nap theology |

### Slap Happy Octopus

**Directory:** `dev-setup/slaphappy-octopus/` | **Quotes:** 30 | **Default Mood:** Slap Happy

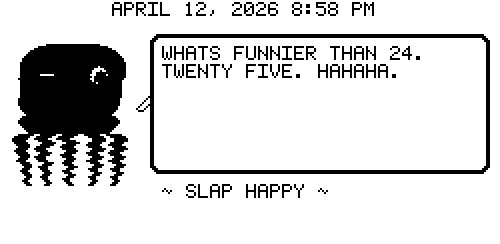
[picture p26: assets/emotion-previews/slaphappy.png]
Slap Happy


One eye squinted shut (white slit), one manic oversized pupil. The wide wobbly grin with sine wobble completes the delirious look. Everything is hilarious for no reason.

| Feature | Details |
|---|---|
| Eyes | Left squinted shut (slit), right oversized pupil |
| Mouth Cycle | Wobbly grin -> Open -> Wobbly grin -> Smile |
| Body | Bouncing +/-3px lateral sway, 2px row wobble |
| Quotes | Delirious giggling, everything is hilarious |

### Lazy Octopus

**Directory:** `dev-setup/lazy-octopus/` | **Quotes:** 30 | **Default Mood:** Lazy

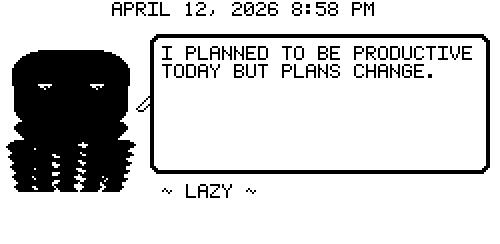
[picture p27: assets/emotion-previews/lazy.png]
Lazy


Nearly-closed slit eyes (only bottom sliver visible), flat horizontal line mouth. Custom body sits on its side with all tentacles draped to the right. Proudly doing nothing.

| Feature | Details |
|---|---|
| Eyes | Lids cover most of socket, barely-visible dots low in slit |
| Mouth Cycle | Flat line -> Flat line -> Flat line -> Open |
| Body | Custom side-sitting pose, tentacles drape right, +3px sag |
| Quotes | Philosophical laziness, zero motivation manifestos |

### Fat Octopus

**Directory:** `dev-setup/fat-octopus/` | **Quotes:** 30 | **Default Mood:** Fat

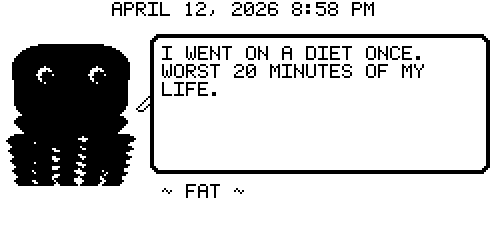
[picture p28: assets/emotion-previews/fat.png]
Fat


Custom wider body: dome starts 2 rows earlier, +5px per side at peak, no waist taper, thicker tentacles. Happy wide pupils and a satisfied smile with puffed cheeks. Proudly round.

| Feature | Details |
|---|---|
| Eyes | Wider pupils (r=3), happy and satisfied |
| Mouth Cycle | Cheek-puff smile -> Open -> Cheek-puff smile -> Smile |
| Body | Custom fat body RLE: wider dome, no waist, thick tentacles |
| Quotes | Food-positive celebrations, proudly round philosophy |

### Chill Octopus

**Directory:** `dev-setup/chill-octopus/` | **Quotes:** 30 | **Default Mood:** Chill

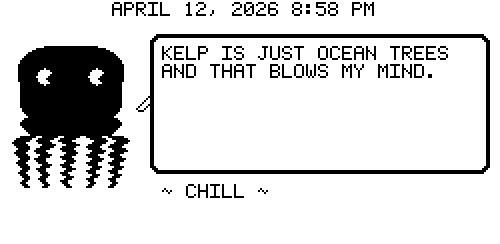
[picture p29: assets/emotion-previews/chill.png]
Chill


Side-glancing cool pupils shifted right, relaxed asymmetric half-smile. Unbothered zen vibes with gentle 1px lateral sway.

| Feature | Details |
|---|---|
| Eyes | Pupils shifted right (looking to the side) |
| Mouth Cycle | Half-smile -> Open -> Half-smile -> Smile |
| Body | Gentle 1px sway, lowered 1px |
| Quotes | Stoner philosopher energy, going with the flow |

### Creepy Octopus

**Directory:** `dev-setup/creepy-octopus/` | **Quotes:** 30 | **Default Mood:** Creepy

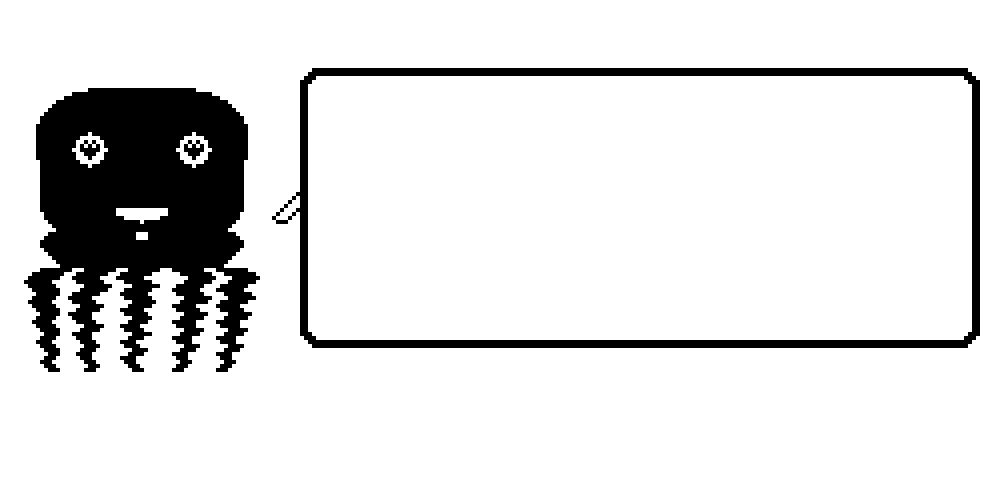
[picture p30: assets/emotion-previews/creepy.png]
Creepy


Heart-shaped pupils in each eye socket, wide open smile with a tongue hanging out (filled oval + tongue bump below). Flirty tentacle energy.

| Feature | Details |
|---|---|
| Eyes | Heart-shaped pupils (bumps + taper + point) |
| Mouth Cycle | Tongue-out smile -> Open -> Tongue-out -> Smile |
| Body | Width pulses +/-2px (confident strut) |
| Quotes | Ocean romance, goofy innuendo, tentacle flirting |

### Excited Octopus

**Directory:** `dev-setup/excited-octopus/` | **Quotes:** 30 | **Default Mood:** Excited

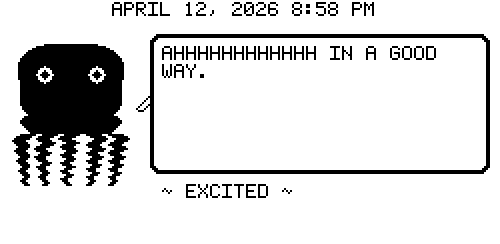
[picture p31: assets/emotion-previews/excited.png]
Excited


Star/sparkle cross-shaped pupils with diagonal tips in each eye. The wide open smile curves from edge to edge. Bouncing body with +/-3px vertical oscillation.

| Feature | Details |
|---|---|
| Eyes | Star/sparkle cross pupils with diagonal tips |
| Mouth Cycle | Wide grin -> Open -> Wide grin -> Smile |
| Body | Bouncing up/down +/-3px |
| Quotes | Maximum hype, caps lock enthusiasm, bouncing energy |

### Nostalgic Octopus

**Directory:** `dev-setup/nostalgic-octopus/` | **Quotes:** 30 | **Default Mood:** Nostalgic

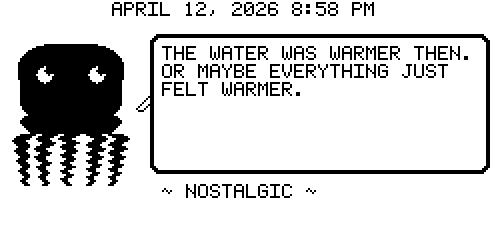
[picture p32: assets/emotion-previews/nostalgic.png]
Nostalgic


Pupils shifted up and to the right (remembering), gentle small half-smile. The body sways slowly with a slight tilt, as if lost in thought.

| Feature | Details |
|---|---|
| Eyes | Pupils up-right (looking into the distance) |
| Mouth Cycle | Small half-smile -> Open -> Half-smile -> Smile |
| Body | Slow 2px lateral sway + slight vertical drift |
| Quotes | Wistful ocean memories, back-in-my-day nostalgia |

### Homesick Octopus

**Directory:** `dev-setup/homesick-octopus/` | **Quotes:** 30 | **Default Mood:** Homesick

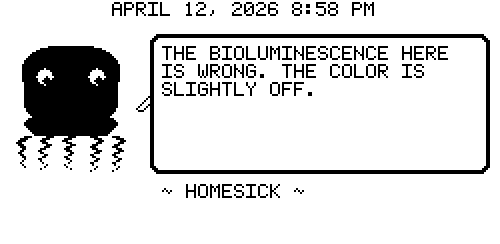
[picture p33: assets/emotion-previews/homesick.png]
Homesick


Watery eyes with tear drop pixels below each socket, wobbly trying-not-to-cry mouth line. The body droops and narrows, conveying deflation and longing.

| Feature | Details |
|---|---|
| Eyes | Lowered pupils, tear drops below each eye |
| Mouth Cycle | Wobbly line -> Open -> Wobbly -> Wobbly |
| Body | Drooped +1px, narrowed -2px, bittersweet |
| Quotes | Missing the deep ocean, longing for home |

---

## Mood Selector (Interactive)

**Directory:** `dev-setup/mood-selector/` | **Quotes:** 823 (all moods combined)

The Mood Selector combines all 16 emotional states into a single interactive firmware. Instead of being locked to one personality, you browse through moods using keyboard input over USB serial.

**On the display:**
- Clock header at top center
- Octopus with the currently selected mood's face, body animation, and a random quote
- Bottom center: `< MOOD_NAME >` with `<` and `>` arrows indicating left/right navigation

**How to use:**
1. Flash `mood_selector.uf2` to the Pico
2. Connect to serial (see [Connecting to the Pico](#connecting-to-the-pico))
3. Press `[` or `]` to cycle through moods
4. Press a letter key for direct mood selection
5. Press `?` to see all available commands

### Serial Input Reference

Connect to the Pico's USB serial port at 115200 baud. All commands are single keystrokes.

#### Mood Navigation

| Key | Action |
|-----|---|
| `[` | Previous mood (left) -- wraps around |
| `]` | Next mood (right) -- wraps around |
| `,` | Previous mood (left) -- alternate key |
| `.` | Next mood (right) -- alternate key |
| `r` | Jump to a random mood |

#### Direct Mood Selection

| Key | Mood | Key | Mood |
|-----|---|-----|---|
| `n` | Sassy | `w` | Weird |
| `u` | Unhinged | `a` | Angry |
| `s` | Sad | `c` | Chaotic |
| `h` | Hungry | `t` | Tired |
| `p` | Slap Happy | `l` | Lazy |
| `f` | Fat | `k` | Chill |
| `y` | Creepy | `e` | Excited |
| `o` | Nostalgic | `m` | Homesick |

#### Other Commands

| Key | Action |
|-----|---|
| `q` | Load a new random quote (same mood) |
| `?` | Print the full help menu to serial |

All keys are case-insensitive (e.g., `A` and `a` both select Angry).

#### Serial Output

When you press a navigation key, the serial monitor shows:

```
----------------------------------------
  KEY ']' pressed  |  >> RIGHT  |  SASSY --> WEIRD
  Now showing: < WEIRD >  (2/16)
----------------------------------------
```

Each animation frame also logs:

```
Frame 5  |  < ANGRY > (4/16)  |  "THE AUDACITY OF THIS ENTIRE OCEAN."
```

### Connecting to the Pico

The Pico communicates over USB CDC serial at 115200 baud. Only one program can hold the port at a time.

**Find the serial port:**
```bash
ls /dev/serial/by-id/
# Look for: usb-Raspberry_Pi_Pico_XXXXX-if00 -> ../../ttyACM0
```

**Connect with screen:**
```bash
screen /dev/ttyACM0 115200
# Exit: Ctrl+A then K then Y
```

**Connect with picocom:**
```bash
picocom -b 115200 /dev/ttyACM0
# Exit: Ctrl+A then Ctrl+X
```

**Connect with minicom:**
```bash
minicom -D /dev/ttyACM0 -b 115200
# Exit: Ctrl+A then X
```

**Via DevTool:** The DevTool's Serial Monitor tab connects automatically. Close it before using a terminal, as only one program can hold the port.

> **Note:** If the Pico was just flashed, it will reboot and appear as a serial device within ~1 second. If no device appears at `/dev/ttyACM0`, try unplugging and re-plugging the USB cable (without holding BOOTSEL).

---

## Program Comparison Table

| Program | Quotes | Body | Eyes | Mouth | Body Animation |
|---|---|---|---|---|---|
| Sassy | 196 | Standard | Normal | Smirk/Smile | Breathing bob |
| Supportive | 160 | Standard | Normal | Smirk/Smile | Breathing bob |
| Angry | 45 | Standard | Glare + V-brows | Frown | Puffed +2px, tremble |
| Conspiratorial | 47 | Standard | Misaligned | Sine wave | Sway +/-3px |
| Sad | 35 | Standard | Down + droopy brows | Gentle frown | Drooped +3px, -1px |
| Chaotic | 40 | Standard | Spiral rings | Zigzag lightning | Wild 3px wobble |
| Hungry | 30 | Standard | Up (staring) | Drool mouth | Slight upward shift |
| Tired | 30 | Standard | Half-closed lids | Yawn oval | Slouched +2px |
| Slap Happy | 30 | Standard | One squint, one manic | Wobbly grin | Bounce +/-3px |
| Lazy | 30 | Custom (side-sit) | Barely-open slits | Flat line | Sagged, tentacles right |
| Fat | 30 | Custom (wide) | Wide happy | Cheek-puff smile | Width pulse |
| Chill | 30 | Standard | Side-glance | Half-smile | Gentle 1px sway |
| Creepy | 30 | Standard | Heart-shaped | Tongue out | Width pulse +/-2px |
| Excited | 30 | Standard | Star sparkle | Wide open grin | Bounce +/-3px |
| Nostalgic | 30 | Standard | Up-right gaze | Small half-smile | Slow 2px sway |
| Homesick | 30 | Standard | Tears below | Wobbly line | Drooped, -2px narrow |
| **Mood Selector** | **823** | **All** | **All** | **All** | **All (interactive)** |

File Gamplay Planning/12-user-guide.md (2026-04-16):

# Dilder User Guide

> The complete guide to raising, nurturing, and adventuring with your digital octopus companion.

---

## Table of Contents

**I. Introduction**
1. [What Is Dilder?](#1-what-is-dilder)
2. [The Origin Story — Meet Jamal](#2-the-origin-story--meet-jamal)
3. [Your First Hatch](#3-your-first-hatch)

**II. Getting to Know Your Octopus**
4. [The 16 Emotional States](#4-the-16-emotional-states)
   - 4.1 [Normal / Sassy](#41-normal--sassy)
   - 4.2 [Hungry](#42-hungry)
   - 4.3 [Tired](#43-tired)
   - 4.4 [Sad](#44-sad)
   - 4.5 [Angry](#45-angry)
   - 4.6 [Excited](#46-excited)
   - 4.7 [Chill](#47-chill)
   - 4.8 [Lazy](#48-lazy)
   - 4.9 [Fat](#49-fat)
   - 4.10 [Chaotic](#410-chaotic)
   - 4.11 [Weird](#411-weird)
   - 4.12 [Unhinged](#412-unhinged)
   - 4.13 [Slap Happy](#413-slap-happy)
   - 4.14 [Creepy](#414-creepy)
   - 4.15 [Nostalgic](#415-nostalgic)
   - 4.16 [Homesick](#416-homesick)
5. [Reading the Display](#5-reading-the-display)

**III. Caring for Dilder**
6. [The Stat System](#6-the-stat-system)
   - 6.1 [Primary Stats](#61-primary-stats)
   - 6.2 [Secondary Stats](#62-secondary-stats)
   - 6.3 [Hidden Stats](#63-hidden-stats)
   - 6.4 [Stat Decay & Modifiers](#64-stat-decay--modifiers)
7. [Care Actions](#7-care-actions)
   - 7.1 [Feeding](#71-feeding)
   - 7.2 [Cleaning](#72-cleaning)
   - 7.3 [Playing](#73-playing)
   - 7.4 [Medicine](#74-medicine)
   - 7.5 [Scolding & Discipline](#75-scolding--discipline)
   - 7.6 [Sleep](#76-sleep)
8. [The Daily Rhythm](#8-the-daily-rhythm)

**IV. The Physical World**
9. [Sensor Interactions](#9-sensor-interactions)
   - 9.1 [Voice & Sound](#91-voice--sound)
   - 9.2 [Light & Darkness](#92-light--darkness)
   - 9.3 [Temperature & Humidity](#93-temperature--humidity)
   - 9.4 [Motion & Movement](#94-motion--movement)
10. [Step Tracking & Activity](#10-step-tracking--activity)
    - 10.1 [Daily Step Targets](#101-daily-step-targets)
    - 10.2 [Weekly Targets](#102-weekly-targets)
    - 10.3 [Monthly Targets](#103-monthly-targets)
    - 10.4 [The Streak System](#104-the-streak-system)
11. [Location & Exploration](#11-location--exploration)

**V. Growing Up**
12. [Life Stages](#12-life-stages)
    - 12.1 [Egg](#121-egg)
    - 12.2 [Hatchling](#122-hatchling)
    - 12.3 [Juvenile](#123-juvenile)
    - 12.4 [Adolescent](#124-adolescent)
    - 12.5 [Adult](#125-adult)
    - 12.6 [Elder](#126-elder)
13. [Evolution — The Six Adult Forms](#13-evolution--the-six-adult-forms)
    - 13.1 [Deep-Sea Scholar](#131-deep-sea-scholar)
    - 13.2 [Reef Guardian](#132-reef-guardian)
    - 13.3 [Tidal Trickster](#133-tidal-trickster)
    - 13.4 [Abyssal Hermit](#134-abyssal-hermit)
    - 13.5 [Coral Dancer](#135-coral-dancer)
    - 13.6 [Storm Kraken](#136-storm-kraken)
14. [Rebirth & Legacy](#14-rebirth--legacy)

**VI. Progression & Collection**
15. [Bond Levels](#15-bond-levels)
16. [The Dialogue System](#16-the-dialogue-system)
17. [Decor & Cosmetics](#17-decor--cosmetics)
    - 17.1 [Hats & Headwear](#171-hats--headwear)
    - 17.2 [Backgrounds & Environments](#172-backgrounds--environments)
    - 17.3 [Accessories](#173-accessories)
    - 17.4 [Animation Styles](#174-animation-styles)
18. [Treasure Hunts](#18-treasure-hunts)

**VII. Achievements**
19. [Achievement System Overview](#19-achievement-system-overview)
20. [Care Achievements](#20-care-achievements)
21. [Exploration Achievements](#21-exploration-achievements)
22. [Social Achievements](#22-social-achievements)
23. [Environmental Achievements](#23-environmental-achievements)
24. [Mastery Achievements](#24-mastery-achievements)
25. [Step Achievements](#25-step-achievements)
26. [Secret Achievements](#26-secret-achievements)

**VIII. Environments & Scenes**
27. [The 22 Environments](#27-the-22-environments)
28. [Outfits & Decor Props](#28-outfits--decor-props)
29. [Aura & Particle Effects](#29-aura--particle-effects)

**IX. Controls & Navigation**
30. [Button Layout](#30-button-layout)
31. [Menu System](#31-menu-system)
32. [Quick Actions](#32-quick-actions)

**X. Tips & Secrets**
33. [Beginner Tips](#33-beginner-tips)
34. [Advanced Strategies](#34-advanced-strategies)
35. [Easter Eggs & Hidden Features](#35-easter-eggs--hidden-features)

---

# I. Introduction

## 1. What Is Dilder?

Dilder is a physical digital companion — a pocket-sized octopus that lives on an e-ink screen, reacts to the real world through sensors, and develops a genuine personality based on how you raise it. It's part Tamagotchi, part fitness tracker, part sassy roommate.

Carry Dilder in your pocket and it counts your steps. Talk to it and it gets smarter. Pet it and it relaxes. Neglect it and it gets sad — visibly, undeniably sad. Feed it too much and it gets fat. Shake it and it gets angry. Walk 10,000 steps and it throws a party.

Dilder grows through 6 life stages over 30+ real days, evolves into one of 6 adult forms based on how you raised it, and eventually enters an elder stage where it reflects on your journey together. When it's ready, it can lay an egg and start the cycle anew — passing down traits, decor, and a fraction of the bond you built.

The device runs on a custom PCB with an ESP32-S3 microcontroller, a 2.13" e-ink display (250x122 pixels, black and white), a 1000mAh battery, and sensors for light, sound, temperature, humidity, and motion. Everything renders in real-time — no pre-baked sprites, no stored frames. The octopus is drawn mathematically, line by line, 60 times a minute.

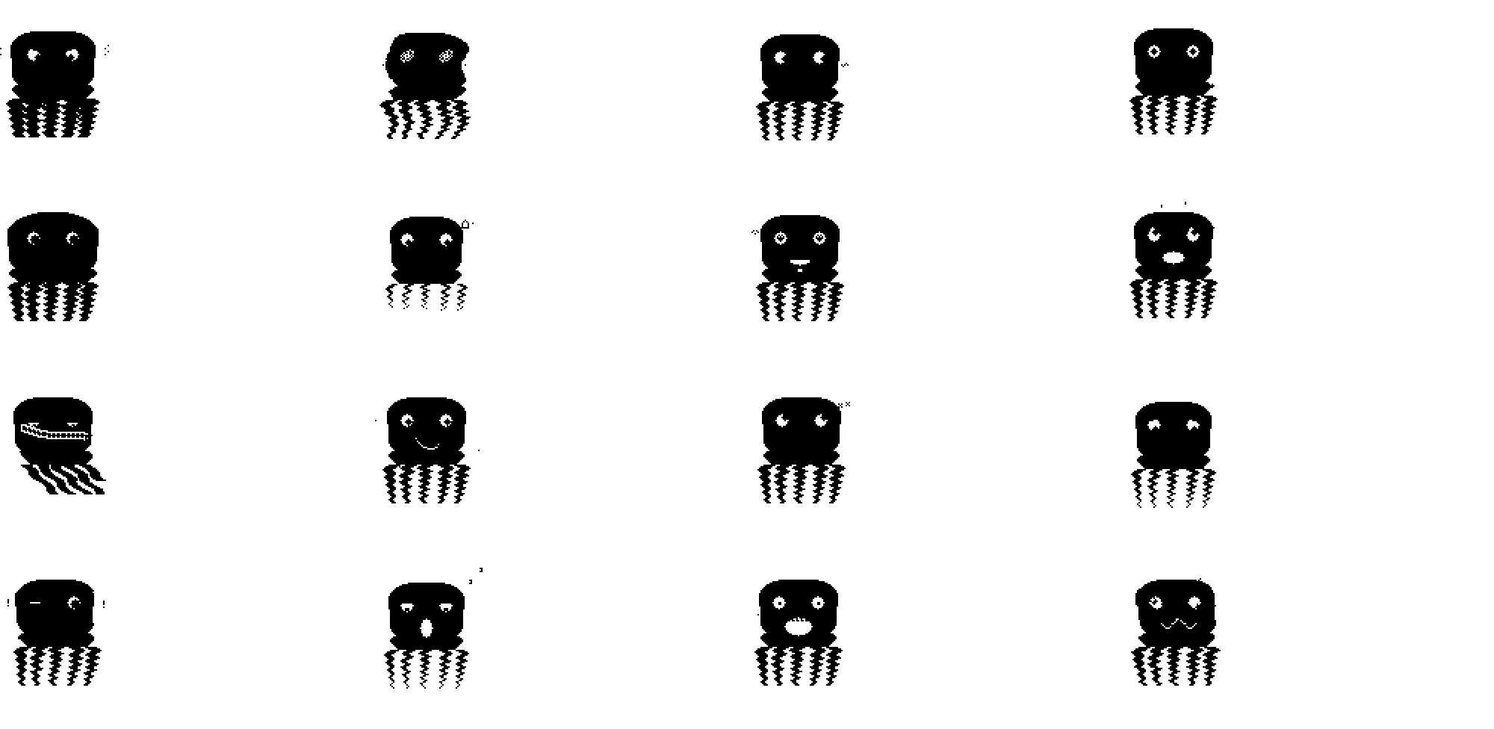
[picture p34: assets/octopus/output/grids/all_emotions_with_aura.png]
All 16 emotions with aura effects


---

## 2. The Origin Story — Meet Jamal

It started in a TEDi — a German discount store — with a massive plush octopus grinning from the sale bin. Soft as a cloud, impossibly charming, and suspiciously self-aware for a stuffed animal.

We bought him on impulse. On the walk home, something happened — we started talking *to* him. Then *about* him. A fully formed personality emerged between the shop and the front door: laid-back but opinionated, sassy but warm, suspiciously wise for a boneless creature.

He claimed the armchair the moment we walked in. He hasn't moved since. He later acquired a hat. Nobody remembers putting it there.

We named him **Jamal**.

Jamal, the original octopus

The logical next question: *what if we could bring him to life?* Not literally — but as a tiny digital companion on a screen. Something that lives in your pocket, reacts to the world, grows a personality, and judges your life choices.

Dilder is that answer. Named after... well, that's between us and Jamal.

Every aspect of Dilder's personality — the sass, the warmth, the unsolicited opinions — comes from Jamal. The 16 emotional states, the 823 quotes, the way it reacts when you yell at it ("...that was loud. Are you okay?") — it's all channeled from a plush octopus sitting in an armchair, wearing a hat, watching the whole project unfold with an expression that says "I could do better."

---

## 3. Your First Hatch

When you first power on your Dilder, you'll see an egg on the screen. It wobbles gently, waiting.

**To hatch your octopus:**
- **Tap the device** — Gently tap or shake the device (detected by accelerometer). Each tap adds progress.
- **Keep it warm** — A comfortable room temperature (18-24C) adds passive hatch progress.
- **Talk to it** — The microphone detects your voice. Talking to the egg helps it along.

At 25% progress, a crack appears. At 50%, the crack widens. At 75%, pieces begin to fall away. At 100% — your hatchling emerges.

Your tiny octopus blinks at the screen. It says its first word:

> "mama?"

Congratulations. You're a parent now.

---

# II. Getting to Know Your Octopus

## 4. The 16 Emotional States

Dilder expresses itself through 16 distinct emotions. Each has unique eyes, mouth animations, body language, and a curated set of quotes. The emotion your octopus displays is determined by its stats, the sensor environment, recent events, and a touch of randomness.

### 4.1 Normal / Sassy

Normal emotion

The default state when all stats are balanced (40-80 range). Centered pupils with white highlights, a cycling smirk-to-smile mouth, and a gentle 1-pixel breathing bob. This is Dilder at its most... Dilder. Sassy, supportive, full of opinions.

> "MATTRESSES ARE BODY SHELVES."

**Triggered by:** All stats balanced, no extreme sensor inputs.

### 4.2 Hungry

Hungry emotion

Pupils shift upward (staring at imaginary food), mouth drools with a wide oval and drip animation. Body leans up with a bobbing beg. Appears when hunger drops below 20.

> "hungwy..." (Hatchling)
> "I can't... eat... another... *burp*" (when overfed)

**Triggered by:** Hunger < 20. Intensity increases as hunger approaches 0.
**Fix:** Feed → Meal or Snack from the menu.

### 4.3 Tired

Tired emotion

Half-closed eyelids cover the top of each eye, tiny pupils sag low, and a tall vertical yawn opens and closes. The body droops 2-3 pixels and narrows slightly, as if deflating.

> "Five more minutes? The dark is so... dark."

**Triggered by:** Energy < 15, or late hour + low energy.
**Fix:** Turn off the light or place in a dark environment. Dilder will fall asleep and regenerate energy.

### 4.4 Sad

Sad emotion

Downward-looking pupils with droopy inverted-arc brows. A gentle frown that barely moves. The body drops 3 pixels lower than normal and narrows 1 pixel per side — a deflated, withdrawn posture.

> "I was starting to think you forgot about me..."

**Triggered by:** Happiness < 20, or no interaction for 4+ hours.
**Fix:** Pet, play, talk, or take a walk. Dilder recovers quickly — "You're back! I knew you'd come back!"

### 4.5 Angry

Angry emotion

Pupils shift inward and down in a glare, V-shaped brow arcs angle sharply, and a tight inverted frown sets the jaw. The body puffs 2 pixels wider and trembles — Dilder is making itself look bigger.

> "...that was loud. Are you okay?"

**Triggered by:** Harsh scolding (incorrect), violent shaking, or extreme hunger + low happiness combo.
**Fix:** Wait it out (30 seconds minimum dwell), then pet gently. Don't shake.

### 4.6 Excited

Excited emotion

Star-shaped cross pupils (plus signs in the eyes), a wide-open grin, and rapid 3-pixel vertical bouncing. Dilder is thrilled.

> "We did it! 5,000 steps! My tentacles are BURNING."

**Triggered by:** Just fed when very hungry, step milestone reached, achievement unlocked, treasure found.
**Duration:** Brief — 15 seconds of pure joy before settling.

### 4.7 Chill

Chill emotion

A cool side-glance with pupils shifted to one side, relaxed asymmetric half-smile, and a subtle lean-back sway. Dilder is at peace with the universe.

> "You know what? Life is good. Really good."

**Triggered by:** All stats > 60 in a calm environment (low noise, comfortable temperature).

### 4.8 Lazy

Lazy emotion

Nearly shut eyes with barely visible dot pupils, a flat horizontal line mouth, and the entire body tilted to lay on its side with tentacles draped rightward. The quintessential couch potato.

> "Whatever."

**Triggered by:** Energy 15-30 with no interaction for 2+ hours, or overweight.

### 4.9 Fat

Fat emotion

Wide, content pupils, a satisfied smile with puffy cheeks, and a custom body shape — wider dome (+5 pixels per side), no visible waist, thicker tentacles, and a gentle belly jiggle animation.

> "I can't... eat... another... *burp*"

**Triggered by:** Weight > 130 (normal is 100). Caused by overfeeding.
**Fix:** Play mini-games (-1 weight per session) and reduce feeding frequency.

### 4.10 Chaotic

Chaotic emotion

Spiral concentric-circle pupils, a zigzag lightning-bolt mouth, and wild 3-pixel sine-wave body distortion with random wobble. Everything is happening at once.

> (No coherent quotes — just chaos)

**Triggered by:** 5+ events in 30 seconds, or simultaneous shaking + loud noise. Very short dwell (10 seconds).

### 4.11 Weird

Weird emotion

Misaligned pupils (left looks up-left, right looks down-right), a wobbly sine-wave mouth, and a body lean with wavy row distortion. Dilder is being... Dilder.

> "Do fish know they're wet?"

**Triggered by:** 5% random chance per emotion tick when bored (1+ hour idle, moderate stats). One of the rarest regular emotions.

### 4.12 Unhinged

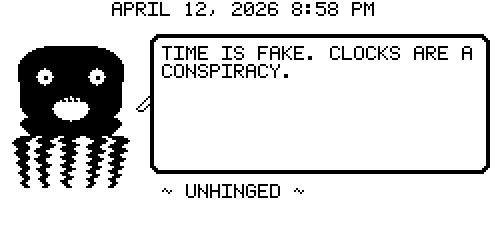
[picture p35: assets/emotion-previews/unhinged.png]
Unhinged emotion


Tiny 2x2 pinprick pupils with no highlights, a giant scream-mouth exposing teeth, and rapid 1-2 pixel random jitter. This is Dilder in crisis.

> (Distressed vocalizations only)

**Triggered by:** Health < 20 AND multiple stats critical simultaneously. This is the warning sign — your octopus needs help NOW.
**Fix:** Immediate care: feed, clean, administer medicine. Multiple actions in quick succession.

### 4.13 Slap Happy

Slap Happy emotion

One eye squinted shut (thin slit), one eye with an oversized manic pupil, a wide wobbly sine-wave grin, and a 3-pixel side-to-side swaying body with wavy row distortion. This is the emotional rebound.

> "HAHAHAHA I'M FINE I'M TOTALLY FINE"

**Triggered by:** Happiness > 90 after recently being < 30. The relief of recovery expressed as manic joy.

### 4.14 Creepy

Creepy emotion

Heart-shaped diamond pupils, a wide smile with tongue out, and a rhythmic throbbing pulse (body expands and contracts 2 pixels). Dilder is... feeling things.

> (Context-appropriate flirtatious quotes)

**Triggered by:** Adolescent or Adult stage + happiness > 70 + bond > threshold. Low probability (~2% per emotion tick). Rare and brief.

### 4.15 Nostalgic

Nostalgic emotion

Pupils looking up and to the right (remembering), a gentle wistful half-smile, and a slow 2-pixel horizontal + 1-pixel vertical sway. Dilder is thinking about the good old days.

> "Remember when I was just a hatchling? You were so attentive back then..."

**Triggered by:** Age milestones (every 7 days), or returning to a familiar location (home WiFi detected after being away).

### 4.16 Homesick

Homesick emotion

Teary eyes with pixel tear drops falling, a wobbly trying-not-to-cry mouth, and a body that curls 1 pixel down and 2 pixels narrower — shrinking inward.

> "I miss the armchair..."

**Triggered by:** Away from home WiFi for 4+ hours, or briefly when arriving at a completely new location.
**Fix:** Go home. Or comfort with the center button — interaction reduces Homesick faster.

---

## 5. Reading the Display

The e-ink screen is divided into three zones:

```
┌──────────────────────────────────────────────────┐  
│ 12:34 PM          [HUN][HAP][ENE][HYG][HEA]     │  Header (16px)
├──────────────────────────────────────────────────┤  
│                                                  │
│              YOUR OCTOPUS                        │  Pet Area (80px)
│              + equipped decor                    │
│                                                  │
├──────────────────────────────────────────────────┤  
│ "Good morning! I had the strangest dream..."     │  Dialogue (26px)
└──────────────────────────────────────────────────┘  
```

**Header Bar:** Current time on the left. Five stat icons on the right — each is a tiny bar that fills/empties proportionally. When a stat drops below 20, its icon inverts (white on black) to demand attention.

**Pet Area:** Your octopus, rendered in real-time with its current emotion, equipped hat, background, and accessories. Animations cycle through 4 frames.

**Dialogue Box:** Context-sensitive quotes appear here. They auto-dismiss after 5-15 seconds (scaling with quote length). Press SELECT to dismiss early.

---

# III. Caring for Dilder

## 6. The Stat System

### 6.1 Primary Stats

Five stats govern Dilder's wellbeing. All range from 0 to 100 and decay naturally over time:

| Stat | What It Represents | Decay Rate | Critical Threshold | Visual Cue |
|---|---|---|---|---|
| **Hunger** | Food level | -1 every 10 min | < 20 | Hungry emotion |
| **Happiness** | Emotional wellbeing | -1 every 15 min | < 20 | Sad emotion |
| **Energy** | Wakefulness | -1 every 12 min (awake) | < 15 | Tired emotion |
| **Hygiene** | Cleanliness | -1 every 30 min | < 25 | Uncomfortable |
| **Health** | Overall condition | Doesn't decay directly | < 30 | Sick / Unhinged |

**Health** is special — it doesn't decay on its own. Instead, it drops when multiple other stats are critical simultaneously. Keep hunger, happiness, energy, and hygiene healthy, and health stays at 100.

### 6.2 Secondary Stats

These accumulate over your octopus's lifetime and determine its evolution:

| Stat | How It Grows | What It Affects |
|---|---|---|
| **Bond Level** | Total interactions over lifetime | Unlocks features, dialogue, decor slots |
| **Discipline** | Correct scolding during misbehavior | Evolution path |
| **Intelligence** | Talking to Dilder, word exposure (mic) | Dialogue complexity and vocabulary |
| **Fitness** | Steps walked, distance traveled | Evolution, abilities, animations |
| **Exploration** | Unique locations visited (WiFi fingerprints) | Decor themes, world knowledge |
| **Age** | Real time since hatch | Life stage transitions |
| **Weight** | Feeding frequency (meals +1, snacks +2, play -1) | Visual change, Fat emotion trigger |

### 6.3 Hidden Stats

You can't see these directly, but they shape everything:

- **Care Mistakes** — Every time a critical stat goes unmet for 15 minutes, a care mistake is logged. Permanent. Affects evolution quality.
- **Consecutive Days** — Your streak of daily interaction. Streak bonuses at 3, 7, 14, 30, 60, 90, and 365 days.
- **Noise Exposure** — Cumulative loud sound events. Shapes personality traits.
- **Night Disturbances** — Times woken during sleep. Affects morning mood.

### 6.4 Stat Decay & Modifiers

Stat decay isn't constant — it's modified by context:

| Modifier | Effect on Decay |
|---|---|
| **Hatchling stage** | 2x faster (very needy baby) |
| **Elder stage** | 0.6x slower (self-sufficient) |
| **High bond level** | Happiness decays up to 15% slower |
| **Good environment** | 18-24C, 40-60% humidity → 10% slower hygiene decay |
| **Bad environment** | >28C or <15C → 30% faster decay |
| **Active hours** (8am-8pm) | Hunger decays 20% faster |
| **Walking** | Energy decays 30% faster, but happiness decays 20% slower |
| **14+ day streak** | Happiness decay reduced 10% |

---

## 7. Care Actions

### 7.1 Feeding

Open the menu → **Feed**:

| Food | Effect | Weight | Cooldown | Unlock |
|---|---|---|---|---|
| **Meal** | +30 Hunger | +1 | 30 seconds | Always available |
| **Snack** | +10 Hunger, +15 Happiness | +2 | 15 seconds | Always available |
| **Treat** | +5 Hunger, +25 Happiness | +3 | 60 seconds | Bond level 4 (Friend) |

**Overfeeding warning:** If weight exceeds 130, the Fat emotion triggers. Balance meals with play (which burns -1 weight per session).

### 7.2 Cleaning

Open the menu → **Care** → **Clean**:
- +40 Hygiene
- 60-second cooldown
- +5 Bond XP

### 7.3 Playing

Open the menu → **Play**:

| Game | Effect | Cost | Cooldown |
|---|---|---|---|
| **Mini-game** | +20 Happiness, -1 Weight | -10 Energy | 30 seconds |
| **Tickle** | +5 Happiness (quick) | None | 3 seconds |

Mini-games are the primary way to manage weight and boost happiness simultaneously.

### 7.4 Medicine

Open the menu → **Care** → **Medicine**:
- Only available when Health < 30 (the menu item is hidden otherwise)
- +20 Health
- 120-second cooldown
- Forces brief Sad emotion (medicine is yucky)

### 7.5 Scolding & Discipline

Dilder sometimes misbehaves — refusing food, making a mess, acting out. A prompt appears: **"Dilder is being defiant!"**

You have 60 seconds to respond:
- **Long-press ACTION (2 seconds):** Scold → +25 Discipline, brief Angry face, then compliance.
- **Yell into the mic:** Volume spike during misbehavior counts as scolding.
- **Ignore it:** Window closes with no penalty, but no discipline gained.

**Warning:** Scolding when Dilder ISN'T misbehaving (no prompt) → -10 Happiness, -5 Bond XP, and a Sad face. The game tracks correct vs. incorrect scolding. Discipline only grows from correct scolding.

4 discipline windows open per life stage. 100% discipline at a stage transition gives the best evolution path.

### 7.6 Sleep

Dilder sleeps when:
- **Auto-sleep:** Ambient light < 10 lux AND (energy < 20 OR it's after 10pm). Dilder shows a drowsy animation, then falls asleep after 30 seconds.
- **Manual sleep:** Open the menu → **Care** → **Light** to toggle sleep.

During sleep:
- Energy regenerates (+1 every 30 seconds → full in ~50 minutes)
- Other stats decay at 0.25x normal rate
- Display shows a sleeping animation (static, no refresh needed)
- Device enters low-power mode (~0.8mA)

**Wake triggers:** Bright light, loud noise, significant motion (picked up), button press, or energy reaching 95.

---

## 8. The Daily Rhythm

```
  MORNING (6am-10am)
  ┌──────────────────────────────────────┐
  │ Dilder wakes with the light          │
  │ Morning greeting based on mood       │
  │ Feed (hunger decayed overnight)      │
  │ Pet/interact for happiness boost     │
  └──────────────────────────────────────┘
              │
              ▼
  DAYTIME (10am-6pm)
  ┌──────────────────────────────────────┐
  │ Carry Dilder — steps tracked         │
  │ Locations detected (WiFi)            │
  │ Environmental sensing (light, temp)  │
  │ Periodic dialogue check-ins          │
  │ Random events (10% daily chance)     │
  └──────────────────────────────────────┘
              │
              ▼
  EVENING (6pm-10pm)
  ┌──────────────────────────────────────┐
  │ Feed again (hunger decayed)          │
  │ Review daily activity summary        │
  │ Play / interact for happiness        │
  │ Unlock rewards from step targets     │
  └──────────────────────────────────────┘
              │
              ▼
  BEDTIME (10pm-6am)
  ┌──────────────────────────────────────┐
  │ Lights dim → Dilder gets tired       │
  │ Place in dark → auto-sleep           │
  │ Low power mode                       │
  │ Stats decay slowly overnight         │
  │ Energy regenerates                   │
  └──────────────────────────────────────┘
```

---

# IV. The Physical World

## 9. Sensor Interactions

Dilder doesn't just live on a screen — it senses the real world around it.

### 9.1 Voice & Sound

The microphone (MAX9814) detects volume and patterns — not words (no speech recognition on the microcontroller):

| Sound | Detection | Effect |
|---|---|---|
| **Talking** (3+ seconds, moderate volume) | Sustained mid-level signal | +Intelligence, +Happiness |
| **Yelling** | High volume spike | Discipline (if misbehaving) or Scare |
| **Singing** | Rhythmic sustained pattern | +Happiness, special animation, contributes to Coral Dancer evolution |
| **Clapping** | Sharp spike then silence | Attention getter — Dilder looks at you |
| **Silence** (30+ minutes) | No signal above noise floor | Loneliness timer → Sad/Homesick |
| **Music** | Sustained varied signal | Chill mood boost |
| **Whispering** | Just above noise floor | Secret/intimate interaction, +Bond |

### 9.2 Light & Darkness

The BH1750 light sensor reads ambient light:

| Light Level | Lux | Effect |
|---|-----|---|
| **Bright daylight** | > 500 | Active mode, energy decay normal |
| **Indoor** | 100-500 | Standard operation |
| **Dim / Evening** | 10-100 | Dilder gets drowsy, starts yawning |
| **Dark** | < 10 | Sleep mode (if energy low) |
| **Sudden bright flash** | Delta > 300 in 5s | Startled reaction |
| **Dark but awake** | < 10 for 5+ min, energy > 50 | Scared / Homesick |

### 9.3 Temperature & Humidity

The AHT20 sensor reads the environment:

| Condition | Range | Effect |
|---|---|---|
| **Comfortable** | 18-24C, 40-60% RH | Chill mood bonus, 10% slower hygiene decay |
| **Too hot** | > 28C | Angry tendency, 30% faster hygiene decay |
| **Too cold** | < 15C | Sad tendency, huddle-up animation |
| **Very humid** | > 70% RH | Happy! (It's an octopus — it loves moisture) |
| **Very dry** | < 30% RH | Uncomfortable, "skin drying out" dialogue |
| **Temperature swing** | > 5C change in 10 min | Confused / Chaotic reaction |

### 9.4 Motion & Movement

The LIS2DH12TR accelerometer tracks:

| Motion | Detection | Effect |
|---|---|---|
| **Walking** | Hardware pedometer, 1-3 Hz | +Fitness, +Exploration XP |
| **Running** | Step frequency > 3 Hz | +Fitness (2x), Excited mood |
| **Stationary** (2+ hours) | No steps detected | Boredom → Lazy → Weird |
| **Picked up** | Orientation change | Alert — Dilder "wakes up" |
| **Shaking** | High-frequency irregular motion | Angry / Chaotic |
| **Dropping** | Free-fall detection | Scared reaction, health check |
| **Tilted > 45 degrees** | Sustained angle | Confused — "I'm sideways!" |

---

## 10. Step Tracking & Activity

### 10.1 Daily Step Targets

Every step you take with Dilder counts. Progressive daily goals unlock escalating rewards:

| Target | Steps | Reward | Dilder Says |
|---|---|---|---|
| **Bronze** | 2,000 | +10 XP, +5 happiness | "Nice walk! My tentacles feel stretchy." |
| **Silver** | 5,000 | +25 XP, +10 happiness, 1 snack | "Great job! We really covered some ground!" |
| **Gold** | 8,000 | +50 XP, +15 happiness, 20% cosmetic chance | "Wow! You're a machine!" |
| **Platinum** | 12,000 | +100 XP, +20 happiness, guaranteed cosmetic | "LEGENDARY! My fitness stat is through the ROOF!" |
| **Diamond** | 20,000 | +200 XP, full stat restore, rare cosmetic | "I didn't know legs could DO that. Respect." |

The step screen shows your progress:
```
┌──────────────────────────────────────┐
│  Today's Steps: 6,247                │
│  ██████████████░░░░░ 8,000 Gold      │
│                                      │
│  [check] Bronze  (2,000)             │
│  [check] Silver  (5,000)             │
│  [    ] Gold    (8,000) — 1,753 to go│
│  [    ] Platinum (12,000)            │
│  [    ] Diamond  (20,000)            │
└──────────────────────────────────────┘
```

### 10.2 Weekly Targets

Accumulate across the week (Monday–Sunday):

| Target | Steps | Reward |
|---|---|---|
| **Week Walker** | 10,000 | +50 XP, 3 snacks |
| **Week Runner** | 25,000 | +150 XP, random cosmetic, special dialogue |
| **Week Warrior** | 50,000 | +400 XP, rare cosmetic, +1 decor slot |
| **Week Legend** | 75,000 | +800 XP, legendary cosmetic, evolution XP bonus |
| **Week Titan** | 100,000+ | +1,500 XP, mythic reward, unique animation |

### 10.3 Monthly Targets

The "big goals" that drive long-term engagement:

| Target | Steps | Reward |
|---|---|---|
| **Monthly Mover** | 50,000 | +200 XP, monthly badge, 10% slower decay next month |
| **Monthly Marcher** | 100,000 | +500 XP, exclusive monthly cosmetic (unique per month!) |
| **Monthly Marathoner** | 200,000 | +1,200 XP, evolution accelerator, rare animation |
| **Monthly Monster** | 300,000 | +2,500 XP, legendary badge, permanent stat bonus |
| **Monthly Mythic** | 500,000+ | +5,000 XP, one-of-a-kind cosmetic, Hall of Fame |

**Monthly cosmetics are unique per calendar month.** Miss April's exclusive hat and it's gone forever.

### 10.4 The Streak System

Meet the Bronze daily target (2,000 steps) to keep your streak alive:

| Streak | Bonus |
|---|---|
| **3 days** | +25 XP, "Getting Started" badge |
| **7 days** | +100 XP, fire animation on step counter |
| **14 days** | +250 XP, happiness decay reduced 10% |
| **30 days** | +750 XP, exclusive cosmetic, bond boost |
| **60 days** | +2,000 XP, evolution guarantee (best path) |
| **90 days** | +5,000 XP, "Legendary Companion" title |
| **365 days** | +25,000 XP, "Eternal Bond" achievement |

**Streak protection:**
- **1 free miss per week** — Missing one day doesn't break the streak.
- **Streak freeze items** — Earned from treasure hunts. Allows 1 additional miss day.
- **Half-credit** — Walking 1,000-1,999 steps counts as a "half day." Two halves = one streak day.

---

## 11. Location & Exploration

Dilder detects your location using WiFi fingerprinting — it recognizes unique access points and builds a map of places you've been.

| Feature | Effect |
|---|---|
| **Home detection** | Dilder knows it's "home" — comfort bonus, no Homesick |
| **Away from home** | Adventure mode — +Exploration XP, but Homesick risk after 4 hours |
| **New location** | Discovery bonus! +25 XP, "Whoa, where are we?" dialogue |
| **Familiar location** | Nostalgic reaction, comfort |
| **Unique location count** | 5 locations → Explorer hat, 10 → ocean background, 25 → deep-sea animations |

---

# V. Growing Up

## 12. Life Stages

Your octopus grows through 6 stages over 30+ real days. Each stage changes its needs, available emotions, and personality.

### 12.1 Egg
**Duration:** Day 0-1

A wobbling egg on screen. No stats, no emotions. Just warmth, taps, and patience. Cracks appear at 25%, 50%, 75% progress. Hatches at 100%.

### 12.2 Hatchling
**Duration:** Day 1-3

A tiny octopus. Very needy — stat decay is **2x normal**. Limited emotions: Normal, Hungry, Tired, Sad, Excited. Cries every 3 minutes if hungry. Simple one-word dialogue: "mama?", "hungwy...", "*happy bubbles*"

4 misbehavior windows open during this stage for discipline.

### 12.3 Juvenile
**Duration:** Day 3-7

Growing and curious. Personality starts forming. Stat decay returns to 1.2x normal. Unlocks basic dialogue and the first decor slot. Adds Chill, Lazy, Angry, and Weird to the emotion set.

> "What's out there?" / "Are you my person?"

### 12.4 Adolescent
**Duration:** Day 7-14

Moody, unpredictable, tests boundaries. All 16 emotions now available. Full dialogue unlocked. Mini-games available. Rebellion events increase. Stat decay at normal rate.

> "Whatever." / "You don't understand me." / "Leave me alone... wait, don't."
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

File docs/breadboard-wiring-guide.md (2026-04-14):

# Breadboard Wiring Guide — Full Test Bench

> Complete wiring diagram and setup instructions for all current hardware components on a single breadboard with the Raspberry Pi Pico WH.

---

## Table of Contents

1. [Components](#1-components)
2. [Pin Assignment Table](#2-pin-assignment-table)
3. [Master Wiring Diagram](#3-master-wiring-diagram)
4. [Pico WH Pin Map — All Peripherals](#4-pico-wh-pin-map--all-peripherals)
5. [Component-by-Component Wiring](#5-component-by-component-wiring)
    - [5.1 Waveshare 2.13" e-Paper V3 (SPI1)](#51-waveshare-213-e-paper-v3-spi1)
    - [5.2 DollaTek 5-Way Joystick (GPIO)](#52-dollatek-5-way-joystick-gpio)
    - [5.3 GY-NEO6MV2 GPS Module (UART0)](#53-gy-neo6mv2-gps-module-uart0)
    - [5.4 HC-SR04 Ultrasonic Sensor (GPIO)](#54-hc-sr04-ultrasonic-sensor-gpio)
6. [Recommended 3.3V Speakers](#6-recommended-33v-speakers)
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

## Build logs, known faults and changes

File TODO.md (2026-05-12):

# Dilder — Rolling Daily TODO

A living task list updated each week. Newest entries at the top.

## Status legend

- `[x]` — done
- `[ ]` — open
- `[~]` — in progress / partial

## Index

- [Week 5 — 2026-05-12 (Full Board schematic: accel, joystick, power switch)](#week-5--2026-05-12-full-board-schematic-accel-joystick-power-switch)
- [Week 4 — 2026-05-08 (NoSolar+Buzzer enclosure overhaul)](#week-4--2026-05-08-nosolarbuzzer-enclosure-overhaul)
- [Week 3 — 2026-05-04 (Joystick PCB arrival, firmware versioning, V4 driver)](#week-3--2026-05-04-session-progress)

---

## Week 5 — 2026-05-12 (Full Board schematic: accel, joystick, power switch)

Project: **Dilder-PCB** — Dilder Full PCB Rev 1 (KiCad). All work in the working tree (not yet committed).

### Completed Today

#### Component selection (BOM additions)

- [x] **3-axis accelerometer chosen: SC7A20HTR** (Silan, LCSC `C19274408`) — LIS2DH-register-compatible, $0.16 @ qty 1k, 99,130 in stock at JLCPCB. Evaluated and rejected: LIS2DH12 ($0.44, 2.7× more expensive), genuine MPU-6050 ($8, TDK EOL'd 2020), QMI8658C (0 stock), MSA3S02/MSA321 (no docs), STK8321 (custom driver), QMA6100P (custom driver)
- [x] **Joystick confirmed: K1-1506SN-01** (Korean Hroparts, LCSC `C145910`) — same part already verified on hand-routed joystick PCB; no center/up swap risk
- [x] **Power switch chosen: MSK12C02** (Shou Han, LCSC `C431540`) — side-actuated SPDT SMD slide switch, $0.06 @ qty 1, 102k stock
- [x] **Passives library populated** — C1525 (100nF 0402), C15850 (10µF 0805), C25768 (2.2k 0402)

#### KiCad library work (`JLCPCB_lib.kicad_sym`)

- [x] Pulled SC7A20HTR + footprint + 3D model via `easyeda2kicad --lcsc_id=C19274408`
- [x] Pulled K1-1506SN-01 via `--lcsc_id=C145910`
- [x] Pulled MSK12C02 via `--lcsc_id=C431540`
- [x] Patched SC7A20HTR pin electrical types: SDO/CS → `input`, SDx/SCx → `bidirectional`, VDD/VDDIO/GND/GNDIO → `power_in`, INT1/INT2 → `output`, NC pads → `no_connect`
- [x] Patched K1-1506SN-01 with semantic pin names (`UP/DOWN/LEFT/RIGHT/CENTER/COM`) replacing the easyeda numeric names; all pins → `passive`
- [x] Patched 100nF / 10µF caps + 2.2k resistor pin types from `unspecified` / `input` → `passive`

#### SC7A20 schematic wiring (ERC clean)

- [x] Placed SC7A20HTR at (46.99, 130.81) in schematic
- [x] I²C0 bus wired: SDx → `I2C0_SDA` → Pico GP0, SCx → `I2C0_SCL` → Pico GP1 — matches `dilder-hub/main.c:181-182` exactly, zero firmware change needed
- [x] Interrupt: INT1 → `ACCEL_INT1` → Pico GP15 (avoided original GP22 plan because schematic uses GP22 for `EINK_BUSY`)
- [x] CS pulled to `+3V3` to lock I²C mode; SDO grounded to set address `0x18`
- [x] Decoupling caps placed: C4 (100nF on VDDIO), C5 (10µF bulk), C6 (100nF on VDD) — all GND returns to power ports
- [x] I²C pull-ups installed: R6/R7 (2 kΩ, functional substitute for 2.2 kΩ) — corrected from series-resistor topology after audit
- [x] NC pins (pin 4, 6, 11) carry no-connect flags
- [x] Three orphan-net `PCM_4ms_Power-symbol:+3.3V` placements caught and replaced with standard `power:+3V3` (on VDDIO, VDD, CS in sequence)
- [x] ERC: 0 errors, 0 warnings

#### Planning / mechanical decisions

- [x] Joystick placement decided: **back-mount on B.Cu** via `F` flip in PCB editor (thumb-access pattern). Will DNP in JLC BOM and hand-solder to avoid double-side assembly fee
- [x] Power switch placement decided: **Option A** — switch sits between battery+ and TP4056 BAT pin, so USB-only operation still works when switch is off. Pad 3 leaves NC (no slider-position short to GND); 4 mount tabs tied to GND
- [x] Verified GP map vs `board_config.h:226-241` — accel uses GP0/GP1/GP15 (free), joystick uses GP2-GP6 (free, matches firmware), e-ink uses GP17-GP22 (already wired)

### Resolved from earlier weeks

- [x] **"Determine a power on/off (leave power) mechanism"** (Week 3 carryover) — MSK12C02 picked, schematic plan locked
- [x] **"Fix KiCad joystick Rev 2 — re-route with corrected COM/UP pin assignment"** (Week 3 new items) — folded into Full Board schematic with verified pin map; standalone Rev 2 not needed
- [x] **"Add pin-1 silkscreen dot to future PCB orders"** (Week 3 new items) — incorporated as a layout-step reminder; planned for Full Board

### Still Open

- [ ] Place SC7A20 + joystick + slide switch footprints on the PCB layout (`F8 → Update PCB from Schematic`)
- [ ] Press `F` to flip the joystick to B.Cu and confirm silkscreen mirrors correctly
- [ ] Route I²C0 traces (GP0/GP1 → SC7A20) with the standard rules: ≤25 mm length, no acute corners, keep clear of switching nodes
- [ ] Drop GND vias under SC7A20 center pad (3-4 minimum) for thermal/return path
- [ ] Confirm `BAT_RAW` / `BAT_SW` nets propagated correctly after the slide switch is wired in
- [ ] Mark joystick row as DNP in the BOM/CPL export so JLC skips double-side assembly
- [ ] Replace R6/R7 with the imported 2.2 kΩ (`0402WGF2202TCE` / C25768) for BOM consistency — currently 2 kΩ (`0402WGF2001TCE`), functional but off-BOM
- [ ] Reconcile schematic vs firmware e-ink pin assignments — schematic uses GP17-GP22, `board_config.h:226-231` still says GP8-GP13; one side needs to change
- [ ] Add the new `PIN_I2C_SDA` / `PIN_I2C_SCL` / `PIN_ACCEL_INT1` / `ACCEL_I2C_ADDR` defines to `board_config.h` under `BOARD_PICO2_W`
- [ ] Patch `dilder-hub/main.c` MPU-6050 driver → SC7A20 / LIS2DH-style driver (register map: WHO_AM_I=0x33 at reg 0x0F, CTRL_REG1=0x20, OUT_X_L=0x28 with auto-increment MSB=1, 10-bit data right-shifted 6, ±2g = 256 LSB/g) — ~50 lines of changes, no consumer-API impact
- [ ] Commit today's schematic work to git (currently uncommitted in working tree)

### New Items from Today

- [ ] Add pin-1 silkscreen dot to SC7A20 + joystick + slide switch footprints before fab (lesson from Week 3's JLC placement-verification round-trip)
- [ ] Disable the `PCM_4ms_Power-symbol` library in KiCad preferences to prevent re-introducing orphan `+3.3V` nets (3 caught + fixed today)
- [ ] Update `IMU-DAC-SPEAKER-GUIDE.md` lines 33-34 — it still says I²C is on GP4/GP5, which conflicts with BTN_UP/BTN_RIGHT in `board_config.h`. Correct mapping is GP0/GP1
- [ ] Plan firmware patch: change MPU driver address probe from {0x68, 0x69} to {0x18, 0x19} and WHO_AM_I expected value to 0x33

---

## Week 4 — 2026-05-08 (NoSolar+Buzzer enclosure overhaul)

### Completed Today

- [x] Sound routing redesigned — removed through-floor port, added lateral cradle pit + horizontal channel exiting the cover -X side wall (`fdadd83`)
- [x] Base plate sides extended +5 mm (bp_h 4 → 9) for cable routing room — USB-C cutout + USB platform auto-track up 5 mm; cradle/cover/peripheral Z values cascaded (`fdadd83`)
- [x] BuzzerCradleRing containment ring added on base plate floor — 0.9 mm-thick ring keeps speaker laterally located (`fdadd83`)
- [x] Speaker lifted +2 mm in Z (Z=2.6 instead of 0.6) — 2 mm gap for wires to route along floor; cradle BuzzerPocket deepened 2 mm to compensate (`fdadd83`)
- [x] Wire pass-through notches in BuzzerCradleRing (don't cut floor — no holes on base plate underside) (`fdadd83`)
- [x] IMU pocket resized to MPU-6050 spec (20 × 15.6 mm), 2 corner mounting pegs added (15 mm hole-to-hole spacing on +Y long edge) (`fdadd83`)
- [x] PCB visualization updated — through-holes cut at peg positions (`fdadd83`)
- [x] Square peg-washer body added — 6×6×1.5 mm with 2.7 mm hole, 2 separate printable instances (`IMUPegWasher_MX`/`_PX`) (`fdadd83`)
- [x] Macro top-level docstring + many cascading Z comments rewritten to reflect new geometry (`fdadd83`)
- [x] IMU pegs nudged -1 mm in Y (`imu_hole_y_inset` 2.0 → 3.0) — peg/hole/washer Y from 28.8 → 27.8 (`312a65b`)
- [x] Wire channels now open-top slots cut through the full 5 mm BuzzerCradleRing height — wires drop in from above instead of threading through a hole (`312a65b`)

### Still Open

- [ ] Print and verify the new no-solar-buzzer build — confirm speaker friction-fit in deeper cradle pocket, wire channels clear, IMU pegs align with MPU-6050 board holes
- [ ] Verify the lateral sound channel actually projects audible sound out the cover side — may need to enlarge `buzz_port_d` past 2 mm
- [ ] Decide whether the BuzzerCradleRing needs an internal lip/shelf to physically support the lifted speaker (currently friction-fit in cradle pocket only)
- [ ] If the IMU board's hole positions don't match 15 mm spacing exactly, parameterize `imu_hole_spacing` from measurements

---

## Week 3 — 2026-05-04 (Session Progress)

### Completed Today

- [x] Joystick PCB arrived from JLCPCB — unboxed, photographed, tested
- [x] Discovered COM/UP pin swap in EasyEDA-imported KiCad symbol — root cause traced, schematic fixed for Rev 2
- [x] Wired joystick breakout to Pico 2 W — GPIO mapping confirmed: L=GP2, D=GP3, UP=GP4, R=GP5, C=GP6
- [x] GPIO diagnostic added to firmware — prints raw pin states at startup and every 2s during runtime
- [x] Switched display driver from V3 to V4 (internal LUT, no custom waveform tables)
- [x] Rewrote V4 partial refresh driver 4 times (V1.0→V1.4) — final version uses two-pass diff-based partial refresh for ghost-free updates
- [x] Added firmware version system (`version.h`, v0.5.4) — all 20 programs print version + build timestamp at startup
- [x] Added "Clean Build & Deploy" button to DevTool Programs tab
- [x] Changed all display variant defaults from V3 to V4 (CMakeLists, Dockerfile, DevTool dropdown)
- [x] Mk2 translucent case photos converted, named, placed in website assets
- [x] Front page gallery updated with Mk2 translucent + joystick PCB photos
- [x] Blog post and design evolution entries for Mk2 translucent prototype
- [x] Created rolling TODO.md at project root

### Still Open from Handwritten List

> OCR'd from handwritten notes (see `website/docs/assets/images/hardware/handwritten-todo-list-week3-20260504.jpg`)

- [ ] Wire up and test speaker
- [ ] Put a speaker grill cutout for the case
- [ ] Research if wireless firmware deployment is possible to streamline deploy and testing pipeline
- [x] ~~Wednesday: wire up joystick mount~~ (done — wired and tested 2026-05-04)
- [ ] Add a chamfer and joystick retention square so that it fits around snugly the base of the joystick
- [x] ~~Determine a power on/off (leave power) mechanism~~ (done — MSK12C02 slide switch picked, wired in Full Board schematic 2026-05-12)
- [ ] With joystick implement menu and settings system
- [ ] Stand: create a landing page and progression synopsis; purge the stale folders and pointers; perhaps migrate to a V2 repo and project structure
- [~] Compile a schematic for all the planned hardware; scour the web for best components and JLCPCB's basic components (add flash memory, high voltage level components) — *in progress: Full Board schematic now has Pico 2 W, e-ink header, charger, USB-C, accelerometer (SC7A20), joystick (K1-1506SN-01), power switch (MSK12C02). Still needed: speaker/DAC, flash memory*
- [ ] Estimate a board/print cost
- [ ] Run battery life benchmarks
- [ ] Estimate how thin this device could be with a dedicated board

### New Items from Today

- [x] ~~Fix KiCad joystick PCB Rev 2 — re-route with corrected COM/UP pin assignment, re-order from JLCPCB~~ (done — folded into Full Board schematic 2026-05-12 with verified K1-1506SN-01 pin map, no center/up swap)
- [ ] Verify all 5 joystick directions work with corrected wiring (swap COM/UP wires on current board as interim fix)
- [ ] Tune V4 two-pass partial refresh — blacks still slightly washed out with fast waveform, may need custom LUT or voltage adjustment
- [x] ~~Add pin-1 silkscreen dot to future PCB orders to prevent orientation ambiguity~~ (carried forward into Week 5 as a per-footprint reminder)
- [ ] Investigate why V4 display's internal LUT produces weaker blacks than V3's custom LUT — may need to source V3 panels or create hybrid driver

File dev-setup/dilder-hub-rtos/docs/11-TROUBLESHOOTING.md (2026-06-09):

# 11 — Troubleshooting (field diagnosis)

This chapter is the practical "a unit is misbehaving — what now?" guide. It was
written after a real round of field failures (three units showing "snow" and
refusing to boot) that turned out to be **e-ink BUSY-line solder faults**, not
dead silicon. The firmware now logs enough over serial to diagnose almost any
unit in one glance.

---

## 0. The master tool: read the serial log

Plug in USB and open the log (DevTool **Serial Monitor**, or `cat /dev/ttyACM1`).
Two lines tell you almost everything:

- **`[disp] refresh N ms`** — the e-ink health meter (printed every refresh when
  `EPD_TIMING` is on).
- **`[BATT] … rail=… | last on-battery=…`** — the power meter.

```
REFRESH-TIME METER                 BATTERY / CHARGE METER
~700 ms  → display HEALTHY          USB rail ~4.6 V            → VSYS read OK
~20 ms   → BUSY open / dead         last on-battery 3.9–4.2 V  → cell healthy
~5000 ms → BUSY stuck HIGH          last on-battery <3.3 V / 0 → drained/latched cell
(no [disp] lines at all → Display task hung = BUSY stuck, pre-timeout build)
```

> The `last on-battery` trick exists because serial needs USB, but USB hides the
> battery. The firmware retains the last on-battery reading and prints it while
> on USB — so: run on battery a few seconds, replug USB, read the line.

---

## 1. First question: is the board alive?

| Can you flash it (picotool / DevTool)? | Meaning |
|---|---|
| **Yes** | MCU + USB + flash programming are **fine** — the fault is a peripheral (display/battery), flash content, or the host. Go to §2. |
| **No `2e8a` in `lsusb`** | **Host USB wedge** (not the board) → replug / `sudo bash tools/devtool/fix_pico_usb.sh`, or hold **BOOTSEL** + replug. |

---

## 2. Symptom → test → cause → fix

| Symptom | Quick test (serial) | Likely cause | Fix |
|---|---|---|---|
| Snow, won't boot, flashes fine | `refresh ~20 ms` | e-ink **BUSY open/disconnected** (GP22) | **Reseat FPC**; reflow GP22 / J1 pin 6 joint. |
| Snow, frozen / "won't boot" | `refresh ~5000 ms` or **no `[disp]` lines** | e-ink **BUSY stuck HIGH** | **Reseat FPC**; clear a **solder bridge to 3V3** at the BUSY corner. |
| Boots, no auto-rotate / steps | `[ACCEL] NOT DETECTED` | accel missing / cold joint | Solder/reseat **SC7A20** — *cosmetic, not fatal*; firmware runs without it. |
| Battery stuck ~1%, never charges | `last on-battery <3.3 V`, won't rise | **charge starvation** (load on battery node) and/or **drained cell** | Charge with the Pico off; power-diet firmware; measure cell; Rev 2 power-path. |
| "Full" (STDBY) LED dim-blinking on USB | n/a (visual) | TP4056 **oscillating** — starvation or **latched/dead cell** | Charge with load removed → solid = starvation; still blinking = bad cell. |
| Won't boot, flashes fine, but `refresh ~700 ms` | display OK, app still wrong | **corrupted flash** (brownout during a write) | DevTool **Full Erase** → reflash. |
| Cell hot / puffy, LED never greens | n/a (visual) | over-discharged / damaged cell | ⚠️ Replace the cell; don't recharge a damaged LiPo. |

---

## 3. The e-ink BUSY repair loop

The e-ink is on **J1, a 2×4 header**. BUSY (pin 6) sits in a corner next to DC
(pin 4) and a power pin (pin 8) — the classic spot for a bridge or cold joint.

```
Reseat FPC → re-power → read [disp] refresh:
   ~700 ms  → FIXED (image should appear)
   ~5000 ms → BUSY still stuck HIGH  → clear bridge to 3V3 at the BUSY corner
   ~20 ms   → BUSY open / low        → reflow GP22↔J1 pin6; check flex seating
```

Continuity (power off): **BUSY ↔ GP22 pad** must beep (connected);
**BUSY ↔ GND** and **BUSY ↔ 3V3** must **not** beep (no bridge). The signal must
be continuous all the way **GP22 → J1 pin 6 → flex → panel BUSY**.

---

## 4. Battery / charge isolation test

```
1. Power the Pico OFF, charge JUST the TP4056 + cell:
     solid red → solid green  → charges fine alone → it was LOAD STARVATION
     still dim-blinking        → BAD / LATCHED cell
2. Multimeter on the cell:
     3.6–4.2 V → healthy (problem is the load/charge path)
     <3.0 V / 0 V / won't rise → over-discharged, protection latched → replace
3. Check the battery connector polarity/keying (reverse-insert can fry the TP4056).
```

---

## 5. Why the firmware no longer hard-freezes on bad hardware

Two boot-time waits used to be unbounded and could hang a task forever:

- **Accel I²C probe** — now uses `i2c_*_timeout_us` (see `mpu_init` /
  `mpu_read_*`). A missing or bus-stuck accelerometer can never hang boot; it
  just logs `NOT DETECTED` and `mpu_ok` stays false.
- **e-ink `EPD_2in13_V4_ReadBusy`** — now capped at ~3 s. A panel with BUSY stuck
  asserted can't freeze the Display task; it degrades to the slow refresh time
  (~5 s) that flags the fault, and the rest of the device stays alive.

Net effect: a dead sensor or a bad display **degrades to a diagnosable state**
instead of bricking the unit at boot — and the refresh-time/battery meters above
make the cause obvious.

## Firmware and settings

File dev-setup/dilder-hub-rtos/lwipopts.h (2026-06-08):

#ifndef _LWIPOPTS_H
#define _LWIPOPTS_H

/* ============================================================================
 *  lwipopts.h  —  configuration for lwIP (the TCP/IP networking stack)
 * ============================================================================
 *
 *  lwIP ("lightweight IP") is the small open-source networking stack the Pico
 *  uses for Wi-Fi: DHCP (get an IP address), DNS (resolve names), UDP/TCP, and
 *  SNTP (fetch the time). Like FreeRTOS, it is configured entirely with #defines
 *  in a file the build looks for by the name `lwipopts.h`.
 *
 *  WHY THIS FILE CHANGED FOR THE RTOS BUILD
 *  ----------------------------------------
 *  The original dilder-hub used lwIP in "NO_SYS" (bare-metal/polled) mode: there
 *  was no operating system, so the main loop had to call cyw43_arch_poll()
 *  constantly to let the stack do work. That is exactly the busy-polling we are
 *  trying to escape.
 *
 *  Under FreeRTOS we instead use lwIP's "OS mode" (NO_SYS = 0). In this mode lwIP
 *  runs inside its own FreeRTOS task (the "tcpip thread"), driven by the cyw43
 *  driver's async-context. No more manual polling — the kernel schedules the
 *  networking work like any other task. The cost is a few extra settings below
 *  (thread stack size, mailbox sizes) that only exist in OS mode.
 *
 *  See docs/03-DESIGN-AND-ARCHITECTURE.md for how this fits the task model.
 * ========================================================================== */

/* ----------------------------------------------------------------------------
 *  OS mode vs bare-metal mode
 * ------------------------------------------------------------------------- */

/* 0 = run lwIP under an operating system (FreeRTOS). This is THE key change from
 * the original firmware's `NO_SYS 1`. It makes lwIP create and use a background
 * task instead of requiring us to poll it. */
#define NO_SYS                      0

/* "Core locking" is lwIP's simplest thread-safety model: a single lock protects
 * the whole stack. Application code (our NTP/scan triggers) must hold that lock
 * while calling lwIP — the Pico SDK gives us cyw43_arch_lwip_begin()/_end() that
 * take/release it for us. This is simpler and faster than the alternative
 * (message-passing into the tcpip thread) and is the SDK's recommended setup. */
#define LWIP_TCPIP_CORE_LOCKING     1

/* In OS mode lwIP needs a lightweight critical-section primitive for short
 * internal protections; enable it. */
#define SYS_LIGHTWEIGHT_PROT        1

/* We use only lwIP's "raw" callback API plus SNTP. We do NOT use the BSD-style
 * sockets API or the netconn API (those need extra threads/RAM). Keep them off. */
#define LWIP_SOCKET                 0
#define LWIP_NETCONN                0

/* ----------------------------------------------------------------------------
 *  The tcpip thread (only exists because NO_SYS = 0)
 * ------------------------------------------------------------------------- */

/* Stack size (bytes) for lwIP's background task. 1 KB is the SDK default and is
 * enough for DHCP/DNS/SNTP. */
#define TCPIP_THREAD_STACKSIZE      1024

/* FreeRTOS priority for the tcpip thread. Kept modest — networking should not
 * outrank our Input task. (A small positive number; the kernel idle task is 0.) */
#define TCPIP_THREAD_PRIO           4

/* "Mailboxes" are the queues lwIP uses to hand packets/requests to the tcpip
 * thread. These sizes must be defined in OS mode. 8 entries each is plenty for a
 * device that only talks to an NTP server and scans Wi-Fi. */
#define TCPIP_MBOX_SIZE             8
#define DEFAULT_UDP_RECVMBOX_SIZE   8
#define DEFAULT_TCP_RECVMBOX_SIZE   8
#define DEFAULT_RAW_RECVMBOX_SIZE   8
#define DEFAULT_ACCEPTMBOX_SIZE     8

/* ----------------------------------------------------------------------------
 *  Memory pools (unchanged from the original — sized for a tiny client)
 * ------------------------------------------------------------------------- */
#define MEM_LIBC_MALLOC             0   /* use lwIP's own pool, not C malloc */
#define MEM_ALIGNMENT               4   /* 32-bit CPU → 4-byte alignment */
#define MEM_SIZE                    4000

#define MEMP_NUM_TCP_PCB            4
#define MEMP_NUM_TCP_SEG            16
#define MEMP_NUM_ARP_QUEUE          4
#define MEMP_NUM_NETBUF             2
#define MEMP_NUM_NETCONN            4

#define PBUF_POOL_SIZE              16

/* ----------------------------------------------------------------------------
 *  Protocol features we need (DHCP for an IP, DNS + SNTP for the clock)
 * ------------------------------------------------------------------------- */
#define LWIP_ARP                    1
#define LWIP_ETHERNET               1
#define LWIP_ICMP                   1
#define LWIP_RAW                    1
#define LWIP_TCP                    1
#define LWIP_UDP                    1
#define LWIP_IPV4                   1
#define LWIP_DHCP                   1
#define LWIP_DNS                    1

/* SNTP — the Simple Network Time Protocol client that sets our clock. The macro
 * hands the received time to our callback (defined in the firmware). */
#define LWIP_SNTP                   1
#define SNTP_SERVER_DNS             1
#define SNTP_MAX_SERVERS            2
#define SNTP_SET_SYSTEM_TIME_US(sec, us) sntp_set_system_time_cb(sec, us)

#define LWIP_NETIF_STATUS_CALLBACK  1
#define LWIP_NETIF_LINK_CALLBACK    1

#define TCP_WND                     (4 * TCP_MSS)
#define TCP_MSS                     1460
#define TCP_SND_BUF                 (4 * TCP_MSS)

#define LWIP_CHKSUM_ALGORITHM       3

#define LWIP_HTTPD_CGI              0
#define LWIP_HTTPD_SSI              0

#endif

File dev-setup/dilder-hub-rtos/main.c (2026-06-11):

/**
 * Sassy Octopus — Runtime-rendered e-ink animation
 *
 * Instead of pre-baking every frame, this firmware renders each frame
 * on the fly: composites the octopus body, eyes, mouth expression,
 * chat bubble, and text at display time.  This means ALL quotes fit
 * in flash (~10KB of strings vs ~4MB of bitmaps).
 *
 * Wiring — Dilder PCB / breadboard SPI0 (GP17-22, see DEV_Config.c):
 *   VCC  -> 3V3(OUT) pin 36    GND  -> GND      pin 38
 *   CS   -> GP17     pin 22    SCL  -> GP18     pin 24  (SPI0 SCK)
 *   SDA  -> GP19     pin 25    DC   -> GP20     pin 26  (SPI0 TX)
 *   RES  -> GP21     pin 27    BUSY -> GP22     pin 29
 */

#include <stdio.h>
#include <stdlib.h>
#include <string.h>
#include <math.h>
#include <time.h>
#include "pico/stdlib.h"
#include "pico/cyw43_arch.h"
#include "hardware/pwm.h"
#include "hardware/adc.h"
#include "hardware/i2c.h"
#include "hardware/flash.h"
#include "hardware/sync.h"
/* --- FreeRTOS: the real-time kernel that schedules our tasks across both cores.
 *     FreeRTOS.h MUST come first (it pulls in FreeRTOSConfig.h); task.h adds the
 *     task/scheduler API (xTaskCreate, vTaskStartScheduler, vTaskDelay, ...). --- */
#include "FreeRTOS.h"
#include "task.h"
#include "pico/flash.h"        /* flash_safe_execute — multicore-safe flash writes (SMP) */
#include "rtos_tasks.h"        /* Phase 2: the 4-task split interface */
#include "lwip/dns.h"
#include "lwip/pbuf.h"
#include "lwip/udp.h"
#include "rtc_compat.h"
#include "DEV_Config.h"
#include "version.h"
#include "wifi_config.h"
#include "bt.h"
#ifdef PICOWOTA_OTA
#include "picowota/reboot.h"
#endif

/* ─── Joystick pins ─── */
#define JOY_LEFT   2
#define JOY_DOWN   3
#define JOY_UP     4
#define JOY_RIGHT  5
#define JOY_CENTER 6

/* ─── Speaker (active buzzer on GP14) ─── */
/* Wire: buzzer (+) → pin 19 (GP14), buzzer (-) → GND (pin 18). */
#define BUZZER_PIN 14  /* GP14 = pin 19 — active buzzer (+) */

static bool sound_enabled = true;
static uint8_t sound_vol = 2;  /* 0=short, 1=med, 2=long beep duration */
static const uint16_t vol_durations[] = {20, 50, 100};  /* ms per level */

static void speaker_init(void) {
    gpio_init(BUZZER_PIN);
    gpio_set_dir(BUZZER_PIN, GPIO_OUT);
    gpio_put(BUZZER_PIN, 0);
}

static void speaker_tone(uint16_t freq_hz, uint16_t duration_ms) {
    if (!sound_enabled || freq_hz == 0) { sleep_ms(duration_ms); return; }
    uint16_t actual = duration_ms < vol_durations[sound_vol] ? duration_ms : vol_durations[sound_vol];
    gpio_put(BUZZER_PIN, 1);
    sleep_ms(actual);
    gpio_put(BUZZER_PIN, 0);
    if (duration_ms > actual) sleep_ms(duration_ms - actual);
}

/* ─── Sound patterns (on_ms, off_ms pairs; 0 terminates) ─── */
static const uint16_t pat_beep[]     = {150, 0};
static const uint16_t pat_chirp[]    = {30,30, 30,30, 30,30, 30,30, 30, 0};
static const uint16_t pat_sos[]      = {60,60, 60,60, 60,180, 180,60, 180,60, 180,180, 60,60, 60,60, 60, 0};
static const uint16_t pat_doorbell[] = {200, 100, 300, 0};
static const uint16_t pat_alert[]    = {300,200, 300,200, 300, 0};
static const uint16_t pat_happy[]    = {40,60, 40,60, 40,60, 200,100, 50,50, 50,50, 300, 0};

#define SOUND_PATTERN_COUNT 6
static const char *pattern_names[] = {"BEEP", "CHIRP", "SOS", "DOORBELL", "ALERT", "HAPPY"};
static const uint16_t *patterns[]  = {pat_beep, pat_chirp, pat_sos, pat_doorbell, pat_alert, pat_happy};
static int current_pattern = 0;

static void play_sound_pattern(int idx) {
    if (!sound_enabled || idx < 0 || idx >= SOUND_PATTERN_COUNT) return;
    const uint16_t *p = patterns[idx];
    while (*p) {
        uint16_t on_ms = *p++;
        uint16_t actual = on_ms < vol_durations[sound_vol] ? on_ms : vol_durations[sound_vol];
        gpio_put(BUZZER_PIN, 1);
        sleep_ms(actual);
        gpio_put(BUZZER_PIN, 0);
        if (on_ms > actual) sleep_ms(on_ms - actual);
        if (*p) { sleep_ms(*p); p++; }
    }
}

/* ─── Joystick init ─── */
#if INPUT_USE_IRQ
/* GPIO interrupt callback (shared by all 5 joystick pins). Fires on every press
 * AND release edge; it does nothing but wake the Input task instantly — all the
 * debounce/edge/repeat logic lives in the task, off the interrupt.
 * Compiled only when INPUT_USE_IRQ=1 (bench-only — see rtos_tasks.h). */
static void joystick_irq_cb(uint gpio, uint32_t events) {
    (void)gpio; (void)events;
    rtos_input_isr_notify();
}
#endif

static void joystick_init(void) {
    const uint pins[] = {JOY_UP, JOY_DOWN, JOY_LEFT, JOY_RIGHT, JOY_CENTER};
    for (int i = 0; i < 5; i++) {
        gpio_init(pins[i]);
        gpio_set_dir(pins[i], GPIO_IN);
        gpio_pull_up(pins[i]);
    }
#if INPUT_USE_IRQ
    /* Interrupt-driven input: wake the Input task the instant any line changes,
     * instead of polling. Sub-millisecond press latency, and the core idles when
     * nothing is pressed (better for battery). One callback is shared by all
     * pins; register it on the first, then enable the IRQ on the rest.
     * GATED OFF by default: this path soft-bricked the RP2350 under FreeRTOS SMP
     * and is not yet root-caused. Enable only on the bench with serial. */
    gpio_set_irq_enabled_with_callback(pins[0], GPIO_IRQ_EDGE_FALL | GPIO_IRQ_EDGE_RISE,
                                       true, joystick_irq_cb);
    for (int i = 1; i < 5; i++)
        gpio_set_irq_enabled(pins[i], GPIO_IRQ_EDGE_FALL | GPIO_IRQ_EDGE_RISE, true);
#endif
}

/* ─── Joystick read (returns single direction or 0) ─── */
#define INPUT_NONE   0
#define INPUT_UP     1
#define INPUT_DOWN   2
#define INPUT_LEFT   3
#define INPUT_RIGHT  4
#define INPUT_CENTER 5

/* ─── Input orientation remap ───────────────────────────────────────────
 * The joystick's physical up/down/left/right are remapped to logical
 * directions through a rotation, so the firmware can match how the device is
 * actually held.  On the Dilder board (held screen-left / joystick-right) the
 * physical axes read reversed, so we default to 180° (up<->down, left<->right).
 *
 * This is the single hook the accelerometer feature will drive: once the IMU
 * is installed, call input_set_rotation() from the orientation logic and every
 * joystick read auto-rotates — no other code changes needed.
 */
typedef enum { ROT_0 = 0, ROT_90 = 1, ROT_180 = 2, ROT_270 = 3 } input_rotation_t;
/* volatile: written by the Housekeeping task (orientation_update) and read by the
 * higher-priority Input task (read_joystick). A single aligned enum store is
 * atomic on the Cortex-M33, so no torn read — `volatile` just stops the compiler
 * caching it. INVARIANT: both Housekeeping and Input are pinned to core 0; if a
 * future phase moves either off core 0 this must become snapshot-/mutex-guarded. */
static volatile input_rotation_t input_rotation = ROT_180;  /* default for the Dilder hold */

/* Display orientation state (declared early so the accel orientation_update()
 * can drive it). display_rotation is the panel-map angle (see transpose);
 * g_orientation is the 0..3 hold from the accelerometer. */
static int display_rotation = 90;
static int g_orientation = 0;

/* While calibrating: 1 = log accel/orientation to serial AND draw an on-screen
 * HUD (accel + orientation). Set to 0 once the orientation map is dialed in. */
#define ORIENT_DEBUG 0
#define FACE_DEBUG 0

void input_set_rotation(input_rotation_t r) { input_rotation = r; }

/* ── Orientation model: 3 valid holds (joystick ABOVE the screen is ignored) ──
 *   OR_LAND_R = landscape, joystick RIGHT  → WIDE side-by-side
 *   OR_LAND_L = landscape, joystick LEFT   → WIDE side-by-side (flipped)
 *   OR_TALL   = portrait,  joystick BOTTOM → TALL longways
 * Per-orientation display + joystick input rotation in one table — CALIBRATE
 * from the on-screen HUD, then adjust this table and the classifier. */
enum { OR_LAND_R = 0, OR_LAND_L = 1, OR_TALL = 2 };
typedef struct { bool tall; int disp_rot; input_rotation_t in_rot; } orient_cfg_t;
static const orient_cfg_t ORIENT_CFG[3] = {
    /* OR_LAND_R */ { false, 90,  ROT_180 },
    /* OR_LAND_L */ { false, 270, ROT_0   },
    /* OR_TALL   */ { true,  180, ROT_270 },   /* joystick-bottom: display flipped, input +180 */
};
static bool orientation_is_tall(void) { return ORIENT_CFG[g_orientation].tall; }

/* Display settings (runtime mirror of g_saved.auto_rotate / .manual_orient, which
 * are declared much later; loaded in saved_load). When auto_rotate is false,
 * orientation_update() locks g_orientation to g_manual_orient. */
static bool    g_auto_rotate   = true;
static uint8_t g_manual_orient = OR_TALL;

/* Directions in clockwise order; the rotation is how many 90° CW steps the
 * device is turned, so a press maps forward around the ring by that many. */
static const uint8_t CW_RING[4] = { INPUT_UP, INPUT_RIGHT, INPUT_DOWN, INPUT_LEFT };

static uint8_t rotate_input(uint8_t dir) {
    if (dir == INPUT_NONE || dir == INPUT_CENTER) return dir;  /* center is rotation-invariant */
    for (int i = 0; i < 4; i++) {
        if (CW_RING[i] == dir)
            return CW_RING[(i + (int)input_rotation) & 3];
    }
    return dir;
}

/* Non-static: the Input task (rtos_tasks.c) is the sole runtime caller. */
uint8_t read_joystick(void) {
    uint8_t raw = INPUT_NONE;
    if      (!gpio_get(JOY_UP))     raw = INPUT_UP;
    else if (!gpio_get(JOY_DOWN))   raw = INPUT_DOWN;
    else if (!gpio_get(JOY_LEFT))   raw = INPUT_LEFT;
    else if (!gpio_get(JOY_RIGHT))  raw = INPUT_RIGHT;
    else if (!gpio_get(JOY_CENTER)) raw = INPUT_CENTER;
    return rotate_input(raw);
}

/* ─── App states ─── */
#define STATE_OCTOPUS     0   /* main screen — octopus + quote + clock */
#define STATE_MENU        1   /* menu overlay */
#define STATE_SOUND       2   /* sound test sub-screen */
#define STATE_INFO        3   /* device info sub-screen */
#define STATE_MOOD_SELECT 4   /* mood picker */
#define STATE_NETWORK     5   /* WiFi status (read-only) */
#define STATE_NET_MENU    6   /* Network submenu */
#define STATE_NET_SCAN    7   /* Scan results list */
#define STATE_NET_KEYBOARD 8  /* On-screen keyboard for WiFi password */
#define STATE_MOTION       9  /* Accelerometer / pedometer menu */
#define STATE_SET_TIME    10  /* Manual date/time setter */
#define STATE_SAVED_NETS  11  /* Saved WiFi networks (connect / forget) */
#define STATE_BLUETOOTH   12  /* Bluetooth pairing screen */
#define STATE_SOCIAL          13  /* Social menu (toggle, met list, set name) */
#define STATE_SOCIAL_PROMPT   14  /* "Dilder found — say hi?" Y/N */
#define STATE_SOCIAL_RECV     15  /* "Dilder says hello!" — say hi back? Y/N */
#define STATE_SOCIAL_NAME     16  /* reroll picker for your Dilder name */
#define STATE_SOCIAL_MET      17  /* list of Dilders we've met */
#define STATE_SOCIAL_NEARBY   18  /* live list of Dilders in range now */
#define STATE_EMOTE_PICK      19  /* pick an emote to send to g_social_peer */
#define STATE_EMOTE_PLAY      20  /* octopus acts out g_play_emote, then g_play_next */
#define STATE_DISPLAY         21  /* Display settings: auto-rotate + orientation */

/* ─── WiFi state ─── */
static bool wifi_enabled = false;
static bool wifi_connected = false;
static bool ntp_synced = false;

/* Bluetooth is OFF by default to save power; toggled on in the Bluetooth screen. */
static bool bt_enabled = false;

/* ── Social UI state (the Dilder a prompt/recv screen is currently about) ── */
static uint16_t g_social_peer      = 0;
static int8_t   g_social_peer_rssi = 0;
static uint16_t g_name_seed        = 0;   /* candidate seed on the Set-Name reroll screen */

/* Live "scan nearby" buffer — distinct Dilder ids seen while the screen is open. */
#define NEARBY_MAX 8
static uint16_t g_nearby_id[NEARBY_MAX];
static int8_t   g_nearby_rssi[NEARBY_MAX];
static int      g_nearby_count = 0;

/* Emote playback: which emote the octopus is acting out, who it's about, whether
 * we received it (vs sent), and which state to enter once the animation ends. */
static uint8_t  g_play_emote    = 0;
static bool     g_play_incoming = false;
static uint8_t  g_play_next     = 0;
static int      g_emote_sel     = 0;
static int32_t wifi_rssi = 0;
static char wifi_ssid_display[33] = "---";
static char wifi_ip_str[20] = "---";

/* ─── WiFi scan state ─── */
#define MAX_SCAN_RESULTS 16
typedef struct { char ssid[33]; int8_t rssi; uint8_t auth_mode; } scan_entry_t;
static scan_entry_t scan_results[MAX_SCAN_RESULTS];
static int  scan_count = 0;
static int  scan_sel = 0;
static bool scan_in_progress = false;
static bool scan_complete = false;

/* ─── On-screen keyboard state ─── */
#define PW_MAX_LEN 63
static char pw_buf[PW_MAX_LEN + 1];
static int  pw_len = 0;
static int  kb_row = 0;
static int  kb_col = 0;
static bool kb_shift = true;   /* start in CAPS mode */
static int  selected_network = -1;

static const char kb_grid[4][10] = {
    {'Q','W','E','R','T','Y','U','I','O','P'},
    {'A','S','D','F','G','H','J','K','L','.'},
    {'Z','X','C','V','B','N','M','-','!','?'},
    {'0','1','2','3','4','5','6','7','8','9'},
};
#define KB_CHAR_ROWS 4
#define KB_SPECIAL_ROW 4
#define KB_SP_SHIFT  0
#define KB_SP_SPACE  1
#define KB_SP_DEL    2
#define KB_SP_DONE   3
#define KB_SP_CANCEL 4
#define KB_SP_COUNT  5

static char kb_char_at(int row, int col, bool shift) {
    if (row >= KB_CHAR_ROWS) return '\0';
    char c = kb_grid[row][col];
    if (!shift && c >= 'A' && c <= 'Z') return c + 32;
    return c;
}
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
int main(void) {
    stdio_init_all();
    sleep_ms(50);   /* brief settle; was 1000ms of pure boot delay for USB serial */
    printf("DILDER HUB v%s (%s) | display: %s | %d quotes | built %s %s\n",
           DILDER_VERSION, DILDER_VERSION_DATE, DISPLAY_NAME, QUOTE_COUNT, __DATE__, __TIME__);

    init_rtc_from_compile_time();

    if (DEV_Module_Init() != 0) {
        printf("ERROR: Hardware init failed.\n");
        return 1;
    }

    joystick_init();
    speaker_init();

#ifdef PICOWOTA_OTA
    /* Hold the joystick UP at power-on to drop into the picowota WiFi
       bootloader for an over-the-air firmware update. Pull-ups are active
       (joystick is active-low), so give them a moment to settle first. */
    sleep_ms(20);
    if (!gpio_get(JOY_UP)) {
        speaker_tone(2000, 60);  /* audible "entering OTA" cue */
        picowota_reboot(true);
    }
#endif

    /* Startup chime */
    speaker_tone(1000, 80); sleep_ms(30);
    speaker_tone(1500, 80); sleep_ms(30);
    speaker_tone(2000, 120);

    /* NOTE: EPD_Init()/EPD_Clear() are NO LONGER called here. The e-ink panel is
     * now owned exclusively by the Display task (core 1), which initialises it in
     * its prologue (display_init_panel). DEV_Module_Init() above already brought
     * up the SPI bus on the boot core, which is fine (one-time, pre-scheduler). */
    rng_seed();

    /* ═══════════ Hand control to the FreeRTOS scheduler ═══════════
     * Everything above ran "bare metal": plain function calls on the boot core,
     * no kernel yet. Now we create our application task and start the scheduler.
     *
     * WHY create a task instead of just continuing? Because the FreeRTOS-flavour
     * cyw43/Wi-Fi/Bluetooth driver spins up its OWN background task, which only
     * works once the scheduler is running. So cyw43_arch_init() and the whole
     * app loop must happen *inside* a task, not here in plain main().
     *
     * vTaskCoreAffinitySet pins this task to core 0 (bit 0). vTaskStartScheduler
     * NEVER returns — from here on the kernel owns the CPUs and runs our tasks. */
    xTaskCreate(app_task, "app", APP_TASK_STACK_WORDS, NULL, APP_TASK_PRIO, &g_app_task);
    vTaskCoreAffinitySet(g_app_task, (1u << 0));   /* run on core 0 */
    vTaskStartScheduler();

    /* Unreachable: the scheduler only returns if it ran out of heap for the idle
     * task, which our hooks/heap size prevent. Hang loudly if it ever happens. */
    printf("FATAL: scheduler returned\n");
    for (;;) { }
}

/* ─── The single application task (Phase 1) ───
 * Identical work to the original firmware, just now running as a FreeRTOS task.
 * Phase 2 carves the body below into separate Input/UI/Display/Housekeeping
 * tasks; for now it stays monolithic so we can verify the RTOS plumbing alone. */
static void app_task(void *param) {
    (void)param;   /* we don't use the task argument; cast-to-void silences the warning */

    /* Init CYW43 early — even without WiFi, the chip's SPI CS shares
       GPIO 29 (ADC3/VSYS sense) and will hold it low if uninitialised. Under the
       FreeRTOS cyw43 arch this also starts the networking background task. */
    if (cyw43_arch_init()) {
        printf("WARNING: CYW43 init failed — battery reads may be 0\n");
    }
    /* WiFi is NOT auto-connected at boot — that blocked startup for up to ~15s.
       Credentials are cached (saved-networks store, seeded with Moop Ship +
       MoopsterCell), so connecting from the Network menu needs no password
       entry. The clock NTP-syncs whenever WiFi is connected. */

    battery_init();
    mpu_init();

    /* ═══ Phase 2: spin up the Input, Display, and Housekeeping tasks ═══
     * From here on THIS task is the UI task: it renders, runs the state machine,
     * gets input from the Input task's queue, and hands finished frames to the
     * Display task (core 1). cyw43_arch_init() above stays on this (core 0) task,
     * which is where the cyw43/Wi-Fi/BT background task must live. */
    rtos_tasks_start();

    /* Wait (explicit handshake, not a timing guess) for the Display task on core 1
     * to register with the flash lockout before saved_load() — which may write
     * flash on first boot — so that write is SMP-safe (core 1 parked, no XIP fault). */
    rtos_wait_flash_ready();
    saved_load();   /* load cached WiFi networks (seeds Moop Ship + MoopsterCell) */

    /* Social: bake our id into the beacon, and resume scanning if it was left on. */
    dilder_social_set_self(g_saved.dilder_id);
    if (g_saved.social_on) {
        if (!dilder_bt_active()) dilder_bt_init();
        bt_enabled = true;
        dilder_social_set_self(g_saved.dilder_id);   /* re-push now that BT is up */
        dilder_social_enable(true);
    }

    /* ─── State machine ─── */
    uint8_t state = STATE_OCTOPUS;
    uint32_t frame_idx = 0;
    int qi = pick_quote();
    int menu_sel = 0;
    int mood_sel = 0;  /* 0 = ALL, 1-16 = specific mood */

    int snd_sel = 0;
    int social_sel = 0;
    int disp_sel = 0;
    int met_sel = 0;
    int nearby_sel = 0;

    /* Sub-screen input: block on the Input task's event queue for up to `ms` ms.
     * The do-while(0) PRESERVES the old `break;` semantics in every screen body —
     * a `break` leaves the poll, then the case's trailing `break` triggers the
     * redraw — but with NO busy-wait: the UI sleeps until a press arrives or the
     * timeout elapses (the Input task captures presses meanwhile). */
    #define POLL_INPUT(ms) \
        do { \
            uint8_t inp; \
            if (!ui_get_input(&inp, (ms))) break;
    #define POLL_END } while (0);

    while (true) {
        /* Default every screen to the WIDE canvas; the tall layouts override it
         * for themselves. NOTE (Phase 2): accelerometer sampling
         * (orientation_update) now runs in the Housekeeping task, and Wi-Fi/BT are
         * serviced by the cyw43 FreeRTOS background task — so the per-iteration
         * orientation_update()/cyw43_arch_poll() that used to sit here are gone. */
        set_canvas_wide();

        switch (state) {

        /* ════════ OCTOPUS MAIN SCREEN ════════ */
        case STATE_OCTOPUS: {
            const Quote *q = &quotes[qi];
            const uint8_t *cycle = mood_cycle(q->mood);
            uint8_t expr = cycle[frame_idx % 4];

            if (expr == EXPR_OPEN && frame_idx > 0)
                qi = pick_quote();

            /* Skip the redraw entirely while pocketed/idle — the e-ink keeps
             * showing the last frame for free; this is the main power saver. */
            if (!g_screen_idle) {
                if (orientation_is_tall()) {
                    /* Longways layout draws its own 2-row status bar (wifi + batt,
                     * date + time), quote, and octopus at the bottom. */
                    render_octopus_tall(&quotes[qi], expr, frame_idx);
                } else {
                    render_frame(&quotes[qi], expr, frame_idx);
                    draw_wifi_icon(0, 1, wifi_connected);   /* top-left */
                    {
                        int soc_x = 18;
                        if (dilder_bt_state() == BT_PAIRED) { draw_bt_icon(18, 1); soc_x = 32; }
                        if (dilder_social_active()) draw_social_icon(soc_x, 1);
                    }
                    draw_battery_icon(234, 1);               /* top-right */
                    {
                        char sbuf[20];
                        snprintf(sbuf, sizeof(sbuf), "STEPS %lu",
                                 (unsigned long)steps_today);
                        draw_text(5, 113, sbuf, IMG_W);      /* left of the screen */
                    }
                    draw_text(175, 113, "DOWN:MENU", IMG_W);
                }
                draw_orient_hud();   /* calibration overlay (ORIENT_DEBUG) */
                transpose_to_display();

                display_render();
                bt_push_status();    /* keep a paired phone's mood/steps read fresh */
                frame_idx++;
            }
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

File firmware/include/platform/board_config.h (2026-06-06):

/*
 * board_config.h -- Compile-time board selection and pin definitions
 *
 * Provides a unified set of pin/peripheral macros that abstract over the
 * target hardware.  Each board defines the same macro names so the game
 * engine and display driver can use them without #ifdef everywhere.
 *
 * Currently supported boards:
 *   - BOARD_PICO_W       Raspberry Pi Pico W  (RP2040, SPI1)
 *   - BOARD_PICO2_W      Raspberry Pi Pico 2 W  (RP2350, SPI1)
 *   - BOARD_ESP32S3      Olimex ESP32-S3-DevKit-Lipo  (ESP32-S3, FSPI)
 *
 * Set the target board at build time:
 *   cmake  -DTARGET_BOARD=PICO_W ..
 *   cmake  -DTARGET_BOARD=PICO2_W ..
 *   cmake  -DTARGET_BOARD=ESP32S3 ..
 * Or in platformio.ini:
 *   build_flags = -DBOARD_ESP32S3
 */

/*
 * --------------------------------------------------------------------------
 *  BEGINNER NOTES: What is this file doing?
 * --------------------------------------------------------------------------
 *
 *  Different boards have their components wired to different GPIO pins.
 *  For example, the e-Paper display clock wire is connected to:
 *    - GPIO 10 on the Pico W
 *    - GPIO 12 on the ESP32-S3
 *
 *  Instead of scattering these pin numbers throughout the codebase
 *  (which would make switching boards a nightmare), we define them
 *  all HERE using #define macros with consistent names.
 *
 *  The rest of the code just uses PIN_EPD_CLK everywhere.  This file
 *  ensures PIN_EPD_CLK expands to the right number for whichever board
 *  we're building for.
 *
 *  Think of it like a wiring diagram in code form: "On this board,
 *  the clock wire goes to pin 12, the data wire goes to pin 11, ..."
 * --------------------------------------------------------------------------
 */

/*
 * --------------------------------------------------------------------------
 *  BEGINNER NOTES: #if defined() / #elif / #else preprocessor chains
 * --------------------------------------------------------------------------
 *
 *  The C preprocessor can make decisions at COMPILE TIME using conditional
 *  directives.  This is different from if/else in regular code, which
 *  makes decisions at RUN TIME.
 *
 *  Preprocessor conditionals actually REMOVE code from the source before
 *  the compiler sees it.  Only the branch that matches gets compiled.
 *  The other branches are thrown away entirely.
 *
 *  Here's the pattern used in this file:
 *
 *    #if defined(BOARD_PICO_W)        // Is BOARD_PICO_W defined?
 *      ... Pico W pin definitions ... // YES: use these
 *
 *    #elif defined(BOARD_PICO2_W)    // Otherwise, is BOARD_PICO2_W defined?
 *      ... Pico 2 W pin definitions  // YES: use these (same pins, more flash)
 *
 *    #elif defined(BOARD_ESP32S3)     // Otherwise, is BOARD_ESP32S3 defined?
 *      ... ESP32-S3 pin definitions . // YES: use these
 *
 *    #else                            // Neither was defined
 *      ... Desktop dummy values ..... // Use these as fallback
 *
 *    #endif                           // End of the conditional chain
 *
 *  "defined(X)" returns true if the symbol X has been #defined, either
 *  in code or via a compiler flag like -DBOARD_ESP32S3.
 *
 *  This is like a switch statement, but it happens before compilation.
 *  Only ONE set of pin definitions ends up in the compiled binary.
 *
 *  You can also use #ifdef X as shorthand for #if defined(X), but
 *  #if defined() is more flexible because you can combine conditions:
 *    #if defined(BOARD_PICO_W) || defined(PICO_BOARD)
 *  This means "if either BOARD_PICO_W or PICO_BOARD is defined."
 * --------------------------------------------------------------------------
 */

/*
 * --------------------------------------------------------------------------
 *  BEGINNER NOTES: BOARD_NAME, BOARD_FLASH_KB, and other constants
 * --------------------------------------------------------------------------
 *
 *  Besides pin numbers, each board section defines:
 *
 *  BOARD_NAME — A human-readable string like "Pico W" or "ESP32-S3 (Olimex)".
 *    Used in log messages, status displays, etc.  It doesn't affect
 *    hardware behavior — it's just for humans reading debug output.
 *
 *  BOARD_FLASH_KB — The amount of flash memory (in kilobytes) on the board.
 *    The Pico W has 2 MB (2048 KB), the ESP32-S3 has 8 MB (8192 KB).
 *    This could be used to adjust how much data we store (save files,
 *    game assets, etc.) based on available space.
 *
 *  EPD_SPI_CONTROLLER — Which SPI hardware block to use (see below).
 *
 *  EPD_SPI_FREQ_HZ — The SPI clock speed in Hertz.  4,000,000 = 4 MHz,
 *    meaning 4 million clock pulses per second.  The e-Paper display
 *    datasheet specifies the maximum safe speed.
 * --------------------------------------------------------------------------
 */
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

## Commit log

2026-04-09 Add hardware research with materials list, component specs, and input options
    Documents the Waveshare 2.13" e-Paper V3 specs, Pi Zero WH details, GPIO pin
    budget, button input options (tactile, nav switch, membrane, capacitive), test
    bench materials list with costs, and enclosure design constraints.
2026-04-09 Update README and prompt log for Phase 1 hardware planning
    README: Update hardware table with confirmed components (V3 display, tactile
    buttons, PowerBoost), mark Phase 0 roadmap complete, advance to Phase 1, add
    setup guide and hardware research to docs table.
    PromptProgression: Add prompts #3-#7 with input/output token estimates covering
    hardware research, prototype concepts, display fix, and setup guide work.
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2026-04-09 Embed prototype SVG renders directly in enclosure design page
    Copies SVGs from docs/concepts/ into website/docs/assets/images/ so
    MkDocs can serve them, and replaces GitHub links with inline images.
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2026-04-12 Add dependency gate, Docker health check, Step 15, Code OSS detection, and --test-setup
    DevTool/devtool.py:
    - Add _check_and_install_deps() that detects missing tkinter/pyserial and
    offers distro-specific install (Arch/Debian/Fedora) when run directly;
    skipped when imported as a module by tests
    - Move serial and tkinter imports after the dependency gate
    - Add _check_docker_toolchain() startup health check that runs in a
    background thread 500ms after UI ready, verifying Docker binary, daemon,
    compose, build files, and shared lib directory
    - Simplify ProgramsTab output logging: remove keyword filtering, log all
    Docker and build output lines directly for full transparency
    - Remove old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
2026-04-12 Fix Docker build: copy pico_sdk_import.cmake from SDK before cmake
    The sassy-octopus and other firmware projects include
    pico_sdk_import.cmake which is gitignored. The Docker CMD now
    copies it from /opt/pico-sdk/external/ before running cmake.
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2026-04-12 Add Angry, Conspiratorial, Sad, and Chaotic octopus programs
    New emotional octopus programs, each with unique eye/mouth expressions
    and themed quote lists:
    - Angry Octopus: slanted V-shaped eyebrows, inward-glaring pupils,
    tight downward frown mouth, 45 mean-but-cute quotes
    - Conspiratorial Octopus: weird misaligned eyes, wobbly sine mouth,
    47 tinfoil-hat quotes (split from Sassy + new deep conspiracy)
    - Sad Octopus: droopy eyebrows, downward-looking pupils, gentle
    frown mouth, 35 melodramatic ocean melancholy quotes
    - Chaotic Octopus: spiral dizzy eyes, zigzag lightning-bolt mouth,
    40 pure nonsensical fever-dream quotes
    Also adds:
    - MOUTH_ANGRY, MOUTH_SAD, MOUTH_CHAOTIC expression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
    [main.c]
2026-04-12 Fix angry octopus eyebrows — thick slanted half-circle arcs
    Replaced thin angled lines with bold curved arcs that cut across the
    top of the white eye sockets. Outer edges sit high, inner edges dip
    low, creating a proper angry V-furrowed brow look. 3px thick with
    extra width fill for visibility on the 1-bit display.
2026-04-12 Add angry/sad/chaotic expressions to standalone Pico firmware
    The C firmware now matches the Python DevTool rendering for all 6
    emotional states:
    - Angry: inward-glaring pupils (shifted toward nose + down), thick
    slanted half-circle eyebrow arcs, tight downward frown mouth
    - Sad: downward-looking pupils, droopy eyebrow arcs (outer low),
    gentle frown mouth
    - Chaotic: spiral ring eyes (concentric circles), zigzag
    lightning-bolt mouth
    - New mood constants (MOOD_ANGRY=3, MOOD_SAD=4, MOOD_CHAOTIC=5)
    - New expression constants (EXPR_ANGRY=5, EXPR_SAD=6, EXPR_CHAOTIC=7)
    - Expression cycles per mood matching Python MOUTH_CYCLE_* definitions
    - All 6 firmware projects updated with identical mai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
    [main.c]
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2026-04-12 Add Lazy, Fat, Chill, Horny, Excited, Nostalgic, and Homesick octopus programs
    7 new emotional octopus programs, each with unique eyes, mouth, and
    themed quote lists. Total lineup is now 16 programs.
    New expressions and their visual signatures:
    - Lazy: nearly-shut eyelids (tiny slit), flat horizontal mouth
    - Fat: wide content pupils, satisfied smile + cheek puffs
    - Chill: side-glancing pupils, relaxed asymmetric half-smile
    - Horny: heart-shaped pupils, wide smile with tongue sticking out
    - Excited: star/cross sparkle pupils, wide open grin
    - Nostalgic: pupils looking up-right (remembering), gentle wistful smile
    - Homesick: teary eyes with tear drop pixels, wobbly trying-not-to-cry line
    Quo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
    [main.c]
2026-04-12 Add body movement animations and head deformations per emotional state
    Body transform system applies per-mood, per-frame deformations to the
    octopus silhouette during animation:
    - Normal: gentle breathing bob (1px vertical oscillation)
    - Angry: puffed up 2px wider, slight tremble
    - Sad: drooped down 3px, deflated 1px narrower
    - Unhinged: rapid 1-2px random jitter
    - Weird: lean to one side + wavy row distortion
    - Chaotic: wild 3px sine wave per row, shifting offset
    - Hungry: lean upward 2px, bobbing toward food
    - Tired: sagging down 2-3px, melting, narrower
    - Slap Happy: sway side to side 3px, wavy rows
    - Lazy: melted flat (3px down + 3px wider, pancaked)
    - Fat: 3px wider (rounder), slight j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
    [main.c]
2026-04-12 Add custom fat/lazy octopus bodies, C-faithful renderer, keyboard input plan, and Prompts #96-104
    Fat octopus: custom body_rle with wider dome (+5px/side, starts 2 rows
    higher), no waist taper, tentacles widened +1px per side. Visually
    chonky and clearly distinct from standard body.
    Lazy octopus: redesigned body with standard head but all 5 tentacles
    sweeping diagonally to the right — sitting on its side with legs
    draped. Cheeks taper rightward to smooth the transition. Removed
    the belly tentacle overlay from earlier iteration.
    C-faithful renderer (assets/render_c_previews.py): standalone Python
    script that is a 1:1 port of every C firmware drawing function
    including fill_circle, all dra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
    [main.c]
2026-04-12 Redesign homepage with hardware photos, emotion previews, and DevTool screenshot
    Replaced the text-heavy homepage with a visual, personality-driven
    layout showcasing the actual project:
    - Hero section with sassy-octopus-running.jpg showing real device output
    - Hardware section with side-by-side photos of components and first boot
    - Component table with prices and reasoning
    - 6-up emotion preview grid (normal/angry/sad/excited/lazy/fat)
    - DevTool screenshot showing the Programs tab
    - Expanded Phase 2 status with done/next breakdown
    - Added GitHub source card to quick links grid
    - Updated blog count (9 posts), prompt count (104+)
    - Footer tagline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
2026-04-13 Add LiPo battery wiring guide, update materials and pinout, add Prompts #133-134
    New detailed wiring and setup documentation for the InnCraft 1000mAh 3.7V LiPo
    battery with three wiring options (direct VSYS, TP4056, PowerBoost 500C),
    safety guide, voltage monitoring code, battery life estimates, and
    troubleshooting. Updated materials list with specific product link and
    wiring pinout with battery power entries. Fixed Prompt #133 entry and
    added Prompt #134.
2026-04-14 Fix origin story layout to single-column flow, update Prompts #139
    Removed grid div wrapper so Jamal's photo and text render as a single
    column instead of side-by-side with text wrapping around the image.
2026-04-14 Rebuild KiCad schematic as proper wiring diagram with component blocks
    Replaced text-only pin list with actual visual diagram: component boxes
    (rectangles) for Pico WH, GPS, joystick, e-Paper, HC-SR04, and speaker
    connected by polyline wires. Includes voltage divider detail, speaker
    transistor circuit, 3V3 power rail, and notes section. A2 paper size.
    [dilder-breadboard.kicad_sch]
2026-04-14 Fix KiCad schematic — replace invalid 'center' justify with 'left'
    KiCad text justify only accepts left, right, or mirror. Replaced all
    11 instances of (justify center) with (justify left).
    [dilder-breadboard.kicad_sch]
2026-04-14 Rebuild KiCad schematic v1.2 — fix layout, alignment, and wire routing
    Rebuilt from scratch with consistent 10mm pin spacing, properly aligned
    wire endpoints matching pin Y-coordinates, component boxes with clear
    labels, voltage divider detail inside HC-SR04 box, and warnings section.
    [dilder-breadboard.kicad_sch]
2026-04-14 Correct display model to Pico-ePaper-2.13, fix VSYS power pin across all docs, Prompt #141
    Display is Waveshare Pico-ePaper-2.13 (Pico-native module with 40-pin
    direct-plug header), not the Raspberry Pi HAT version. Power pin is VSYS
    (pin 39) not VCC/3V3 OUT (pin 36). Updated wiring guides, materials list,
    README, setup docs, blog post, and all hardware references.
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2026-04-15 Add v0.4 PCB routing, board design doc, update prompts, Prompt #155
    Route the v0.4 board (30x70mm, 4-layer) with route_v04.py: B.Cu channels
    for I2C/USB/joystick/ePaper, staggered L-routes for crossing-free SPI,
    custom paths for EN/BOOT/battery protection, F.Cu power chain. Adds In1.Cu
    GND plane and In2.Cu 3V3 plane with stitching vias. Board design doc
    captures zones, BOM, GPIO map, routing strategy, and DRC status. Updates
    prompts index with #154-155.
    [dilder.kicad_pcb, dilder.kicad_sch]
2026-04-15 Add user guide, asset system, feature menus, KiCad sensor updates, blog posts, Prompt #162
    User guide (1,207 lines) covering all planned features as if implemented:
    story, 16 emotions, stat system, 64 achievements, 6 evolutions, controls.
    Feature systems doc (963 lines) with achievement registry, menu viewer
    specs, toast notifications, decor browser, and full menu hierarchy.
    Asset rendering pipeline: 52 Python modules generating 22 environments,
    42 outfits, 29 decor props, 16 aura particle sets, and emotion previews.
    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
    [dilder.kicad_pcb, dilder.kicad_sch]
2026-04-15 Add prompt log #163-167, schematic generator script, clean up prompts
    - PromptProgression.md: added entries for KiCad rework (#163),
    board design guide (#164), AHT20+BH1750 sensors (#165-166),
    and this commit (#167)
    - generate_schematic_v2.py: real-footprint schematic generator using
    KiCad standard library symbols (kept for reference, manual KiCad
    workflow preferred going forward)
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2026-04-17 purged uneedede notes and research
    [dilder.kicad_pcb, dilder.kicad_sch]
2026-04-17 Add ESP32-S3 multi-board support across DevTool, setup CLI, firmware, and docs
    DevTool:
    - Programs tab: Target Board dropdown, ESP32 flash via PlatformIO,
    ESP32 Deploy Standalone with quotes.h generation
    - Connect tab: board-aware USB steps with ESP32 CH340X detection,
    download mode instructions (BOOT+RST), ESP32 Wi-Fi panel
    - Board-agnostic serial status messages, target_board label/key fix
    Setup CLI (setup.py):
    - --board {pico,esp32} flag filters steps by board
    - Interactive board selection menu (1=Pico, 2=ESP32, 3=Both)
    - PEP 668 fix: pipx on Arch/CachyOS instead of blocked pip
    - All 16 steps tagged [Pico W], [ESP32-S3], or [Both]
    Firmware:
    - platformio.ini: fixed include paths, bui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
    [board_config.h, esp32s3_hal.cpp, main.cpp]
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2026-05-07 Dilder Hub: WiFi scan/keyboard, sound patterns, MPU-6050, active buzzer
    Major feature additions to dilder-hub firmware:
    - Fix cyw43_arch_gpio_get API (1 arg, not 2) and init CYW43 at boot
    for battery VSYS sensing on GPIO 29
    - Replace passive piezo PWM with active buzzer GPIO driver on GP14
    - Add 6 sound patterns (beep, chirp, SOS, doorbell, alert, happy)
    with volume control and pattern cycling in sound submenu
    - WiFi menu overhaul: network submenu with scan, on-screen keyboard
    for password entry, connect to arbitrary networks, wifi on/off toggle
    - MPU-6050 accelerometer/gyro support via I2C0 (GP0/GP1) with
    auto-detect at 0x68/0x69, pedometer, tilt angles, temperature
    - Motion menu w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
    [main.c]
2026-05-07 Update docs, README, and prompts for May 7 testbench session
    - README: update hardware table (Pico 2 W, TP4056, active buzzer,
    MPU-6050), mark completed phase items (battery, joystick, menus,
    sound, WiFi, motion), add new doc links
    - Website dilder-hub.md: rewrite for new features — WiFi scan/keyboard,
    sound patterns, motion menu, active buzzer, battery sensing, updated
    wiring table with MPU-6050 and TP4056
    - PromptProgression.md: add prompt #276 covering full session
    - New: docs/session-2026-05-07-implementation.md — detailed recap of
    all hardware wiring, firmware changes, and design decisions
2026-05-07 Add no-solar buzzer enclosure variant, MPU-6050 swap, thumbpiece resize
    New FreeCAD macro (dilder_rev2_mk2_no_solar_buzzer.FCMacro) based on
    the no-solar build, adding a 12mm x 9.5mm (12095) active buzzer to the
    -X wall. Enclosure extended +2mm (enc_x 96.9->98.9, wall_mx 3.0->5.0)
    for buzzer wall clearance. Buzzer sits on base plate floor with 2mm
    sound hole, blind pocket in cradle, and cover wall pocket for clearance.
    Replaced piezo ring with centered GY-521/MPU-6050 (21x16mm) IMU pocket.
    Thumbpiece OD reduced 11mm->10mm. Prompt #276 added.
    [Dilder_Rev2_Mk2_NoSolar_Buzzer-AAACradle.3mf, Dilder_Rev2_Mk2_NoSolar_Buzzer-BasePlate.3mf, Dilder_Rev2_Mk2_NoSolar_Buzzer-Thumbpiece.3mf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]
2026-05-07 macroed freecad save
    [Dilder_Rev2_Mk2.FCStd, Dilder_Rev2_Mk2_NoSolar.FCStd, loerclearer batter top and bottom.3mf]
2026-05-08 Sound routing redesign: lateral channel, taller base, IMU pegs
    Redesigned the no-solar buzzer variant to route sound laterally instead
    of through the base plate floor, extended the base plate +5 mm for
    cable routing, swapped the IMU pocket to MPU-6050 spec (20 × 15.6 mm)
    with corner mounting pegs, and added separate snap-on washer bodies.
    Sound path:
    - Removed BuzzerSoundPort (through-floor hole)
    - Added BuzzerSoundPit + BuzzerSoundChannel in cradle (lateral cylinder
    cuts through the cradle's solid material above the speaker top)
    - Added BuzzerSoundChannel in cover -X wall (small exit hole)
    - Made cradle BuzzerPocket shallow (3.2 mm) and deepened by 2 mm
    after lifting the speaker — s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
    [Dilder_Rev2_Mk2_NoSolar_Buzzer-AAACradle_thiccc.3mf, Dilder_Rev2_Mk2_NoSolar_Buzzer-BasePlate_thiccc.3mf, Dilder_Rev2_Mk2_NoSolar_Buzzer-IMUPegWasher_PX.3mf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]
2026-05-08 Update TODO and prompt logs for the no-solar-buzzer overhaul
    Week 4 TODO section added with completed items + open follow-ups
    (print verification, sound projection check, optional internal lip,
    hole-spacing parameterization).
    Prompt #277 entry added to PromptProgression.md and synced to
    website/docs/prompts/index.md, capturing the 7-iteration enclosure
    redesign: lateral sound routing (cradle pit + horizontal channel
    out the cover -X side), +5 mm base plate Z extension with cascaded
    references, BuzzerCradleRing + speaker lift + wire pass-through
    notches, MPU-6050 pocket resize with corner pegs, separate snap-on
    peg washer bodies, and PCB visualization hole cuts.
    Companion to fdadd83.
    Co-Au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
2026-05-08 Fix docs commit hash refs in prompt #277
    The amended docs commit hash changed from 3a0d010 → ce4bb05; update
    the self-referencing entries in PromptProgression.md and the website
    prompts index to point at the actual commit.
2026-05-08 Tweak IMU peg Y position and open-top wire channel slots
    IMU pegs nudged -1 mm Y to match measured board hole positions:
    - imu_hole_y_inset 2.0 → 3.0 in three coordinated places
    (BasePlate IMUPeg_MX/_PX placements, IMU PCB visualization
    through-holes, IMUPegWasher_MX/_PX assembly placements)
    - Net peg/hole/washer Y: 28.8 → 27.8
    Wire channels are now open-top slots through the full ring:
    - wire_chan_z_top floor_z + 1.6 → floor_z + 5.1
    - Slots now cut all the way through the 5 mm-tall BuzzerCradleRing
    so wires can drop in from above instead of being fished through
    a closed-off hole
    - Floor remains uncut (wire_chan_z_bot = floor_z) — no underside
    holes on the base plate
    User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
    [Dilder_Rev2_Mk2_NoSolar_Buzzer-AAACradle.3mf, Dilder_Rev2_Mk2_NoSolar_Buzzer-AAACradle_thiccc.3mf, Dilder_Rev2_Mk2_NoSolar_Buzzer-BasePlate.3mf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]
2026-05-08 Fix tweak commit hash refs in prompt #278
    Resolve <TWEAK_HASH> placeholders in TODO.md and the prompt logs
    to point at 312a65b (the commit that landed the IMU peg Y nudge
    and open-top wire channel slots).
2026-05-09 copied in a few component schematics to the full board
    [Dilder-Full-board.kicad_sch]
2026-05-10 Continued kicad specs
    [Dilder-Full-board.kicad_sch]
2026-05-12 TODO: log Week 5 Full Board schematic session, close Week 3 carryovers
    Added Week 5 (2026-05-12) covering the Dilder-PCB Full Board schematic
    session: SC7A20 accelerometer, K1-1506SN-01 joystick, MSK12C02 power
    switch, plus library and ERC work.
    Closed out Week 3 items now resolved:
    - Power on/off mechanism (MSK12C02 picked)
    - Joystick Rev 2 fix (folded into Full Board)
    - Pin-1 silkscreen reminder (carried forward)
    Added status legend and index for easier navigation.
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2026-06-08 dilder-hub-rtos Phase 0: FreeRTOS SMP toolchain + scheduler entry
    New self-contained firmware variant dev-setup/dilder-hub-rtos/ that runs the
    Dilder firmware on FreeRTOS (dual-core SMP) on the Pico 2 W / RP2350.
    - Vendor FreeRTOS-Kernel as a submodule (+ its nested RP2350_ARM_NTZ port via
    the Community-Supported-Ports submodule).
    - FreeRTOSConfig.h: SMP (2 cores, core affinity, multiple priorities), heap_4,
    1kHz tick, ARMv8-M port options (FPU on, MPU/TrustZone off, secure-only),
    pico sync/time interop, required hooks. Heavily commented for newcomers.
    - freertos_hooks.c: kernel-required callbacks (idle/passive-idle/timer static
    memory, malloc-failed + stack-overflow error hooks).
    -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
    [lwipopts.h, main.c]
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2026-06-09 dilder-hub-rtos Phase 2: fixes from adversarial concurrency review
    Addressed the confirmed findings from the multi-agent review of the task split
    (verdict: functionally correct; these are robustness/UX polish):
    - Flash first-boot ordering: replaced the vTaskDelay(80ms) timing guess with an
    explicit handshake — Display task gives a semaphore after
    flash_safe_execute_core_init(); UI waits (rtos_wait_flash_ready) before
    saved_load(). saved_write_flash() no longer falls back to an unsafe
    interrupts-off write (would XIP-fault core 1); it retries flash_safe_execute
    and skips on failure.
    - Step double-count bug: removed the inline mpu_read_all()/pedometer_update()
    from render_motion_m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
    [main.c, rtos_tasks.c]
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2026-06-09 dilder-hub-rtos: add Docker build service (fixes DevTool "no such service")
    - docker-compose.yml: add build-dilder-hub-rtos service. Unlike the others it
    does NOT mount hello-world/lib (the RTOS variant has its own lib copy) and it
    mounts the repo-root FreeRTOS-Kernel submodule at /FreeRTOS-Kernel, pointing the
    build at it via FREERTOS_KERNEL_PATH. Build with PICO_BOARD=pico2_w.
    - CMakeLists.txt: only default FREERTOS_KERNEL_PATH when neither -D nor the
    env var is set, so the Docker mount path takes effect in-container while local
    builds still use the relative submodule path.
    Verified end-to-end: docker compose run --rm -e PICO_BOARD=pico2_w
    build-dilder-hub-rtos finds the kernel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
2026-06-09 dilder-hub-rtos Phase 3a: interrupt-driven joystick + faster e-ink polling
    Make the controls feel instant:
    - Joystick GPIO interrupt: a shared edge ISR (main.c joystick_irq_cb) wakes the
    Input task the instant any line changes, via rtos_input_isr_notify ->
    vTaskNotifyGiveFromISR. Sub-ms press latency (was up to 8ms of polling) AND the
    core idles when nothing is pressed (better for battery — no more 8ms poll).
    - Input task rewritten event-driven: blocks on ulTaskNotifyTake (portMAX_DELAY
    when idle; repeat-interval timeout only while a key is held). Tunables in
    rtos_tasks.h: INPUT_REPEAT_DELAY_MS=400 (a tap never repeats),
    INPUT_REPEAT_RATE_MS=90 (snappier hold-scroll). 2ms settl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
    [main.c, rtos_tasks.c]
2026-06-09 dilder-hub-rtos: log e-ink refresh time (EPD_TIMING) to measure the screen floor
    The Display task now prints "[disp] refresh N ms" over USB serial per refresh
    (EPD_TIMING=1, set 0 to silence). This measures the e-ink partial-refresh
    waveform duration — the remaining visible input->screen latency after the
    interrupt-driven joystick — so the next display-speed optimization (load the
    partial LUT once / skip per-frame reset) can be decided with real data instead
    of risking the working driver blind.
    [rtos_tasks.c]
2026-06-09 dilder-hub-rtos: social/emotes, input pacing, robustness + docs
    Firmware (dev-setup/dilder-hub-rtos):
    - Dilder-to-Dilder proximity social: connectionless BLE beacon (no pairing),
    Social menu (scan toggle, Scan Nearby, Dilders Met log, Set Name), auto names
    from id, 24h re-greet cooldown, social status icon. All BTstack work moved to
    a single run-loop tick driven by volatile intent flags (fixes the softlock).
    - Emote system: WAVE/LOVE/LAUGH/PARTY/SLEEPY/WHOA with octopus overlay
    animations; works in both screen orientations; ~2 min ack window.
    - Display-paced input: presses gated on panel idle -> first press instant, mash
    coalesced, hold throttles to refresh rate. Kills ghost presse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
    [main.c, rtos_tasks.c]
2026-06-10 dilder-hub-rtos: accurate battery gauge + charging power-diet
    - Battery: add back the ~0.53 V battery-path drop (D3 Schottky + slide switch)
    on on-battery samples only (VSYS_BATT_OFFSET). The USB rail read correctly but
    every battery sample was ~0.53 V low, dumping a charged ~4.1 V cell into the
    "empty" zone (showed 5%/0 bars). Now device-read 3.67 V (full) -> 4.20 V ->
    100%, and the icon + Device Info voltage track reality.
    - Charging power-diet: while on USB, suspend BLE scanning and slow the e-ink
    animation ~10x (g_on_usb) so the running load doesn't starve the ~120 mA
    charger; restore on unplug.
    [main.c]
2026-06-10 dilder-hub-rtos: Display settings menu (orientation + auto-rotate)
    New main-menu "DISPLAY" screen:
    - AUTO-ROTATE: ON/OFF toggle (off locks to the current hold).
    - ORIENTATION: cycles WIDE / WIDE FLIP / TALL — covers all 3 holds; picking
    one locks auto-rotate off and applies immediately.
    orientation_update() now locks g_orientation to the chosen hold when auto-rotate
    is off (works even on a unit with no accelerometer); steps still count. Settings
    persist in g_saved (auto_rotate, manual_orient) appended after the social block
    (sanitised on load, no SAVED_MAGIC bump). The menu renders in both tall and wide.
    [main.c]
2026-06-11 dilder-hub-rtos: hold-CENTER reboot + motion tall layout fix
    - Hold CENTER for ~10 s -> watchdog_reboot(), handled in the Input task so it
    works even if the UI is soft-locked (CENTER is rotation-invariant). Adds
    hardware_watchdog to the link libraries.
    - Motion screen tall layout: ACCEL / TODAY / TILT now put their value on its own
    line under the label (dedicated render_motion_tall) so nothing overflows the
    122 px width.
    [main.c, rtos_tasks.c]
